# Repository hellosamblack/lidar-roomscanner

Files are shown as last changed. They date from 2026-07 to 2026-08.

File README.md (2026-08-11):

#  3D Roomscanner

A tethered handheld **3D room scanner**. This project aims to build a complete pipeline for 3D room capture: an STM32H563ZI board streams timestamped Time-of-Flight (ToF) and IMU/Environment sensor frames to a PC. The host PC runs real-time SLAM (using Open3D tensor ICP + TSDF), providing a live 3D reconstruction and tracking. Finally, an offline pass fuses 4K phone video into a ToF-seeded 3D Gaussian Splat.

---

##  System Architecture

The architecture consists of two main pillars:

### 1. Hardware & Firmware

<table>
  <thead>
    <tr>
      <th width="15%">Category</th>
      <th width="20%">Hardware</th>
      <th width="50%">Specifications & Role</th>
      <th width="15%">Image</th>
    </tr>
  </thead>
  <tbody>
    <tr>
      <td valign="top"><strong>MCU</strong></td>
      <td valign="top"><strong>STM32H563ZI</strong><br>(NUCLEO-H563ZI)</td>
      <td valign="top">
        <ul>
          <li><strong>Firmware:</strong> Bare-metal driving a double-buffered DMA setup via I3C.</li>
          <li><strong>Speed:</strong> Capable of emitting raw binary frames at 30+ fps.</li>
        </ul>
      </td>
      <td valign="top" align="center">NUCLEO-H563ZI</td>
    </tr>
    <tr>
      <td valign="top"><strong>Transport</strong></td>
      <td valign="top"><strong>RP-WD007</strong><br>(Travel Router)</td>
      <td valign="top">
        <ul>
          <li><strong>Connections:</strong> Streams via native USB CDC FS or Ethernet UDP (untethered DHCP client).</li>
          <li><strong>Power & Network:</strong> <em>Powered and networked via travel routers for wireless operation.</em></li>
        </ul>
      </td>
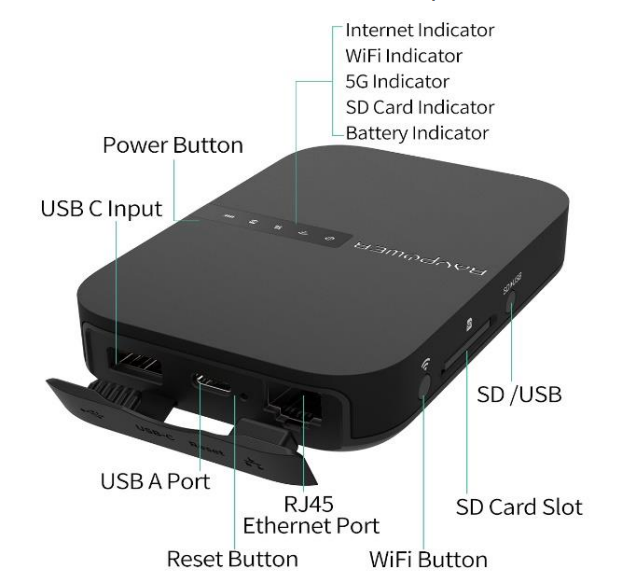
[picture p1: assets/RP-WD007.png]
RAVPower RP-WD007
      <td valign="top" align="center"></td>
    </tr>
    <tr>
      <td valign="top"><strong>LIDAR</strong></td>
      <td valign="top"><strong>VL53L9CX</strong><br>(X-NUCLEO-53L9A1)</td>
      <td valign="top">
        <ul>
          <li><strong>Specs:</strong> 54×42 depth zones (2,268 points per frame), max range ~4000mm</li>
          <li><strong>FoV:</strong> 54.65° Horizontal / 42.50° Vertical</li>
          <li><strong>Speed:</strong> Streams raw <code>3DMD</code> data at 30+ fps over I3C + DMA</li>
          <li><strong>Role:</strong> Primary depth imager for SLAM tracking and point-cloud generation.</li>
        </ul>
      </td>
      <td valign="top" align="center">X-NUCLEO-53L9A1</td>
    </tr>
    <tr>
      <td valign="top"><strong>IMU & Env</strong></td>
      <td valign="top"><strong>Sensor Cluster</strong><br>(X-NUCLEO-IKS4A1)</td>
      <td valign="top">
        <ul>
          <li><strong>LSM6DSV16X (6-axis IMU):</strong> 3D accel (16g) + 3D gyro (4000 dps). Outputs hardware quaternions via its embedded Sensor Fusion Low Power (SFLP) core.</li>
          <li><strong>LIS2MDL (Magnetometer):</strong> 3-axis magnetic sensor, 50 Gauss, up to 100 Hz. Used for absolute heading and yaw-drift correction.</li>
          <li><strong>LPS22DF (Barometer):</strong> 260-1260 hPa absolute pressure. Vertical Z-drift constraint via barometric altitude changes.</li>
          <li><strong>SHT40 (Humidity & Temp):</strong> 0-100% RH, -40 to 125 °C.</li>
          <li><em>(Unused) LSM6DSO16IS:</em> Secondary 6-axis IMU with an ISPU.</li>
          <li><em>(Unused) LIS2DUXS12:</em> Secondary 3-axis ultra-low power accelerometer with Qvar.</li>
          <li><em>(Unused) STTS22H:</em> Secondary temperature sensor (0.5 °C accuracy).</li>
        </ul>
      </td>
      <td valign="top" align="center">X-NUCLEO-IKS4A1</td>
    </tr>
    <tr>
      <td colspan="4" align="center">
        <strong>Fully Assembled Hardware Stackup</strong><br>
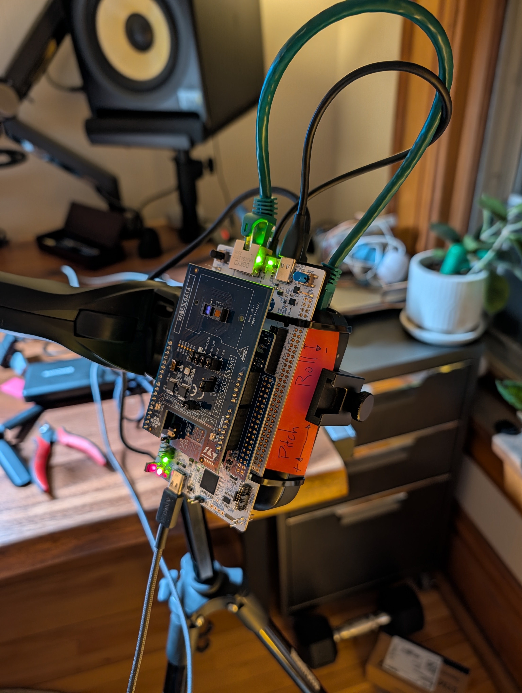
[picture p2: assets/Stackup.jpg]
Hardware Stackup
        
      </td>
    </tr>
  </tbody>
</table>

### 2. Host PC Software (`roomscan`)
*   **Decoding & Transport:** Python package `roomscan` decodes the binary frame protocol and runs the `vl53l9-transform-c` pipeline host-side for uncompromised throughput.
*   **Real-time SLAM:** Point-to-plane ICP frame-to-model tracking against a TSDF VoxelBlockGrid using Open3D's tensor API on the GPU.
*   **Visualization:** A FastAPI and Three.js-based web server (`roomscan-web`) serving a rich real-time visualizer for point clouds, SLAM meshes, sensor states, and IMU metrics.

### Runtime data path

The MCU owns sensor timing: it triggers the ToF sensor, DMA-reads alternating raw
buffers, stamps the frame-ready edge, and packages raw ToF, calibration, and
available IMU/environment streams into CRC-protected `RSCN` frames. It can send
the same frames over native USB CDC and Ethernet UDP.

On the PC, one transport-neutral reader decodes live USB/UDP data or an
identically formatted recording. It records raw bytes when requested, builds the
native ToF transform from `CALIB`, transforms `RAW_3DMD` into depth and image
arrays, then feeds the web visualizer and optional GPU SLAM worker. Browser
controls travel back over the same protocol as COMMAND/ACK frames. See the
[runtime architecture guide](docs/system-architecture.md) for the complete
firmware and host flow.

---

##  Repository Layout

The project is organized into several layers. Start here, and follow the links to learn more about each component:

*   [**`firmware/`**](firmware/README.md) - Active firmware fork (`scanner-stream`) and vendored ST dependencies (`53L9A1`).
*   [**`host/`**](host/README.md) - PC Python package (`roomscan`), real-time SLAM pipeline, Web UI server, and diagnostics.
*   [**`docs/`**](docs/README.md) - Engineering practices, protocol specs, wiring guides, and architectural decisions.
*   [**`tools/`**](tools/README.md) - Project-level utilities, helper scripts, and Docker containers (e.g., offline SLAM).

##  Key Project Documents

*   [**`ROADMAP.md`**](ROADMAP.md) - Current-state doc: standing decisions, architecture, and risks. Forward-looking work + defects are [GitHub Issues](https://github.com/hellosamblack/lidar-roomscanner/issues).
*   [**`docs/roadmap-history.md`**](docs/roadmap-history.md) - Completed-phase narratives and measured outcomes (the historical record behind the roadmap).
*   [**`BUGS.md`**](BUGS.md) - Pointer to GitHub Issues (`bug` label); old `BUG-NNN` → issue mapping in [`docs/issue-migration-map.md`](docs/issue-migration-map.md).
*   [**`AGENTS.md`**](AGENTS.md) - The primary system guidance and agentic instructions for working in this repo. Read this first if you are an agent contributing to the codebase. (`CLAUDE.md` is a symlink to it, as is `.agents/AGENTS.md`; project skills live in [`.agents/skills/`](.agents/skills), which `.claude/skills/` and `.codex/skills/` symlink to.)
*   [**`docs/engineering-practices.md`**](docs/engineering-practices.md) - Binding conventions: repo rules, protocol rules, firmware/host standards, and the status-sync + milestone-retro rules.
*   [**`docs/protocol.md`**](docs/protocol.md) - The binary wire protocol spec (frame layout, stream ids, golden vectors).
*   [**`docs/mcp-server.md`**](docs/mcp-server.md) - The `roomscan-mcp` agent-facing tool surface.

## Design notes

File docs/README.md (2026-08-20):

#  Documentation

Welcome to the documentation hub. This directory contains engineering conventions, protocol specifications, calibration and validation records, and historical context for the Roomscanner project.

Agent guidance lives one level up in [`AGENTS.md`](../AGENTS.md) (`CLAUDE.md` is a symlink to it); project skills are in [`.agents/skills/`](../.agents/skills). Forward-looking work and open defects are **GitHub Issues**, not files — `gh issue list --label bug|work-item|data-collection`, further tagged `area/*`, `status/*`, and `priority/now|next|later`.

##  Key Specifications & Guidelines

*   [**`system-architecture.md`**](system-architecture.md) - How a measurement moves through the STM32 acquisition loop, transport, host transform, web viewer, and SLAM pipeline.
*   [**`engineering-practices.md`**](engineering-practices.md) - The constitution for contributing. Defines repo rules, commit structures, C/Python coding standards, and firmware loop practices.
*   [**`protocol.md`**](protocol.md) - The binary wire protocol specification defining the transport layer between the MCU and Host PC.
*   [**`web-protocol.md`**](web-protocol.md) - The WebSocket JSON/Binary protocol for the `roomscan-web` frontend.
*   [**`thin-client.md`**](thin-client.md) - The `/ws-thin` server-rendered raster feed for GPU-less thin clients (CrowPanel), its protocol contract, renderer backend and client-cap/backpressure policy.
*   [**`mcp-server.md`**](mcp-server.md) - API and structural documentation for the `roomscan-mcp` agentic tool server.
*   [**`coordinate-frames.md`**](coordinate-frames.md) - **Binding**: the sensor/body/world frame definitions and the rotation conventions every orientation claim is expressed in.

##  Hardware & Setup Guides

*   [**`headless-host-setup.md`**](headless-host-setup.md) - Guide for bringing up a GPU-less Linux host to run the web server.
*   [**`pi-bridge-runbook.md`**](pi-bridge-runbook.md) - The Raspberry Pi 3 bridge node that replaces the FileHub as the rig's wireless uplink: build the SD image, flash, first boot, day-2 administration over MCP, recovering lost frames from the pcap tee, and the failure playbook.
*   [**`iks4a1-stacking.md`**](iks4a1-stacking.md) - The hardware stacking recipe, jumper configurations, and bus-conflict resolution history for the sensor array.
*   [**`web-ui-testing.md`**](web-ui-testing.md) - How to drive and test the headless web UI.
*   [**`h563-optimization-notes.md`**](h563-optimization-notes.md) - Why the transform pipeline runs on the PC: measured M33 throughput limits and the deferred on-device optimizations.
*   [**`vl53l9cx-datasheet-notes.md`**](vl53l9cx-datasheet-notes.md) - Working notes on the ToF sensor's datasheet (raw frame sizes, binning, DSS).
*   [**`vl53l9cx-fov-notes.md`**](vl53l9cx-fov-notes.md) - Field-of-view geometry and the deprojection consequences.

##  Calibration, Sensors & Validation

*   [**`flatfield-calibration.md`**](flatfield-calibration.md) - Mode-aware reflectance flat-field correction: the FPN measurement, map generation, and cross-room validation.
*   [**`yaw-fusion.md`**](yaw-fusion.md) - Host-side magnetometer/IMU heading fusion, and the heading-frame traps it has hit.
*   [**`transform-streams.md`**](transform-streams.md) - The `vl53l9-transform-c` pipeline's streams and algorithm toggles, including the 1.3.1 → 1.5.0 upgrade gate.
*   [**`deprojector-validation.md`**](deprojector-validation.md) - How depth-to-point-cloud deprojection was validated.
*   [**`phase6-slam-validation.md`**](phase6-slam-validation.md) - The offline SLAM validation record (accuracy gates and measured outcomes).
*   [**`imu-mag-appnote-review-2026-07-29.md`**](imu-mag-appnote-review-2026-07-29.md) - Review of ST's IMU/magnetometer application notes against our implementation.
*   [**`an6522-appnote-review-2026-08-17.md`**](an6522-appnote-review-2026-08-17.md) - Second-pass review of ST's ranging-profile tuning app note (AN6522) against the current presets: what's already applied, and two unresolved gaps (ULP-for-I3C power recommendation, indoor exposure ceiling).
*   [**`odr-triggered-sync-costing-2026-07-30.md`**](odr-triggered-sync-costing-2026-07-30.md) - Costing study for ODR-triggered ToF/IMU synchronization (note the amended §2.3 premise).
*   [**`connect-transient-forensics.md`**](connect-transient-forensics.md) - Forensics on the USB CDC connect-time CRC transient.

##  RTAB-Map Study (Phase 6/7 reference design)

*   [**`rtabmap-study.md`**](rtabmap-study.md) - What RTAB-Map does differently (per-node clouds + pose graph vs our monolithic TSDF); indexes the issues it generated.
*   [**`rtabmap-pixel10-capture.md`**](rtabmap-pixel10-capture.md) - Exact RTAB-Map capture settings for Phase 7 on the Pixel 10 Pro XL.

##  History & Archives

*   [**`roadmap-history.md`**](roadmap-history.md) - Completed-phase narratives and measured outcomes; the historical record behind [`ROADMAP.md`](../ROADMAP.md).
*   [**`codex-token-burndown.md`**](codex-token-burndown.md) - Ready-to-paste prompt (plus model/effort choice) for a Codex token-burndown session against the issue backlog; single-session counterpart to the `issue-fleet` skill.
*   [**`issue-migration-map.md`**](issue-migration-map.md) - Legacy `BUG-NNN` / `SLAM-N` / `DC-<letter>` → GitHub issue mapping (2026-08-10 migration). Generated from `issue-migration-map.json`, which is the machine-readable source of truth.
*   **`superpowers/`** - Design documents (`specs/`) and phase execution checklists (`plans/`). Active work sits at each directory root; historical records under `completed/`, superseded ones under `deprecated/`. The register in [`ROADMAP.md`](../ROADMAP.md) is the inventory.

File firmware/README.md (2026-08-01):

#  Firmware Layer

This directory contains the embedded firmware components for the Roomscanner project.

##  Target Hardware

*   **Core:** NUCLEO-H563ZI (STM32H563ZI Cortex-M33)
*   **ToF Expansion:** X-NUCLEO-53L9A1 (VL53L9CX ToF 3D LiDAR)
*   **IMU/Env Expansion:** X-NUCLEO-IKS4A1 (LSM6DSV16X, LIS2MDL, LPS22DF, SHT40)

##  Directory Structure

*   [**`scanner-stream/`**](scanner-stream/)
    *   Our active firmware fork. Handles reading ToF data over I3C + DMA, reading IMU streams, packaging into binary frames, and streaming over USB CDC or Ethernet UDP.
*   [**`vendor/`**](vendor/) - Vendored dependencies:
    *   `tinyusb/` - USB CDC stack (FS).
    *   `lwip/` - TCP/IP stack for Ethernet UDP streaming.
    *   `53L9A1/` - ST's reference package. We treat this as a **read-only reference** rather than editing it in place.

##  Architecture Highlights
The active firmware owns the sensor-time-critical work: it starts manual ToF
exposures, stamps the frame-ready edge, and DMA-reads into alternating raw
buffers. While one buffer is being filled, it can package the completed buffer,
drain the optional IMU FIFO, and start the next exposure. Commands and recovery
run only at a safe point after readout acknowledgement, so they cannot race an
in-flight trigger.

The normal build streams raw `3DMD` ToF data plus periodic calibration to the
PC, where the transform runs. It also emits available quaternion,
environmental, raw-IMU, and clock-synchronization streams. A shared versioned
binary protocol carries DATA, COMMAND, ACK, and EVENT frames over USB CDC and
Ethernet UDP; the host may receive either transport or replay the exact bytes
from a capture file.

For the end-to-end sequence, see [**`docs/system-architecture.md`**](../docs/system-architecture.md).
For wire details, see [**`docs/protocol.md`**](../docs/protocol.md). Build and
firmware-loop guidance remains in [**`CLAUDE.md`**](../CLAUDE.md).

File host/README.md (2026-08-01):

#  Host PC Software (`roomscan`)

This directory contains the Python package `roomscan`, which serves as the brain on the host PC. Because the M33 MCU is bottlenecked by the transform pipeline, the host takes over heavy processing, acting as the primary visualization and SLAM engine.

##  Core Responsibilities

1.  **Transport & Decoding:** Connects to the scanner via USB CDC or Ethernet UDP. Decodes the binary frame protocol, resyncs on corruption, and handles sequences.
2.  **ToF Transform:** Runs the `vl53l9-transform-c` pipeline natively on the PC (compiled as a C-extension) to convert raw I3C data into depth, reflectance, and confidence maps.
3.  **Real-time SLAM (`roomscan.slam`):** Point-to-plane ICP frame-to-model tracking against a TSDF VoxelBlockGrid using Open3D's tensor API on the GPU. Capable of generating meshes at ~7ms/frame.
4.  **Web Visualizer (`roomscan-web`):** A FastAPI server providing a WebSocket (`/ws`) stream to a Three.js-based frontend. It replaces the old desktop panel, offering real-time point clouds, SLAM trajectories, sensor gizmos, and headless remote rendering.

##  Frame Flow

USB CDC, UDP, and capture replay all provide raw byte chunks to the same
incremental decoder. The shared reader loop routes control responses and
telemetry, tees raw bytes to recordings, and sends ToF frames through
`TransformStage`. That stage builds the native transform from a `CALIB` frame,
turns `RAW_3DMD` into depth/image arrays, and places only the newest completed
frame in a render slot. The web broadcaster and SLAM worker consume that slot
without competing for the device stream.

This means a capture is a protocol-level recording rather than a special export:
replay follows the same decoder, transform, deprojection, visualizer, and SLAM
path as live hardware. The complete cross-boundary explanation is in
[**`docs/system-architecture.md`**](../docs/system-architecture.md).

##  Structure

*   **`src/roomscan/`** - Core library source code.
*   **`tests/`** - Pytest suite for the host package (run from the `host/` directory).
*   **`tools/`** - Assorted Python utilities, recording playback scripts, diagnostics, and the MCP Server entrypoint (`roomscan-mcp`).

For details on the web UI WebSocket communication, see [**`docs/web-protocol.md`**](../docs/web-protocol.md).

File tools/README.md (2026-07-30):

#  Tools & Utilities

This directory contains project-level utilities, shell scripts, and external containers that exist outside of the main `host/` Python package.

##  Contents

*   [**`slam-container/`**](slam-container/) - Docker container setup and scripts for offline SLAM validation, letting you run the Open3D pipeline in an isolated Linux environment with CUDA support.

> **Note:** Python-specific debugging scripts, recording visualization tools, and agent MCP servers live in the host package at [`host/tools/`](../host/tools/).

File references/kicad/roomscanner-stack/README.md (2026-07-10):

# roomscanner-stack — consolidated KiCad project

A single KiCad project that models the **three stacked NUCLEO boards** as one
schematic so you can trace any STM32 pin through the stack to the sensor it
drives:

```
NUCLEO-H563ZI (base)  →  X-NUCLEO-IKS4A1 (middle)  →  X-NUCLEO-53L9A1 (top)
   STM32H563               IMU + environmental          VL53L9CX ToF LiDAR
```

## Files

| File | What it is |
|---|---|
| `roomscanner-stack.kicad_pro` | Project file — **open this** in KiCad 7/8/9/10 |
| `roomscanner-stack.kicad_sch` | The consolidated schematic |
| `roomscanner.kicad_sym` | Symbol library (also embedded in the schematic → self-contained) |
| `sym-lib-table` / `fp-lib-table` | Library tables |
| `datasheets/` | Component & board datasheets + application notes (linked from each symbol) |
| `stack-pinmap.md` | The authoritative pin map (source of truth for the wiring) |
| `jumper-config.md` | Default jumper/switch positions for all three boards + net effects |
| `roomscanner-stack.net` | Exported netlist (KiCad, generated by `kicad-cli`) |
| `roomscanner-stack.pdf` | Rendered schematic |
| `roomscanner-stack-erc.rpt` | ERC report — **0 errors, 0 warnings** (KiCad 10.0.3) |
| `generate_stack.py` | The generator that produced everything (re-run to regenerate) |

## Validation (real KiCad, not just structural)

Built with `kiutils`, then verified with **KiCad 10.0.3 `kicad-cli`**:

- **ERC: 0 errors, 0 warnings** (`roomscanner-stack-erc.rpt`).
- **Netlist exported** (`roomscanner-stack.net`) — 29 components, 38 nets — and
  cross-checked. The `PB8` (I3C1_SCL) net resolves, in KiCad's own netlister, to:
  ```
  H563   CN5.10
  IKS4A1 CN105.10, U103.1   (NXS0108 host SCL)
  VL53   CN205.10, U205.3   (PI4ULS3V204 host SCL)
  ```
  i.e. one net spanning all three boards — the shared ToF/IMU bus. `PB9` is the
  same for SDA; `IKS_SCL/IKS_SDA` carry all seven IKS4A1 sensors; the power rails
  merge across boards.
- **PDF rendered** (`roomscanner-stack.pdf`).

## Scope — "stack-interconnect model"

Not a full component-level redraw. It captures the shared connectors and the
functional ICs on the stack signal path:

- **Included:** all four ST Zio / Arduino headers (`CN5/6/8/9`) on every board;
  the VL53L9CX + its two PI4ULS3V204 level shifters + 12 MHz oscillator; the
  IKS4A1's NXS0108 I²C shifter, LDK130 LDO, the LSM6DSV16X (HUB1) IMU, **and all
  six secondary sensors** — LIS2MDL (mag), LPS22DF (baro), LIS2DUXS12 (accel),
  STTS22H (temp), LSM6DSO16IS (HUB2 IMU/ISPU), SHT40 (RH/T) — on the internal
  1.8 V I²C bus.
- **Omitted** (never cross the stack): ST-LINK-V3EC, USB, Ethernet PHY, most
  on-board regulators, and the passives/decoupling. The VL53 on-board LDO rails
  (AVDD/DVDD) are abstracted (no-connect with a note).
- **Morpho headers `CN7/CN10`** are drawn as present (2×19 pass-through) but
  their pins are no-connect — the sensors don't use them.

## Jumper / switch configuration

The as-built default jumper positions for all three boards are recorded on each
board section of the schematic (text notes) and tabulated in `jumper-config.md`.
Base-board jumpers (JP2/JP4/JP5/JP6 — power/debug/USB) don't touch the Zio pins,
so they're documentation-only. The one jumper that changes a modeled net is the
53L9A1 **`SW1` = INT**: it's drawn as an actual SPDT component, so the netlist
correctly shows the ToF clock coming from the on-board **Y1 12 MHz** oscillator
while the host `PB5`/`CLK_IN` path dead-ends at the switch (unused in this
default). See `jumper-config.md` for the full table and net effects.

## How connectivity works

One flat A1 sheet, three titled sections (base / middle / top). Nets that are
electrically common across the stack carry a **global label named after the
STM32 pin** (e.g. `PB8`); same-named labels merge, so the netlist proves the
shared bus. Board-internal nets use local labels (`VL53_S_SCL`, `IKS_SCL`, …).

**Reference numbering:** all three boards silk-print the same connector names,
but KiCad needs unique references. The base keeps the real names; the middle
board is offset **+100** (`CN105` = real `CN5`, `U103` = real `U3`) and the top
board **+200** (`CN205` = `CN5`, `U205` = `U5`). A `= CNx` / `= Ux` text sits by
each so the real silk name is visible.

## Datasheets

`datasheets/` holds the PDFs we have locally (copied in so the project is
self-contained and git-trackable — see `datasheets/MANIFEST.md` for provenance).
Each symbol's **Datasheet** field points at the local PDF where we have it
(VL53L9CX, LSM6DSV16X, the three board docs, STM32H563) or at the vendor/ST URL
otherwise (the six secondary sensors, PI4ULS3V204, NXS0108, LDK130). In KiCad,
right-click a symbol → **Show Datasheet**.

## Regenerating

```sh
pip install kiutils
python generate_stack.py     # rewrites .kicad_sch/.kicad_sym/.kicad_pro + re-copies datasheets
```

Edit the canonical connector/IC/sensor data near the top of `generate_stack.py`
and re-run. Every pin assignment's sourcing is documented in `stack-pinmap.md`.

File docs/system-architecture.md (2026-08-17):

# Runtime Architecture

This is the implementation-level map of the scanner. It explains where a
measurement goes after the sensor produces it, which component owns each
boundary, and why raw data is transformed on the PC. For byte layouts and
stream IDs, use [the protocol specification](protocol.md); for coordinate
conventions, use [coordinate frames](coordinate-frames.md).

```mermaid
flowchart LR
    tof["VL53L9CX ToF"] -->|"I3C + DMA"| fw["STM32 firmware"]
    imu["LSM6DSV16X + sensor hub"] -->|"I3C / FIFO"| fw
    fw -->|"RSCN binary frames"| link{"USB CDC or Ethernet UDP"}
    link --> ingest["Host sources + decoder"]
    ingest --> transform["Native ToF transform"]
    transform --> view["Web visualizer"]
    transform --> slam["ICP + TSDF SLAM"]
    ingest --> record["Raw capture recording"]
    record --> ingest
    hostcmd["Web controls"] -->|"COMMAND / ACK"| fw
```

## Design at a glance

The STM32 controls timing and acquisition. It does not perform the normal
depth transform in the production configuration: it sends the VL53L9CX's raw
`3DMD` payload plus the calibration blob needed to interpret it. The host runs
ST's transform library natively, then fans the resulting depth, reflectance,
confidence, and ambient arrays out to the visualizer and SLAM pipeline. This
keeps the time-sensitive I3C/DMA loop short while putting the expensive,
inspectable work on the machine with GPU and memory headroom.

The two sides communicate through one versioned, CRC-protected binary protocol.
The same format is used over USB CDC, Ethernet UDP, and capture files, so a
recording exercises the same decoder, transform, viewer, and mapping code as a
live device.

## Firmware: acquire, timestamp, package, recover

The active application is
[`firmware/scanner-stream/`](../firmware/scanner-stream/); the similarly named
app below `firmware/vendor/53L9A1/` is ST reference code and is not modified.

### Bring-up

`Src/main.c` initializes the STM32 HAL, clocks, I3C1, GPDMA, USB hardware, and
Ethernet/lwIP before entering `vl53l9_app()`. The app initializes TinyUSB and
starts its free-running TIM2 microsecond clock before streaming, then:

1. Resets the ToF sensor, assigns I3C dynamic addresses, initializes the
   VL53L9CX, reads its calibration, applies the ranging profile, and starts
   manual ranging. Boot and later sensor failures use bounded re-init retries.
2. Initializes the optional LSM6DSV16X on the shared I3C bus. Its SFLP
   quaternion and sensor-hub environmental samples complement, but never block,
   the ToF stream.
3. Brings the native USB CDC device online only once it can service it. Ethernet
   is initialized independently; a host's first UDP datagram claims the unicast
   destination for Ethernet frames.

The green/red/yellow board LEDs provide coarse boot, fault, and acquisition-loop
liveness without requiring a debugger. Diagnostic text is emitted on the
separate ST-Link VCOM; it is not the scanner data channel.

### Per-frame loop

The ranging loop is deliberately pipelined:

1. Trigger a ToF exposure, wait for its frame-ready interrupt, and capture the
   frame-ready instant on the MCU clock.
2. Latch the IMU clock near that edge, then start an I3C DMA read into one of
   two raw buffers.
3. Acknowledge and parse the completed transfer. Commands, standby transitions,
   and reconfiguration run only at this safe point, never while a trigger is in
   flight.
4. Trigger the next exposure early, then package the completed raw buffer and
   associated IMU/environment data. The alternating buffer lets sensor DMA for
   one frame overlap CPU work and transport for the previous one.

Each ToF sequence normally produces `RAW_3DMD` (stream 7). `CALIB` (stream 8)
is resent periodically and after a re-init, so a newly attached host or replay
can construct a transform. The firmware also emits the SFLP quaternion (9),
environmental sample (10), raw IMU FIFO batch (11), IMU clock calibration (12),
and ToF-to-IMU synchronization measurement (13) when available. An on-device
transform mode remains for comparison/golden-data work, but raw streaming is
the normal path.

Frames are serialized as a header, payload, and CRC once, then offered to USB
CDC and/or Ethernet. Transmission is not allowed to halt acquisition: a busy or
unavailable link drops data and reports that fact through frame flags, sequence
numbers, counters, and EVENT frames. Ethernet uses paced, fragmented UDP;
the host reassembles it before protocol decoding.

### Control and failure policy

The host sends `COMMAND` frames for ping, calibration resend, ranging settings,
re-initialization, and soft or hard ToF standby. The firmware returns an `ACK`
that echoes the host token and reports the value actually applied. Sensor errors
become `EVENT` frames followed by bounded recovery attempts; a successful
recovery sends calibration again before raw streaming resumes. Exact command,
event, and compatibility rules live in [the protocol specification](protocol.md).

## Host: receive once, transform once, consume many times

The Python package is [`host/src/roomscan/`](../host/src/roomscan/). It keeps
I/O, wire decoding, transform, and consumers separate so the core data path is
testable without connected hardware.

### Ingestion and recording

`sources.py` supplies three interchangeable byte sources:

- `SerialSource` reads the native USB CDC device.
- `UdpSource` discovers the scanner through mDNS, periodically sends a small
  keepalive to retain the device's unicast target, and reassembles UDP fragments.
- `FileSource` replays a raw capture at a frame boundary.

On the wireless rig the Ethernet hop runs through the **Pi 3 bridge node** rather
than a commercial Wi-Fi bridge: the scanner plugs into the Pi's `eth0`
(172.31.100.1/24, dnsmasq handing its compile-time MAC a static 172.31.100.20
lease inside the firmware's 3000 ms DHCP window), and the Pi routes and NATs UDP
5000 out over `wlan0`. It publishes the `roomscanner._roomscan._udp` service on
`wlan0` only, so `UdpSource` resolves the Pi with no host-side change at all --
the transport looks identical from here. The bridge is additive: with it absent,
a plain Ethernet cable from the scanner to a laptop still works unchanged. It
also tees every scanner packet to a bounded local pcap ring, which is what makes
frames lost over the air recoverable after the fact
(`bridge_tee_fetch`/`pcap2capture.py`). Build, operation and failure playbook:
[`pi-bridge-runbook.md`](pi-bridge-runbook.md); design rationale:
[`superpowers/specs/2026-08-17-pi3-bridge-node-design.md`](superpowers/specs/2026-08-17-pi3-bridge-node-design.md).

`StreamDecoder` accepts arbitrary chunks from any source. It scans for the
`RSCN` magic, bounds payload lengths, verifies CRC32, and resynchronizes after
partial reads or corruption instead of trusting the link. `Recorder` tees the
original bytes to disk, making captures a faithful protocol-level record rather
than a rendered export.

The shared reader loop is the sole owner of a source and decoder. It routes
EVENT frames to the log bus, ACKs to `CommandClient`, all DATA frames to metrics
and sensor state, and transformed ToF frames to a latest-wins render slot. This
separation keeps a slow renderer, browser tab, or command write from starving
acquisition reads.

### Transform, geometry, and sensor state

`TransformStage` waits for a `CALIB` frame, constructs the native
`vl53l9-transform-c` wrapper, and uses it to turn following `RAW_3DMD` frames
into arrays. A changed calibration replaces the transform and resets its
transform-local state. Legacy `DEPTH_ZF32` captures remain supported as a direct
pass-through. `Deprojector` converts the depth grid into sensor-frame points;
optional flat-field calibration corrects reflectance before visual use.

`SensorState` receives the quaternion, environmental, raw-IMU, and clock-trim
streams independently of ToF transformation. It maintains recent orientation,
pressure, temperature, magnetic samples, and a short raw-IMU history. The
host's yaw fusion applies calibrated magnetometer data to reduce yaw drift;
[yaw fusion](yaw-fusion.md) records the model and limits. The high-rate
`ImuFusion` path is optional and remains disabled for SLAM by default. The
separate synchronization stream is decoded by protocol and capture-analysis
tools; it exposes the measured ToF-to-IMU timing rather than silently applying
a pose correction.

### Viewer and mapping consumers

`roomscan-web` is the primary UI. Its FastAPI server has one reader thread and
one broadcast task, so every WebSocket client receives the same most-recent
frame rather than competing for device bytes. The broadcaster produces compact
binary point-cloud, IR-image, and mesh messages plus JSON state, sensor,
metrics, command, capture, and log messages. The browser renders them with
Three.js; [the web protocol](web-protocol.md) is the browser-facing contract.

When mapping is selected, a `SlamWorker` receives depth and available orientation
and pressure priors without blocking the web event loop. It deprojects the depth
frame, estimates motion with point-to-plane ICP against the current model, and
integrates tracked frames into an Open3D tensor TSDF `VoxelBlockGrid` on the
selected device (CUDA when available). A separate mesh-preparation worker makes
render-ready mesh packets so extraction and serialization do not stall live
frame delivery. Mapping status, validation limits, and the offline detailed
workflow are described in [Phase 6 SLAM validation](phase6-slam-validation.md).

## Ownership boundaries

| Concern | Owner | Primary implementation |
|---|---|---|
| Sensor timing, I3C/DMA, frame timestamp, safe reconfiguration | Firmware | `firmware/scanner-stream/Src/vl53l9_app.c` |
| IMU FIFO and sensor-hub acquisition | Firmware | `firmware/scanner-stream/Src/rs_lsm.c` |
| Framing, checksum, stream IDs, commands | Shared contract | [protocol.md](protocol.md) |
| USB/UDP/file bytes, decoding, recording | Host | `host/src/roomscan/sources.py`, `decoder.py` |
| Raw-to-depth transform and deprojection | Host | `pipeline.py`, `native.py`, `deproject.py` |
| Browser fan-out and session control | Host | `web.py` |
| ICP, TSDF, mesh production | Host | `host/src/roomscan/slam/` |

## Related documentation

- [Protocol specification](protocol.md) — authoritative wire layout and stream semantics.
- [Transform streams](transform-streams.md) — transform outputs and their interpretation.
- [Coordinate frames](coordinate-frames.md) — sensor, world, Open3D/CV, and display conventions.
- [IKS4A1 stacking](iks4a1-stacking.md) — shared-bus wiring and sensor configuration.
- [Headless host setup](headless-host-setup.md) — deployment and first bring-up.

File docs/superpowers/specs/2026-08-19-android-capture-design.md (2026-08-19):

# Android capture app — posed high-res video from the Pixel 10 Pro XL

**Status:** Specced (priority/later)
**Date:** 2026-08-19
**Issues:** #135 (Android capture app — high-res video + ARCore pose/depth)
**Companion spec:** offline 3DGS program (`2026-08-19-offline-3dgs-program-design.md` —
this app is that program's posed-capture source, plan B)

## Goal

One take from the phone yields **video + per-frame pose + intrinsics + ARCore
depth/confidence**, so the 3DGS pass never depends on COLMAP SfM surviving featureless
walls (measured: 206/287 frames, 72%, Sam Office). The issue body (2026-08-07) is
already design-grade; this spec fixes the decision points, adds what has been learned
since, and attaches the gates.

## Corrections and constraints learned since the issue was filed

- **The Pixel 10 Pro XL has a ToF sensor** (`docs/rtabmap-pixel10-capture.md:83`) — the
  issue's "historically no ToF, unverified" is superseded, but the check stands: read
  `CameraConfig.getDepthSensorUsage()` on the handset and record the answer. Either way
  ARCore depth remains a **regularizer, not metric truth**; the rig's VL53L9CX stays the
  metric source.
- **RTAB-Map's own app cannot be the high-res path:** it hard-selects the lowest CPU
  camera config (driver 1) and its shared-camera driver carries an in-code `//FIXME` on
  exactly the unconfigured-surface problem this app must solve (`docs/rtabmap-study.md`
  §5). So #135 is not duplicating RTAB-Map — it exists *because* RTAB-Map caps
  resolution.
- **Plan A before plan B** (owner decision, 2026-08-11): first measure whether RTAB-Map's
  own exported low-res posed frames already beat COLMAP-on-4K (`#159`'s gate). This app
  is plan B — it is justified by the resolution ceiling plan A measures. Build order
  follows: the enumeration spike can start anytime, but full app investment waits for
  plan A's number.

## Decisions

1. **First deliverable is a measurement, not an app:** a minimal probe APK (or
   instrumented sample) that enumerates `CameraConfigFilter` on the actual handset and
   reports every achievable (video resolution, fps, depth on/off) combination through
   `SharedCamera`. If 4K and live depth are mutually exclusive, that is a recorded
   finding that reshapes the app — not something to design around blindly. This needs
   the owner's phone: `needs/operator`, `needs/hardware`.
2. **Output format: plain video + sidecar (option 2), decided now.** Poses from
   `Camera.getDisplayOrientedPose()`, intrinsics from `getImageIntrinsics()`, depth +
   confidence PNGs. It is directly the shape `roomscan.splat` and `transforms.json`
   want, and it keeps the host ingest trivial (the ARCore-MP4 custom-track route needs a
   host demuxer nobody else will ever use). The Recording & Playback API remains a
   fallback if `SharedCamera` recording proves unstable — reversible because the data
   content is identical.
3. **ToF fusion stays out of scope** — clock alignment (ARCore `CLOCK_MONOTONIC` ns vs.
   TIM2 µs) and the rigid mount/hand-eye extrinsic remain under DC-I (#146). This app
   must be useful with zero rig coupling.
4. **8th Wall stays parked** as the issue states: spiked only if the enumeration shows
   `SharedCamera` cannot reach ≥1080p60 with poses, and even then it must demonstrate an
   equivalent of the pose+video recording path before earning effort.
5. **Ingest lands as an MCP tool** per the standing rule (pure function + thin wrapper;
   CLI front end only if a human runs it) — extending the shipped #158 RTAB-Map ingest
   rather than a parallel path.

## Benchmark plan

- **Gate (a), unchanged from the issue and now with a harness:** on one real room, the
  ARCore-posed set must register/use **materially more frames than COLMAP-only on the
  same footage** — run through `splat_sfm_probe` so the comparison is per-config numbers
  (registration ratio, sub-model fragmentation), with the 206/287 (72%) COLMAP baseline
  as the stake in the ground. "Materially" is pre-registered as ≥90% frames used, or
  ≥+15 points over the COLMAP arm on the same video.
- **Gate (b):** the camera-config enumeration table, written into the issue and this
  spec's records.
- **Gate (c):** the MCP ingest path exists and a build runs end-to-end from a phone take
  with no manual file surgery.
- **Pose-quality check (cheap, catches silent garbage):** ArUco marker or bookend-style
  start/end-pose check on one take, so "poses recorded" ≠ "poses correct" (the
  invariant-check lesson: pick a check that can actually see wrong answers).

## Kill criteria

- **Killed by plan A succeeding:** if RTAB-Map's exported posed set already beats
  COLMAP-on-4K *and* its resolution ceiling does not show up in the manifest stats /
  `splat_compare` on a real room, the app adds resolution nobody measured a need for —
  #135 closes citing #159's numbers, and the shipped RTAB-Map export path is the
  permanent capture route.
- **Killed by the enumeration:** if `SharedCamera` tops out below 1080p30-with-poses on
  this handset *and* the 8th Wall spike cannot demonstrate pose+video recording, the
  phone-capture route degrades to RTAB-Map exports only — same closure as above, with
  the enumeration table as the evidence.
- **Descoped, not killed,** if gate (a) passes but ARCore depth proves useless on the
  featureless walls (its documented weakness): the app then ships poses+video only, and
  depth regularization stays with Depth-Anything-V2 (already implemented).

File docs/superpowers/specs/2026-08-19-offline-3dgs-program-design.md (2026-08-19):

# Offline 3DGS program — posed captures, depth regularization, CAD extraction

**Status:** Specced (priority/later)
**Date:** 2026-08-19
**Issues:** #132 (COLMAP pose priors + depth-regularized 3DGS), #133 (SuGaR), #134
(Nerfstudio/Splatfacto)
**Companion specs:** Android capture app (`2026-08-19-android-capture-design.md` — the
posed-capture source), splat quality improvements
(`2026-08-07-splat-quality-improvements-design.md` — items B–E; this spec supersedes
nothing there, it sequences the framework decisions around it)

## Reframe (binding, from the 2026-08-08 correction)

The Scaniverse comparison scan was taken with the **same Pixel 10 Pro XL** — no
LiDAR/ToF hardware advantage. Its 2.46 M-gaussian, 3 mm-median result comes from capture
UX + ARCore poses + ML depth + a tuned trainer. Our measured gap (median gaussian 49 mm
vs 3 mm, median opacity 0.03 vs 0.78, 74% of gaussians under 0.1 opacity) is
**under-constraint**, not missing hardware. Priority order, already measured and stated
in the splat-quality spec: **depth supervision ≫ better capture ≫ pipeline tuning.**
Every framework decision below serves that order.

## The three issues are one program with a shared substrate

All three want the same input: a **posed image set** (`transforms.json`-shaped: per-frame
pose + intrinsics (+ optional depth/confidence)) that does not depend on COLMAP SfM
succeeding on featureless painted walls (measured ceiling: 206/287 frames = 72%
registered on Sam Office; 161/287 at earlier settings — same video, different pipeline
config; say which when quoting). The posed set comes from RTAB-Map exports (#158 ingest —
shipped) or the ARCore capture app (#135). Owner decision 2026-08-11: Phase 7 captures
are taken with RTAB-Map; plan A (RTAB-Map-only frames) is measured **before** plan B
(RTAB-Map + separate 4K video) — do not skip A and lose the comparison.

## Decisions

1. **#132 splits in two.** The *pose-prior* half is unblocked and reframed: poses come
   from RTAB-Map/ARCore, and COLMAP's remaining role is refinement/undistortion — run
   `splat_sfm_probe` arms with posed-seeded COLMAP vs. poses-only vs. COLMAP-only, and
   let the registration ratio decide whether COLMAP stays in the pipeline at all. The
   *ToF-fusion* half (metric seed cloud, hand-eye `T_world_camera = T_world_lidar ×
   T_lidar_camera`, clock alignment) remains **blocked on DC-I (#146)** — rigid mount +
   extrinsic, undesigned. Nothing here changes that; the spec just stops the blocked
   half from blocking the unblocked half.
2. **Depth regularization lands in the existing `roomscan.splat` trainer first, not in a
   new framework.** The `depth_lambda` / Depth-Anything-V2 path is already implemented
   (default-off) with the right mechanism (per-frame scale+shift alignment of inverse
   depth, annealed). The A/B on Sam Office is the next action — it predates any
   framework migration and its result calibrates whether frameworks are needed at all.
3. **#134 (Splatfacto) is a benchmark arm, never an adoption.** Its role: an external
   reference implementation of depth-regularized 3DGS (via dn-splatter-lineage flags) to
   sanity-check our trainer's ceiling on the same posed set. It was already rejected for
   CAD output (volumetric focus; mesh via rendered-depth TSDF fusion degrades geometry).
   One benchmark round, numbers recorded, issue closes.
4. **#133 (SuGaR) is the CAD-mesh arm, entered only when a watertight mesh is actually
   wanted** and only after the posed-set + depth-regularized substrate exists — SuGaR on
   under-constrained photometry-only gaussians would measure the substrate's absence,
   not SuGaR. Known risks go in the protocol up front: Poisson floaters (mitigate with
   `--project_mesh_on_surface_points`), VRAM spikes at high octree depth (the source
   report sized these against 16 GB; our card is 8 GiB — chunked projection is
   mandatory, and a remote build via the distributed-GPU spec is the fallback), and no
   `transforms.json` extrinsics field (hand-eye applied before writing the JSON).

## Benchmark plan

- **Harness:** `splat_sfm_probe` (registration ratio + sub-model fragmentation per
  config — the tool that turns "COLMAP fails on featureless walls" into a per-config
  number), `splat_vram_sweep` (is VRAM or capture the binding ceiling), `splat_compare`
  (metric diff vs. the Scaniverse ground-truth splat and vs. the Detailed-SLAM mesh),
  and the manifest stats from the splat-quality spec (median opacity, fraction < 0.1,
  scale percentiles, solid+small+near fraction) on **every** build — they are what
  separates "room in a snowglobe" from "clean room" without eyeballing.
- **The pivotal A/B (gate for everything downstream):** same footage, (i) COLMAP-only,
  (ii) ARCore/RTAB-Map-posed, (iii) posed + `depth_lambda` on. Frames registered/used,
  manifest stats, `splat_compare` geometry error.
- **SuGaR gate:** its extracted mesh must beat the Detailed-SLAM TSDF mesh on
  `splat_compare` geometric error against the ground-truth splat on the same room —
  otherwise the rig already makes a better mesh and SuGaR's product is redundant.
- **Needs operator:** every arm needs captures only the owner can record
  (`needs/capture`); the capture protocol rides the existing splat-quality §B guidance
  plus the capture-app spec.

## Kill criteria

- **COLMAP-in-the-loop (#132 pose-prior half):** killed if posed-only (ii) registers ≥
  the COLMAP arms within noise on two different rooms — COLMAP then retires from the
  pipeline and #132 narrows to the DC-I-blocked ToF-fusion half only.
- **ToF-fusion half (#132):** stays blocked on DC-I; killed outright if (iii) already
  reaches Scaniverse-class manifest stats (3 mm-class median scale, >0.5 median opacity)
  without metric seeding — ML depth + poses would have closed the gap the fusion was
  meant to close, and the mount/extrinsic work is unjustified.
- **#134:** closes after one benchmark round by design; killed early if the posed-set
  substrate never materializes (it has nothing to benchmark).
- **#133:** killed if the SuGaR gate fails (TSDF mesh wins), if 8 GiB + chunking cannot
  complete Poisson on a room-sized scene and the remote-GPU fallback isn't available, or
  if no consumer for a watertight CAD mesh emerges by the time the substrate exists
  (product-pull test — do not build the exporter before something needs the export).

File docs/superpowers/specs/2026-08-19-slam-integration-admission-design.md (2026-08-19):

# Integration admission control — displacement gate, confidence policy, time budget

**Status:** Specced (priority/later)
**Date:** 2026-08-19
**Issues:** #149 (keyframe-gate map updates by minimum displacement), #152 (working-memory
time budget), #153 (confidence and depth-bleeding filtering at cloud construction)
**Companion specs:** pose-graph backbone (needs #149's keyframe rate to bound its node
store), mesh ceiling (fewer integrations/metre slows block growth)

Three gates between the sensor and the map, specced together because they share one
principle: *what enters the map is a decision, not a default*.

## A. Displacement gate (#149)

### Spike result (2026-08-19, measured)

One full shipped-defaults SLAM pass per capture; the exact pose of every frame reaching
`TsdfMap.integrate` recorded, then the RTAB-Map gate (integrate iff moved ≥ T_lin or
rotated ≥ T_ang since last integrated frame) simulated over that sequence:

| capture | frames (all integrate today) | 0.02 m/0.02 rad | **0.05/0.05 (RTAB-Map)** | 0.10/0.10 |
|---|---|---|---|---|
| `imuTranslationError.bin` (tripod) | 3019 | 66.7% skipped | **85.0% skipped** | 92.6% |
| `roomSweepFull20260730.bin` (sweep) | 3525 | 32.2% skipped | **67.8% skipped** | 82.7% |

Summed path drops 13.20 → 7.80 m on the tripod at the 0.05 gate (~41% of the reported
path is sub-threshold jitter; ~12% on the real sweep). Two honesty notes: (1) #149's
"18–20 m fabricated path" figure is stale — the shipped ZUPT/stationarity fixes already
cut the tripod to ~13.2 m integrated / 11.6 m reported; (2) this is an **open-loop**
simulation — a real gate changes the raycast model and hence subsequent poses, so
closed-loop skip rates will differ. The numbers answer "what fraction of today's pose
stream is sub-threshold," which is the sizing question.

### Decision

Implement the gate **on `integrate()` only**. Location is pinned: `Mapper.step` calls
`self._tsdf.integrate(...)` unconditionally at `slam/mapper.py:681` (inside `if not
lost:` at :672); the gate compares `pose` against a new `_last_integrated_pose` and skips
the integrate call while still advancing `_t_prev`/`_bootstrapped` (:683-684). Gated
frames **still run ICP** (pose continuity) and **still update display/orientation** —
the gate starves the map of redundant viewpoints, never the tracker of frames. Gate on
the pose delta, not IMU rate: the pose is the thing we are deciding to trust.

### Benchmark plan

Matched ensembles (`slam_ensemble`, n=10) on ≥3 captures — tripod + both room circuits —
at thresholds {off, 0.02, 0.05, 0.10}. Win conditions: reduced fabricated path on the
tripod and reduced TSDF block growth (report blocks at end of run), with **no** closure
regression on the circuits (paired CI must not show a significant worsening of
`horizontal_closure_m`) and no increase in tracking loss or ICP escalations — the known
opposite failure is starving frame-to-model of recent geometry. Cost: ~30 min per 10-run
CPU ensemble per capture (measured).

### Kill criterion

Killed if every threshold that meaningfully reduces integrations (>30% skip on the
circuits) also degrades circuit closure or tracking-loss counts with a significant
paired CI — that would mean this sensor's frame-to-model genuinely needs redundant
integrations, and the finding (with numbers) closes #149.

## B. Confidence policy (#153)

### Audit result (2026-08-19): the issue's premise is stale — confidence is already a hard gate

- `Mapper._gate_confidence` (`mapper.py:492-504`) zeroes depth below `min_confidence`
  (default **20.0**, `mapper.py:37`, on in every path — live, CLI, Detailed, remote —
  since 2026-07-11). NaN confidence fails the `>=` and is invalidated. So the real
  question is **rejection vs. weight**, not "is it used".
- **The threshold's provenance is dangling:** three code comments cite
  `task-quality-report.md` for the 20.0 value; that file exists nowhere in the repo or
  its git history. The default has no auditable derivation.
- **The weight plumbing already exists, unused:** `source_cloud` (`slam/cloud.py:15,22-24`)
  accepts an `intensity` array and attaches `pc.point["intensity"]`; nothing passes it.
- **No host-side analogue of RTAB-Map's depth-bleeding or bilateral filters** exists; the
  only flying-pixel defense is the vendor transform's internal stage
  (`VL53L9_TRANSFORM_LIGHT=0` — load-bearing, see CLAUDE.md).
- **Silent-flat hazard:** if `TRANSFORM_LIGHT` ever reverts to its self-defined 1, the
  confidence plane flattens to ~54 and the ≥20 gate becomes a silent no-op. No runtime
  assertion on the confidence distribution exists anywhere.
- **Range asymmetry:** the deprojector admits points to 10 m (`deproject.py:29`) but the
  TSDF caps at `depth_max = 5.0` m (`tsdf.py:201`) — points in the 5–10 m band steer ICP
  against a model that structurally cannot contain them (BUG-067-adjacent).
- **Terminal at the margin:** an aggressive threshold plus `_MIN_VALID_POINTS = 100`
  turns a low-confidence frame into `tracking_lost` — the exact BUG-036 dynamic the
  issue warned about (pinned by `test_slam_mapper.py:119-125`).

### Decision

1. **Re-derive the threshold** with an ensemble A/B over {None, 10, 20, 40} on the three
   reference captures, replacing the unauditable 20.0 with a measured choice.
2. **A/B confidence-as-weight** against the hard gate, via the existing `intensity` hook:
   pass normalized confidence into `source_cloud` and use it as per-point weights in the
   translation solve (`odometry.py:317-320` — the normal equations take a diagonal weight
   trivially). Weight is hypothesized better than rejection (rejection is terminal), but
   that is a measurement, not an assumption.
3. **Add the missing guard rails regardless of A/B outcome:** a startup/first-frame
   assertion on the confidence distribution (flat-at-~54 ⇒ hard error naming
   `TRANSFORM_LIGHT`), and align the SLAM deprojection range with `depth_max` (or record
   why not).
4. **Depth-bleeding/bilateral filters: not adopted** unless the confidence A/B leaves
   measurable flying-pixel residue — the vendor stage already covers this and a second
   filter needs its own evidence.

### Benchmark plan / kill criterion

Same ensemble protocol and captures as the displacement gate (they can share runs).
Weight mode wins only with a positive paired CI on closure or tracking-loss reduction vs.
the tuned hard gate; otherwise the hard gate stays and #153 closes with "audited:
rejection, tuned, guarded" as the outcome. The guard-rail items ship regardless.

## C. Per-frame time budget (#152)

### Decision

Adopt the *principle* — per-frame cost must not scale unbounded with map size — but the
RTAB-Map mechanism (WM→LTM demotion) is premature while the concrete cost drivers each
have cheaper, targeted answers: BUG-035's collapse shipped a capacity warning; extraction
cost belongs to the mesh-ceiling spec (chunked/incremental extraction); raycast target
windowing is the one live candidate. So: **defer the general demotion machinery; ship a
budget *monitor* first** — per-stage wall time vs. a stated per-frame contract (~33 ms),
logged and surfaced when breached, with `tick_share` from the existing watchdog as the
blocking-cost metric (never summed lateness). Report what exceeds budget; silence is how
BUG-035 stayed invisible for 560 frames.

### Benchmark plan / kill criterion

The monitor is cheap and unkillable (it is observability). The demotion mechanism is
triggered only by evidence from the monitor: if a full 10-minute-scale capture (needs
DC-B re-record) shows per-frame cost growth attributable to a *searchable-set* size (not
extraction, not capacity), design the demotion with an immunized local neighbourhood
then. Killed as a standalone work item if the monitor shows per-frame cost flat after
the mesh-ceiling spec lands — then #152 closes as "principle adopted via monitor;
mechanism unneeded on this map representation."

## Sequencing

A and B share ensemble runs — implement both behind config flags, sweep once. C's
monitor can ship independently. All three are downstream-neutral to the pose-graph spec
except that #149's accepted threshold defines the keyframe rate its node store budgets
against.

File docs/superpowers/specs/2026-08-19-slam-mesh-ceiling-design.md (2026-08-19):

# Lifting the mesh-extraction ceiling

**Status:** Specced (priority/later)
**Date:** 2026-08-19
**Issues:** #111 (lift the mesh-extraction ceiling)
**Companion specs:** native engine (`2026-08-19-slam-native-engine-design.md`, nvblox is
the escalation path), pose-graph backbone (per-node meshing is an alternative answer),
integration admission control (#149 slows block growth upstream)

## Problem

Open3D 0.19's CUDA marching cubes kills the *process* (segfault / illegal memory access →
`terminate()`) above **~260k active blocks** — an absolute count, not a load factor: the
same 273,521 blocks die at 68.4% load in a 400,000-block grid (BUG-053, #64, closed
`status/vendor` — closed as *not fixable by us at this Open3D version*, not as resolved).
`tsdf.py`'s `_MAX_SAFE_EXTRACT_BLOCKS = 250_000` refusal is live. The cost is concrete:
at 5 mm voxels, `DebugCapB1.bin` crosses the ceiling at frame 2625 of 4808 and can never
produce a mesh, which is why the Detailed preset retreated to 10 mm (BUG-054). A
room-sized capture at the sensor's actual resolution is unreachable — the whole point of
Detailed mode.

## Decision

Ordered, each step gating the next:

1. **Re-bisect on the newest Open3D first.** An upstream fix makes this whole spec
   unnecessary. Same method as the original: extract once at a known block count, no
   other extractions in flight.
2. **Build the subprocess bisector as an MCP tool** (named as 6.I's missing tool; the
   companion watchdog already shipped as `slam_stall_profile`). It must run each
   extraction in a **subprocess**, because the failure mode is a segfault/`terminate`
   that takes an in-process harness with it (same class as the OffscreenRenderer
   lesson: some failures abort, you can only make them unreachable). Output: the
   measured ceiling for the installed Open3D, as a number the refusal constant can cite.
3. **Primary fix: chunked extract-and-stitch.** The VBG is block-addressed, so the
   partition is natural; partitions overlap by one block and duplicate vertices are
   welded. Chosen over a different mesher because it keeps Open3D and every downstream
   consumer unchanged, and it makes extraction *incremental* — which also attacks
   BUG-052's per-extraction cost (the 1.11 s GIL-held whole-grid copy era) and #152's
   cost-scaling concern.
4. **Decouple tracking voxel from map voxel** (BUG-054's proposed resolution — track at
   10 mm, reconstruct at 5 mm) rides along once chunked extraction makes 5 mm maps
   extractable at all.
5. **Escalation path, not parallel work:** nvblox (#114) via the native-engine spec, and
   per-node meshing via the pose-graph spec (#150) — each dissolves the single-global-grid
   premise rather than raising its ceiling. Neither starts until chunked extraction has
   a measured verdict.

## Benchmark plan

- **Correctness:** chunked-vs-whole extraction on a below-ceiling capture must be
  vertex-and-triangle equivalent after welding (byte-level indifference not required;
  count and geometry deltas reported — seams framed so a null result can't be explained
  away: assert zero boundary-edge count delta along partition planes, not "looks fine").
- **The headline gate:** `DebugCapB1.bin` at `voxel_size = 0.005` produces a complete
  mesh (today: impossible past frame 2625). Report peak blocks, extraction wall time,
  and `tick_share` via `slam_stall_profile` (blocking cost, not wall time, is the number
  that matters on the live path).
- **Scaling curve:** extraction time vs. block count for whole-grid vs. chunked, past
  the old ceiling, from the bisector tool.
- Ensembles are not needed for the crash gate (deterministic) but any claim about
  Detailed-quality improvement at 5 mm goes through `slam_ensemble` as usual.

## Kill criteria

- **Killed by upstream:** if the newest Open3D extracts cleanly at 400k+ blocks, close
  #111 with the bisect evidence, bump the pinned version, delete the refusal constant.
- **Chunked path killed** if seam welding cannot reach zero boundary-edge delta (visible
  seams in the product are a non-starter), or if incremental chunked extraction at the
  Detailed cadence exceeds the current whole-grid extraction's blocking cost — then the
  answer is a different mesher, and the decision moves to the native-engine spec's nvblox
  stage (or VDBFusion as the CPU fallback, with its PCIe round-trip measured, not
  assumed).
- **Voxel decoupling killed** if 5 mm reconstruction shows no measurable quality gain
  over 10 mm on `splat_compare` against the ground-truth splat — 5 mm is already the one
  setting this repo has measured going backwards; do not ship it on principle.

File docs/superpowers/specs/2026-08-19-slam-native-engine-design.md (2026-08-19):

# Native engine candidates — small_gicp, nvblox, roomscan-native

**Status:** Specced (priority/later)
**Date:** 2026-08-19
**Issues:** #113 (small_gicp), #114 (nvblox), #116 (roomscan-native C++ core)
**Source report:** `references/software/frameworkExploration/researchResults.md` — used
with care: it is an external LLM-generated viability report, states **no licensing
information**, and sizes every VRAM claim against a **16 GB** RTX 2000 Ada when the
measured card is **8 GiB** (§6.G). Its architecture reasoning is useful; its numbers are
not evidence. Per the standing decision, these libraries are migration *candidates* to
benchmark, not commitments.

## Spike result (2026-08-19): small_gicp measured on real rig frames

`small_gicp 1.0.1` (one 378 KB manylinux wheel, zero install friction; left in
`host/.venv`) vs. the shipped registration, on 100 consecutive real pairs from
`roomSweepFull20260730.bin` (median 2200 pts/frame, identity init, matched knobs
`max_dist=0.05`, 6 iterations; i7-13850HX, 26 logical cores):

| engine (ms/pair) | 1 thread, reg only | 1 thread, + per-frame prep | 8 threads, total |
|---|---|---|---|
| shipped `translation` solve | 9.66 | — (raycast supplies normals) | 9.38 |
| Open3D `6dof` `_reg.icp` | 7.42 | — | **15.78** (slower threaded — tiny-workload thrash) |
| small_gicp GICP | 5.40 | 11.03 (cov est. 5.07) | **2.19** |
| small_gicp point-to-plane | 6.61 | 12.95 | 2.37 |

Agreement: small_gicp GICP vs Open3D 6dof translation delta **1.9 mm median / 5.9 mm
p95** (median inter-frame motion 19.3 mm) — same answer, so this is a speed question,
not a correctness one. All 6-DoF engines differ from the shipped translation solve by
13–15 mm median — that is the *mode* (real rotation leaking into translation under
identity init, BUG-067's mechanism), not the engine.

Three facts that reframe #113:

1. **The shipped `translation` mode does not call Open3D registration at all** — it is a
   hand-rolled hybrid_search + 3×3 numpy normal-equations solve
   (`odometry.py:278-330`). "Replace Open3D ICP" is the wrong frame; the candidate
   replacement target is a 9.4 ms numpy/NNS loop.
2. **small_gicp's Python wheel has no rotation-prior / translation-only mode.** The
   report's own §7.1 concedes DoF masks and IR-intensity costs require building from
   source with a custom pybind wrapper. And this project has *measured* that free 6-DoF
   rotation loses to the SFLP IMU (adaptive experiment: 17 m vs translation's 0.63 m on
   the null capture) — accuracy, not speed, justifies the shipped mode.
3. **The prep cost is real:** GICP needs covariances on both clouds every frame
   (1.1–5 ms), while frame-to-model gets target normals from the raycast for free. And
   the whole ICP stage is ~10 ms of a ~35 ms/frame budget — the ceiling on any win is
   Amdahl-bounded to a few ms unless the rest of the frame moves too.

## Decision

Staged evaluation, each stage with its own gate; **no cutover commitment at any stage**.
The Open3D pipeline remains the shipped engine until a stage's gate passes.

- **Stage N1 (#113): small_gicp inside the real Mapper, cheapest honest form first.**
  Before writing any C++: an A/B where small_gicp runs 6-DoF *initialized* with the SFLP
  rotation (no mask), frame-to-model, against the shipped solve — ensembles on the null
  capture (`imuTranslationError.bin`) and both circuits. The null capture is the
  assassin: every 6-DoF variant so far fabricates path there. Only if sg-with-IMU-init
  survives the null (≤ the shipped mode's ensemble drift) does the C++ work to get true
  3-DoF masks + a pybind wrapper get authorized — that build cost (from-source compile,
  custom wrapper, maintenance of a vendored native dep) is reported as part of the
  recommendation per the dependency rule, never assumed away.
- **Stage N2 (#114): nvblox is the mesh-ceiling escalation, not a parallel adoption.**
  It starts only if the mesh-ceiling spec's chunked-extraction path is killed. Entry
  criteria from the report, verified not assumed: standalone CMake build (CUDA + Eigen +
  glog), custom pybind bridge required, and **no automatic distance-based eviction** — a
  10-minute scan exhausts VRAM unless we build the sliding-window pruning ourselves, on
  an 8 GiB card (not the report's 16). Also weigh the measured alternative that costs
  nothing: the CPU `VoxelBlockGrid` completed the full sweep with 0 lost frames — the
  grid is device-homogeneous, so CPU is already the route to bigger-than-VRAM maps.
- **Stage N3 (#116): roomscan-native exists only as the conjunction gate.** A C++ daemon
  owning ingestion + odometry + graph + meshing is justified only if N1 *and* N2 have
  individually passed *and* profiling (`slam_stall_profile` `tick_share`, `slam_icp_bench
  what="ab"` — never the isolated microbench, which swings 43% between sessions) shows
  Python orchestration itself is the remaining bottleneck. Until then #116 is a
  dependent placeholder, and "the legacy Open3D architecture must be deprecated"
  (report §6) is explicitly **not** adopted as a premise.

## Benchmark plan

- **N1:** `slam_ensemble` (n=10) × {shipped translation, sg-GICP-IMU-init, and — if the
  C++ wrapper is built — sg-3DoF-masked} × {null capture, both circuits}. Primary
  metrics: null-capture fabricated path, circuit `horizontal_closure_m` (paired CI),
  tracking loss/escalations; secondary: real per-frame wall time and `tick_share` inside
  the Mapper (frame-to-model, not the spike's frame-to-frame). Quote `capture_analyze`
  continuity first, as always.
- **N2:** the mesh-ceiling spec's gates apply verbatim (DebugCapB1 at 5 mm, blocking
  cost, seam correctness), plus a VRAM-bounding demonstration on a 10-minute-scale run
  and a written build-burden report.
- **N3:** end-to-end frame budget on the live path vs. the Python orchestration, same
  capture, same ensemble discipline.

## Kill criteria

- **N1 killed** if sg-with-IMU-init fabricates on the null capture (ensemble drift
  materially above the shipped 0.63 m-class baseline), or if — after the mask work — the
  end-to-end per-frame improvement inside the real Mapper is < 2 ms (the spike's 4× on
  a 10 ms stage caps the win; a native dep + custom wrapper is not worth < 2 ms), or if
  drift/closure worsens at all. Close #113 with the spike + ensemble numbers either way —
  the measurement is the deliverable.
- **N2 killed** by the mesh-ceiling spec succeeding upstream (chunked extraction or a
  newer Open3D), or by the build-burden report (sliding-window eviction we must author
  ourselves on 8 GiB) exceeding what the CPU-grid fallback already provides for free.
- **N3 killed** by either prerequisite failing — and independently killed if profiling
  attributes the live bottleneck to anything other than Python orchestration (today's
  evidence says GIL-holding native calls, not Python, are the historical stall source).

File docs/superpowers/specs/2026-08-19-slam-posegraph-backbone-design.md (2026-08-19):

# SLAM pose-graph backbone — loop closure, per-node map, graph constraints

**Status:** Specced (priority/later; #110 is priority/next but blocked)
**Date:** 2026-08-19
**Issues:** #110 (drift correction / loop-closure evaluation), #115 (GTSAM factor-graph
backend), #150 (per-node cloud store beside the TSDF), #151 (gravity constraint +
optimize-from-graph-end)
**Companion specs:** relocalization (`2026-08-19-slam-relocalization-design.md`),
integration admission control (`2026-08-19-slam-integration-admission-design.md`),
mesh ceiling (`2026-08-19-slam-mesh-ceiling-design.md`)

## Problem

Frame-to-model ICP closes a single room to **~3%** (0.74 ± 0.19 m over a 23.9 m circuit,
10-run matched ensembles, `docs/roadmap-history.md` §6.D) — that is the number any
pose-graph/loop-closure machinery has to beat. The multi-room evidence so far makes the
case *weaker*, not stronger: DebugCapB1's drift rate (3.6%) is not worse than
single-room, meaning frame-to-model drift scales with path length and does not compound
at room transitions. But the B-series data is unusable for the go/no-go — transport loss
(BUG-049 / #60, still open) explains ~4.6 m of B3's 7.3 m closure (paired bootstrap mean
diff 4.569 m, 95% CI [3.950, 5.168] m), and B2 hides a 628-frame tracking collapse
starting 70 ms after a 2.4 s outage.

Independent of whether loop closure wins on drift, there is a **structural blocker**: our
poses are baked into the `VoxelBlockGrid` at integrate time, so correcting a pose means
de-integrating and re-integrating. RTAB-Map's per-node representation applies a graph
re-optimization as *one mat4 write per node* (`RTABMapApp.cpp:2036-2039`). That — not the
size of the drift — is why loop closure has stayed behind an evidence gate
(`docs/rtabmap-study.md` §1).

## Decision

1. **The pose graph is an offline pass first, not a live 46 Hz backend.** 6.D item 3 as
   written: keyframes from offline tracking, non-adjacent pose-proximity revisit
   candidates, strict-ICP edge verification, global optimize, then re-integrate every raw
   frame against the optimized trajectory. The `researchResults.md` "iSAM2 in a C++
   thread at 46 Hz" architecture is explicitly **not** adopted at this stage — its own §7.4
   admits Python factor construction at 46 Hz is a latency risk, and we have no evidence
   yet that a graph earns its complexity at all. Offline needs no C++ daemon.
2. **Optimizer: GTSAM (#115), scoped to that offline pass.** Chosen over g2o because the
   two graph constraints we want are first-class there: `Pose3AttitudeFactor` (or a
   near-zero-rotational-covariance `PriorFactor<Pose3>`) reproduces the 3-DoF discipline
   the live pipeline already learned the hard way (free 6-DoF rotation loses to the SFLP
   IMU on this sensor — ROADMAP "never 6dof"), and gravity factors are supported (#151).
   IMU preintegration factors are **out of scope** for v1 (accel-derived translation is
   a standing non-input, §6.G survey).
3. **Map correctability: hybrid per-node store (#150), not a rewrite.** Keep the TSDF as
   the live fused surface; *additionally* retain per-keyframe clouds (deprojected,
   decimated, node-frame) with poses, admitted at the keyframe rate from the displacement
   gate (#149 — see the admission-control spec; the measured gate keeps only 15–32% of
   frames, which bounds this store). A loop closure then = optimize graph → rewrite node
   poses → rebuild a fresh TSDF as a batch replay. No interactive de-integration.
4. **Graph conventions decided now, before any UX exists (#151):** gravity direction is a
   per-node constraint (RTAB-Map `Optimizer/GravitySigma = 0.2` as the starting point,
   final value by ensemble), and optimization pins the **last** pose
   (`OptimizeFromGraphEnd = true` semantics) so a correction moves the map under the
   camera, never jumps the camera.
5. **Adopt the wrong-loop rejection check unconditionally** (`RGBD/OptimizeMaxError = 3.0`
   analogue: reject a loop edge if post-optimization residual over per-link sigma exceeds
   the ratio). It is representation-independent and cheap (#154's one portable piece).

## Prerequisites (in order)

1. **#60 (BUG-049) fixed or bypassed** — the Pi 3 bridge (#191) with its pcap tee is the
   in-flight mitigation. Then **re-record DC-B (#138)**: ≥2 multi-room closed-loop takes
   passing `capture_analyze` continuity (`complete`, not merely `clean` — the old takes
   were byte-perfect while losing 2.3–9.4% of frames).
2. **Characterize the SFLP gravity-direction error before assigning it a sigma** (#151):
   the quat is a batch mean with a capture-dependent, sign-varying phase lead
   (+5.1 ± 0.7 ms typical, −3.9 ms on `officeFullScanAug6.bin` — measure per capture with
   `capture_skew`, never assume the recorded number), and the accelerometer sees hand
   motion. A short static + slow-tilt analysis on existing captures is enough.
3. Keyframe store cost measured honestly on `roomSweepFull20260730.bin` and
   `coffeeRoomCircuitNoMnt.bin` (RAM/VRAM per node at the #149 keyframe rate) before
   committing to #150's hybrid.

## Benchmark plan

- **Unit of evidence: matched ensembles**, never single runs (`slam_ensemble`, n=10; a
  3 mm nudge moves closure by 0.37 m). Check `runs_died` / `any_saturated` before quoting.
- **Arms:** baseline (shipped frame-to-model) vs. pose-graph pass, on both single-room
  circuits (`coffeeRoomCircuitNoMnt.bin`, `coffeeRoomCircuitMnt.bin`) and the re-recorded
  DC-B takes. Metric: `summary.horizontal_closure_m` (closure is drift only where the
  operator returned to start — DC-B protocol guarantees it; `roomSweepFull20260730.bin`
  has no bookend and must not be quoted as drift).
- **Acceptance gate is mechanical:** `slam_loop_closure_gate(baseline, loop_closure)` —
  positive paired 95% CI for reduced horizontal closure on **both** circuits, no run
  dies, no increased tracking loss. This is the pre-registered 6.D item-4 gate; the MCP
  tool already exists.
- **Gravity/graph-end sub-experiments:** gravity sigma swept {0.1, 0.2, 0.3} by ensemble;
  optimize-from-graph-end verified by construction (it changes gauge, not accuracy).
- **#150 memory check:** peak RSS/VRAM with and without the node store on both reference
  captures, reported per node and extrapolated to a 10-minute scan.

## Kill criteria

- **Loop closure (#110):** if, on clean-transport DC-B re-records, the paired gate fails
  on either circuit — or multi-room drift rate remains ≈ the single-room ~3% (no
  compounding to correct) — ship `loop_closure.enabled = false` with the reason in the
  manifest, close #110 as *evaluated, does not earn its complexity indoors*, and #115
  (GTSAM) dies with it. The evaluation itself is the deliverable.
- **Per-node store (#150):** killed if the measured per-node cost extrapolates past
  ~25% of host RAM for a 10-minute scan at the chosen keyframe rate, or if the batch
  TSDF rebuild from corrected poses exceeds ~2× a Detailed replay's wall time — at that
  point "re-run Detailed offline with the corrected trajectory" is the same product for
  less machinery.
- **Gravity factor (#151):** killed if the measured SFLP gravity-direction error is so
  small that roll/pitch drift is unobservable over a 3-minute graph (then the factor
  constrains nothing) or so large/motion-contaminated that no sigma in {0.1–0.3} passes
  the ensemble without degrading closure.

## Explicit non-goals

- No live iSAM2 thread, no C++ daemon (that is the native-engine spec's Stage N3, with
  its own gate).
- No relocalization — separate spec; 6.D keeps it out of scope deliberately.
- No appearance-based loop detection — measured dead on this sensor (see the
  relocalization spec's IR spike); revisit candidates come from **pose proximity** only.

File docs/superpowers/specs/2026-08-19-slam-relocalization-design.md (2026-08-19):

# Relocalization and place recognition — recovering from a bad second

**Status:** Specced (priority/later)
**Date:** 2026-08-19
**Issues:** #112 (relocalization), #154 (appearance-based place recognition evaluation)
**Companion spec:** pose-graph backbone (`2026-08-19-slam-posegraph-backbone-design.md`)

## Problem

The ICP escalating retry (BUG-036) survives a bad *frame*, not a bad *second*: a real
tracking kill is terminal unless the operator walks back to already-mapped geometry —
which the DC-C stress captures show works (82–120-frame freezes, every run recovered,
0 died), but only because the capture protocol *is* the walk-back. The gap is real but
operator-maskable (`docs/roadmap-history.md` §6.D). #112 is also the ceiling on the
residual BUG-067 path over-report: only a re-anchor removes fabricated drift the
coherence veto can't hold through.

## Spike result (2026-08-19): appearance-based recognition is dead on this sensor

#154 branch 1 asked whether 54×42 IR/reflectance carries repeatable keypoints. Measured
on real captures (ORB + GFTT, log/percentile normalization, params rescaled for the tiny
image; opencv-python-headless 5.0.0.93 in `host/.venv`; scripts were throwaway):

| condition | ORB matches (med) | RANSAC inlier frac |
|---|---|---|
| sweep, adjacent frames (Δ=1) | 57 | 0.79 |
| **sweep, Δ=30 ≈ 1 s (~83% overlap retained, verified by phase correlation)** | **17** | **0.36** |
| **chance floor: Δ=600 ≈ 20 s, different heading** | **16** | **0.35** |
| static tripod, Δ=30 | 52 of ~178 kp | 0.79 |

After one second of gentle panning, matching is statistically indistinguishable from
matching unrelated frames — and even a rigidly static scene loses ~70% of
correspondences per second to temporal sensor noise alone. 4× upsampling does not help
(Δ=30 gets worse); a fixed-pattern-noise probe (same-coordinate fraction 0.00 at Δ=600)
confirmed FPN is neither faking nor masking the result. **BoW over ToF-IR cannot work.**
This kills #154's branch 1 by measurement, not by argument.

## Decision

1. **Place recognition, where needed, is geometric or borrowed — never IR-appearance.**
   Remaining branches, in order of evaluation cost:
   - **Pose-proximity submap matching** (no descriptor at all): candidate revisits chosen
     by proximity of the current pose estimate to stored keyframe poses, verified by
     strict ICP against the stored node cloud (the `researchResults.md` §8.2 /
     GLIM-style design, and what the pose-graph spec's offline pass already requires).
     This is the primary path — it needs no new signal and its failure mode (drift too
     large for proximity search) is exactly what a bounded search radius exposes.
   - **Scan-context-style depth descriptors** (the LiDAR community's answer): cheap to
     evaluate offline on existing captures with the *same protocol as the IR spike* —
     descriptor distance between revisits vs. unrelated frames on a circuit capture. Only
     pursued if pose-proximity proves insufficient (i.e., real kills where the pose prior
     is too wrong to bound the search).
   - **Borrow the phone** (Phase 7 only): RTAB-Map loop closures computed on textured
     imagery, transferred onto our graph. Offline-only by construction; not a live
     relocalization answer.
2. **Live relocalization v1 = re-anchor, not recognition.** On a detected kill
   (`tracking_stats` already reports `died`/freeze runs): freeze integration, hold the
   SFLP orientation (trustworthy through a kill — it is not ICP-derived), and run the
   escalating ICP against the raycast model from a **zero-velocity re-anchored** pose
   with a widening translation search. This formalizes the walk-back that DC-C proved
   works, and removes the operator from the loop for the common case.
3. **Adopt the wrong-loop / wrong-anchor rejection ratio** (post-optimization residual
   over per-link sigma, RTAB-Map `RGBD/OptimizeMaxError = 3.0` analogue) on any accepted
   re-anchor or revisit edge — representation-independent, and the one #154 item that
   ports regardless of branch.

## Benchmark plan

- **Fixture:** `DebugCapC.bin` (deliberate 2 s tracking kills) — already recorded, known
  freeze windows of 82–120 frames. Ensembles via `slam_ensemble` (n=10).
- **Metrics:** recovery latency (frames from kill to re-lock), recovered-pose error at
  re-lock vs. the pre-kill trajectory extrapolation, fabricated path during the freeze
  (today's baseline: 376–467 lost frames/run), and — regression guard — no change on
  kill-free captures (the re-anchor must be unreachable when tracking is healthy).
- **Scan-context spike (only if triggered):** offline descriptor-separation test on
  `coffeeRoomCircuitNoMnt.bin` — distance distribution of true revisit pairs vs.
  unrelated pairs; report AUC. Same discipline as the IR spike: a control arm of
  unrelated frames, and the check must be able to see wrong answers.
- **Cost note:** a CPU SLAM pass is ~70–125 s per capture (measured 2026-08-19), so a
  10-run ensemble is ~30 min/capture — plan sweeps accordingly.

## Kill criteria

- **Re-anchor v1:** killed if it fires on healthy captures (any activation on the
  circuit ensembles) or if recovered-pose error on DC-C exceeds what the walk-back
  protocol achieves today — automation that recovers worse than the operator is a
  regression.
- **Scan-context branch:** killed if the offline separation test shows revisit vs.
  unrelated AUC < 0.8 — that is the same "chance floor" verdict the IR spike delivered,
  and the honest conclusion becomes: *no in-session place recognition is viable at 54×42;
  relocalization is re-anchor + pose-proximity, full stop.* Close #154 with the two
  negative measurements as the record.
- **Phone-transfer branch:** out of scope here; it lives or dies with the offline-3DGS
  program spec (posed phone captures) and never gates live scanning.

## Explicit non-goals

- No BoW, no visual vocabulary, no learned descriptors on ToF-IR (measured dead, above).
- No live loop-closure search — that stays behind the pose-graph spec's paired-CI gate.

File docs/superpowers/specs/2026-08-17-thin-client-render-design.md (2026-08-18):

# LiDAR thin-client render — server side

**Status:** Approved for planning
**Date:** 2026-08-17
**Repo:** `lidar-roomscanner` (this repo)
**Companion spec:** `CrowPanelProp` repo,
`docs/superpowers/specs/2026-08-17-lidar-thin-client-crowpanel-design.md` (client side —
a cassette-futurism prop communicator built on a CrowPanel ESP32-P4 7" display). The
**Protocol contract** section below is duplicated verbatim in both specs — it's the shared
interface, not a cross-reference — keep them in sync if it changes.

## Goal

Serve a live, already-rendered view of the point cloud / SLAM / IR feed to a resource-
constrained embedded client (an ESP32-P4 panel with no GPU, no 3D pipeline, and no image
codec) that can only display raw pixels and send small JSON commands back.

## Non-goals

- No 3D data (points, mesh, triangles) is ever sent to this client — only rendered
  raster frames. The existing `/ws`/`/ws-mesh` protocol (browser clients) is unaffected
  and unchanged by this work.
- No image compression (JPEG/PNG) in v1 — raw RGB565 only. See "Open questions" for the
  deferred codec path, which would be server-side JPEG encoding once the client can
  decode it.
- No exposing ranging-profile/manual-parameter device control (`set_profile`,
  `set_manual_params`) through this endpoint in v1 — those stay reachable only via the
  existing `/ws` protocol from the browser.

## Architecture

**Thin-client model:** this server does all 3D rendering. The client (CrowPanel) is a
remote display + input relay only.

**`host/src/roomscan/thin_render.py`** (new module) — owns:

- An Open3D `OffscreenRenderer` (Open3D is already a dependency here for SLAM meshing;
  chosen over driving a headless browser against the existing Three.js UI via Playwright,
  which would need a full Chromium instance per stream and is too slow for a real-time
  orbit-control loop).
- Camera-orbit state (yaw/pitch/zoom) per connected thin client, updated by incoming
  `thin_orbit` commands.
- Current render mode (`point_cloud` / `slam` / `ir`) per connected thin client, updated
  by `thin_mode`.
- A render loop that, on each tick, pulls the latest data already computed by the
  existing pipeline — the same `pts`/`colors` arrays that feed `pack_point_cloud`
  (`web.py:1085`), the latest SLAM mesh, or the latest IR frame (`ir_image.py`) — applies
  the orbit state, renders to 480×480 RGBA, and converts to RGB565. No new sensor-side
  computation; this reuses data the existing pipeline already produces.

**New `/ws-thin` endpoint** in `web.py`, with its own broadcast loop/task (mirroring the
existing point-cloud broadcaster's task structure, `POINT_INTERVAL`-style ticking) so it
never blocks the main reader thread or the existing `/ws`/`/ws-mesh` clients. Runs
independently per-connection camera/mode state (multiple thin clients could theoretically
connect with different orbit angles).

**New mDNS advertisement.** This server does not advertise itself via mDNS today — the
existing `zeroconf` dependency in `sources.py` is used for discovering the MCU/travel
router, not for advertising the web server. Add a `zeroconf.ServiceInfo` registration for
the web server itself, started alongside the existing FastAPI/uvicorn startup, so the
CrowPanel (or any future thin client) can find it without a hardcoded IP.

## Protocol contract (`/ws-thin`)

New WebSocket endpoint: **`GET /ws-thin`**. Independent of the existing `/ws` and
`/ws-mesh` protocol (`docs/web-protocol.md`) — a thin client never receives
`POINT_CLOUD`/`MESH`/`IR_IMAGE` binary tags or the full JSON message surface. This keeps
the embedded client's parsing trivial and avoids adding a subscribe/filter layer to the
existing sockets.

### Binary frame (server → client): `THIN_FRAME`

Fixed 480×480 for v1 (no resolution negotiation — see "Open questions").

```
u32 tag        = 1
u16 width      = 480
u16 height     = 480
u8  pixels[width * height * 2]   // RGB565, little-endian, row-major
```

Target cadence: **~10 fps** (~460 KB/frame → ~4.6 MB/s per connected thin client). If a
client falls behind (its WS send buffer growing), drop to the freshest frame rather than
queueing — same decimation policy as the existing point-cloud broadcaster
(`POINT_INTERVAL`, `web.py:141`).

### JSON out: `thin_telemetry`

Sent at a lower cadence (~2 Hz) — deliberately not sent per-frame:

```json
{
  "type": "thin_telemetry",
  "fps": 9.8,
  "point_count": 2268,
  "recording": false,
  "mode": "point_cloud",
  "link": "ok",
  "roll_deg": -3.5,
  "tilt_deg": 12.8,
  "heading_deg": 117.2,
  "orientation_valid": true,
  "orientation_labels": ["Roll", "Tilt", "Heading"]
}
```

`fps`/`point_count` and the orientation block are a curated subset of the existing
`ranging`/`sensor` JSON fields already computed by `web._ranging_message` /
`build_sensor_message` — no new telemetry math, just a smaller projection of it for this
endpoint.

**Revised 2026-08-18 (owner):** `power_mode` and `i3c_airtime_pct` are **dropped** — the
operator does not want bus/power figures on this panel — and replaced by orientation and
heading, which they do. `roll_deg`/`tilt_deg`/`heading_deg` are copied **verbatim** from the
sensor message's `orientation_view` + `heading_deg`, i.e. the same numbers in the same
decomposition the web UI's Sensors panel shows; they are never recomputed from the
quaternion here (no scalar off an attitude is the bearing of an axis — the repo's
most-repeated defect). `orientation_valid` is false when the heading cannot be trusted (bad
mag reading, device accelerating, or a boresight within 10° of vertical where no compass
bearing exists at all); a client should grey the compass rather than draw a confident wrong
bearing. `heading_deg` has **no fallback** to `orientation_view["yaw_deg"]` — that slot is the
heading only under the World decomposition, and a Tait-Bryan body-axis twist under `zyx`;
`null` means no bearing exists. `orientation_labels` carries the operator's own three axis
names. `mode` and `recording` here are the **authoritative**
state the client should render; this endpoint has no ack/retry protocol, so a dropped
`thin_mode`/`thin_record` command self-corrects at the next telemetry tick.

### JSON in (client → server commands)

```json
{"type": "thin_orbit", "dyaw": 3.5, "dpitch": -1.0, "dzoom": 0.0}
{"type": "thin_mode", "mode": "point_cloud" | "slam" | "ir"}
{"type": "thin_record", "on": true}
```

- `thin_orbit`: relative deltas, applied cumulatively to this connection's camera state
  each time one arrives. No validation beyond clamping to sane bounds (e.g. pitch range)
  needed — malformed/extreme values just produce an odd-looking frame, not a crash.
- `thin_mode`: switches this connection's render source between the three modes.
- `thin_record`: reuses the **existing** record start/stop logic already wired to the
  browser's record control — do not duplicate recording logic, just add this as a second
  entry point into the same handler `web.py`'s browser `record` message already calls.

### mDNS advertisement

Register a `ServiceInfo` for the web server on startup: service type
`_roomscan._tcp.local.`, instance name `roomscan`, port `8000`. This is new — no prior
advertisement of this server exists.

## Error handling

- **Renderer init failure** (e.g. Open3D can't get a rendering context on this machine):
  `/ws-thin` should reject the connection with a JSON error message and close cleanly, not
  crash the `roomscan.web` process. The existing `/ws`/`/ws-mesh` clients must be
  completely unaffected by a thin-render failure.
- **Backpressure:** freshest-frame-wins per connection, matching the existing broadcaster
  policy — a thin client that can't keep up gets frames dropped for it specifically, never
  a global slowdown of the render loop or other connected clients.
- **Bad/malformed inbound JSON:** ignore and log, don't disconnect the client for one bad
  command — telemetry will still resync it.
- **Client disconnect:** tear down that connection's orbit/mode state; no persistence
  needed across reconnects (a fresh connection starts at a default camera angle and
  `point_cloud` mode).

## Testing / validation plan

- Unit test the `THIN_FRAME` packer (byte layout, dimensions, RGB565 conversion
  correctness) in isolation from the renderer.
- A small standalone test script (same shape as `tools/query_mdns.py` / the MCP server's
  `RigSession` in `host/src/roomscan/mcp_server/session.py`) that connects to `/ws-thin`
  as a fake client, saves received frames as PNGs for a visual sanity check, and
  round-trips `thin_orbit`/`thin_mode`/`thin_record`.
- End-to-end validation using the existing `--replay recordings/scan.bin` capability — no
  physical LiDAR hardware needed to exercise the thin-render path during development.
- Confirm the existing `/ws`/`/ws-mesh` browser clients see no behavior/performance
  regression with a thin client simultaneously connected (the whole point of the separate
  endpoint + separate broadcast task).

## Open questions / deferred work

- **Resolution/rate negotiation:** v1 hardcodes 480×480 @ ~10 fps on both sides. A
  `thin_hello` handshake to negotiate size/rate per client is plausible future work but
  adds protocol surface not needed for a single known client class today.
- **JPEG encoding:** `Pillow` (already a dependency, already used for `IR_IMAGE`-adjacent
  work) could JPEG-encode `THIN_FRAME` payloads to cut bandwidth ~5-10x, once the CrowPanel
  side has a decoder (its onboard JPEG hardware block is currently unused/unwired — see
  companion spec). Not needed for v1.
- **Exposing device parameter control** (`set_profile`/`set_manual_params`) through
  `/ws-thin`: explicitly out of scope for v1; revisit if operators want full DEVICE-panel
  parity from the CrowPanel.

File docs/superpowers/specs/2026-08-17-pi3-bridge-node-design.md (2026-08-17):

# Raspberry Pi 3 bridge node

## Status

**Accepted and implemented (2026-08-17), hardware acceptance outstanding.**
The §10 open questions are decided (see below) and the design is built:
`pi-bridge/` (rootless image builder + payload), `host/tools/pi_bridge.py` +
`bridge_*` MCP tools, and `host/tools/pcap2capture.py` for the tee. Governing
issue **#191**; procedure in [`../../pi-bridge-runbook.md`](../../pi-bridge-runbook.md).
No firmware or wire-protocol change was needed, as anticipated.

**None of §11's acceptance gates have run** -- every one of them needs a real Pi
and a real capture -- so #191 stays open with `needs/operator`. Do not read
"implemented" as "verified".

Owner decisions, 2026-08-17, superseding the open questions in §10:

- **§10.1 bridge shape: routed + NAT, not L2.** True transparent bridging is not
  available here: `brcmfmac` has no 4-address station bridging, and the
  proxy-ARP workaround would make the scanner's DHCP lease hostage to the Wi-Fi
  hop -- which, given the firmware's 3000 ms DHCP window (§3), means a slow
  association silently drops the scanner into its self-assigned fallback mode.
  §4's "recommend L2 first" is therefore withdrawn, not deferred. The mDNS
  concern in §8.3 is met by publishing `roomscanner._roomscan._udp` from the
  Pi's own avahi on `wlan0`, so `UdpSource` needs no change.
- **§10.2/§7.1 tee: in v1.** Bounded 2 GB pcap ring on the Pi.
- **§10.3 hardware: Pi 3 Model B.**
- **§10.4 travel-mode:** `travel-ap.sh` needs no changes (it does not care which
  client associates); `filehub-bridgemode.sh` becomes dead weight and should be
  retired in a follow-up.
- **§10.5 FileHub: kept as a cold spare**, never plugged in alongside the Pi --
  two responders announcing `roomscanner` on one segment is a name collision.

## 1. Goal

Mount a Raspberry Pi 3 on the rig stack, wired to the existing STM32H563
Ethernet link, replacing the RavPower FileHub as the scanner's wireless
uplink to the server. Optionally: tee raw frames to local storage as a
write-ahead capture buffer, and optionally display `roomscan-web` on an
attached screen. Explicitly **no on-device SLAM or splat compute** — the Pi
is an I/O and bridging node only, matching its actual class (BCM2837, 1 GB
RAM). A future revision may add a USB global-shutter camera to this same
node (§9); this spec anticipates that but does not design it.

## 2. Scope and non-goals

**In scope:** network topology (scanner → Pi → server), transport choice for
the scanner-to-Pi hop, wireless-uplink behavior replacing FileHub bridge
mode, optional local recording tee, optional kiosk display, power/mounting
budget, and the bus-sharing constraint a future USB camera would introduce.

**Out of scope:** the camera module itself (sensor choice, capture pipeline,
timestamp alignment — a separate future spec once a module is picked), any
on-device compute (SLAM, ICP, splat training all stay on the server GPU per
the existing Phase 6/7 architecture and the `distributed-slam-spike` note),
and a full task-level implementation plan.

## 3. Current state (baseline being replaced)

- The scanner streams RSCN frames over Ethernet/UDP (transport-agnostic
  framing, `docs/protocol.md`); the host's `UdpSource` discovers the device
  via mDNS (`roomscanner.local`) and sends a periodic unicast keepalive
  (`docs/system-architecture.md`).
- Today's wireless hop is a commercial FileHub acting as a Wi-Fi bridge:
  wired to the scanner, associated to the wireless network as a client,
  forwarding raw Ethernet frames. Bridge-mode recovery is a fragile manual
  sequence (unplug Ethernet → power-cycle → apply bridge mode → reconnect
  Ethernet), and it is a black box — nothing on that hop is observable.
- The `travel-mode` plan (`docs/superpowers/plans/2026-08-03-travel-mode.md`)
  adds a Proxmox-hosted 2.4 GHz AP as a fallback network when no wired
  uplink is present at the server end; the FileHub associates to whichever
  SSID (home `Surly_Office` or the travel AP) is currently live.
- Known problem this is meant to help: captures lose 2.3–9.4% of frames
  while reporting clean (`[[capture-loss-invisible-and-dominant]]`), and the
  wireless bridge — opaque, unobservable, with a manual recovery dance — is
  the leading suspect.

## 4. Proposed topology

```
STM32H563 --[Ethernet: UdpSource discovery + RSCN/UDP]--> Pi 3 (eth0)
                                                              |
                                          Pi 3 (wlan0, 2.4 GHz client)
                                          --[Surly_Office or travel AP]--> server
                                   (optional) local storage: write-ahead frame tee
                                   (optional) HDMI/DSI: roomscan-web kiosk view
                                   (future)   USB global-shutter camera
```

**Bridge shape — decide L2 vs L3 (§10.1):** the simplest drop-in replacement
for the FileHub is an L2 bridge (`eth0`↔`wlan0`, same subnet, no DHCP/NAT on
the Pi) so the scanner keeps its existing address behavior and the host's
`UdpSource`/mDNS/keepalive path is untouched. An L3/NAT hop (Pi owns its own
subnet, forwards/NATs to the wireless network) is more robust to Wi-Fi
flakiness (the Pi can hold a stable link-local address to the scanner even
while its uplink bounces) but requires re-verifying mDNS/multicast discovery
and the keepalive path across the extra hop. Recommend starting with L2 to
minimize the blast radius of this change, and revisit L3 only if bridging
turns out to reintroduce the same opacity problem it's meant to fix.

## 5. Scanner-to-Pi link: Ethernet, not USB

Both are already scanner-supported transports (protocol.md's framing is
transport-agnostic; CDC and UDP are both live). Ethernet is the right choice
here:

- It's a transparent drop-in for the FileHub's existing role — no host-side
  change, no new driver.
- It keeps USB free. A Pi 3 has exactly one shared USB2 controller behind
  all four ports (and, on the 3B+, behind the "gigabit" Ethernet jack too) —
  reserving USB for a future camera avoids putting camera bytes on the same
  bus as anything else from day one.
- USB CDC would reintroduce the cable-length limit that Ethernet (Phase 5)
  was specifically built to remove.

## 6. Wireless uplink, replacing FileHub bridge mode

The Pi 3's onboard radio is 802.11n, **2.4 GHz only** — same constraint the
travel-mode AP already designs around, and it must land on Home Wi-Fi's
2.4 GHz band specifically (not the network's 5 GHz SSID, if dual-band).
Rather than the FileHub's fragile explicit "bridge mode" toggle, the Pi
associates as a normal `wpa_supplicant` client to whichever SSID is active
(home `Surly_Office` or the travel AP), taking its own DHCP lease. That's
arguably a reliability win on its own: it removes the manual
unplug/power-cycle/re-apply recovery sequence entirely, and — if this
extends the travel-mode plan — the Pi is the thing that should register as
the travel AP's known client, not the FileHub's MAC as recorded today.

## 7. Optional roles

**7.1 Local write-ahead recording tee (highest-value option).** The Pi
copies frame bytes to local storage (microSD or a USB stick, budget
permitting against §9) before or independent of forwarding them wirelessly,
following the same invariants as the Rerun sidecar design (fail open, off
the hot path, bounded queue, drop only its own tee on overload, never delay
or drop a frame headed to the primary link). This is the direct fix for
§3's frame-loss problem: today, if the Wi-Fi hop drops a frame, it is gone;
with a local tee, it's recoverable from the Pi after the fact. Needs a
measured write bandwidth check against card/stick throughput before this is
more than a proposal (§10.2).

**7.2 `roomscan-web` kiosk display.** Optional and off by default. Be
realistic about the hardware: headless Chrome/WebGL is known to be
expensive even on real desktop-class CPUs
(`[[headless-chrome-burns-cores]]`), and a Pi 3's VideoCore IV GPU is not in
that class. Full 3D `roomscan-web` at usable FPS on a Pi 3 is unlikely;
treat this as "maybe a stripped-down status page," not "the real UI on a
small screen," until measured.

**7.3 PTP boundary clock.** The Pi is a plausible place to run `linuxptp`
ahead of Phase 6's hardware time-sync item, since it already sits on the
scanner's wired segment. Worth a line item later; not designed here.

## 8. Required invariants

1. **No new single point of failure worse than today's.** The scanner must
   remain directly usable over a wired Ethernet cable straight to a laptop
   if the Pi is absent, dead, or being swapped — this is an additive bridge
   node, not a mandatory hop.
2. **Transparent relay on the primary path.** In its bridging role the Pi
   forwards bytes; it does not decode, mutate, or rate-limit RSCN frames.
   Any optional local tee is copy-only and non-blocking, matching the
   Rerun-sidecar fail-open pattern — a tee fault disables only the tee.
3. **Multicast/mDNS survives the extra hop.** This needs explicit
   verification, not an assumption — the STM32H5 ETH MAC already drops
   multicast by default on the firmware side
   (`[[eth-mdns-multicast-filter]]`); an L2 bridge or Wi-Fi AP hop is a
   second place multicast forwarding can silently fail. Confirm
   `roomscanner.local` discovery and the UDP keepalive both work end to end
   before calling this a working replacement.
4. **Truthful reporting.** If the Pi is a bridge, its own health (radio
   state, association status, forwarding drops) needs to be visible
   somewhere — a black-box bridge is exactly the problem being replaced, so
   this one should not become opaque in the same way.

## 9. Power, mounting, and the future-camera bus constraint

A Pi 3 draws roughly 300–400 mA idle and can spike past 700 mA under
Wi-Fi + CPU load at 5 V — it needs its own sized regulated rail off the rig
battery, not an assumption that the FileHub's existing supply is
interchangeable. Mounting, weight, and heat on a handheld rig also need a
pass; this spec doesn't design the physical mount.

On the anticipated USB global-shutter camera: flag now, don't design yet.
A Pi 3 has a single shared USB2 bus. Scanner traffic goes over Ethernet
(§5), which helps, but a future camera stream would still share that one
USB2 bus with anything else USB-attached (a local-recording USB stick, if
that's the storage choice in §7.1). Budget the camera's real bandwidth need
against that shared bus before committing to a Pi 3 as the camera host —
this is also consistent with the caution given in the earlier camera
conversation: a Pi 3 is fine as an I/O node, but its ceiling is meaningfully
lower than a Pi 4/5 or CM4/5, and camera quality/bus headroom is exactly
where that ceiling would first be felt.

## 10. Risks and open questions (owner input needed)

1. **Bridge shape (§4):** L2 transparent bridge vs. L3/NAT hop. Recommend
   L2 first; needs an explicit decision before implementation.
2. **Bandwidth check, not assumption.** Before designing the local tee
   (§7.1), measure the scanner's actual sustained frame rate/size against
   the Pi 3's real Ethernet throughput (10/100 vs. Gigabit-over-USB2 depends
   on the exact Pi 3 model — 3, 3B, or 3B+; confirm which units are on
   hand) and against microSD/USB-stick sustained write speed. Don't assume
   headroom either direction.
3. **Which Pi 3 model(s)?** 3B+'s Ethernet is faster but still shares the
   one USB2 controller; plain 3/3B is 10/100 only. This changes the
   bandwidth math in #2 and matters more once the camera is in play.
4. **Interaction with travel-mode.** Does the Pi replace the FileHub as the
   travel AP's client too, or does travel-mode need its own update to
   recognize the Pi's MAC/behavior? `travel-ap.sh`'s gating logic doesn't
   care who the wireless client is, but the FileHub-specific bridge-recovery
   steps (`filehub-bridgemode.sh`) become dead weight once the Pi takes over
   and should be retired, not left as a second, now-redundant path.
5. **Does the FileHub get removed entirely, or kept as a cold spare?** Given
   how flaky it's been, keeping one as a fallback bridge (not in the primary
   path) may be worth the shelf space during the Pi rollout.

## 11. Acceptance gates (before calling this shipped)

1. **Parity:** discovery, FPS, CRC, and gap counters over a representative
   capture match or beat the current FileHub baseline — not just "it
   streams," but a real side-by-side.
2. **Reliability:** with the local tee enabled, measured frame loss on a
   real capture is lower than the FileHub-only baseline
   (`[[capture-loss-invisible-and-dominant]]`); if it isn't, the tee isn't
   earning its complexity.
3. **Bounded failure:** killing Wi-Fi, power-cycling the Pi, or unplugging
   it mid-capture degrades no worse than today's FileHub failure mode, and
   the direct-Ethernet-to-laptop fallback (§8.1) still works untouched.
4. **Kiosk display, if enabled:** measured FPS/CPU on real Pi 3 hardware
   decides whether it's the real UI or a stripped status page — no
   optimistic default.

## 12. Documentation affected by implementation

`docs/system-architecture.md`'s network description, the travel-mode plan
(§10 above), `ROADMAP.md`'s plans/specs register, and likely a new
operational runbook parallel to `travel-ap.sh` for the Pi's own
install/reconcile/status story. No change to `docs/protocol.md` — this adds
no wire-protocol behavior.

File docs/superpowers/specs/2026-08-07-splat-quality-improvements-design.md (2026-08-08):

# Splat quality improvements — design

**Date:** 2026-08-07 (corrected 2026-08-08)
**Status:** in progress (A shipped, B–E specced)
**Owner ask:** close the gap between our video-only Gaussian splat and a Scaniverse
capture of the same room. The owner will re-capture; this spec is the "in the
meantime" program plus the longer-term path.

> **Correction (2026-08-08):** the Scaniverse scan was taken with the **same Pixel
> 10 Pro XL** that shot our videos — **not** an iPhone-LiDAR device. The Pixel has
> **no ToF/LiDAR** sensor, so Scaniverse hit its clean 2.46 M-gaussian result from
> the *same camera* using photogrammetry + **ARCore pose tracking + ML/monocular
> depth**. The original framing below ("they have LiDAR, we don't") is therefore
> **wrong**: the gap is **capture quality (Scaniverse's real-time coverage UI) +
> method (ARCore poses + ML depth + a well-tuned trainer)**, all reachable without
> new hardware. Consequences: the **monocular depth prior (§D)** is promoted to the
> top method lever (it approximates what Scaniverse actually does), and the real
> "match Scaniverse" path is the **ARCore capture app (ROADMAP OFFLINE-4)**, not the
> ToF sensor (§E). §A/§B/§D/§E are corrected inline below.

## Problem — quantified

BUG-094 fixed the trainer (broken SSIM / clamp) so the reconstruction is a room and
not a random cloud. But it is still a **"galactic snowglobe"**: the room sits inside
a halo of faint, oversized floaters. A statistical comparison of our 1 M-gaussian
build against the owner's Scaniverse capture (`results/splats/scaniverse-splat/SamOffice.ply`,
2.46 M gaussians) of the same office makes the cause unambiguous:

| metric | Scaniverse | Ours (pre-tuning) |
|---|---|---|
| gaussians | 2.46 M | 1.0 M |
| median gaussian size | **3 mm** | **49 mm** (16×) |
| median opacity | **0.78** | **0.03** |
| fraction opacity < 0.1 | 11 % | **74 %** |
| 95 % within radius | 3.7 | **15.3** |
| solid + small + near | — | **0.9 %** |

Only **0.9 %** of our gaussians are opaque, small, and near the room. The other 99 %
is fog (74 % near-transparent) plus a far-floater halo (24 % beyond 8 units, extremes
to ~10⁶). This is **under-constraint**, not un-pruned junk: photometry-only 3DGS from
a single video has nothing pinning gaussians to real surfaces, so the optimiser is
free to explain the images with translucent haze. Scaniverse avoids this **without
LiDAR** — with **ML/monocular depth + ARCore poses** and aggressive floater pruning
(same Pixel camera as ours; see the correction above).

**Priority order (measured, honest):** depth supervision (ML/monocular now, ToF later)
≫ better capture ≫ pipeline tuning. Tuning cleans up; it cannot manufacture the
geometry depth would. Because Scaniverse reaches its result from the *same camera*,
depth + capture are proven sufficient — no new sensor is required to close most of it.

## A. Tuning + floater cull — SHIPPED (this change)

Cheap wins on the *existing* video, all as `SplatPreset` knobs (fingerprinted):

- **`max_gaussians` 1 M → 2 M** (Scaniverse has 2.46 M; 2 M fits the 8 GB box).
- **`min_opacity` 0.005 → 0.05** — MCMC prunes faint gaussians every refine step, so
  the fog is relocated to useful surfaces during training instead of surviving.
- **`scale_reg` 0.01 → 0.02**, `opacity_reg` 0.01 — smaller, more decisive splats.
- **Post-train floater cull** (`cull_opacity` 0.12, `cull_radius_factor` 3.0): drop
  gaussians fainter than 0.12 or beyond 3× the camera-path radius from the scene
  centre — kills the transparent haze and the galactic halo deterministically.
- **Raise `long_edge` 1600 → ~2000** to use more of a 4K frame's detail (open item,
  measure COLMAP/VRAM cost first).

Acceptance: median opacity ↑ toward ~0.3+, fraction opacity<0.1 ↓ well below 74 %,
95 %-within-radius ↓ toward single digits, and the rendered interior visibly loses the
surrounding snow. This will improve but **not match** Scaniverse — that needs B/D/E.

## B. Capture guidance (owner re-capturing)

The single biggest lever after depth. Recommendations, to be written into a capture
doc / in-app guidance:

- **Main 1× camera, not 0.5× ultrawide.** Ultrawide's barrel distortion is not handled
  by the current pinhole pipeline (see C), and its sensor is softer/lower-res.
- **4K60, not 8K30.** 60 fps halves motion blur (the dominant defect) and gives more
  frames to sample; 8K's resolution is discarded by the `long_edge` downscale anyway.
- **Move slowly, translate (don't rotate in place** — COLMAP needs parallax), ~70–80 %
  overlap, each surface seen from 2–3 directions, even lighting, locked exposure/focus,
  one fixed zoom for the whole take. Last video registered only 161/287 frames, largely
  from blur + fast panning.
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

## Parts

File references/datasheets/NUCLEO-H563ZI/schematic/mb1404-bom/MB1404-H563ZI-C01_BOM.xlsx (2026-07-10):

 |  |  | Bill of materials
 |  |  | Board reference: | MB1404
 |  |  | Variant: | H563ZI
 |  |  | PCB revision: | C
 |  |  | Assembly revision: | 01
 |  |  | Date: | 04/08/2023
Designator | Description | Package | Manufacturer | Manufacturer_Part_Number | Fitted | Quantity
B1, B2 | Push Button, NO, 0.05A, 12V, 2.6N, SMD, 9.0x6.2mm, T=7.3mm, changeable caps KTSC-6xx | 9.0x6.2mm | KNITTER-SWITCH | TSS644S | Fitted | 2
C1, C23 | Capacitor, MLCC, 10uF, 10V, X5R, +/-10%, 0603, T=0.8mm | 0603 | MURATA | GRM188R61A106KE69D | Fitted | 2
C2, C4, C8, C9, C10, C11, C13, C15, C16, C17, C21, C22, C25, C26, C27, C28, C29, C30, C31, C32, C33, C34, C38, C44, C46, C47, C48, C49, C51, C52, C53, C54, C56, C57, C58, C61, C68 | Capacitor, MLCC, 100nF, 16V, X7R, 10%, 0402, T=0.5mm, Capacitor, MLCC, 100nF, 16V, X7R, +/-10%, 0402, T=0.5mm | 0402 | YAGEO | CC0402KRX7R7BB104 | Fitted | 37
C3 | Capacitor, MLCC, 100nF, 25V, X7R, +/-10%, 0402, T=0.5mm | 0402 | WALSIN | 0402B104K250CT | Fitted | 1
C5, C19 | Capacitor, MLCC, 10nF, 50V, X7R, +/-10%, 0402, T=0.5mm | 0402 | YAGEO | CC0402KRX7R9BB103 | Fitted | 2
C6 | Capacitor, MLCC, 100pF, 50V, NPO, +/-5%, 0402, T=0.5mm | 0402 | YAGEO | CC0402JRNPO9BN101 | Fitted | 1
C7, C12, C14 | Capacitor, MLCC, 2.2uF, 6.3V, X5R, +/-10%, 0402, T=0.5mm | 0402 | YAGEO | CC0402KRX5R5BB225 | Fitted | 3
C18, C89 | Capacitor, MLCC, 2.2uF, 25V, X7R, +/-10%, 0805, T=1,25mm | 0805 | MURATA | GRM21BR71E225KE11L | Fitted | 2
C20, C24 | Capacitor, MLCC, 2.7pF, 50V, NPO, +/-0.1pF, 0402, T=0.5mm | 0402 | YAGEO | CC0402BRNPO9BN2R7 | Fitted | 2
C35 | Capacitor, MLCC, 20pF, 50V, NPO, 5%, 0402, T=0,5mm | 0402 | YAGEO | CC0402JRNPO9BN200 | Fitted | 1
C39, C45, C60 | Capacitor, MLCC, 4.7uF, 10V, X5R, +/-20%, 0603, T=0.8mm | 0603 | YAGEO | CC0603MRX5R6BB475 | Fitted | 3
C40, C43 | Capacitor, MLCC, 4.7uF, 16V, X5R, 20%, 0603, T=0,8mm | 0603 | MURATA | GRM188R61C475KE11 | Fitted | 2
C41, C42 | Capacitor, MLCC, 10uF, 25V, X5R, 10%, 0805, T=0,85mm | 0805 | YAGEO | CC0805KRX5R8BB106 | Fitted | 2
C50, C55 | Capacitor, MLCC, 2.2uF, 10V, X5R, 10%, 0603, T=0,8mm | 0603 | YAGEO | CC0603KRX5R6BB225 | Fitted | 2
C59, C66, C69, C74, C79, C80, C81, C83, C84 | Capacitor, MLCC, 100nF, 6V3, X5R, +/-10%, 0603, T=0.8mm | 0603 | KEMET | C0603C104K9PACTU | Fitted | 9
C62, C65, C67 | Capacitor, MLCC, 1uF, 6V3, X5R, 10%, 0603, T=0,8mm | 0603 | YAGEO | CC0603KRX5R5BB105 | Fitted | 3
C70, C71, C76, C78 | Capacitor, MLCC, 5.6pF, 50V, NPO, 5%, 0402, T=0,5mm | 0402 | YAGEO | CC0402BRNPO9BN5R6 | Fitted | 4
C72, C73 | Capacitor, MLCC, 3.3pF, 50V, NPO, +/-0.1pF, 0402, T=0.5mm | 0402 | YAGEO | CC0402BRNPO9BN3R3 | Fitted | 2
C75 | Capacitor, MLCC, 1uF, 6V3, X5R, 10%, 0402, T=0,5mm | 0402 | MURATA | GRM155R61E105KA12 | Fitted | 1
C77 | Capacitor, MLCC, 470pF, 50V, NPO, 5%, 0402, T=0,5mm | 0402 | YAGEO | CC0402JRNPO9BN471 | Fitted | 1
C82 | Capacitor, MLCC, 10µF, 10V, X5R, 10%, 0603, T=0.8mm | 0603 | MURATA | GRM188R61A106KAAL | Fitted | 1
C85 | Capacitor, MLCC, 10pF, 50V, NPO, 5%, 0603, T=0,8mm | 0603 | YAGEO | CC0603JRNPO9BN100 | Fitted | 1
C86, C88 | Capacitor, MLCC, 330pF, 50V, NPO, +/-5%, 0402, T=0,5mm | 0402 | YAGEO | CC0402JRNPO9BN331 | Fitted | 2
C87 | Capacitor,100nF,50V,X7R,10%,0603 | 0603 | YAGEO | CC0603KRX7R9BB104 | Fitted | 1
C91 | Capacitor, MLCC, 1nF, 2KV, X7R, 10%, 1206, T=1,25mm | 1206 | YAGEO | CC1206KKX7RDBB102 | Fitted | 1
CN1, CN13 | Connector_USB_TypeC, 24pins, RA, TH, T=1.9mm (USB certified) |  | WURTH ELEKTRONIK | 632723300011 | Fitted | 2
CN3, CN4, CN15, CN16 | Header, 2x1, 2,54mm, VR, TH, Height 5.84mm/10.16mm |  | SAMTEC | TSW-102-09-G-S | Fitted | 4
CN5 | Header, 10x2, 1.27mm, VR, SMD, T=3.05mm |  | SAMTEC | FTSH-110-01-L-DV | Fitted | 1
CN7 | Socket, 10x2, 2.54mm, VR, TH, T=8.51mm/10mm |  | SAMTEC | SSQ-110-23-F-D | Fitted | 1
CN8 | Socket, 8x2, 2.54mm, VR, TH, T=8.51mm/10mm |  | SAMTEC | SSQ-108-23-F-D | Fitted | 1
CN9 | Socket, 15x2, 2.54mm, VR, TH, T=8.51mm/10mm |  | SAMTEC | SSQ-115-23-F-D | Fitted | 1
CN10 | Socket, 17x2, 2.54mm, VR, TH, T=8.51mm/10mm |  | SAMTEC | SSQ-117-23-F-D | Fitted | 1
CN14 | RJ45 jack, single port, with LEDS, Metal shielded dip low profile |  | DONGGUAN KEYOUDA ELECTRONIC TECHNOLOGY | KRJ-CB4.2GYZNL | Fitted | 1
D1 | Small signal Schottky diodes | SOD523 | STMICROELECTRONICS | BAT54KFILM | Fitted | 1
HW1, HW2, HW3, HW4, HW7, HW8, HW12, HW13 | SHUNT 2.54mm BLACK | 2.54x5.08mm | SAMTEC | SNT-100-BK-G | Fitted | 8
HW9 | Switch hat, blue, For KTSC-62B | 6x6mm | APEM | AKTSC62B | Fitted | 1
HW11 | Black round cap for TSS6x series |  | KNITTER-SWITCH | KTSC-62K | Fitted | 1
JP1, JP3 | Header, 2x1, 2,54mm, VR, TH, Height 5.84mm/2.54mm |  | SAMTEC | TSW-102-07-G-S | Fitted | 2
JP2 | Header, 5x2, 2,54mm, VR, TH, Height 5.84mm/2.54mm - Shunt Fitted 1-2 |  | SAMTEC | TSW-105-07-G-D | Fitted | 1
JP4 | Header, 3x1, 2,54mm, VR, TH, Height 5.84mm/2.54mm - Shunt Fitted 1-2 by default |  | SAMTEC | TSW-103-07-F-S | Fitted | 1
JP5, JP6 | Header, 2x1, 2,54mm, VR, TH, Height 5.84mm/2.54mm - Shunt Fitted by default |  | SAMTEC | TSW-102-07-G-S | Fitted | 2
L1 | Ferrite bead, 600R@100MHz, +/-25%, 500mA, 380mR, 0603, T=0.8mm | 0603 | MURATA | BLM18AG601SN1D | Fitted | 1
LD1, LD5, LD7 | LED Green, 0603 SMD, Forward Voltage Typ=2V, Max=2.5V | 0603 | OSRAM OPTO SEMICONDUCTORS | LG Q396-PS-35 | Fitted | 3
LD2 | LED Yellow, 0603 SMD, Forward Voltage min=1.7V, Typ=2V, Max=2.3V | 0603 | OSRAM OPTO SEMICONDUCTORS | LY Q396-P1Q2-36 | Fitted | 1
LD3 | LED Red, 0603 SMD, Forward Voltage Typ=2V, Max=2.5V | 0603 | OSRAM OPTO SEMICONDUCTORS | LS Q976-NR-1 | Fitted | 1
LD4, LD6 | LED Bicolor, Green/Red, 2V, 20mA, 4-PLCC | 4-PLCC | WURTH ELEKTRONIK | 150141SV73110 | Fitted | 2
Q1 | N-channel 30 V, 6 mΩ typ, 11 A STripFET™ H6, Power MOSFET in a PowerFLAT™ 3.3x3.3 package | PowerFLAT-8 | STMICROELECTRONICS | STL11N3LLH6 | Fitted | 1
Q2, Q3, Q4, T1 | NPN Bipolar Transistor | SOT23 | ON SEMICONDUCTOR | BSR14 | Fitted | 4
R1, R7, R13, R16, R19, R20, R21, R22, R27, R64, R78, R79, R80, R81, R90, R94, R95 | Resistor,100K,0402,1%,1/16W, Resistor, 100K, 0402, +/-1%, 1/16W | 0402 | YAGEO | RC0402FR-07100KL | Fitted | 17
R3, R8 | Resistor, 330R, 0402, +/-1%, 1/16W | 0402 | YAGEO | RC0402FR-07330RL | Fitted | 2
R4, R9 | Resistor, 1K, 0402, +/-0.1%, 1/16W, +/-25ppm/°C | 0402 | YAGEO | RT0402BRD071KL | Fitted | 2
R5, R46, R89, R91, R97, R98, R99, R100 | Resistor, 0R, 0402, +/-5%, 1/16W, Resistor,0R,0402,5%,1/16W | 0402 | YAGEO | RC0402JR-070RL | Fitted | 8
R6 | Resistor,3K,0402,1%,1/16W | 0402 | YAGEO | RC0402FR-073KL | Fitted | 1
R10, R15, R17, R18, R23, R28, R36, R38, R39, R42, R44, R50, R55, R57 | Resistor,10K,0402,1%,1/16W, Resistor, 10K, 0402, +/-1%, 1/16W | 0402 | YAGEO | RC0402FR-0710KL | Fitted | 14
R11, R14, R76 | Resistor, 5K1, 0402, +/-1%, 1/16W | 0402 | YAGEO | RC0402FR-075K1L | Fitted | 3
R12 | Resistor,620R,0603,1%,1/10W | 0603 | YAGEO | RC0603FR-07620RL | Fitted | 1
R24, R25, R58, R59 | Resistor,270R,0402,1%,1/16W | 0402 | YAGEO | RC0402FR-07270RL | Fitted | 4
R26 | Resistor,470R,0402,1%,1/16W | 0402 | YAGEO | RC0402FR-07470RL | Fitted | 1
R29 | Resistor,27K,0402,1%,1/16W | 0402 | YAGEO | RC0402FR-0727KL | Fitted | 1
R30 | Resistor,56K,0402,1%,1/16W | 0402 | YAGEO | RC0402FR-0756KL | Fitted | 1
R31 | Resistor,10K,0603,1%,1/10W | 0603 | YAGEO | RC0603FR-0710KL | Fitted | 1
R32, R33, R34, R35 | Resistor,0R,0603,5%,1/10W | 0603 | YAGEO | RC0603JR-070RL | Fitted | 4
R37, R40, R41, R45 | Resistor,33R,0402,1%,1/16W | 0402 | YAGEO | RC0402FR-0733RL | Fitted | 4
R43 | Resistor,1K5,0402,1%,1/16W | 0402 | YAGEO | RC0402FR-071K5L | Fitted | 1
R47 | Resistor,12K1,0402,1%,1/16W | 0402 | YAGEO | RC0402FR-0712K1L | Fitted | 1
R48 | Resistor,49K9,0603,1% | 0603 | YAGEO | RC0603FR-0749K9L | Fitted | 1
R49 | Resistor,330K,0603,1%,1/10W | 0603 | YAGEO | RC0603FR-07330KL | Fitted | 1
R51, R52 | Resistor,75R,0402,1%,1/16W | 0402 | YAGEO | RC0402FR-0775RL | Fitted | 2
R56 | Resistor, 2K4, 0402, +/-1%, 1/16W | 0402 | YAGEO | RC0402FR-072K4L | Fitted | 1
R60, R68, R69, R70 | Resistor,47K,0603,1%,1/10W | 0603 | YAGEO | RC0603FR-0747KL | Fitted | 4
R61 | Resistor,22K,0603,1%,1/10W | 0603 | YAGEO | RC0603FR-0722KL | Fitted | 1
R62, R65, R66, R67 | Resistor,100K,0603,1%,1/10W | 0603 | YAGEO | RC0603FR-07100KL | Fitted | 4
R63 | Resistor,510R,0603,1%,1/10W | 0603 | YAGEO | RC0603FR-07510RL | Fitted | 1
R71 | Resistor,330R,0603,1%,1/10W | 0603 | YAGEO | RC0603FR-07330RL | Fitted | 1
R72, R73, R74, R75 | Resistor,49R9,0402,1%,1/16W | 0402 | YAGEO | RC0402FR-0749R9L | Fitted | 4
R77 | Resistor, 100R, 0402, +/- 1%, 1/16W | 0402 | YAGEO | RC0402FR-07100RL | Fitted | 1
R82, R83, R84, R92 | Resistor,47R,0402,1%,1/16W | 0402 | YAGEO | RC0402FR-0747RL | Fitted | 4
R96 | Resistor, 1K, 0402, +/-1%,1/16W | 0402 | YAGEO | RC0402FR-071KL | Fitted | 1
SB1, SB2, SB11, SB14, SB16, SB18, SB19, SB24, SB29, SB30, SB32, SB34, SB37, SB39, SB41, SB42, SB43, SB46, SB47, SB49, SB58, SB62, SB69, SB72, SB74 | Solder Bridge ON | 0603 | YAGEO | RC0603JR-070RL | Fitted | 25
SB8, SB9, SB13, SB20, SB26, SB27, SB28, SB31, SB35, SB36, SB38, SB53, SB54, SB55, SB56, SB60, SB61, SB63, SB64, SB68, SB71, SB73, SB75, SB78, SB79, SB80, SB81, SB82, SB83 | Solder Bridge 0402 ON | 0402 | YAGEO | RC0402JR-070RL | Fitted | 29
U1, U10 | 4-bit dual supply translating transceiver with configurable voltage translation; 3-state | DHVQFN-16 | NEXPERIA | 74AVC4TD245BQ,115 | Fitted | 2
U2 | 500mA, Enhanced single channel power switches with active high enable pin |  | STMICROELECTRONICS | STMPS2151STR | Fitted | 1
U3 | Common mode filter with ESD protection for USB 2.0 interface | QFN-6 | STMICROELECTRONICS | ECMF02-2AMX6 | Fitted | 1
U4, U24 | Dual Transil array for ESD protection | SOT323-5 | STMICROELECTRONICS | ESDALC6V1W5 | Fitted | 2
U5, U21, U22, U23 | ESD protection 6V1 | ST0201 | STMICROELECTRONICS | ESDALC6V1-1U2 | Fitted | 4
U6, U20 | High power Transient voltage suppressor:25V/35A EOS and ESD transients protection. | QFN1610 | STMICROELECTRONICS | ESDA25P35-1U1M | Fitted | 2
U7 | MCU, Arm Cortex-M7 32-bit MCU, 512KB Flash, 276KB RAM, With Crypto | BGA-176 | STMICROELECTRONICS | STM32F723IEK6 | Fitted | 1
U9 | LDO, 3.3V, 300mA, High input voltage: 2.5V to 28V, SOT23-5L | SOT23-5 | STMICROELECTRONICS | ST730M33R | Fitted | 1
U11 | LDO, 3.3V, 1.3A, Very low quiescent current BiCMOS voltage regulator | DFN-6 | STMICROELECTRONICS | ST1L05CPU33R | Fitted | 1
U12 | IC REG LDO 5V 0.8A SOT223 | SOT-223 | STMICROELECTRONICS | LD1117S50TR | Fitted | 1
U13 | LDO Linear Voltage Regulator IC Positive Adjustable 1 Output Adjustable 1.3A 6-DFN (3x3) | DFN-6 | STMICROELECTRONICS | ST1L05BPUR | Fitted | 1
U14 | STM32H563ZIT6, LQFP144 package, 20x20 | LQFP-144 | STMICROELECTRONICS | STM32H563ZIT6 | Fitted | 1
U15 | 10/100M RMII Ethernet transceiver | VQFN-24 | MICROCHIP | LAN8742A-CZ-TR | Fitted | 1
U16 | Very low capacitance ESD protection , 4 lines |  | STMICROELECTRONICS | USBLC6-4SC6 | Fitted | 1
U17 | Discrete Magnetic Transformer Module, 16 pins, SMT, 100 Base-TX | 9.4x12.7x5.97mm | DONGGUAN KEYOUDA ELECTRONIC TECHNOLOGY | KMS-1102NL | Fitted | 1
U18 | USB Type-C Port Protection for USB Power Delivery, PPS compliant | QFN-12 | STMICROELECTRONICS | TCPP01-M12 | Fitted | 1
U19 | Very low capacitance ESD protection |  | STMICROELECTRONICS | USBLC6-2SC6 | Fitted | 1
X1 | Crystal, 24MHz, 6pF, +/-20ppm, 80R, 2x1.6mm | 2x1.6mm | NDK | NX2016SA-24MHZ-EXS00A-CS10820 | Fitted | 1
X2 | Crystal, 32.768kHz, 9pF, +/-20ppm, 70KR, 1.6x1mm | 1.6x1mm | NDK | NX1610SE-32.768KHZ-EXS00A-MU01499 | Fitted | 1
X3, X4 | Crystal 25MHz, 6pF, +-20ppm, 80ohms max, SMD | 2x1.6mm | NDK | NX2016SA-25MHZ-EXS00A-CS11321 | Fitted | 2
C36 | Capacitor, MLCC, 10uF, 10V, X5R, +/-10%, 0603, T=0.8mm | 0603 | MURATA | GRM188R61A106KE69D | Not Fitted | 0
C37 | Capacitor, MLCC, 100nF, 25V, X7R, +/-10%, 0402, T=0.5mm | 0402 | WALSIN | 0402B104K250CT | Not Fitted | 0
C63, C64 | Capacitor, MLCC, 100nF, 16V, X7R, 10%, 0402, T=0.5mm | 0402 | YAGEO | CC0402KRX7R7BB104 | Not Fitted | 0
C90, C92 | Capacitor, MLCC, 10nF, 50V ,X7R, +/-10%, 0402, T=0.5mm, Capacitor, MLCC, 10nF, 50V, X7R, +/-10%, 0402, T=0.5mm | 0402 | YAGEO | CC0402KRX7R9BB103 | Not Fitted | 0
CN2 | Header, 4x1, 2,54mm, VR, TH, Height 5.84mm/2.54mm |  | SAMTEC | TSW-104-07-G-S | Not Fitted | 0
CN11, CN12 | Header, 35x2, 2,54mm, VR, TH, Height 5.84mm/2.54mm |  | SAMTEC | TSW-135-07-G-D | Not Fitted | 0
R2 | Resistor, 3K, 0402, +/-1%, 1/16W | 0402 | YAGEO | RC0402FR-073KL | Not Fitted | 0
R53, R54 | Resistor,75R,0402,1%,1/16W | 0402 | YAGEO | RC0402FR-0775RL | Not Fitted | 0
R85 | Resistor, 5K1, 0402, +/-1%, 1/16W | 0402 | YAGEO | RC0402FR-075K1L | Not Fitted | 0
R86 | Resistor, 1K8, 0402, +/-1%, 1/16W | 0402 | YAGEO | RC0402FR-071K8L | Not Fitted | 0
R87 | Resistor, 1K3, 0402, +/-1%, 1/16W | 0402 | YAGEO | RC0402FR-071K3L | Not Fitted | 0
R88 | Resistor, 3K9, 0402, +/-1%, 1/16W, +/-100ppm/°C | 0402 | YAGEO | RC0402FR-073K9L | Not Fitted | 0
R93 | Resistor, 100K, 0402, +/-1%, 1/16W | 0402 | YAGEO | RC0402FR-07100KL | Not Fitted | 0
SB3, SB4, SB10, SB12, SB15, SB17, SB23, SB25, SB40, SB48, SB50, SB51, SB59, SB76, SB77 | Solder Bridge ON | 0603 | YAGEO | RC0603JR-070RL | Not Fitted | 0
SB5, SB6, SB7, SB21, SB22, SB33, SB44, SB45, SB52, SB57, SB65, SB66, SB67, SB70, SB84 | Solder Bridge 0402 ON | 0402 | YAGEO | RC0402JR-070RL | Not Fitted | 0
U8 | eFuse with Fast Overvoltage Protection 2.7V to 18V 4A 34mOhm 8-Pin WSON | WSON-8 | TEXAS INSTRUMENTS | TPS259535DSG | Not Fitted | 0

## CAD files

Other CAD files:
host/tests/fixtures/rtabmap_export_min/session_cloud.ply

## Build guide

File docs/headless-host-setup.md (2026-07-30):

# Headless-host setup — running the web viewer on a GPU-less Linux box

The web viewer (`./view-web.sh`, `roomscan.web`) was developed on Windows with a
GPU and a USB-tethered board. Bringing it up on a **headless Linux host**
(Proxmox/LXC, no GPU, GUI over VNC, board on Ethernet) exposed four gaps that
were all implicit on the dev box. This is the 5-minute checklist so a fresh host
doesn't repeat the multi-hour dig (session 2026-07-15; BUG-020..022 in `BUGS.md`).

## TL;DR

```sh
host/.venv/bin/python host/tools/headless_doctor.py --build   # verify + build the .so
./view-web.sh                                                 # then launch
```

`headless_doctor.py` runs every check below and prints the exact fix for any
failure. Green across the board ⇒ `./view-web.sh` shows live data.

## The four gaps (why each check exists)

1. **Native transform library** — the board streams *raw* frames; the PC runs
   the `vl53l9-transform-c` pipeline through a compiled C lib. It must be built
   (`host/transform/build/libroomscan_transform.so`) and its sources
   (`firmware/vendor/53L9A1`) must be present. The loader is cross-platform as of
   BUG-020 (`.so`/`.dylib`/`.dll`, searches `build/` and `build/Release/`).
   Without it every frame throws and the viewer is silently blank.
   Build: `cmake -S host/transform -B host/transform/build -DCMAKE_BUILD_TYPE=Release && cmake --build host/transform/build`.

2. **Board must be woken continuously** — the firmware unicasts frames to
   whichever host last sent it a datagram and clears that only on reboot.
   `UdpSource` now sends a 1 s keepalive wake so the stream self-heals after a
   board reset / link flap. If data stops, check the board is powered with a live
   Ethernet LINK LED; `avahi-browse -rt _roomscan._udp` should list it live
   (a stale avahi cache can resolve `roomscanner.local` to a dead IP — the
   service browse is the real liveness test).

3. **No CDN at render time** — three.js is vendored under
   `host/src/roomscan/static/vendor/three/`; the import map points local. A
   headless/remote browser that can't reach unpkg would otherwise fail the
   `three` import and the page sits at "Offline" (BUG-021).

4. **Software WebGL** — a GPU-less host has no hardware WebGL, and Chrome refuses
   software WebGL by default, so `new THREE.WebGLRenderer()` throws "Error
   creating WebGL context" (BUG-022). The host *does* have Mesa llvmpipe
   (GL 4.5). `view-web.sh`'s auto-open launches Chrome with
   `--enable-unsafe-swiftshader`; to open manually:
   `google-chrome --enable-unsafe-swiftshader http://localhost:8000/static/index.html`
   (`--use-gl=angle --use-angle=gl` uses llvmpipe instead of SwiftShader).

## Diagnosing "Offline" — read the on-page diagnostic panel

The viewer has a **diagnostic panel (bottom-left)** and an inline error trap that
fires even when a module import fails silently. The trace pinpoints the layer:

| Panel shows | Meaning |
|---|---|
| no `app.js: module loaded` line (+ `window.error`) | a JS module/asset failed to load — the error line names it |
| `Error creating WebGL context` | no WebGL — launch Chrome with `--enable-unsafe-swiftshader` (gap 4) |
| `ws CLOSE code=1006` | websocket can't reach the server (wrong host / firewall / proxy) |
| `ws OPEN` then `ws TEXT frame: …error…` | connected, but the server reader faulted — message says why |
| ends in `first binary frame: N pts` | fully working |

The first panel line (`protocol=… host=…`) tells you *where the browser actually
is* — the most useful clue when the viewing browser isn't on the host itself.

## Environment notes

- **No USB link to this host** — Ethernet/UDP is the only transport here; the USB
  CDC fallback is dead. See the `headless-host-deployment` memory.
- **Running the server as an agent**: use `rig_up()` / `rig_down()` from
  `roomscan-mcp` (`docs/mcp-server.md`), which starts it detached and waits for the
  UI to answer. Verify the browser via `ui_screenshot()`.
  *Stale claim, re-measure before relying on it (2026-07-29):* this bullet used to
  say the agent Bash sandbox kills network-listener processes (uvicorn → exit 144),
  and the `agent-sandbox-port-binding` memory still does. That did **not** reproduce
  — uvicorn bound `0.0.0.0`, served a request and exited 0 from a normal Bash call.
  It may have been accurate when written.

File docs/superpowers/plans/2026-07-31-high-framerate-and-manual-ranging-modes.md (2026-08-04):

# High Frame-Rate Ranging Profiles & Manual Sensor Control — Implementation Plan

> **STATUS (2026-08-04): ✅ COMPLETE — all 12 tasks landed and validated** (Task 12 validation,
> docs status-sync, landing, and milestone-retro done; BUG-079 found by the UI pass and fixed the
> same session). Task 5 hit its
> designed stop point: the sensor's frame floor is intrinsic (measured
> 20.0/21.74/23.53 ms at ≤2/4/8 ms exposure; shorter periods deliver integer multiples), so per this
> plan's own rule the spec was **amended to the measured ceiling** — the High Frame-Rate preset is
> now **46 Hz** (hardware-confirmed 45.86 fps, 0 loss), and every "90 Hz" gate below should be read
> as the amended-ceiling gate (30/46/~50 fps + one oversubscribed request). **Task 6's hardware gate
> ran 2026-08-04 and PASSED, but bridge-measured, not wired** — the plan's release gate below (step 6,
> "wired-Ethernet") was not available and remains outstanding; see the Task 6 section below and the
> handoff doc for the four measured operating points, the zero-drop proof, and the CDC-isolation
> untested-with-reason statement. **Task 7's hardware gate ran 2026-08-04 and PASSED** after fixing
> BUG-077 (an off-cycle IMU/env drain that ran before checking FRAME_READY doubled ToF frame
> intervals under short-margin ranging modes — see the Task 7 section's gate annotation below).
> **Task 8 landed host-only, no hardware gate required.** **The DSS finding, briefly CONTESTED by a
> concurrent investigation, is now RESOLVED — Position A upheld** (our `STANDBY_DSS_MODE` toggle is
> ranging-quality only; ST's 100+ fps mode is unreachable on this hardware/transform path; the 46 Hz
> ceiling stands). Task 12 is unblocked. See
> `docs/superpowers/plans/2026-08-03-high-framerate-implementation-handoff.md` (rev 5) for per-task
> commits, the DSS adjudication, and precise resume instructions. **Task 11 landed 2026-08-04**
> (`rig_profile`/`rig_imu_env_rate`/`profile_estimate`, verified-readback waits, live round trips on
> the rig). **Task 12 is COMPLETE:** full host suite 1895 passed / 1 skipped (expected
> `test_logfilter` skip), `ruff` clean apart from 4 pre-existing `host/tools/` findings unrelated to
> this feature, production raw-only firmware builds clean (166,107 B). **Finding:** step 2's assumed
> build-time onboard-transform knob does not exist as a CMake option — `CONF_TRANSFORM_ONBOARD` is
> an unguarded source `#define`, so a `-D` override is a silent no-op (filed as BUG-078; no blocker,
> the raw-only production build is unaffected). **De-scoped by owner directive (2026-08-04):** the
> wired-Ethernet release gate (step 6) and the CDC-isolation hardware proof (steps 3/4) — *"we will
> never use ethernet or CDC for [a wired] data transfer [link]"*; the Wi-Fi bridge is the production
> transport and its four Task 6 operating points already proved 0 CRC/gaps/drops with ~10x bandwidth
> headroom, so a wired confirmation run would prove nothing new. Live rig sweep + browser visual
> pass: Live rig sweep PASSED (bridge; device restored to boot default): all four presets + manual
> 60/61/90/100 fps behaved correctly — High Frame-Rate 45.4 fps, and over-ceiling manual requests ACK
> but deliver truthful period-multiples (90→44.8, 100→49.2 fps) within ~1.5% of
> `expected_delivered_fps`, 0 CRC; IMU/env decoupled 30/90 Hz apply with the >60 Hz env-sub-sample
> warning; 30 Hz default matches the documented baseline within ±2% (no regression). Browser-UI
> visual pass PASSED for the selector, non-optimistic preset apply, invalid-combo rejection, the
> "ToF bus airtime" bar's color escalation, the >60 fps quantization warning, the IMU/env control,
> and tooltip coverage; two checks were tool-limited (true second tab, narrow-viewport resize).
> **BUG-079 filed + fixed same session** (`controls.js` `manualDirty` guard, live-verified): the
> Manual fps/exposure widgets could not apply a changed value (a 250 ms periodic
> `ranging` re-broadcast outruns the 300 ms UI debounce and reverts the field); presets/IMU-env/
> `set_manual_params`-over-wire are unaffected.

> **Source specification:** `docs/superpowers/specs/2026-07-31-high-framerate-and-manual-ranging-modes.md`
>
> **Required project skills while executing:** `protocol-change` for Tasks 2–3,
> `firmware-loop` for every task marked **[HW]**, `status-sync` before landing, and
> `milestone-retro` after the feature lands.

**Goal:** Ship Room Mapping, Precision, High Frame-Rate, and Manual ranging modes
whose controls reflect the configuration the sensor actually accepted; sustain a
measured 90 Hz full sensor stream over Ethernet; preserve the existing 30 Hz path;
let live SLAM consume high-rate frames without forcing the browser to render at
the acquisition rate; and make the LSM6DSV16X-derived IMU/env streams (9/10/11)
independently pollable at their own configured rate rather than permanently
coupled 1:1 to the ToF trigger.

**Architecture:** Replace the app's implicit dependency on the vendor usecase table
with a scanner-owned profile layer. Profiles are applied atomically at the existing
post-readout/pre-next-frame safe point. Frame-rate-controlled operation uses the
VL53L9CX autonomous synchronization mode; the existing manual-trigger loop cannot
meet the 11.1 ms period because raw readout plus its proven trigger-settle delay
already exceeds that budget. The device protocol moves to v2 because the requested
manual parameter block does not fit v1's fixed `cmd + u32` payload. On the host, one
pure profile-model module owns validation and consequence estimates, while a
server-side profile controller owns COMMAND/ACK state. The reader submits every
transformed frame to the latest-wins SLAM worker; the WebSocket broadcaster remains
a presentation-rate consumer. IMU/env draining moves onto its own service tick,
generalized from the pattern the sensor-idle loop already proves (it free-runs
streams 9/10/11 with a frozen `seq` while parked, with no ToF frame in flight at
all) and reused, not duplicated, by the active acquisition loop; no spare hardware
timer exists for this (TIM3 is already PWM, TIM2 is already the wall clock), so
pacing is a software tick against TIM2 reads, matching the idle loop's own
approach.

## Non-negotiable findings from the current tree

These are implementation constraints, not optional refinements:

1. **`SET_MANUAL_PARAMS` requires protocol v2.** Its fields occupy eight bytes
   (`u8 + u32 + u16 + u8`) in addition to the four-byte command code. Protocol v1
   permits exactly eight payload bytes total. This is a payload-layout change and
   therefore requires a version bump, updated C/Python codecs, and independent
   golden vectors in one commit.
2. **Target FPS is currently inert.** `vl53l9_set_frame_period()` only affects
   autonomous sync, while `vl53l9_app.c` unconditionally reasserts
   `VL53L9_SYNC_MANUAL`. The current loop's 2 ms `HAL_Delay` is about 3 ms wall time;
   combined with the approximately 9.5 ms raw readout, it cannot produce a true
   11.1 ms cadence even before exposure is counted.
3. **The vendor driver always enables DSS.** `vl53l9_set_binning()` writes
   `DSS_SHORT` or `DSS_LONG`; there is no public DSS setter. The scanner must add a
   local extension using the vendor's public register I/O, never edit
   `firmware/vendor/53L9A1/`.
4. **The host transform requires the 14,842-byte 3DMD shape.** A DSS-disabled sensor
   configuration must still supply the fixed-map LUT bytes expected by the existing
   readout and `roomscan.native.Transform`. A hardware/transform equivalence gate
   precedes the 90 Hz work.
5. **High-rate SLAM is presently capped at 30 submissions/s.** `SlamRunner.submit()`
   is called only from `_broadcaster()`, whose `POINT_INTERVAL` is `1/30`. Ingest and
   presentation must be split or the new sensor mode does not improve tracking.
6. **Ethernet pacing assumes a 33 ms frame.** `ETH_TX_WINDOW_MS` is 25 ms and its
   comments/budgets are explicitly 30 Hz assumptions. The full group includes RAW,
   quaternion, environment, raw IMU, and sync frames—not only the 14,842-byte ToF
   payload used by the UI's simple bandwidth estimate.
7. **The spec's numerical models conflict with its preset table.** For example,
   `50 + 5*6*30` is 950 mW, not the stated 200 mW; the ambient range equation gives
   8.5 m at 6 ms, not 8.0 m; and the precision equation gives about 7.9 m at 10 ms,
   not 8.8 m. The UI must not ship contradictory numbers.
8. **The requested 0.5 ms exposure step is not supported by the current driver.**
   `vl53l9_set_exposure()` accepts integer milliseconds. Half-millisecond control is
   not accepted until a local low-level setter is proven on hardware; otherwise the
   contract and UI use a truthful 1 ms step.
9. **Streams 9/10/11 are coupled to the ToF trigger only by convention, not by
   protocol or hardware.** The LSM6DSV16X's SFLP/sensor-hub blocks already free-run
   at their own fixed internal ODR (480 Hz XL/GY+SFLP, 60 Hz sensor-hub cycle)
   independent of when firmware drains them (`rs_lsm.c`); the wire protocol carries
   no frame-grouping structure, and every DATA frame is independently timestamped
   (`docs/protocol.md`); and the sensor-idle loop already proves the decoupled-
   emission pattern end to end — its own free-running tick drains and sends
   9/10/11 with a frozen `seq` and skips stream 13 entirely ("no ToF frame to
   describe"). Decoupling in the *active* streaming loop is new work only because
   that loop currently has no independent wake source — it blocks on the ToF
   FRAME_READY event with no service tick in between — and no spare hardware timer
   exists for one (TIM3 is PWM, TIM2 is the wall clock); pacing must reuse TIM2
   reads against a software-tracked next-due time, following the idle loop's own
   approach rather than a hardware IRQ.

## Global constraints and acceptance gates

- The default becomes **Room Mapping** only after its 30 Hz output is compared with
  the current AR_PRECISION baseline for rate, CRC/gaps, transform success, and depth
  plausibility.
- Binning remains 2 (54×42). Onboard-transform builds remain a golden-vector path
  and reject profiles above 30 Hz at compile time or command validation time.
- Ambient maps to `VL53L9_CONTEXT_LONG`; Precision maps to
  `VL53L9_CONTEXT_SHORT`. DSS is enabled at 60 Hz and below and forced off above
  60 Hz; above 60 Hz is valid only with Precision context.
- Manual FPS is an integer 1–100 and maps to
  `frame_period_us = round(1_000_000 / fps)`. Validation rejects combinations the
  sensor cannot schedule, including exposure/blanking that does not fit the frame
  period. The exact blanking margin is measured in Task 1, not guessed.
- Profile state is server-authoritative and changes only after a successful ACK
  containing device readback. No optimistic client state.
- The high-frame-rate preset remains selectable over CDC because the specification
  asks for a warning rather than a hard ban, but both UI and MCP results must report
  that the transport is unsupported above 60 Hz. Ethernet is the only 90 Hz
  acceptance path.
- The 90 Hz gate is: 60 s on Ethernet with RAW at 90 Hz within ±2%, zero CRC
  failures, zero sequence gaps, zero incomplete UDP frames, zero firmware TX queue
  drops, stream 9/10/13 paired to every RAW frame, and stream-11 samples averaging
  the configured 480 Hz ODR. If this fails, do not label a lower measured rate as
  “90 FPS”; fix the bottleneck or amend the specification with the measured ceiling.
- Power and max-range values remain labelled **estimated**. No measured claim is
  made without a power meter/range target measurement.
- IMU/env poll rate defaults to **coupled** (rate 0 = "one sample per ToF
  trigger," today's behavior, byte-identical framing) so existing captures and
  behavior are a strict subset of the new state space. An explicit nonzero rate
  decouples streams 9/10/11 onto their own tick; stream 13 (IMU_SYNC) is sent only
  on iterations where the drain is actually coincident with a ToF FRAME_READY
  edge, and is silently absent otherwise — never approximated or backfilled.
- Decoupled poll rate is an integer 1–480 Hz (the XL/GY/SFLP ODR ceiling).
  Validation reports, rather than silently drops, the case where a requested rate
  exceeds the 60 Hz sensor-hub cycle: stream 10 (env) sub-samples from the
  requested rate while stream 9 (quat)/11 (raw) can still hit it.
  Decoupled draining must never delay `rs_trigger_next()`/FRAME_READY servicing —
  a decoupled IMU/env rate does not get to steal cycles from the ranging
  profile's own timing budget.
- The IMU/env service tick is shared code between the active-streaming loop and
  the existing sensor-idle loop — one implementation of "drain LSM, emit 9/10/11
  on a frozen `seq`," not two divergent ones.
- `imufusion.py`'s `QUAT_REF_RATE_HZ` and the mapper's `baro_tau_frames` derive
  from the **actually applied IMU/env rate**, not the ToF profile rate, once the
  two are no longer assumed equal.
- Diagnostics that key sensor data by ToF `seq` (`host/tools/skew_check.py`'s
  `collect_frames()`) must handle N:1 — multiple independent IMU/env sends
  sharing one frozen `seq` — without silently dropping samples to
  last-write-wins.

---

### Task 1: Freeze the truthful profile contract and measurement baseline **[HW]**

**Files:**

- Modify: `docs/superpowers/specs/2026-07-31-high-framerate-and-manual-ranging-modes.md`
- Create: `host/src/roomscan/profiles.py`
- Create: `host/tests/test_profiles.py`
- Create: `host/tools/profile_probe.py`
- Modify: `host/src/roomscan/mcp_server/tools_data.py`
- Modify: `host/tests/test_mcp_registry.py`
- Modify: `docs/mcp-server.md`

1. Write failing table-driven tests for all four profile definitions, enum values,
   FPS↔period conversion, DSS/context rules, transport warning threshold, and invalid
   manual combinations. Include boundary cases at 1, 60, 61, 90, and 100 Hz and at
   1 ms and 16 ms exposure.
2. Add a pure `profiles.py` model with `ProfileId`, `RangingMode`, `PowerMode`,
   `ManualParams`, `ProfileConfig`, and `ProfileEstimate`. This module has no device,
   web, or Open3D imports and is the single host-side owner of range/power/bus math.
3. Reconcile the power/range formula conflicts against DS14879 Tables 9 and 36.
   Either correct the coefficients so the equations reproduce the documented anchors,
   or correct the anchors and explain the interpolation domain. Do not special-case
   preset labels over a different manual formula.
4. Resolve exposure granularity by proving whether a 500 µs local setter is possible.
   If not, change the specification and UI contract to a 1 ms step. Record the sensor's
   minimum schedulable blanking margin for each context so validation can reject
   exposure/period combinations before touching hardware.
5. Build `profile_probe.py` as a pure analyzer over a server-owned recording or decoded
   frame timestamps. Report requested FPS, measured median/p05/p95 interval, RAW rate,
   per-stream pairing, CRC/gaps, UDP incomplete/lost/reordered fragments, and stream-11
   effective sample rate. Never bind UDP/CDC directly while `roomscan-web` owns it.
6. Expose the analyzer through a thin MCP wrapper. It will be reused by every hardware
   task below and must report the observed configuration/rates, not the request.
7. Record a 60 s current-firmware baseline before changing sync/DSS. Pin actual RAW and
   sensor stream rates, I3C readout time, transform latency, link bytes/s, and TX queue
   health. This is the non-regression comparator for Tasks 4–6.

**Gate:** The amended spec, model tests, and probe agree on units and anchors. Any
unresolved model coefficient or exposure resolution blocks the consequence UI, but not
the protocol codec work in Task 2.

**Commit:** `test(profiles): pin ranging modes and measurement contract`

---

### Task 2: Protocol v2 codec, typed commands, and golden compatibility

**Files:**

- Modify: `docs/protocol.md`
- Modify: `firmware/scanner-stream/Src/rs_protocol.h`
- Modify: `firmware/scanner-stream/Src/rs_protocol.c`
- Modify: `host/src/roomscan/protocol.py`
- Modify: `host/src/roomscan/decoder.py`
- Modify: `host/tests/make_fixtures.py`
- Modify: `host/tests/test_protocol.py`
- Add/update: `host/tests/fixtures/*.bin`

1. Write failing tests for decoding an existing v1 capture after the host moves to v2,
   emitting ordinary v2 `cmd + u32` commands, emitting/parsing the 12-byte manual
   command payload, exact CRC coverage, partial reads at every byte boundary, garbage
   resynchronization, invalid enum/reserved values, and oversize rejection.
2. Bump `RS_PROTO_VERSION`/host `VERSION` to 2. Keep the 32-byte frame header unchanged;
   host `FrameHeader.unpack()` accepts versions 1 and 2 while new encodes use v2.
   Preserve v1 recording replay as a hard test.
3. Add synchronized registries:

   - command 8: `SET_RANGING_PROFILE`, legacy payload `<II>` (`cmd`, profile enum);
     preset IDs 0–2 apply immediately, while MANUAL (3) reapplies the last accepted
     manual candidate and is rejected until one exists,
   - command 9: `SET_MANUAL_PARAMS`, payload `<IBIHB>` (`cmd`, ranging mode,
     `frame_period_us`, exposure field with the Task-1-approved unit, power mode),
   - command 10: `GET_RANGING_CONFIG`, no parameter, needed to restore authoritative
     state after a web-server restart or a second client attaches,
   - command 11: `SET_IMU_ENV_RATE`, payload `<II>` (`cmd`, `rate_hz`; 0 means
     "coupled to the ToF trigger," the default and today's behavior; 1–480
     decouples streams 9/10/11 onto their own service tick — see Task 7),
   - command 12: `GET_IMU_ENV_RATE`, no parameter, returns applied rate and
     coupled/decoupled state; needed for the same restart/second-client
     restoration as command 10.

4. Make ACK parsing typed rather than a raw three-tuple. Commands 1–8 retain the legacy
   12-byte `<III>` ACK. Commands 9, 10, 11, and 12 return the complete applied/readback
   configuration after `cmd` and `result` (eight bytes for 9/10; four bytes — applied
   `rate_hz` — for 11/12), so the host can prove what the device applied instead of
   echoing the request. Document exact offsets, units, reserved bits, and failure
   semantics.
5. Replace `rs_parse_command(..., cmd, param, token)` with a bounded parsed-command
   struct carrying version, token, command, payload length, and decoded union. Derive
   total length from the validated header instead of one global 44-byte constant. Keep
   the parser HAL-free.
6. Add a host-compiled C parser cross-check driven from pytest: feed Python-generated v2
   vectors to `rs_protocol.c`, compare every decoded field, then feed independently
   generated fixture bytes to Python. Include concatenated 44/48-byte commands and magic
   split across reads.
7. Regenerate fixtures through `make_fixtures.py`, which must continue building bytes
   independently of `protocol.py`. Append the v2 entry to the protocol version history.

**Verification:**

```bash
cd host
.venv/bin/python -m pytest tests/test_protocol.py -q
.venv/bin/python -m pytest tests/test_decoder.py -q
```

**Commit:** One lockstep protocol commit:
`feat(protocol): v2 — ranging profiles and atomic manual parameters`

---

### Task 3: Host command client and CLI support for typed payloads

**Files:**

- Modify: `host/src/roomscan/control.py`
- Modify: `host/tests/test_control.py`
- Modify: `host/pyproject.toml` only if console metadata/help changes

1. Write failing tests for `CommandClient.send_profile()`,
   `send_manual_params()`, and `get_ranging_config()`: token matching, typed readback,
   interleaved DATA/EVENT frames, BUSY/error results, timeout, malformed extended ACK,
   and concurrent callers.
2. Generalize `CommandClient.send()` to accept a packed command payload while retaining
   the existing convenience path for commands 1–8. Preserve its crucial thread contract:
   writes never happen on the reader thread and ACKs are offered by that thread.
3. Extend `roomscan-ctl` with:

   ```text
   profile room_mapping|precision|high_framerate
   manual --ranging ambient|precision --fps N --exposure N --power ulp|lp|regular
   profile-status
   ```

   Print requested and applied/read-back values separately and return nonzero on timeout,
   protocol mismatch, unsupported transport, or device rejection.
4. Keep the old `usecase`, `period`, and `exposure` actions for one release as explicit
   low-level diagnostics; mark them deprecated in help because they are non-atomic and
   `period` is inert under old manual-sync firmware.

**Verification:**

```bash
cd host
.venv/bin/python -m pytest tests/test_control.py tests/test_protocol.py -q
```

**Commit:** `feat(host): add typed ranging profile controls`

---

### Task 4: Scanner-owned profile application, DSS control, and readback **[HW]**

**Files:**

- Create: `firmware/scanner-stream/Src/rs_ranging.h`
- Create: `firmware/scanner-stream/Src/rs_ranging.c`
- Modify: `firmware/scanner-stream/CMakeLists.txt`
- Modify: `firmware/scanner-stream/Src/vl53l9_app.c`
- Modify: `firmware/scanner-stream/Src/rs_protocol.h`
- Modify: `firmware/scanner-stream/Src/rs_protocol.c`

1. Define scanner-owned preset constants matching the amended spec. Do not modify
   `g_ranging_profiles[]` in the vendor tree. Wrap `vl53l9_profile_t` with scanner fields
   for public profile ID and DSS state; keep binning fixed at 2.
2. Add an app-local DSS setter using `vl53l9_write8()` and
   `VL53L9_REGADDR_STANDBY_DSS_MODE(context)`. Apply it immediately after the vendor
   profile helper, because `vl53l9_set_binning()` always rewrites DSS.
3. Read back sync, context, power, frame period, exposure, binning, and DSS while the
   device is in standby. Build ACKs for commands 9/10 from these readbacks; never from
   the requested candidate.
4. Expand `rs_pending_cmd_t` to hold the typed candidate and originating transport. Keep
   one in-flight reconfiguration and return BUSY for a second. Validate all fields before
   stopping the sensor; apply the whole candidate or restore the previous whole profile.
5. Route commands 8/9/10 through the existing post-readout/pre-trigger safe point. ACK
   only after readback matches. A failed restore enters the existing bounded recovery;
   a failed request that restores cleanly returns `SENSOR_ERROR` without adopting the
   candidate.
6. Make Room Mapping the boot default. Reinit, hard-standby wake, soft-standby wake, and
   recovery must all preserve `g_active_profile`, sync mode, and DSS state.
7. Keep the raw buffer at 14,842 bytes when DSS is disabled. On hardware, confirm the
   fixed LUT is still readable and `Transform.process()` accepts the frame. Record one
   matched DSS-on/off static scene and compare transform success, valid-zone count, and
   depth distribution. If the driver returns a shorter/invalid raw frame, stop and solve
   the fixed-map LUT encoding before continuing.
8. Compile both production raw-only and onboard-transform knob configurations. The latter
   rejects high-rate/DSS-off commands rather than entering an unverified transform path.

**Hardware gate:** Commands 8/9/10 work over both CDC and UDP, readback is exact, every
profile survives REINIT and hard standby, and DSS-off raw frames transform without a
size/error regression.

**Commit:** `feat(firmware): apply ranging profiles atomically`

---

### Task 5: Autonomous acquisition loop and real target-FPS behavior **[HW]**

**Files:**

- Modify: `firmware/scanner-stream/Src/vl53l9_app.c`
- Modify: `firmware/scanner-stream/Src/rs_ranging.h`
- Modify: `firmware/scanner-stream/Src/rs_ranging.c`
- Modify: `host/tests/bench_commands.py`

1. Introduce explicit acquisition state (`MANUAL_TRIGGER` only for the legacy
   onboard-transform path; `AUTONOMOUS` for the production profile path). Remove every
   unconditional `VL53L9_SYNC_MANUAL` override from production boot/reinit/apply.
2. In autonomous mode, start the sensor once and consume FRAME_READY → DMA read → ack at
   the configured period. Do not call `rs_trigger_next()` or pay its settle delay.
   Preserve the existing event timestamps, stream grouping, command safe point, standby,
   and bounded recovery semantics.
3. Prove that `vl53l9_stop()` is safe at the post-readout command point in autonomous
   mode. Instrument status/readback through an EVENT or protocol diagnostic because
   ST-Link VCOM may be unavailable on this Linux host. Never rely on an unobservable
   `printf` for the acceptance result.
4. Test upward in controlled steps: 30 → 60 → 90 → 100 Hz, with compatible exposure and
   DSS settings. At each step assert the applied period first, then record 60 s and run
   `profile_probe`; a byte-identical or unchanged-rate result is a failed plumbing check,
   not evidence that period is irrelevant.
5. Size timeouts from the applied frame period with a bounded margin; retain recovery for
   missing FRAME_READY and DMA completion. Ensure changing 90→30 and 30→90 while streaming
   produces one bounded discontinuity, a successful ACK, and stable subsequent cadence.
6. At 90/100 Hz, measure I3C transfer duration and remaining scheduling margin including
   the LSM timestamp latch and FIFO drain. The UI model remains a ToF-airtime estimate,
   while the hardware report states total observed bus work.

**Hardware gate:** Default Room Mapping and Precision each meet 30 Hz without regression;
High Frame-Rate meets the global 90 Hz acceptance gate before transport/UI work calls it
supported.

**Commit:** `feat(firmware): run high-rate profiles in autonomous sync`

---

### Task 6: Ethernet high-rate pacing, queue telemetry, and CDC isolation **[HW]**

> **DONE (2026-08-04), with two caveats — see the handoff doc (rev 3) for the full measured table.**
> Steps 1–5 landed in `5c90da6`/`91a5dfe`/`10966c5`; the hardware gate ran four 60 s operating
> points (30/46/50/90-oversubscribed Hz) with `fw_tx_enqueue_drops`/`fw_tx_stack_stalls` at 0
> throughout (zero-drop gate: PASS). **Caveat 1 — bridge, not wired:** step 6 below asks for
> wired-Ethernet 60/90/100 Hz plus a bridge repeat at 90 Hz; no wired link was available this
> session, so **every** operating point is bridge-measured and the wired release gate below remains
> unsatisfied. **Caveat 2 — step 6's 60/90/100 Hz targets are superseded** by the `91b9eac` ceiling
> amendment (the sensor tops out ~46 Hz; the shipped preset is 46 Hz, not 90/100) — the operating
> points actually run (30 Room Mapping / 46 HFR preset / 50 manual / 90-oversubscribed) supersede the
> plan's original list rather than leaving it unmet. **CDC isolation (step 3/4's on-hardware proof)
> is untested, with reason** — no privileged VCOM access and no USB cable attached to the untethered
> rig; recorded as untested, not passed. BUG-075 (50 Hz/2 ms bimodal cadence) filed from this pass.

**Files:**

- Modify: `firmware/scanner-stream/Src/ethernet_transport.c`
- Modify: `firmware/scanner-stream/Inc/ethernet_transport.h`
- Modify: `firmware/scanner-stream/Src/vl53l9_app.c`
- Modify: `host/src/roomscan/sources.py`
- Modify: `host/src/roomscan/web.py`
- Modify: `host/tests/test_sources.py`
- Modify: `host/tests/test_web.py`

1. Add tests around a pure pacing-budget helper: it derives the drain deadline from the
   active frame period, drains enough fragments at the actual `ETH_Process()` cadence,
   never interleaves frames, never abandons a partial frame, and handles the periodic
   CALIB/IMU_CAL burst.
2. Replace the fixed 25 ms/33 ms assumption with an applied-period-aware deadline. Record
   queue high-water, pending fragments, enqueue drops, stack stalls, and emitted bytes.
   Expose the counters through an existing diagnostic response or a documented additive
   EVENT/ACK field so the hardware gate can prove zero rather than infer it.
3. Define active data transport truthfully. When Ethernet has a target and applied FPS is
   above 60, DATA goes to Ethernet only; an open but non-draining CDC endpoint must not
   inject 100 ms stalls into the Ethernet acquisition path. Control ACKs return to the
   command's originating transport.
4. Preserve automatic CDC fallback when Ethernet has no target. The host surfaces
   `udp`, `cdc`, `replay`, or `none` in authoritative state rather than deriving it in
   browser JavaScript.
5. Extend UDP source metrics with the firmware queue counters and total link rate when
   available. Keep fragment reassembly compatible with reordered datagrams.
6. ~~Run wired-Ethernet 60 s captures at 60, 90, and 100 Hz, then repeat 90 Hz through the
   actual Wi-Fi bridge.~~ **Superseded by the `91b9eac` ceiling amendment** (written before that
   amendment; the sensor tops out ~46 Hz, so 60/90/100 Hz targets are no longer the shipped
   operating points) **and run bridge-only, not wired** (no wired link was available 2026-08-04) —
   actually run: 30 Hz Room Mapping, 46 Hz HFR preset, 50 Hz manual (2 ms), and 90 Hz oversubscribed
   (2 ms), all over the FileHub bridge, all 60 s. The release gate is wired Ethernet; bridge loss is
   reported separately rather than allowed to masquerade as a sensor ceiling — **the wired gate
   itself remains outstanding.**

**Hardware gate:** 90 Hz satisfies the global gate and an attached/open CDC port does not
change Ethernet cadence, gaps, or TX queue health. **Result (2026-08-04): zero-drop gate PASS on
all four bridge-measured operating points (see above); CDC-port-attached comparison untested, with
reason (no VCOM access, no USB cable on the untethered rig).**

**Commit:** `feat(transport): pace full-rate sensor streams over Ethernet`

---

### Task 7: Independent IMU/env poll-rate control **[HW]**

**Files:**

- Modify: `firmware/scanner-stream/Src/vl53l9_app.c`
- Modify: `firmware/scanner-stream/Src/rs_lsm.c`
- Modify: `firmware/scanner-stream/Src/rs_lsm.h`
- Modify: `firmware/scanner-stream/Src/rs_protocol.h`
- Modify: `firmware/scanner-stream/Src/rs_protocol.c`
- Modify: `firmware/scanner-stream/Src/ethernet_transport.c`
- Modify: `host/src/roomscan/control.py`
- Modify: `host/src/roomscan/protocol.py`
- Modify: `host/src/roomscan/profiles.py`
- Modify: `host/tools/skew_check.py`
- Modify: `docs/protocol.md`
- Modify: `host/tests/test_protocol.py`
- Modify: `host/tests/test_control.py`
- Modify: `host/tests/test_profiles.py`
- Create/modify: `host/tests/test_skew_check.py` (add one if none exists)

1. Extract the sensor-idle loop's existing drain/emit logic (`vl53l9_app.c`'s idle
   path, `rs_idle_lsm_tick`) into a shared `rs_lsm_service_tick()` helper in
   `rs_lsm.c`/`rs_lsm.h`, parameterized by coupled-vs-free-running-at-rate-X, used
   by both the idle loop and the new active-loop path below. Preserve idle-loop
   behavior exactly — regression: idle-loop measured rate stays ~18.2 Hz, unchanged.
2. Implement commands 11 (`SET_IMU_ENV_RATE`) and 12 (`GET_IMU_ENV_RATE`) against
   the protocol v2 codec added in Task 2. If Task 2 has already landed without
   them, add them there first as a follow-on lockstep protocol commit under the
   `protocol-change` checklist — golden vectors, host codec, C cross-check, exact
   ACK offsets.
3. In the active acquisition loop, replace the current unconditional per-ToF-frame
   drain with a call into the shared service tick: coupled mode (rate 0, the
   default) keeps today's exact behavior — drain once per ToF frame, stream 13
   always paired. Decoupled mode paces drains off TIM2 against a
   software-tracked next-due timestamp, independent of the FRAME_READY wait,
   sending 9/10/11 with `seq = g_last_seq` (frozen) and skipping stream 13 on
   iterations with no coincident FRAME_READY edge — the same convention the idle
   loop already uses.
4. Validate/report the rate-vs-hub-cycle mismatch: a requested rate above the
   60 Hz sensor-hub cycle sub-samples stream 10 specifically (quat/raw can still
   hit the requested rate); reject requests above 480 Hz (the XL/GY/SFLP ODR
   ceiling).
5. Route commands 11/12 through the existing post-readout/pre-next-frame safe
   point and BUSY/ACK discipline established by Task 4, independent of
   ranging-profile changes — an IMU/env rate change must not require a ToF
   profile reapplication, and vice versa.
6. Update Task 6's Ethernet pacing/queue-budget helper: decoupled IMU/env sends
   add TX load off the ToF cadence, so the budget can no longer be derived solely
   from the applied ToF frame period.
7. Rework `host/tools/skew_check.py`'s `collect_frames()` from a `seq`-keyed dict
   to a `seq`-keyed list (or a time-windowed grouping) so multiple decoupled
   sends sharing one frozen `seq` are all retained instead of last-write-wins
   overwritten. Add a test covering 2+ IMU/env sends between two ToF frames.
8. Extend `host/src/roomscan/control.py`/`roomscan-ctl` with
   `imu-rate <hz|coupled>` and `imu-rate-status`, mirroring the typed-readback
   pattern from Task 3. Extend `profiles.py` with an `imu_env_rate_hz: int | None`
   field (`None`/0 = coupled) so it participates in the same validation/estimate
   model as ranging profiles.
9. On hardware, verify: coupled mode is byte-identical to pre-feature firmware
   (same rate, same stream-13 pairing); decoupled 30 Hz IMU/env holds steady
   while ToF runs Room Mapping, Precision, and High Frame-Rate in turn; decoupled
   90 Hz IMU/env holds steady while ToF runs at its slowest profile; stream 13 is
   present only on genuinely coincident iterations at every combination; and
   draining never delays FRAME_READY servicing (ToF frame timing is unaffected by
   the IMU/env rate in force).

**Hardware gate:** Coupled mode regresses nothing. Decoupled mode holds the
requested IMU/env rate within measured tolerance independent of the concurrent
ToF rate in all combinations above, with zero silently-dropped `skew_check`
samples, stream 13 correctly absent off-edge, and no measurable perturbation of
ToF frame cadence.

> **Gate outcome (2026-08-04): PASSED, after fixing BUG-077 found by this same gate.** Coupled-mode
> regression PASS (29.89 fps, intervals matched Task 6's baseline to 0.01 ms, `n_imu_raw_sends=1`,
> stream 13 every frame). Idle regression PASS (exactly 18.182 Hz IMU/IMUraw/Env with ToF parked).
> Decoupled independence PASS (30 Hz held across Room Mapping/Precision/HFR; 90 Hz landed 85.2 Hz
> with stream 10 sub-sampled to 56.4 Hz, as the readback warns it will). Stream-13 discipline PASS
> (100% coverage at 90/30, ~3 sends per ToF frame, frozen `seq` verified). Cmds 11/12 live with
> truthful readback. BUG-074's wake path sanity-passed via a natural auto-idle cycle (a full
> fault-injection retest is still outstanding). **Item 5 ("no measurable perturbation of ToF frame
> cadence") initially FAILED — filed as BUG-077**: the off-cycle drain ran before checking
> FRAME_READY, and each FIFO word is a blocking I3C transaction on the shared bus, so it doubled ToF
> frame intervals under short-margin ranging modes (Precision/30 +4.91%, HFR/30 +14.94%; Ambient
> unaffected because its longer period absorbs the margin). Fixed by returning on FRAME_READY-first
> with a per-word abortable drain; re-gate: Precision/30 0.09%, HFR/30 0.88%, all within ~0.3 points
> of the coupled controls. Honest residual trade, not fully eliminated: decoupled-90 IMU/env on Room
> Mapping still costs ~9% (85.2 → 77.2 Hz); 30 Hz combos are unaffected. Fix landed in the same
> commit as the feature, `3f4b307`; gate captures `web_20260804_085237.bin`–`090419.bin`.

**Commit:** `feat(firmware): decouple IMU/env poll rate from ToF acquisition cadence`

---

### Task 8: Rate-aware IMU and barometer behavior

**Files:**

- Modify: `host/src/roomscan/imufusion.py`
- Modify: `host/src/roomscan/slam/mapper.py`
- Modify: `host/src/roomscan/slam/worker.py`
- Modify: `host/src/roomscan/slam/remote.py`
- Modify: `host/src/roomscan/slam/service.py`
- Modify: `host/src/roomscan/web.py`
- Modify: `host/tests/test_imu_fusion.py`
- Modify: `host/tests/test_slam_mapper.py`
- Modify: `host/tests/test_slam_service.py`

1. Write tests proving a 30-second barometer time constant is equivalent at 30 and
   90 Hz **applied IMU/env rate** (`900` versus `2700` sample counts), including a live
   rate change that does not reset the map or introduce a correction step, and including
   the case where the applied IMU/env rate differs from the concurrent ToF rate (Task 7).
2. Pass the applied IMU/env poll rate — not the ToF target FPS — with each SLAM
   submission and update the mapper's `baro_tau_frames = round(30.0 * imu_rate_hz)` under
   the worker thread. In coupled mode (Task 7's default) this equals the ToF rate as
   before; in decoupled mode it must track streams 9/10's own rate, sourced from Task 7's
   `GET_IMU_ENV_RATE` readback/applied config, never derived from the ranging profile.
   Carry the same scalar through the remote-worker message so local and service backends
   match.
3. Keep replay truthful: use each stream's own capture timestamp rate when no live
   profile target exists. Never assume the ToF rate for streams 9/10/11, and never assume
   30 Hz for a 90 Hz recording.
4. Do not merely assign `QUAT_REF_RATE_HZ`: it is currently a derivation/comment constant
   and changing it would have zero runtime effect. Make reference rate an explicit
   `ImuFusion` input sourced from the applied/decoupled IMU rate (Task 7), recompute only
   the rate-derived yaw crossover term selected in Task 1, and leave the existing
   timestamp-based propagation/tilt gains in seconds. Tests must show the effective gain
   changes while coupled 30 Hz behavior stays numerically unchanged.
5. On a stationary replay resampled to 30 and 90 reference updates — including a
   decoupled combination where the IMU rate does not match the ToF rate — compare
   orientation noise and phase response in seconds, not frames. Reject a change that
   merely produces a different number without preserving the filter's intended
   time-domain behavior.

**Commit:** `feat(slam): preserve filter time constants across sensor rates`

---

### Task 9: Decouple full-rate SLAM ingest from browser presentation

**Files:**

- Modify: `host/src/roomscan/reader.py`
- Modify: `host/src/roomscan/web.py`
- Modify: `host/src/roomscan/slam/worker.py`
- Modify: `host/src/roomscan/metrics.py`
- Modify: `host/tests/test_viewer_reader.py`
- Modify: `host/tests/test_web.py`
- Modify: `host/tests/test_slam_panel.py`

1. Add a tested optional transformed-frame consumer to `_run_reader()`. It is invoked for
   every transformed RAW frame after statistics update and must remain non-blocking.
2. When live SLAM is active, the consumer snapshots the matching orientation/environment
   state and calls the worker's latest-wins `submit()`. Move submission out of
   `_broadcaster()`; leave `poll()` and MESH/SLAM WebSocket publication there.
3. Keep point-cloud/IR/browser rendering at explicit presentation cadences (30 Hz point
   cloud, 15 Hz IR/sensors unless a measured browser reason changes them). The browser
   should never be asked to render 90 point clouds/s merely because ingest is 90 Hz.
4. Add separate metrics for RAW received, transform completed, SLAM submitted, SLAM
   processed, latest-wins replacements, and browser frames sent. A 90 Hz source with a
   30 Hz browser must report deliberate presentation decimation separately from data or
   SLAM loss.
5. Verify the callback is inert in point-cloud mode, replay pacing remains correct, source
   swaps reset the SLAM worker once, and command writes still never run on the reader
   thread.
6. Benchmark the real CUDA worker at 90 Hz on an idle host. Require p99 processing below
   the 11.1 ms input period and no sustained latest-wins replacements before claiming the
   high-rate preset improves tracking. If compute cannot keep up, report processed rate
   and keep acquisition/render behavior honest.

**Commit:** `refactor(web): separate sensor ingest from render cadence`

---

### Task 10: Authoritative web profile state, controls, and bus visualization

**Files:**

- Modify: `docs/web-protocol.md`
- Modify: `host/src/roomscan/web.py`
- Modify: `host/src/roomscan/control.py`
- Modify: `host/src/roomscan/static/index.html`
- Modify: `host/src/roomscan/static/controls.js`
- Modify: `host/tests/test_web.py`
- Modify: `host/tests/test_static_ui.py`

1. Add a server-owned `RangingState` containing transport, current/applied profile,
   applied manual values, target FPS, measured FPS, consequence estimate, pending token,
   validation warning, and last error. Initialize it through `GET_RANGING_CONFIG`, not an
   assumed firmware default.
2. Add dedicated inbound messages:

   ```json
   {"type":"set_profile","profile":"high_framerate"}
   {"type":"set_manual_params","ranging_mode":"precision","fps":90,
    "exposure_ms":4,"power_mode":"regular"}
   ```

   The server validates through `profiles.py`, dispatches off the event loop, commits
   state only from successful device readback, and broadcasts a `ranging` message plus
   updated `state`. Replay returns an explicit unavailable result.
3. Ensure switching to Manual is one atomic command. Do not send profile, period,
   exposure, and power as four independently applied operations. Preset selection uses
   command 8; manual uses command 9.
4. Replace the old two-button Usecase area with the four-way selector. Add the manual
   ranging/FPS/exposure/power controls, paired range+number inputs, applied/requested
   status, and the consequence readouts. Debounce slider input and allow only one pending
   device command.
5. Render the I3C bar immediately beneath the selector from the server's estimate. Use
   the specified green/yellow/red thresholds and text that says **ToF bus airtime**, not
   total bus use. Include transfer time, frame period, and remaining airtime.
6. Show a prominent CDC warning whenever applied or pending FPS is above 60. Use the
   server-provided transport field; never guess from URL, browser location, or link rate.
7. Preserve one-way state flow: clicks do not set active segments locally. A failed,
   BUSY, or timed-out command leaves the previous applied state visible and announces the
   error. A second tab receives the same state immediately.
8. Add an IMU/env poll-rate control beside the ranging selector: a coupled/auto default
   (matches the ToF profile, today's behavior) plus an explicit Hz field, driven by the
   `set_imu_env_rate`/`RangingState`-analogous state from Task 7's commands 11/12. Show
   applied-vs-requested rate and a visible warning when the requested rate forces stream
   10 (env) sub-sampling above 60 Hz. Same one-way state flow and atomic-command
   discipline as the ranging controls — this is a second, independent pending command,
   not a fifth field bolted onto Manual ranging.
9. Add a `title` to every new control; extend static tests for tooltip coverage,
   duplicate IDs, min/max/step agreement with `profiles.py`, and the Device card's
   reachability. Test the consequence text against known numeric values, not only types.
10. Visually verify at desktop and narrow widths with the headless UI tools. Confirm the
    manual panel and the new IMU/env rate control do not make the Device card exceed its
    dock band; use progressive disclosure rather than deleting readouts.

**Commit:** `feat(web): add ranging modes and live bus consequences`

---

### Task 11: MCP controls and effect-verified automation

**Files:**

- Modify: `host/src/roomscan/mcp_server/tools_rig.py`
- Modify: `host/src/roomscan/mcp_server/tools_data.py`
- Modify: `host/src/roomscan/mcp_server/session.py`
- Modify: `host/tests/test_mcp_tools.py`
- Modify: `host/tests/test_mcp_registry.py`
- Modify: `docs/mcp-server.md`

1. Add `profile_estimate(...)` over the pure model and `rig_profile(...)` for preset,
   manual, and query operations. The latter talks only to roomscan-web; it never binds the
   device stream.
2. Wait until the echoed `ranging.applied` state matches the requested/read-back config.
   A command log line or any newly arrived state message is insufficient proof. Return
   `ok=false` for BUSY, timeout, replay, unsupported CDC rate, validation failure, or an
   applied mismatch.
3. Include requested, applied, estimated, measured FPS, transport, and warning fields in
   the result. Make `rig_status()` include the latest ranging state.
4. Add `rig_imu_env_rate(...)` mirroring `rig_profile(...)`'s verified-readback pattern:
   accepts `coupled` or an explicit Hz value, waits for the echoed applied rate (not a log
   line), and returns `ok=false` for BUSY/timeout/replay/an unreachable rate (above 480 Hz,
   or above 60 Hz with a caller expecting unsampled env). Include it in `rig_status()`
   alongside the ranging state.
5. Test stale broadcasts, timeout after an unchanged state, successful exact readback,
   CDC warning, replay rejection, and two sequential manual changes — for both
   `rig_profile()` and `rig_imu_env_rate()`, independently and interleaved (a profile
   change in flight while an IMU-rate change lands, and vice versa).

**Commit:** `feat(mcp): expose verified ranging profile control`

---

### Task 12: End-to-end validation, documentation, and landing **[HW]**

> **STATUS: IN PROGRESS (2026-08-04).** Host suite 1895 passed / 1 skipped; ruff has 4 pre-existing,
> unrelated `host/tools/` findings. Firmware production raw-only Debug build clean (166,107 B).
> Step 2's assumed onboard-transform build knob does not exist (BUG-078; not a blocker — the
> production build is unaffected). Steps 3/4's wired-Ethernet gate and CDC-isolation proof are
> **de-scoped** by owner directive (2026-08-04, no wired link in production) rather than
> outstanding — see ROADMAP.md's high-frame-rate status block and the handoff doc (rev 5). Still
> genuinely open: BUG-073, BUG-074's fault-injection retest, BUG-075's root cause. Remaining before
> this task can close: the live rig sweep across every listed operating point, and the browser-UI
> visual pass — Live rig sweep PASSED (bridge; device restored to boot default): all four presets +
> manual 60/61/90/100 fps behaved correctly — High Frame-Rate 45.4 fps, and over-ceiling manual
> requests ACK but deliver truthful period-multiples (90→44.8, 100→49.2 fps) within ~1.5% of
> `expected_delivered_fps`, 0 CRC; IMU/env decoupled 30/90 Hz apply with the >60 Hz env-sub-sample
> warning; 30 Hz default matches the documented baseline within ±2% (no regression). Browser-UI
> visual pass PASSED for the selector, non-optimistic preset apply, invalid-combo rejection, the
> "ToF bus airtime" bar's color escalation, the >60 fps quantization warning, the IMU/env control,
> and tooltip coverage; two checks were tool-limited (true second tab, narrow-viewport resize).
> **BUG-079 filed + fixed same session** (`controls.js` `manualDirty` guard, live-verified): the
> Manual fps/exposure widgets could not apply a changed value (a 250 ms periodic
> `ranging` re-broadcast outruns the 300 ms UI debounce and reverts the field); presets/IMU-env/
> `set_manual_params`-over-wire are unaffected. — then `status-sync`, land, and `milestone-retro`.

**Files:**

- Modify: `docs/protocol.md`
- Modify: `docs/web-protocol.md`
- Modify: `docs/mcp-server.md`
- Modify: `ROADMAP.md`
- Modify: `BUGS.md` if validation finds a defect or leaves a measured limitation
- Modify: `CLAUDE.md` only if a durable architecture/status statement changes
- Modify: `.remember/now.md`
- Modify: `.remember/recent.md`
- Modify: canonical memory only for durable measured findings not already owned by docs

1. Run focused suites after their tasks, then the complete host suite:

   ```bash
   cd host
   .venv/bin/python -m pytest -q
   .venv/bin/python -m ruff check src tests
   ```

2. Build both firmware knob configurations. For production:

   ```bash
   export PATH="$PWD/host/.venv/bin:$PATH"
   cd firmware/scanner-stream
   cmake --preset Debug
   cmake --build build/Debug
   ```

3. Use `firmware-loop`/MCP firmware tools to flash and observe over Ethernet. Run the
   Task-1 probe for Room Mapping 30, Precision 30, Manual 1/60/61/90/100 boundaries, and
   High Frame-Rate 90. Exercise profile changes, REINIT, soft standby, hard standby, and
   wake at least once each. Additionally exercise Task 7's IMU/env rate independent of
   ranging profile: coupled (default), decoupled 30 Hz against every ToF profile in turn,
   decoupled 90 Hz against the slowest ToF profile, and the >60 Hz env-sub-sampling case.
4. For each acceptance capture record requested/applied config, measured interval
   percentiles, RAW and sensor rates, CRC, device seq gaps, UDP incomplete/lost/reordered,
   firmware TX drops/high-water, link bytes/s, IMU sample rate (and, for decoupled runs,
   applied vs. measured IMU/env rate independent of the ToF rate, plus stream-13
   presence/absence correctness), transform failures, SLAM submissions/processed/
   replacements, and browser render FPS.
5. Exercise CDC at 60 Hz and request >60 Hz. Verify the warning is visible and returned
   by MCP; do not require a clean 90 Hz CDC stream. Return to Ethernet and prove recovery
   without reboot.
6. Drive the real browser UI: all four profile buttons, invalid manual combinations,
   slider debounce, pending state, successful readback, bus-bar colors at 60/90/100,
   CDC warning, reconnect/new-tab synchronization, narrow layout, tooltips, and the new
   IMU/env rate control (coupled default, an explicit decoupled rate, and the env
   sub-sampling warning above 60 Hz).
7. Re-run the 30 Hz baseline scene/capture and compare rate, transform output, orientation
   health, and SLAM tracking. The new default is accepted only if the intended profile
   difference is documented and no transport/protocol regression appears.
8. Follow `status-sync`: update protocol/web/MCP docs and ROADMAP with actual numbers in
   the same landing commits. Do not retain predicted 90 Hz or power/range numbers where
   measurement corrected them.
9. Land completed work straight to `main` in small verified commits. Keep the Task-2
   protocol artifacts in their single lockstep commit. Do not push unless the owner asks.
10. Run `milestone-retro` before beginning the next milestone; convert any repeated probe,
    pacing, or hardware ritual into the shared skill/MCP surface.

## Recommended execution order and stop points

```text
Task 1 contract/baseline
  -> Task 2 protocol v2
  -> Task 3 host typed control
  -> Task 4 atomic firmware profiles + DSS proof
  -> Task 5 autonomous 30/60/90 hardware gate
  -> Task 6 Ethernet/CDC transport gate
  -> Task 7 independent IMU/env poll-rate control
  -> Task 8 rate-aware filters
  -> Task 9 full-rate SLAM ingest
  -> Task 10 web UI
  -> Task 11 MCP
  -> Task 12 full validation/status sync/retro
```

- Tasks 2–3 may continue while Task 1 resolves estimate coefficients, but the profile
  model/UI cannot ship until Task 1 is closed.
- Stop after Task 4 if DSS-off frames cannot be transformed as 14,842-byte 3DMD.
- Stop after Task 5 if autonomous acquisition cannot sustain the requested cadence; do
  not compensate by relabelling measured FPS or by dropping paired sensor streams.
- Stop after Task 6 if the firmware TX queue or UDP receiver loses frames at 90 Hz. SLAM
  and UI work must be validated against a clean source, not an already lossy stream.
- Stop after Task 7 if decoupled IMU/env draining measurably perturbs ToF frame timing,
  or if the shared service tick cannot reproduce the idle loop's existing ~18.2 Hz
  behavior unchanged. Task 8's rate-aware filters depend on Task 7's applied-rate
  readback and cannot ship against an assumed rate.
- The deprecated `panel.py` is out of scope. Its low-level controls remain for diagnostics,
  but the supported four-mode experience lands in `roomscan-web` and MCP.

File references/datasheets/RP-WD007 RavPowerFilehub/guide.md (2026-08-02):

# RAVPower RP-WD007 FileHub Technical Guide & Reference

This document provides a comprehensive overview of the **RAVPower FileHub RP-WD007**, its underlying hardware/software architecture, CLI interaction techniques over Telnet, and actionable instructions for expanding its functionality (such as operating as an Independent Access Point or querying battery status).

---

## Table of Contents
1. [Device Architecture Overview](#device-architecture-overview)
2. [Key Telnet Commands & Utilities](#key-telnet-commands--utilities)
3. [Mode 1: Transparent Ethernet-to-Wi-Fi Bridge (Current Setup)](#mode-1-transparent-ethernet-to-wi-fi-bridge-current-setup)
4. [Mode 2: Independent Wireless Access Point (Standalone AP Mode)](#mode-2-independent-wireless-access-point-standalone-ap-mode)
5. [Reading Battery & Power Status](#reading-battery--power-status)
6. [Summary of Automation & Scripting](#summary-of-automation--scripting)

---

## 1. Device Architecture Overview

The RAVPower RP-WD007 is built on a MediaTek/Ralink System-on-Chip (SoC) architecture (typically **MT7628**).

### Operating System & Storage
* **Kernel & Userland:** Embedded Linux kernel (2.6.36 generation) using a lightweight BusyBox system environment.
* **Root Filesystem (`/`):** Compressed read-only **SquashFS** filesystem. Any modifications made to system paths like `/etc` or `/sbin` exist in RAM (tmpfs) and **do not survive a reboot**.
* **Storage Mounts:** External SD cards and USB storage devices are auto-mounted under `/data/UsbDisk1/Volume1`, `/data/UsbDisk2/Volume1`, etc.

### Core Daemons & Middleware
* `ioos`: The primary proprietary RAVPower middleware daemon. It manages system events, app APIs, file sharing services (Samba/DLNA), and hardware events (such as Ethernet cable insertion).
* `led_control`: Manages LED status indicators (Power, Wi-Fi, Internet, SD).
* `control`: Secondary daemon monitoring system state and hardware events.
* `fileserv` / `vshttpd`: Serves the web-based management UI and mobile app APIs.

### Network Interface Mapping
* `br0`: The main internal LAN bridge interface (default IP `10.10.10.254`).
* `eth2`: The physical RJ-45 Ethernet port.
* `ra0`: 2.4 GHz Wi-Fi Access Point interface.
* `rai0`: 5 GHz Wi-Fi Access Point interface.
* `apcli0`: Wi-Fi Client interface (used when connecting to an upstream Wi-Fi network/hotspot).

---

## 2. Key Telnet Commands & Utilities

Telnet access is available over port 23.
* **Authentication:** User `root`, Password `20080826` (or `admin` / blank depending on firmware build).
* Once authenticated, Telnet drops into a root shell (`#`). Below are essential commands for inspecting and manipulating the hardware state:

### Network Diagnostics & Bridging
```bash
# Display all network interfaces and assigned IPs
ifconfig -a

# Display active bridge interfaces and attached ports
brctl show

# Add an interface to the LAN bridge (e.g. bridging Wi-Fi client to Ethernet)
brctl addif br0 apcli0

# Remove an interface from the bridge
brctl delif br0 eth2

# Show wireless interface details
iwconfig
```

### Process Control
```bash
# List all running processes (using BusyBox implementation)
busybox ps

# Find Process ID of a specific binary
pidof udhcpd

# Kill daemons or services
killall udhcpd
killall ioos
```

### NVRAM Configuration
MediaTek/Ralink SDKs store device settings in NVRAM.
```bash
# Get NVRAM variable value
nvram_get 2860 OperationMode
nvram_get 2860 lan_ipaddr

# Set NVRAM variable (Note: ioos may overwrite some values on boot)
nvram_set 2860 OperationMode 0
```

*Operation Modes (`OperationMode`):*
* `0`: **Bridge / AP Mode** (`eth2` is LAN, wireless bridged to LAN)
* `1`: **Gateway / Router Mode** (`eth2` is WAN with NAT enabled)
* `2`: **Ethernet Converter Mode**
* `3`: **AP Client / WISP Mode** (`eth2` is LAN, `apcli0` is WAN with NAT enabled)

---

## 3. Mode 1: Transparent Ethernet-to-Wi-Fi Bridge (Current Setup)

In this mode, the RP-WD007 acts as a transparent Layer-2 bridge between its physical Ethernet port (`eth2`) and an upstream Wi-Fi network (`apcli0`).

### The Challenge
When an Ethernet cable is plugged in, the `ioos` daemon automatically executes `/sbin/EnterRouterMode.sh`, which tears down `apcli0` and forces the device into Gateway mode.

### The Solution (Live Workaround)
1. **Blindfold `ioos`:** Create an empty shell script `/tmp/dummy.sh` and bind-mount it over `/sbin/EnterRouterMode.sh` and `/sbin/net_auto_switch`.
2. **Bridge `apcli0`:** Add `apcli0` to `br0` via `brctl addif br0 apcli0`.
3. **Disable Local DHCP:** Kill `udhcpd` so connected Ethernet devices receive DHCP leases directly from the upstream Wi-Fi network (`172.17.2.x`).

---

## 4. Mode 2: Independent Wireless Access Point (Standalone AP Mode)

To operate the RP-WD007 as a standalone, isolated Wi-Fi Access Point (creating its own `10.10.10.x` network with local DHCP server, independent of any upstream WAN):

### CLI Setup Commands for Independent AP Mode
Run the following script over Telnet to enable local AP mode:

```bash
#!/bin/sh

# 1. Blindfold auto-router daemons to prevent unwanted mode switching
echo "#!/bin/sh" > /tmp/dummy.sh
echo "exit 0" >> /tmp/dummy.sh
chmod +x /tmp/dummy.sh
mount --bind /tmp/dummy.sh /sbin/EnterRouterMode.sh
mount --bind /tmp/dummy.sh /sbin/net_auto_switch

# 2. Remove Wi-Fi client from bridge if connected
brctl delif br0 apcli0 2>/dev/null
ifconfig apcli0 down 2>/dev/null

# 3. Ensure physical ethernet is part of the local LAN bridge
brctl addif br0 eth2 2>/dev/null

# 4. Ensure LAN bridge has the static gateway IP
ifconfig br0 10.10.10.254 netmask 255.255.255.0 up

# 5. Start the local DHCP server (udhcpd)
killall udhcpd 2>/dev/null
/usr/sbin/udhcpd /etc/udhcpd.conf &

echo "Independent Access Point Mode Enabled!"
```

### Explanation of Independent AP Mode Logic
* **DHCP Server (`udhcpd`):** Started using `/etc/udhcpd.conf`, which assigns IP addresses in the `10.10.10.100` – `10.10.10.200` range to wireless and ethernet clients.
* **Bridge Topology (`br0`):** Combines `ra0` (2.4G), `rai0` (5G), and `eth2` (Ethernet) under the local IP `10.10.10.254`.

---

## 5. Reading Battery & Power Status

The RP-WD007 SoC reads power and battery state via vendor kernel procfs entries.

### Primary Verified Method: `/proc/vs_battery_quantity` (Recommended)
Tested and verified live on the RP-WD007 hardware:
```bash
cat /proc/vs_battery_quantity
# Outputs integer percentage, e.g. 100
```
* **Kernel Node:** `/proc/vs_battery_quantity`
* **Format:** Plain text integer percentage (0–100).
* **Daemon Usage:** `/usr/sbin/ioos` opens and reads this procfs file directly to monitor device power state.
* **Scraping:** Can be queried over Telnet on demand (e.g. `cat /proc/vs_battery_quantity`).

### Other Related System / Proc Nodes
* `/proc/vs_poweroff_key_status` (returns power key status integer, e.g. `255`)
* `/proc/vs_gpio_power_off`

### Hardware / Web Probing Summary (Firmware Build Notes)
* **`pioctl`:** `/usr/sbin/pioctl` exists on this device but only controls status/Wi-Fi/internet/WPS LEDs, fans, SATA, and USB power toggles. It does not support a `battery` command in this build.
* **`sysfs`:** `/sys/class/power_supply/` is not present in this kernel (2.6.36).
* **Web UI / `fileserv`:** The built-in lighttpd web server (`fileserv`) acts as a static WebDAV and UI file server. Battery status is managed internally by the `ioos` daemon via `/proc/vs_battery_quantity`.

---

## 6. Summary of Automation & Scripting

Because the filesystem is read-only SquashFS, automations (such as `filehub-bridgemode.sh`) should be executed externally over Telnet using `expect` upon boot or on demand.

### Script Summary Table
| Mode / Action | Key Interfaces | Active Services | Command / Script |
| :--- | :--- | :--- | :--- |
| **Transparent Bridge** | `eth2` + `apcli0` in `br0` | `udhcpd` killed, `EnterRouterMode` blindfolded | `filehub-bridgemode.sh` |
| **Independent AP** | `eth2` + `ra0` + `rai0` in `br0` | `udhcpd` running on `10.10.10.254` | Custom AP Telnet script |
| **Battery Check** | `/proc/vs_battery_quantity` | Procfs / `ioos` | `cat /proc/vs_battery_quantity` over Telnet |

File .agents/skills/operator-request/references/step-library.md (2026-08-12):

# Step library — the canonical operator steps

Compose runbooks from these blocks. **Do not reword them.** Copy the block, fill the `<angle
brackets>`, delete what does not apply. The wording is deliberate: every sentence here was written
against the actual UI strings, the actual tool signatures, and a specific way a take has been
ruined before.

Two rules that make a runbook unambiguous:

1. **Every step is tagged `[Claude]` or `[You]`, and they alternate.** The operator must never
   wonder whose turn it is. A `[Claude]` step always ends by telling them to wait.
2. **A `[You]` step is one physical action or one click.** If a step contains "and then", split it.

Renumber the steps consecutively when you assemble them — the numbering below is local to each block.

---

## SETUP blocks

### S1 — Power up the rig

Use when the rig may be off, or at the start of any session after it has been idle.

```
1. [You] Press the power button on the **battery pack** (the RavPower box the scanner is strapped
   to). Its battery lights should come on.
2. [You] Look at the small square **network socket** on the scanner board where the flat cable
   plugs in. There should be a **steady green light** next to it, and usually a second blinking
   one. That means it is talking to the network.
   - **No green light?** The cable is loose, or the battery pack is not in the right mode — go to
     "Fix the bridge" below.
3. [You] Tell me "**powered up**" and wait — I will check whether it has appeared on the network.
```

### S2 — Fix the bridge (the ordering trap)

Use **only** when S1 shows no link, or when I tell you the scanner is not on the network. This is
the single most common first-connection-of-the-day failure.

> **The order matters and cannot be shortcut.** If the network cable is plugged in while the
> battery pack boots, it decides that socket is its *uplink* rather than its *output*, and the
> scanner will never get a connection. Running the repair script on its own does not fix that — the
> pack has to be restarted with the cable out.

```
1. [You] **Unplug** the flat network cable from the battery pack.
2. [You] **Power-cycle the battery pack** — hold its power button until it switches off, wait five
   seconds, switch it back on. Wait until its lights stop changing (about 30 seconds).
3. [You] In the app's top bar, click **Bridge Mode**. (I can also run this for you — say the word.)
4. [You] **Plug the network cable back in.**
5. [You] Tell me "**bridge redone**" and wait — I will check for the scanner on the network.
```

### S3 — Confirm the scanner is on the network

```
1. [Claude] I check that the scanner is reachable and the viewer is running (`rig_status()`, and
   `rig_up()` if it is not). **Wait for me to say ready.**
2. [You] Open <http://localhost:8000/static/index.html> in your browser. (From another machine,
   swap `localhost` for this host's address.)
3. [You] Look at the **top-right corner**. You should see a coloured dot and a set of small
   **status chips**. All chips green, and no "Offline" text, means everything is connected.
   - **Says "Offline"?** Look at the **log strip along the bottom** of the page and read me the
     last line. Do not guess — that line names the actual problem.
```

### S4 — Set the scanner up for this take

Use when the take needs a specific ranging profile or sample rate.

```
1. [Claude] I set the scanner to <profile / rate> and confirm the scanner itself reports it back
   (`rig_profile()` / `rig_imu_env_rate()`). **Wait for me to say ready.**
```

### S5 — Static-scene guard

**Required whenever the scanner will be still, or on a tripod, or pointed at an unchanging scene.**

> **Why this exists.** To spare the laser, the scanner parks it when nothing is moving, and wakes
> it again only on real movement. On a still scene it therefore parks *mid-recording* and the file
> ends up with motion data but no depth — and the automatic file check still calls that file
> "clean". This has silently ruined takes. I turn the power-saving off first.

```
1. [Claude] I disable the automatic laser idle (`rig_idle(auto_idle=False)`) so the laser stays on
   for the whole recording. **Wait for me to say ready.**
```

And at the very end of the runbook:

```
N. [Claude] I turn the automatic laser idle back on (`rig_idle(auto_idle=True)`). **Nothing more
   is needed from you.**
```

---

## RECORDING blocks

### R1 — Start recording

```
1. [You] In the top bar, make sure **Source** is set to **Live**. (The Record card is hidden
   otherwise.)
2. [You] In the right-hand panel, find the card titled **Record** and click the **● Record**
   button once.
3. [You] Check the button turned **red** and now reads **■ Stop**, with a counter underneath it
   like `Rec 0:12 · 4.2 MB` that is climbing. If that counter is not climbing, nothing is being
   recorded — stop and tell me.
```

> If you prefer, I can start and stop the recording for you (`rig_record`) so your hands stay on
> the scanner. Say so and I will drive it; the rest of the steps are unchanged.

### R2 — Stop recording and name the file

```
1. [You] Click **■ Stop**.
2. [You] A box pops up asking you to name the recording. Type exactly:

       <i173-exampleslug>

   then click **Save**. (The `.bin` on the end is added automatically.)
   - If it says the name is taken, add `-2` to the end and save again — then tell me the name you
     actually used.
   - The recording is already safely on disk either way. **Skip** is never a disaster.
```

The name is always `i<issue-number>-<short-slug>`, no spaces or capitals — e.g. `i60-cableflex`.
That is what ties the file to the issue; without it I have to guess which file you meant.

### R3 — Hand back

Always the last `[You]` step.

```
N. [You] Tell me exactly: **done with #<NNN>**
```

---

## MOTION blocks

Pick exactly one, unless the take deliberately has several segments. Each states the pace and
duration because the check I run afterwards (`capture_motion`) scores **what you physically did**,
not just the data — a take with the right length and the wrong motion fails.

### M1 — Walk the loop and come back

```
1. [You] Stand at your starting spot and pick a landmark to remember it by — a specific floor
   tile, a table corner. You must be able to return to **the same spot facing the same way**.
2. [You] Walk your route slowly and steadily, about **one slow pace per second** — much slower
   than normal walking. Keep the scanner roughly level and pointed ahead.
3. [You] Walk the full loop and **return to your exact starting spot, facing the same direction**.
   Stand still there for **ten seconds** before stopping.
   - Returning to the start is the whole point: the check measures how far the map thinks you
     drifted, and that is only meaningful if you really came back.
```

### M2 — Slow pan

```
1. [You] Stand still. Hold the scanner level.
2. [You] Turn on the spot at a steady <slow / medium / brisk> pace — about <N> seconds for a full
   turn — **without stopping**, for the whole <N>-second recording.
3. [You] Keep turning until I tell you the recording has stopped. Pausing partway invalidates it.
```

### M3 — Tilt sweep at one fixed bearing

```
1. [You] Hold the scanner **in your hands, off any tripod or mount.**
2. [You] Pick one thing across the room to point at — a door, a window — and **keep pointing at it
   the whole time**. Do not rotate left or right at any point.
3. [You] Hold the scanner **level** for a slow count of fifteen.
4. [You] Tilt it up to about **45°** — halfway to straight up — and hold for a slow count of
   fifteen.
5. [You] Tilt it to point **straight up** and hold for a slow count of fifteen.
6. [You] Repeat steps 3–5 once more, so you have done two full cycles.
   - Holding still is what makes this work. Sweeping smoothly through the angles gives me nothing
     to measure.
```

### M4 — Free tumble

> **Ordering trap.** The live coverage ball is inside the **Calibrate Mag** window, and that window
> is a full-screen overlay — while it is open the Record button cannot be clicked. So recording
> must be **started first**, and the window **closed again before stopping**. Getting this backwards
> means the operator either cannot start the take or cannot end it. The instrument keeps streaming
> and recording the whole time the window is open.
>
> **Arming trap (added #174).** Opening that window does not begin collecting — `magcal.js:542`
> only calls `setOpen(true)`; the sweep starts on `#magcal-start` (`:547`). Step 3 below is not
> optional padding: without it the ball never fills, the operator has no gap guidance to steer by,
> and **Stop & Fit** never enables. The first version of the #144 runbook omitted it.

```
1. [You] Hold the scanner **in your hands, well away from the tripod, any metal furniture, and
   your laptop.** Metal nearby bends the reading and gets baked in permanently.
2. [You] In the **left-hand panel**, find the **Calibrate Mag** button and click it. A window opens
   showing a ball.
3. [You] In that window, click **Start**. Only now does the ball begin filling in as you cover
   angles — opening the window on its own collects nothing, and the **Stop & Fit** button stays
   greyed out until you have pressed **Start**.
4. [You] Slowly turn the scanner through **every orientation you can** — like slowly rolling a ball
   in your hands. Upside down, on each side, nose up, nose down.
5. [You] Keep going for <N> seconds. **Aim at the gaps the ball shows you** rather than repeating
   a motion you have already done — slow and varied beats fast and repetitive.
6. [You] Close the window with the **×** in its corner (or press **Esc**). You must close it before
   you can stop the recording.
```

### M5 — Stationary with bookends

```
1. [You] Set the scanner down somewhere stable, or hold it as still as you can.
2. [You] Keep it **completely still** for the first ten seconds.
3. [You] <the middle action — e.g. an M-block, or a LIVE block below>
4. [You] Keep it **completely still** for the last ten seconds.
   - Those still stretches at each end are the reference the whole take is measured against.
```

---

## LIVE-OBSERVATION blocks

Use when the thing being measured is **not saved into the file** — the answer only exists on screen
while it runs, so what you write down *is* the deliverable.

### L1 — Watch a number on screen

```
1. [You] Before starting, find **<the named readout>** in the left-hand panel and keep it visible.
2. [You] Note down its value **before** you begin: ______
3. [You] While recording, glance at it every 15 seconds or so. If it **jumps**, note down roughly
   when (e.g. "about 40 seconds in") and the new value.
4. [You] Note down its value at the end: ______
5. [You] Read me the numbers you wrote down when you hand back. **This is the actual result — it
   is not saved in the file, so if you do not write it down it is gone.**
```

### L2 — Physically disturb something mid-recording

```
1. [You] About <halfway> through the recording, <the disturbance — e.g. gently flex the network
   cable back and forth near each end plug for about ten seconds>.
2. [You] Note down roughly **when** you did it: ______
3. [You] Note down whether **anything on screen changed** at that moment: ______
   - Both answers matter, including "nothing changed" — that is a real result, not a failure.
```

---

## HARDWARE blocks

### H1 — Change a jumper or link on the boards

```
1. [You] **Switch the power off** at the battery pack and unplug the network cable.
2. [You] <the exact physical change — board name, silkscreen label, from-position to-position>
3. [You] Take a photo of the changed area and send it to me, so I can confirm it before we power
   back on.
4. [You] Wait — I will check the photo before you power up. Powering up with this wrong can damage
   parts.
```

---

## Do-not blocks

Fold these in as warnings only where they apply.

- **Do not run `capture.py` while the viewer is open.** They both grab the scanner's data stream
  and starve each other. Recording goes through the app (or `rig_record`), always.
- **Do not calibrate the magnetometer on the tripod, or with the laptop close by.** Metal that is
  not bolted to the scanner cannot be calibrated out; it corrupts the fit (BUG-034).
- **Do not change the ranging profile more than once every couple of seconds.** Rapid changes can
  lose the acknowledgement (BUG-073/#84).
- **Do not re-plug the scanner's network cable while a recording is running** unless the runbook
  explicitly asks for it.

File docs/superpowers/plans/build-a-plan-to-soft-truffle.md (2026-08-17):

# Pi 3 bridge node — flashable SD image + MCP remote admin

## Context

Implements `docs/superpowers/specs/2026-08-17-pi3-bridge-node-design.md`: a Raspberry
Pi 3 Model B mounted on the rig replaces the flaky RavPower FileHub as the scanner's
wireless uplink. The FileHub is an unobservable black box with a manual recovery
dance, and is the lead suspect for the measured 2.3–9.4 % silent frame loss.
Deliverables: **(1)** a flashable SD-card image with Wi-Fi credentials baked in,
**(2)** remote administration of the Pi through new `bridge_*` tools in the
roomscan MCP server, **(3)** a local pcap tee so lost-over-Wi-Fi frames are
recoverable after the fact.

**Owner decisions (2026-08-17):** network shape = **routed + NAT** (true L2 is
infeasible — brcmfmac has no 4-addr station bridging; proxy-ARP would leave scanner
DHCP hostage to the Wi-Fi hop); **tee in v1**; hardware = **Pi 3 Model B**.

## Design in one paragraph

Pi eth0 = `172.31.100.1/24` static (NM keyfile), running dnsmasq (DHCP-only,
authoritative — answers inside the scanner firmware's **3000 ms DHCP window**,
after which it flips to self-assigned server at 172.31.253.1, `ethernet_transport.c`
~183–205) with a static lease `00:80:E1:00:00:00 → 172.31.100.20` (MAC is a
compile-time constant, `ethernet_transport.h:7-12`). Pi wlan0 = NM client to
`Surly_Office` / travel AP (both keyfiles baked, autoconnect priorities,
`powersave=2`). Avahi on **wlan0 only** publishes service instance exactly
`roomscanner` / `_roomscan._udp` / port 5000 — so the host's `UdpSource`
(`sources.py:287`, zeroconf lookup of `roomscanner._roomscan._udp.local.`) resolves
the Pi with **zero host-code changes**; nftables DNATs UDP 5000 wlan0→172.31.100.20
and masquerades the return path (1 Hz keepalive keeps conntrack warm).
`allow-interfaces=wlan0` also stops avahi from colliding with the scanner's own
`roomscanner` announcement on eth0. Subnet avoids 172.31.253.0/24 (scanner
fallback), 192.168.50.0/24 (travel AP), 172.17.0.0/16 (home LAN).

**Build is fully rootless** (this LXC has no loop devices / passwordless sudo):
download pinned official Raspberry Pi OS Lite Bookworm armhf, verify sha256, parse
the MBR in pure Python for the FAT partition offset, inject via `mtools`
(`mcopy -i img@@off`): a `firstrun.sh` (Imager mechanism —
`systemd.run=/boot/firmware/firstrun.sh systemd.run_success_action=reboot
systemd.unit=kernel-command-line.target` appended to the single-line cmdline.txt),
a payload tarball, `userconf.txt`, and the `ssh` flag. First boot on the Pi (as
root) extracts the payload to `/opt/roomscan-bridge`, runs idempotent
`install.sh --first-boot` (dpkg -i **bundled .debs** — dnsmasq/tcpdump closure
computed at build time against the base image's dpkg status, read via a partition
slice + `debugfs` — so eth0 side needs no network), enables units, self-cleans
cmdline.txt, reboots. firstrun logs to `/boot/firmware/firstrun.log` (FAT —
readable post-mortem from any laptop).

## New files

```
pi-bridge/
  build_image.py                  # rootless builder; stages: download/verify,
                                  #   mbr-parse, deb-closure, payload-render,
                                  #   inject (mtools), report (--json)
  pi-bridge-secrets.example.yaml  # committed template (real file git-ignored):
                                  #   hostname, wifi.home/.travel {ssid,passphrase,
                                  #   priority}, wifi_country, ssh_pubkey
  boot/firstrun.sh                # template; LF-only enforced by builder
  payload/
    install.sh                    # idempotent; shared by firstrun AND bridge_update
    etc/NetworkManager/system-connections/*.nmconnection.tmpl  # eth0 static + 2 wifi
    etc/NetworkManager/conf.d/roomscan.conf      # wifi.powersave=2 global
    etc/dnsmasq.d/roomscan-bridge.conf           # DHCP-only (port=0), authoritative,
                                                 #   dhcp-host=00:80:E1:00:00:00,172.31.100.20
    etc/nftables: table ip roomscan_bridge       # DNAT 5000, masquerade, counter on
                                                 #   every rule (bridge_status reads them)
    etc/avahi/services/*.service                 # instance `roomscanner` _roomscan._udp:5000
                                                 #   + `roomscan-bridge` _roomscan-bridge._tcp:22
    etc/avahi: allow-interfaces=wlan0            # conflict + LAN-leak prevention
    etc/sysctl.d/: ip_forward=1, rp_filter=2
    etc/systemd/system/: roomscan-bridge-reconcile.{service,timer}, roomscan-tee.service
    usr/local/sbin/roomscan-bridge-reconcile     # bash, travel-ap.sh house style
    usr/local/sbin/roomscan-bridge-status        # bash → JSON (single source for MCP)
host/tools/pi_bridge.py           # pure functions + --json CLI (ssh BatchMode subprocess)
host/tools/pcap2capture.py        # tee pcap → capture .bin + loss stats
host/src/roomscan/mcp_server/tools_bridge.py   # thin @mcp.tool() wrappers
host/tests/test_pi_bridge_build.py
host/tests/test_pcap2capture.py
docs/pi-bridge-runbook.md
```

Plus edits: `server.py::build()` import line; `test_mcp_registry.py` EXPOSED
entries; `docs/mcp-server.md`; `.gitignore` (cache/, out/, secrets, debs/).

## Key behaviors

**Reconcile timer** (10 s, fail-closed, `logger -t roomscan-bridge`): if scanner
absent from lease/neigh, probe fallback mode via temp alias `172.31.253.2/24` +
ping `.253.1`; if found, **first** swap the DNAT target to `.253.1` (stream keeps
working immediately), **then** bounce eth0 link to re-enter the firmware's DHCP
client (verified: link-down resets to `DHCP_STATE_INIT`) — but **only when nft
counters show no active stream traffic**, never mid-capture. Restore DNAT to
`.100.20` when the lease reappears. Also restarts any dead unit (dnsmasq/avahi/
nftables/tee) and logs it.

**Tee** (`roomscan-tee.service`): `tcpdump -i eth0 udp port 5000 -w ring.pcap
-C 100 -W 20` → bounded 2 GB ring (~70 min at the measured ~466 KB/s), `Nice=5`,
`Restart=on-failure`; structurally fail-open (kernel forwards, tcpdump observes;
nothing depends on the unit).

**Wi-Fi cred recovery without reflash**: install.sh also applies any
`wifi-override.nmconnection` found on the FAT partition at every boot (tiny
bootcfg pass) — fixes the bad-creds chicken/egg by editing the card from any
laptop.

**MCP surface** (`tools_bridge.py`; target resolution `ROOMSCAN_BRIDGE_HOST` env →
zeroconf `_roomscan-bridge._tcp`; ssh key `~/.ssh/roomscan-bridge`, generated by
the builder if absent, pubkey baked into authorized_keys; every tool reports what
actually happened, e.g. wifi_update returns resulting association state):

- `bridge_status()` — runs remote `roomscan-bridge-status`, returns its JSON
  (model, wlan0 SSID/RSSI/bitrate/power_save, eth0 carrier + scanner lease/neigh,
  nft counters, tee state + ring usage, temp/throttled, NTP-synced) + ssh-hop
  latency
- `bridge_logs(unit, lines=200)` · `bridge_wifi_update(ssid, psk, profile="home")`
- `bridge_update()` — re-render payload locally, scp, rerun install.sh, report unit states
- `bridge_tee_list()` · `bridge_tee_fetch(name, out="", convert=True)` — scp pcap
  into captures/, run pcap2capture, return loss stats
- `bridge_image_build(profile="production", xz=False)` · `bridge_reboot()`

**pcap2capture.py**: stdlib pcap parser (both endiannesses + ns magic), selects
scanner→host UDP src-port-5000 payloads ≥ 6 B (skips 1-byte keepalives), reassembles
the `<IBB` seq/frag_idx/total_frags fragments with the same indexed-slot rules and
counter names as `UdpSource.read()` (`sources.py:357-399`), writes concatenated
frame bytes — byte-identical to `capture.py`'s `out_f.write(source.read())` format
so all existing `capture_*` tooling consumes it unmodified. `--json` stats are the
acceptance-gate comparison vocabulary (frames_incomplete, frags_lost, …).

## Verification on this host (no Pi needed)

- `test_pi_bridge_build.py`: MBR-parser unit tests; **mini-image round-trip**
  (synthetic MBR + `mformat` 32 MB FAT → run the builder's inject stage → read
  back with `mdir`/`mtype`: single-line cmdline with the 3 args, rendered keyfile
  has the test SSID/PSK, tarball modes correct) — skip-if mtools absent; secrets
  hygiene (refuses example file / 0644 perms; no real psk in git); payload lint
  (units parse, avahi XML instance == `roomscanner`, `bash -n`, no CRLF,
  `nft -c` skip-if); deb-closure resolver against canned Packages/status fixtures.
- `test_pcap2capture.py`: golden synthetic pcaps — clean 11-fragment frame is
  byte-exact, reordered/dropped/duplicate fragment cases hit the right counters,
  output decodes via the existing capture decoder.
- Registry: `test_mcp_registry.py` EXPOSED entries + every tool named in
  docs/mcp-server.md (test-enforced); `tools_bridge` returns structured
  `{"ok": False}` (not raise) with an unreachable host.
- `run_tests` MCP tool for the suite; one-time host prereq: `sudo apt install
  mtools` (user runs it — no passwordless sudo here).

**Hardware acceptance (spec §11) cannot run on this host** → per project law the
governing issue stays open with `needs/operator` + an operator runbook
(operator-request skill): flash + HDMI first boot; discovery parity; side-by-side
FileHub vs Pi loss on the same scene (baseline 2.3–9.4 %); tee beats the Wi-Fi
path; bounded-failure drills (Wi-Fi kill / Pi power-cycle / Pi removal → direct
Ethernet fallback intact); reconcile drill (boot Pi after scanner).

## Process & docs

- **session-start first**: create governing issue "Pi 3 bridge node v1 — image,
  network, tee, MCP admin" (records locked decisions + acceptance checklist;
  ends `needs/operator`), implement as two PR-sized tranches with disjoint files —
  (B) image builder + payload, (C) MCP surface + pcap2capture — then file
  follow-ups (retire filehub-bridgemode.sh + /api/bridge-mode; re-point
  commstatus FileHub semantics; travel-mode plan cross-ref). `travel-ap.sh`
  itself needs **zero changes** (no MAC allowlist).
- status-sync at land: `docs/system-architecture.md` network section,
  `ROADMAP.md` register row, `docs/mcp-server.md`, new `docs/pi-bridge-runbook.md`
  (build → flash → first boot → day-2 via MCP → failure playbook → FileHub
  cold-spare rule: never both plugged in at once — duplicate `roomscanner`
  announcements), spec Status → Accepted.

## Top risks (mitigations designed in)

1. Bookworm firstrun path (`/boot/firmware`, `systemd.run` generator) is the one
   thing only a real first boot proves — hence firstrun.log-on-FAT and the HDMI
   first-boot checklist; fallback mechanism is Bookworm's native `custom.toml`.
2. cmdline.txt is single-line and image-release-specific — builder appends and
   asserts, never rewrites.
3. brcmfmac power save off (per-profile + global), `bridge_status` reports the
   actual `iw get power_save` (truth-telling, not request-echo).
4. No RTC: tee/journal timestamps bogus until NTP sync — reported in
   `bridge_status`, noted in runbook.

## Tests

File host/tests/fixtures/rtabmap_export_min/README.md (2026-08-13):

# rtabmap_export_min

Tiny synthetic golden fixture for `host/tests/test_splat_rtabmap.py` (issue #158). NOT a real
capture -- no phone/room imagery, just small procedurally-generated placeholder images.

Matches the layout `rtabmap-export` (`introlab/rtabmap` @ `2e193ee1`, `tools/Export/main.cpp`)
writes for:

```
rtabmap-export --images --poses_camera --poses_format 1 --output_dir <this dir> <name>.db
```

(the exact command documented in `docs/rtabmap-pixel10-capture.md` section 6), with
`--output` / base name `session`:

- `session_rgb/<stamp>.jpg`, `session_depth/<stamp>.png`, `session_confidence/<stamp>.png` --
  `main.cpp:1610-1649`. `<stamp>` is the literal `%f`-formatted double RTAB-Map's DB stores per
  node (`main.cpp:1516`, `dbDriver->getNodeInfo`), the same value that appears as column 1 of
  `session_camera_poses.txt` -- that shared stamp string is the exporter's own cross-artifact
  identifier (`main.cpp:1808`: `cameraStamps[i][node] = stamp`).
- `session_calib/<stamp>.yaml` -- one file per frame (`main.cpp:1655-1667`,
  `CameraModel::save()`, `corelib/src/CameraModel.cpp:404-434`): plain nested-mapping YAML
  (`camera_name`, `image_width`, `image_height`, `camera_matrix{rows,cols,data}`, optionally
  `distortion_coefficients`/`rectification_matrix`/`projection_matrix`, `local_transform{rows,
  cols,data}`) -- NOT an `!!opencv-matrix`-tagged node, since `CameraModel::save()` builds the
  block manually with `fs << "camera_matrix" << "{" ...`.
- `session_camera_poses.txt` -- `--poses_format 1` (RGBD-SLAM/"motion capture" convention):
  `#timestamp x y z qx qy qz qw` header then one row per node, in ascending node-id order
  (`corelib/src/Graph.cpp:86-99, exportPoses()`). The two rows here use frame-local identity
  quaternions on purpose -- association/loading correctness is what this fixture is for; the
  axis-convention math itself (`rtabmap.rtabmap_format1_pose_to_world_T_camera_optical`) has its
  own direct unit tests against hand-derived identity/translation/90-rotation cases in
  `test_splat_rtabmap.py`, independent of this fixture.
- `session_cloud.ply` -- optional assembled-cloud artifact (`--cloud`, `main.cpp:2490`), a
  4-vertex ASCII PLY square, to exercise "optional geometry present" without importing a real
  mesh.

Two frames intentionally carry two different `camera_matrix` values (`fx=50` vs `fx=52,fy=53`),
mirroring the exporter's stated per-frame-autofocus behavior -- the reader must keep both, never
coalesce them.

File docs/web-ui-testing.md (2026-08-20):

# Visually testing the web UI on the headless host

This box has **no display**, so VNC clicking and any on-screen interaction are
unavailable. Web front-end work is verified by driving headless Chrome (software
WebGL via SwiftShader), screenshotting, and reading the PNGs back.

## Preferred: the `ui_*` MCP tools (2026-07-29)

`roomscan-mcp` (`docs/mcp-server.md`) holds **one browser open across calls**, so
only the first call pays the launch and settle. It supersedes the `web_ui_shot.py`
recipe below for day-to-day work:

```
rig_up(replay="captures/tilt_sweep_20260729.bin", replay_fps=20)
ui_screenshot(renavigate=True, settle=8)     # returns the PNG inline + #log-lines tail
ui_wait_for("parseInt(document.getElementById('pos-status').textContent.match(/\\d+/)[0]) > 50")
ui_eval("document.getElementById('hud-device-fps').textContent")
ui_reset()                                   # between independent scenarios
rig_down()
```

Why prefer it: the screenshot comes back as an image block (no `/tmp` file, no
separate Read), JS goes in as a plain string (no JSON-inside-shell-argument
quoting), and `ui_wait_for` waits on a **real condition** instead of a fixed sleep —
which this doc has always warned is the trap. Backed by Playwright
(`channel="chrome"`), with the raw-CDP path as fallback.

**From a git worktree these tools verify the WRONG CHECKOUT** (2026-08-11, #103).
The MCP server is launched from the session's original cwd (`.mcp.json`), so
`rig_up` serves the **main** checkout's `static/` and `run_tests` cannot see a test
you just added in the worktree (it reports `file or directory not found`). Front-end
work in a worktree can therefore be "verified" against code you did not edit. Start
your own server *from the worktree* and let the `ui_*` tools — which only drive a
browser at a URL — hit it:

```bash
# from <worktree>/, with dangerouslyDisableSandbox (a plain call exits 144)
ROOMSCAN_NO_BROWSER=1 \
ROOMSCAN_TRANSFORM_DLL=<main>/host/transform/build/libroomscan_transform.so \
PYTHONPATH=host/src:host \
  nohup setsid <main>/host/.venv/bin/python -m roomscan.web \
  --replay captures/<something>.bin --replay-fps 20 >/tmp/wt-web.log 2>&1 </dev/null &
```

A fresh worktree also needs `captures -> ../../../captures` and
`host/transform/build -> <main>/host/transform/build` symlinked in, or the library is
empty and 15 tests skip as "native transform DLL not built". Confirm which tree you
are actually serving with `ls -l /proc/<pid>/cwd` — **not** by hashing the served
file, which is identical to main's until your first edit. Run pytest directly:
`cd <worktree>/host && <main>/host/.venv/bin/python -m pytest`.

**`ui_screenshot`'s `width`/`height` now really do resize the viewport** (fixed
2026-08-12, #168, in two rounds). Both session paths — Playwright
(`page.set_viewport_size`) and the raw-CDP fallback
(`Emulation.setDeviceMetricsOverride`) — re-apply the requested size on *every*
call. There were two defects, and the second was **created by the fix for the
first**: an early return once the browser was already up made every call after
the first keep the launch size, so the three narrow sizes below "passed" three
times at 1600x1000; removing that early return then gave teeth to the argless
`self.start()` calls inside `goto`/`evaluate`/`wait_for`/`screenshot`, which
reasserted the 1600x1000 default microseconds *before* the pixels were captured.
`width`/`height` now default to `None`, meaning "keep the last explicitly
requested size", so a future argless caller cannot silently reintroduce this.

The first round was declared verified by driving `CdpSession.start()` directly
and reading back `innerWidth` — which is exactly why it could not see the
regression it had just introduced: `start()` is not the path `ui_screenshot`
takes to a pixel. **Assert through the tool, not through `session.py`.**
Confirmed 2026-08-12 by requesting 1280x800, 1100x560 and 820x700 through
`ui_screenshot` in a *fresh Python process* — the long-lived `roomscan-mcp`
pins the modules it booted with, so verifying a fix to the MCP layer *through*
the MCP layer just runs the old code — and reading back `innerWidth`/
`innerHeight` after each: three exact matches.

Still worth `ui_eval("(() => ({w: innerWidth, h: innerHeight}))()")` between shots
when a result surprises you — a check that cannot fail is what made this invisible
for a week. And to squeeze a sidebar card *without* a viewport change, expanding
the *other* cards in the same dock still works: the card under test drops to its
`min-height` floor, the same constraint a short viewport imposes, reached through
real in-app state.

**`renavigate=True` is a navigation, not a cache bypass** (2026-07-30). Chrome
happily re-served a just-edited `index.html` from its cache across two full
reloads, so a shipped copy change read as "not landed" until a `?cb=` query string
exposed it — a stale read that reports a *successful* load, and one you cannot see
in the pixels. Both browser backends (and `web_ui_shot.py`) now send
`Network.setCacheDisabled` at start, so this should not recur; if you ever suspect
it has, the one-line check is `ui_eval` on the text you just changed, and the
escape hatch is still a `?cb=<anything>` on the URL.

Assertable readouts: `#pos-status` ("frame N / total", replay only — it is empty on
a live server), `#hud-view-fps`, `#hud-device-fps`, `#record-status`, `#ir-frame`,
`#slam-frames`. **`window.__diag` is the page's logging sink *function*, not a state
object** — read what it logged from `ui_screenshot`'s event-log tail.

## Fallback recipe: `host/tools/web_ui_shot.py`

Still correct, and the only option in a client without MCP. It launches and tears
down its own Chrome per invocation.

### 1. Start the server against a replay — DETACHED, sandbox off

The server must be *detached* (`setsid … &`, stdin from `/dev/null`) so it survives
after the launching Bash call returns. Use `ROOMSCAN_NO_BROWSER=1` (nothing to open
here):

> **Stale claim, re-measure before relying on it (2026-07-29):** this doc used to
> say the Bash sandbox kills network listeners (uvicorn → exit 144) and that
> `dangerouslyDisableSandbox` was therefore mandatory. That did **not** reproduce:
> uvicorn bound `0.0.0.0`, served a request and exited 0 from a normal Bash call, as
> did plain listeners on loopback and `0.0.0.0`. It may have been true when written.
> `rig_up()` starts the server detached without needing the flag.

```bash
ROOMSCAN_NO_BROWSER=1 setsid host/.venv/bin/python -m roomscan.web \
    --replay <capture.bin> --replay-fps 20 > /tmp/web.log 2>&1 < /dev/null &
sleep 4
curl -s -o /dev/null -w "%{http_code}\n" http://localhost:8000/static/index.html   # expect 200
```

Bash gotchas that cost time here:
- Run the launch in its **own** Bash call. The shell snapshot runs `set -e`, so a
  leading `pkill -f roomscan.web` that matches nothing exits 1 and aborts the rest
  of a compound command — kill in a separate call.
- Verify liveness with a *separate* `curl` call; don't chain it after the launch.

### 2. Screenshot + drive with `web_ui_shot.py` (sandbox off)

```bash
# default-load shot:
host/.venv/bin/python host/tools/web_ui_shot.py --out /tmp/01-load.png

# drive interactions — one PNG per step; `js` runs in the page, click by element id:
host/.venv/bin/python host/tools/web_ui_shot.py --out /tmp/01-load.png --steps '[
  {"js":"document.getElementById(\"btn-ping\").click()","wait":1.2,"out":"/tmp/02-toast.png"},
  {"js":"document.querySelector(\"#seg-color button[data-mode=depth]\").click()","wait":2,"out":"/tmp/03-depth.png"}
]'
```

Then **Read** each PNG to inspect it. The tool also prints the on-page `#log-lines`
tail — the fastest signal for a load failure (WS never opened, module 404, WebGL
context refused). It manages its own Chrome (launch + teardown); pass `--port` to
reuse an already-running remote-debugging instance instead.

Each step is `{"js": <expr, awaited>, "wait": <seconds>, "out": <png path>}`.
Because control is just JS in the page, you click real bindings (`element.click()`),
so this exercises `controls.js` → `ws.send` → server, not a synthetic shortcut.

**`wait` does not guarantee the replay advanced.** Stepping with `wait` seconds apart
to sample a capture at different points can silently return the *same* frame three
times — the replay may have already ended (it holds the last frame) or be paused,
and nothing in the step result says so (seen 2026-07-29: three shots meant to span a
roll sweep all read an identical `rotate(4.88deg)`). Assert the state you are relying
on inside the `js` — read `#seek`/the transport position, or log the value you are
sampling — rather than inferring progress from elapsed time. A per-step `__diag` line
echoing the quantity under test makes a stalled replay obvious instead of producing
three confidently identical "measurements".
Useful element ids live in `host/src/roomscan/static/index.html` (e.g. `btn-ping`,
`seg-color button[data-mode=…]`, `chk-ir-freeze`, `log-toggle`, the Web-Phase-3
real-time view modes `#seg-view-mode button[data-viewmode=world|fpv|mirror]`
plus their camera framing `sl-cam-distance`/`sl-cam-height`/`sl-cam-rotation`
and `btn-cam-reset` (each edits the *selected* mode's framing) plus the
world-only auto-orbit `chk-orbit`/`sl-orbit-speed`,
the top-bar Record control `#topbar-record`/`btn-record` (Live page only; moved
out of its sidebar card by #118), the floating playback panel
`#playback-panel` (replaced the `#transport-card` sidebar card, #123 — fixed
position over the viewport bottom, replay only) with `btn-golive`,
`btn-playpause`, `btn-transport-restart`
(**not** `btn-restart`, which is the top bar's Restart Server — see BUG-047),
`seg-speed button[data-fps=…]`, `chk-loop`, `seek`, `pos-status`, the §12
View-page capture browser `#browser-card` with `#cap-grid .cap-tile[data-name]`,
its per-tile `input[data-check]`, `#seg-browser-sort button[data-sort=…]`,
`#seg-browser-view button[data-view=…]`, `chk-browser-thumbs`,
`btn-browser-refresh`, `btn-browser-delete` and the confirm modal
`#delete-modal` / `chk-delete-sidecars` / `btn-delete-confirm`, the
selected-capture action drawer `#browser-selected-detail` with
`btn-preview-load`/`btn-preview-rename`/`btn-preview-build` (**not**
`#preview-card`, the standalone card it replaced; and since #103 it sits *before*
`#cap-grid` in the card's fixed chrome — after the self-scrolling grid it was
clipped out of the card and those three buttons were unclickable),
and the
Web-Phase-4 SLAM controls `#seg-mode button[data-mode=realtime|slam]`,
`chk-slam-traj`, `chk-slam-follow`, `#seg-walls button[data-walls=split|solid]`,
`btn-save`, `#saved-list .cap-row a`, and the event-log toggle `log-toggle`
(diagnostics fold into that console now — the old `diag-card`/`diag-toggle` are gone)).

**The Sensors card's numerics live in a collapsed `<details>`.** Since the
2026-07-29 declutter, only the gizmo/compass, the selected orientation readout,
the fusion state and Environment are visible by default; the full-precision raw
ZYX values (`sensor-roll`/`…-quat`), the jitter table (`jitter-<signal>` for p95
and `jitter-<signal>-mean` for mean) and the yaw-offset controls sit inside
`#sensor-diag`. Set `document.getElementById('sensor-diag').open = true` in a
step before shooting or asserting them — they are in the DOM and updating either
way, but a screenshot won't show them. Opened, the drawer is its own scroll box
(the card is capped at the dock band), so `#sensor-diag.scrollTop = 1e4` brings
the jitter table into frame.

**Beware `const` leaking between steps.** Each step's `js` is evaluated in the
same page global scope, so a second step that re-declares `const s = …` throws
`Identifier 's' has already been declared` — and the step's *whole* body then
never runs. The tool prints `JS error in step …`, but the symptom reads exactly
like the app ignoring your click (cost ~20 min on 2026-07-29: three "the mode
select is broken" reproductions were all this). Wrap each step's body in an IIFE
(`(()=>{ … })()`) or use distinct names.

**The magnetometer-calibration modal has one 3D canvas and a 2D fallback, and
both must be shot.** (It had *two* WebGL canvases until 2026-07-31 — a body-fixed
"hero" and a small world-fixed "steering" widget. They are merged: one
`#magcal-hero` canvas, world-fixed framing with the full coverage styling, ghost
included. There is no `#magcal-steer`.) Open it with `sensor-mag-cal`; drive it
with `magcal-start` / `magcal-stop` / `magcal-clear`. `magcal3d.js` publishes a
1 Hz diag line and `window.__magcal3d = {renderer, framing, frames, cells,
covered, ghosted, lastPoseMs, poseHz, behindRecomputes, refreshMs, staticBehind,
reason}` — assert `renderer=="webgl"` and `poseHz≈30` rather than merely that a
canvas exists.

Two fields are new and worth asserting:

- **`framing`** is `"world"` (the merged view) or `"body"` (the no-orientation
  fallback, camera parked on the boresight). Forcing `body` is the only way to
  screenshot the degradation path on a rig that *has* an IMU: load a
  stream-9-less capture, or in a step set the modal's renderer handle's pose
  flags without `POSE_HAVE_QUAT` (bit 3). When it is `body`, `#magcal-hero-note`
  must be visible and saying why.
- **`behindRecomputes` / `refreshMs`** measure the per-frame near/far cell split
  (the merged camera is room-fixed, so which cells are *behind the eye* changes
  as the device turns; it used to be a constant). Attempted at most every 100 ms
  and skipped entirely while the view direction has moved < 1.5°.
  **`?magcalstatic=1` freezes it at the old body-fixed value**, which is how you
  get a same-build baseline — compare `frames` over a fixed wall-clock window
  with and without it.

  Measured 2026-07-31 (llvmpipe, live rig, modal open, 30 s windows):

  | arm | fps | recomputes/s | `refreshMs` |
  |---|---|---|---|
  | `?magcalstatic=1` (frozen) | 5.08 | 0 (1 total) | — |
  | default (per-frame) | 5.87 | 0 (2 total) | — |

  **A stationary rig does not exercise it at all** — that is what the 1.5° gate
  is for, and it is why the fps difference here is only run-to-run noise on this
  box (the "slower" arm measured faster). To get the cost under motion, build an
  isolated instance on a throwaway canvas and pump synthetic poses; `createMagcal3d`
  is exported and takes any canvas. At a **90 °/s tumble**: 2.5 recomputes/s
  (bounded by the render rate, since `updateBehind` runs from `frame()`) at
  **0.062 ms each** — 0.16 ms/s, and **0.062 % of wall clock even at the 10 Hz
  ceiling**. Ignore any `refreshMs` read after only one or two calls: the first
  call is cold and reads ~0.4 ms, 6× the warmed value.

**`?magcal2d=1` forces the 2D Lambert fallback**, so one run
covers both paths; `window.__magcal3d.renderer` reads `"2d"` and
`#magcal-fallback-note` says why. Context loss is reachable from a step:
`document.getElementById('magcal-hero').getContext('webgl2')
.getExtension('WEBGL_lose_context').loseContext()` — it must degrade to the 2D map,
not hang. **Reading the coverage number is the honesty check**: with the board
sitting still on the desk the shell must be almost entirely dashed hollow rings and
the gauge must say so (measured on-rig 2026-07-29: 2 / 92 cells after 600 samples,
plus a `STATIONARY` chip). If it looks flattering while nothing moves, the view is
lying. No capture in `captures/` contains a full tumble — `tilt_sweep_20260729.bin`
is a 1-D tilt and bins into 2 cells — so a *covered* shell shot needs a synthetic
fixture (rewrite a capture's stream-10 mag payloads along a continuous spherical
spiral; `roomscan.protocol.pack_frame` re-encodes the frames unchanged).

**SLAM verification needs a stream-9 capture.** SLAM builds nothing from a capture
with no IMU_QUAT (stream 9) — the mapper gets no rotation prior and loses tracking
(`recordings/2026-07-08-room-scan.bin` predates IMU → empty map). Use
`captures/verify_slam.bin` (has 9/10) or record a fresh one with
**`host/tools/capture.py --udp --seconds 12 --out captures/verify_slam.bin`** (the
headless host has no USB, so `--udp` grabs the Ethernet stream — streams 9/10 in the
decode-report confirm it's SLAM-capable). To
build the map, launch with `--replay <stream9.bin> --replay-fps 30`, click
`#seg-mode button[data-mode=slam]`, and enable Loop (`chk-loop`) so frames keep
feeding — SLAM is fed from the 30 Hz broadcaster only while in SLAM mode, so ~330
frames take ~11 s to integrate. `window.__gotMesh` and the diag line
`slam.js: first mesh: N non-wall verts` confirm the mesh path (the *first* emit is
an empty packet — N=0 — by design; later ones carry geometry).

**Record (and anything else gated on `has_live`) needs a live source, not `--replay`.**
Launching with `--replay` sets `has_live=False`, and `#btn-record` is disabled whenever
`!session.has_live` (`capture.js`) — the standard replay recipe above can't exercise
Record, Go Live, or anything else live-only. On this headless box there's no real
device to plug in, so fake one: monkeypatch `roomscan.web.get_best_source` to return an
object with `.read()/.write()/.close()` that replays a real capture's raw bytes in a
loop (`.read()` returning chunks + a small `time.sleep` to mimic pacing), then call the
**real** `web.main()` so every other app-state field is wired exactly like production
(`client` stays `None` since a `FakeLive` isn't a `SerialSource`/`UdpSource`, so `cmd`
dispatch won't round-trip, but recording/session/captures all work — that's the tee
path, not the command path). Verified 2026-07-29 for the post-recording naming modal:

```python
# /tmp/webtest/launch.py — NOT committed, scratch only
import sys, time
from pathlib import Path
sys.path.insert(0, "/path/to/roomscanner/host/src")
import roomscan.web as web

RAW = Path("/tmp/webtest/src.bin").read_bytes()   # any real capture, e.g. captures/verify_slam.bin

class FakeLive:
    def __init__(self, data): self.data, self.pos = data, 0
    def read(self):
        time.sleep(0.03)
        chunk = self.data[self.pos:self.pos + 4096]
        self.pos = (self.pos + 4096) % len(self.data) if self.pos + 4096 < len(self.data) else 0
        return chunk or self.data[:4096]
    def write(self, d): pass
    def close(self): pass

web.get_best_source = lambda *a, **kw: FakeLive(RAW)
sys.argv = ["roomscan-web"]
sys.exit(web.main())
```

Run it exactly like the normal recipe (`setsid …/python /tmp/webtest/launch.py`, sandbox
off, from a scratch cwd so `captures/`/`results/` land in `/tmp/webtest/` and never touch
the repo's `host/captures/`). Click `#btn-record` to start/stop from a step same as any
other button — the disabled check only reads `session.has_live`, which is now `True`.
Teardown: `kill -9` the pid (not `pkill -f roomscan.web` — the process is literally
running `launch.py`, that pattern won't match) and `rm -rf` the scratch dir.

## The dock layout (why nothing overlaps)

Every floating block lives in one of two **docks** — `#left-dock` (telemetry HUD,
sensors, SLAM HUD, IR monitor, diagnostics) and `#right-rail` (one card per
control group). A dock is a height-bounded **column-wrapping** flex container
spanning the band between the top bar and the event-log console, so a stack that
would run past the bottom of that band spills into a **new column** instead of
overflowing onto whatever is below. `layout.js` (a *classic* script, so it keeps
working when the ES module graph fails) keeps the band in sync with the measured
top-bar/console heights and resolves the one collision CSS can't see — the left
dock's columns marching into the right dock's — by degrading in order:

1. collapse Diagnostics → 2. scroll the right dock (one column) →
3. collapse the IR monitor body → 4. collapse the sensors body.

Consequences when adding UI: **put a new block inside a dock** (as a `.card`
child) rather than giving it its own `position: fixed` corner — a fixed block is
outside the layout and *will* overlap something at some viewport size. Give it an
explicit `width`, and mark any hideable body `.card-body` so the collapse
degradation can reach it.

Regression check — assert zero overlaps at whatever size you're testing (paste as
a `--steps` `js`; it reports through `__diag`, which the tool prints):

```js
(function(){function c(r,d){return {left:Math.max(r.left,d.left),right:Math.min(r.right,d.right),
top:Math.max(r.top,d.top),bottom:Math.min(r.bottom,d.bottom)}}var b=[];
['left-dock','right-rail'].forEach(function(id){var e=document.getElementById(id);if(!e)return;
var dr=e.getBoundingClientRect();[].slice.call(e.children).forEach(function(k){var r=c(k.getBoundingClientRect(),dr);
if(r.right-r.left>1&&r.bottom-r.top>1)b.push({n:k.id||k.className,r:r})})});
['topbar','log-console'].forEach(function(id){var e=document.getElementById(id);if(e)b.push({n:id,r:e.getBoundingClientRect()})});
var bad=[];for(var i=0;i<b.length;i++)for(var j=i+1;j<b.length;j++){var a=b[i].r,d=b[j].r;
if(Math.min(a.right,d.right)-Math.max(a.left,d.left)>1&&Math.min(a.bottom,d.bottom)-Math.max(a.top,d.top)>1)
bad.push(b[i].n+' X '+b[j].n)}window.__diag('OVERLAP '+innerWidth+'x'+innerHeight+' n='+b.length+
' overlaps='+bad.length+(bad.length?' :: '+bad.join(' | '):''));return bad.length})()
```

Verified 0 overlaps at 1600×1000, 1280×800, 1100×560 and 820×700, with the SLAM
cards shown and the event log expanded to its 28vh maximum.

## The diagnostics feed

`window.__diag` no longer has its own pane (removed 2026-08-05). It writes
**straight into the bottom event-log console** (`#log-lines`), as `diag` rows
(cyan) or `error` rows (red), alongside device `event`/`cmd`/`log` lines — one
place for both client-side faults and device events. It writes to `#log-lines`
directly (a plain DOM append, no ES module), so it stays visible even when the
modules fail to load — the exact case the sink exists for. `ui_screenshot` /
`web_ui_shot.py` print the `#log-lines` tail (was `#diag-log`).

The console is **collapsed by default** and **opens itself on the first error**
so a silent module/import failure is still visible without devtools; clicking its
header persists the choice in `localStorage['roomscan.card.log.collapsed']`, and
an explicit choice wins over the auto-open. To force it open in a driven run:
`document.getElementById('log-console').classList.remove('collapsed')`.

Driving gotchas (cost time in Web Phase 3):
- **Wait for server-rendered lists before clicking them.** Tiles built from a
  `captures`/`session` message (the capture browser, any server-driven list) don't
  exist until that message arrives (~0.5–1.5 s after `list_captures`/connect). A step
  that does `[...cap-tile].find(r=>r.dataset.name===X).click()` too soon calls `.click()`
  on `undefined` and the step throws — the action never fires and you debug a phantom.
- **The browser and preview cards only exist on the View page.** They carry
  `.hidden` until a `state` echo says `source === "view"`, so a screenshot taken
  on Live shows neither. Send `{"type":"set_source","source":"view"}` (or use
  `rig_view(source="view")`) and let the echo land before asserting on them.
  Give the prior step ≥1.5 s `wait`, or first emit the rendered rows via
  `window.__diag(...)` and confirm the target is present.
- **Don't interleave exploratory clicks across `web_ui_shot.py` runs.** Each run is a
  fresh browser but the **server state persists** (current source, pacer paused/loop).
  Ad-hoc clicking across runs leaves the server in a confusing mid-state that reads like
  a bug; drive a **clean, disciplined step sequence in one run**, and restart the server
  (`pkill -9 -f roomscan.web`) before a fresh scenario.
- **Closures hide module state.** To inspect what a module actually received (e.g. the
  last `session`), temporarily stash it on `window` inside the hub handler and read it via
  `__diag`; remove the hook before committing.
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

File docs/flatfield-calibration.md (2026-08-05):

# Flat-field (fixed-pattern) calibration

The VL53L9 is a multi-zone SPAD imager, so every zone has a slightly different
response. On a uniform surface this shows up as a **stable, sensor-locked ripple
in the reflectance plane** — fixed-pattern noise (FPN). On a flat wall it measured
at **~18 % of signal**, rock-stable frame-to-frame (SNR ~9), aligned to the sensor
row/column axes (investigation 2026-07-16). It is *not* display resampling and
*not* scene texture. Uncorrected, it contaminates the IR view, reflectance-based
SLAM coloring, and any reflectance-derived enhancement (multi-frame super-res /
relief shading would bake in and amplify the grid).

Flat-field calibration measures that per-zone response once and divides it out.

## Model

A multiplicative **per-zone gain map** `gain[H,W]` (unit-mean). Correction is
`reflectance *= gain`, applied to the reflectance plane inside
`pipeline.TransformStage`, so **every** consumer — web, panel, viewer, SLAM —
sees corrected reflectance with no per-consumer wiring. Depth FPN (a per-zone
*range* offset) and confidence are separate calibrations; the map format is
per-plane-extensible but v1 ships reflectance only.

Code: `roomscan.flatfield` (`FlatField`, `build_flatfield`). Disabled by default
— with no map configured, `FlatField.load_configured()` returns `None` and the
pipeline is a no-op.

## Capturing a flat-field reference (REQUIRED: pan the sensor)

The one rule that makes the calibration valid: **slowly pan/sweep the sensor
across a uniform matte surface while recording.** Panning smears real surface
texture across zones so it averages toward the smooth illumination, leaving only
the sensor's fixed per-zone response. A **static** capture is invalid — it bakes
scene texture into the "correction" (a static recording of a plain wall still
produced a 44 % residual and a 0.25–2.2 gain spread: garbage, not a calibration).

A blank painted wall, foam board, or a grey card works. Keep it roughly
fronto-parallel, fill the frame, avoid specular hot-spots and the no-return
regime (get close enough that all zones return signal).

## Build and enable

```sh
cd host
# 1. record ~15-20 s while slowly panning across the uniform surface
python -m tools.capture --seconds 20 --out flatfield_pan.bin
# 2. build the correction map
python -m tools.build_flatfield flatfield_pan.bin --out flatfield.npz
# 3. enable it: add to roomscan.toml ([calibration] table)
#      flatfield_path = "flatfield.npz"
```

The builder prints the measured FPN residual and the gain spread. Sanity checks
for a *good* capture: residual in the low tens of percent at most, gain
comfortably inside `[0.5, 1.6]`, and **>= ~100 panned frames**. A high residual
or a gain spread near the `[0.33, 3.0]` clip bounds means the capture wasn't a
clean pan — recapture.

## Mode-aware maps (Precision vs Ambient) — the recommended setup

The 2026-08-04 cross-room study (`calibration/flatfield/2026-08-04/`) proved the
FPN is **mode-family-specific**: a Precision map leaves ~4% residual on Ambient
and vice versa, so the two ranging modes need **separate maps**, selected
automatically by the device's current ranging mode. Configure them per family:

These are **host/sensor calibration**, so they live in a `[calibration]` table
(not `[viewer]` display prefs), on the host that owns the sensor:

```toml
[calibration]
flatfield_precision_path = "flatfield_precision.npz"   # used in Precision ranging mode
flatfield_ambient_path   = "flatfield_ambient.npz"     # used in Ambient ranging mode
flatfield_path           = "flatfield.npz"             # optional legacy fallback for an
                                                       # unmatched mode (e.g. replay)
flatfield_enabled        = true                        # the "Calibrated" toggle default
```

`FlatFieldSet.load_configured` reads these; `web.py` points the live `TransformStage`
at the map for the current ranging mode via `stage.set_ranging_mode`, driven from the
device's `GET_RANGING_CONFIG` ACK (`_commit_ranging_ack`). The web **Device card →
Reflectance Calibration** toggle flips `flatfield_enabled` at runtime — **host-shared
server state, saved once on the host, not per client** — and is disabled with a note
when no map path is configured. (A legacy `[viewer] flatfield_path` is still read for
back-compat.) Cross-room-validated residual:
**~2.4% Ambient / ~3.0% Precision** (from ~5.8% / ~6.2% raw). A replay has no device
ranging mode, so it falls back to `flatfield_path` (or no correction if unset).

## Verifying it worked

Point the sensor at the flat wall again with correction enabled: the fixed grid
should collapse into near-uniform reflectance. The definitive live test is the
one that identified the FPN in the first place — **pan across the wall**: the
grid sits still (locked to zones) while the wall slides underneath, and with a
correct map it disappears.

## Files

- `host/src/roomscan/flatfield.py` — `FlatField` (apply/save/load/`load_configured`) + `build_flatfield` + `FlatFieldSet` (mode-aware registry, `load_configured`/`for_mode`)
- `host/tools/build_flatfield.py` — CLI: capture `.bin` → `.npz` map
- `host/src/roomscan/pipeline.py` — `TransformStage(..., flatfield=…, flatfield_enabled=…)` applies the mode-selected map to reflectance (`set_ranging_mode`, `has_flatfield`)
- `host/src/roomscan/config.py` — `[viewer] flatfield_path` / `flatfield_precision_path` / `flatfield_ambient_path` / `calibrated`
- `host/src/roomscan/web.py` — Device-card **Calibrated/Uncalibrated** toggle (`set_calibrated`), ranging-mode → stage wiring (`_commit_ranging_ack`)
- `host/tests/test_flatfield.py` — synthetic-FPN recovery, apply/save/load, config, DLL-gated pipeline integration

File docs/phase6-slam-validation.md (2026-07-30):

# Phase 6 SLAM — offline validation on the real motion capture

> *(Historical validation record, pre-GPU: all timings below are CPU-only. Performance has since been
> superseded by the local-CUDA:0 path — RTX 2000 Ada on the headless host, ~7 ms/frame (see `ROADMAP.md`
> Phase 6 / Web Phase 4). The trajectory-quality findings, gate methodology, and mode comparison remain
> the reference — in particular `start_end_gap_m` ≈ 1.1–1.4 m over ~70 m is the drift baseline that
> sub-phase 6.D targets.)*
>
> **⚠ Two corrections from 2026-07-30 (BUG-037) that this document predates — read before quoting any
> number in it.**
> 1. **Every `path_length_m` here is inflated by roughly a third.** The barometric height constraint
>    fed ~267 mm RMS of per-frame sensor noise straight into the pose, adding ~12 mm of vertical step
>    per *frame* — on three later captures that was 34/29/37% of reported path. So the "67.85 m walk"
>    was more like ~45 m, and the **"~1.6% drift" below is really ~2.4%**. Anything computed as a
>    fraction of path in this document is optimistic by the same factor.
> 2. **The "Run-to-run variance (Open3D nondeterminism)" section below understates a real property,
>    and its explanation is unproven.** The variance is not an Open3D quirk to be worked around: a
>    deliberate **3 mm** one-shot height perturbation moves the final height error by **146 mm** and
>    the loop closure by **0.37 m** on a real circuit. Frame-to-model tracking is genuinely chaotic at
>    that scale, so a single run's gap is not a measurement. Score an ensemble of numerically
>    innocuous perturbations (CPU vs CUDA, start one frame later, ±1e-4 on `max_dist`) and quote
>    mean ± sd.

Task 9 wires Tasks 1–8 (deprojection, TSDF, ICP odometry, frame-to-model
`Mapper`, `SlamConfig`, `metrics`) into `roomscan-slam` and runs the empirical
validation gate against a real handheld capture:

- Capture: `captures/phase6_motion_ref.bin` (gitignored, 47.9 MB, 102 s,
  3187 RAW + full SFLP/ENV, 0 CRC failures). 3184 depth frames are decoded
  after CALIB init (3 frames precede the first CALIB and are dropped by
  `TransformStage`).
- Command (per the brief):
  ```
  cd host && .venv/Scripts/python.exe -m roomscan.slam.cli ../captures/phase6_motion_ref.bin \
    --compare-modes --out-mesh ../slam_map.ply --out-traj ../slam_traj.tum
  ```
- Outputs: `slam_map.ply` (1,603,275 vertices / 2,984,147 triangles, ~120 MB)
  and `slam_traj.tum` (3184 poses), both at repo root, **not committed**
  (gitignore doesn't need updating — they're simply never staged).

## Gate: median per-frame SLAM time < 35 ms

**Result: FAILS for both modes**, reported honestly rather than fudged.

| mode | median ms | p90 ms | p99 ms | max ms | over-budget frac |
|---|---|---|---|---|---|
| translation | 69.8 | 106.4 | 127.0 | 1227.9 | 97.0% |
| 6dof | 36.7 | 64.2 | 82.6 | 108.3 | 53.4% |

`translation` mode runs a full point-to-plane ICP solve and then *discards*
the rotation and re-derives translation, so it pays the same per-iteration
ICP cost as `6dof` plus extra bookkeeping — that's consistent with it being
~2x slower rather than cheaper. `6dof` is close to the 35 ms budget (~5%
over at the median) but still fails it.

A second full run (single-mode `translation` + `--benchmark`) reproduced the
same qualitative picture (median 70.2 ms) but with different exact numbers
(see "Run-to-run variance" below) — the **gate-fail conclusion is stable
across runs**, the exact percentages are not.

This is a real performance concern for Phase 6, not a CLI bug: Tasks 1–8's
`Mapper`/`register()`/`TsdfMap` implementation is what's being timed here;
Task 9 only wires and reports it. Flagging for the controller to decide
whether to raise the budget, profile/optimize the ICP+raycast path, or accept
degraded framerate for now.

## Trajectory quality — both modes

| mode | n | path_length_m | start_end_gap_m | max_step_m | tracking_lost |
|---|---|---|---|---|---|
| translation | 3184 | 70.824 | 1.077 | 0.769 | 992 (31.2%) |
| 6dof | 3184 | 32.029 | 1.357 | 0.603 | 2375 (74.6%) |

Both path lengths are physically plausible for a ~102 s handheld room
walkthrough (0.31–0.69 m/s average — a slow, deliberate scanning pace, well
below normal walking speed), and neither is "every frame lost" — so this
does **not** meet the brief's STOP/DONE_WITH_CONCERNS bar for an obviously
broken trajectory. It is nonetheless a real, high tracking-lost rate that
should be tracked as a Phase 6 follow-up (see below).

### Chosen default: `translation`

Per the brief's criterion ("lower drift `start_end_gap_m` for a room loop /
cleaner trajectory"), `translation` wins on both axes that matter for map
quality: smaller loop-closure gap (1.077 m vs 1.357 m) and dramatically fewer
tracking-lost frames (31% vs 75%) — despite being the slower mode. `6dof`'s
much higher loss rate is consistent with full 6-DoF point-to-plane ICP being
more prone to falling outside the fitness/RMSE gate (`min_fitness=0.3`,
`max_rmse=0.05`) on real, noisy 54×42 ToF data, and to genuinely singular
6×6 normal-equation solves on texture-poor surfaces (see below).

`SlamConfig`'s built-in default (`icp_mode = "translation"`, in
`host/src/roomscan/slam/config.py`) **already matches** this empirical
winner — no default was changed for this task.

### Tracking-lost behavior

Expected in kind, high in degree. `register()` (`odometry.py`) already
degrades a singular 6×6 ICP solve to `ok=False` instead of crashing —
confirmed directly: the full runs printed several
`[Open3D Error] ... Singular 6x6 linear system detected, tracking failed.`
messages (Open3D's own C++ logging before the caught `RuntimeError`), each
correctly absorbed into `tracking_lost` rather than propagating. Beyond
that specific failure mode, the fitness/RMSE gate rejects a meaningful
fraction of otherwise-converged ICP results on real noisy depth.

**Ruled out: quat/pressure pairing bug.** The wire order interleaves
streams as `RAW_3DMD(seq=N)` → `IMU_QUAT(seq=N)` → `ENV(seq=N)` — i.e. the
quat/env for a given seq arrive *after* that seq's depth frame in the byte
stream, so `_load_frames`'s "carry the latest forward" logic pairs each
depth frame with the *previous* seq's quat (~1 frame, ~16–35 ms stale). This
was the prime suspect the brief called out, so it was tested directly: a
throwaway seq-matched loader (buffers depth until its own-seq quat/env
arrive) was run against the first 800 frames alongside the current
carry-forward loader. Current (stale-by-one) pairing: `lost=0`. Seq-matched
("correct") pairing: `lost=12`. The fix made tracking-lost *worse*, not
better, on this subset — so the off-by-one lag is not the driver of the
full-file loss rate, and `_load_frames` was left as specified in the brief.
The real driver is most likely later segments of the capture with faster
motion and/or low-texture surfaces filling the FOV, which is a `Mapper`/gate
tuning question for a future task, not a Task 9 wiring defect.

## Run-to-run variance (Open3D nondeterminism)

Re-running the identical `translation`-mode command against the same file
produced different exact numbers:

| run | path_length_m | gap_m | lost | median_ms |
|---|---|---|---|---|
| compare-modes run | 70.824 | 1.077 | 992 (31.2%) | 69.8 |
| single-mode + `--benchmark` run | 81.877 | 1.701 | 824 (25.9%) | 70.2 |

Both runs agree qualitatively (gate fails, translation has far fewer lost
frames than 6dof, path length in the tens-of-meters range) but disagree by
~15–20% on exact path length / loss count. This points to non-determinism
in Open3D's tensor ICP/TSDF raycast (most likely floating-point reduction
order under multi-threading) shifting individual frames across the
fitness/RMSE gate threshold. Treat single-run numbers as indicative, not
exact; the qualitative conclusions above are stable across both runs.
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

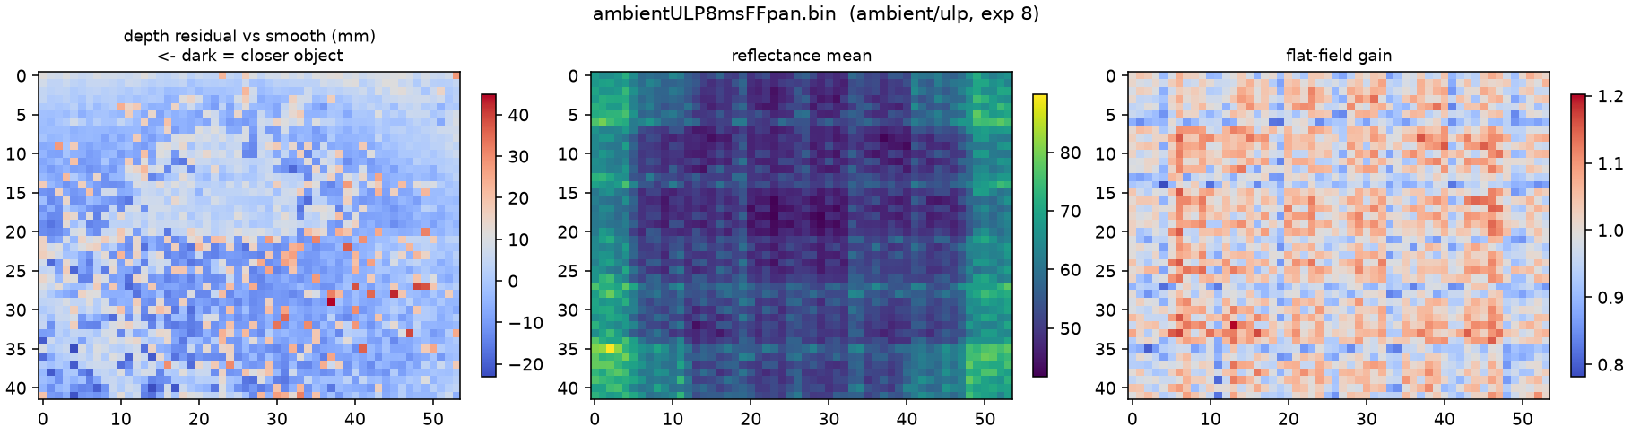
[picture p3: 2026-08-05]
calibration/flatfield/2026-08-04/ffpan_20260804_ambientULP8msFFpan.png

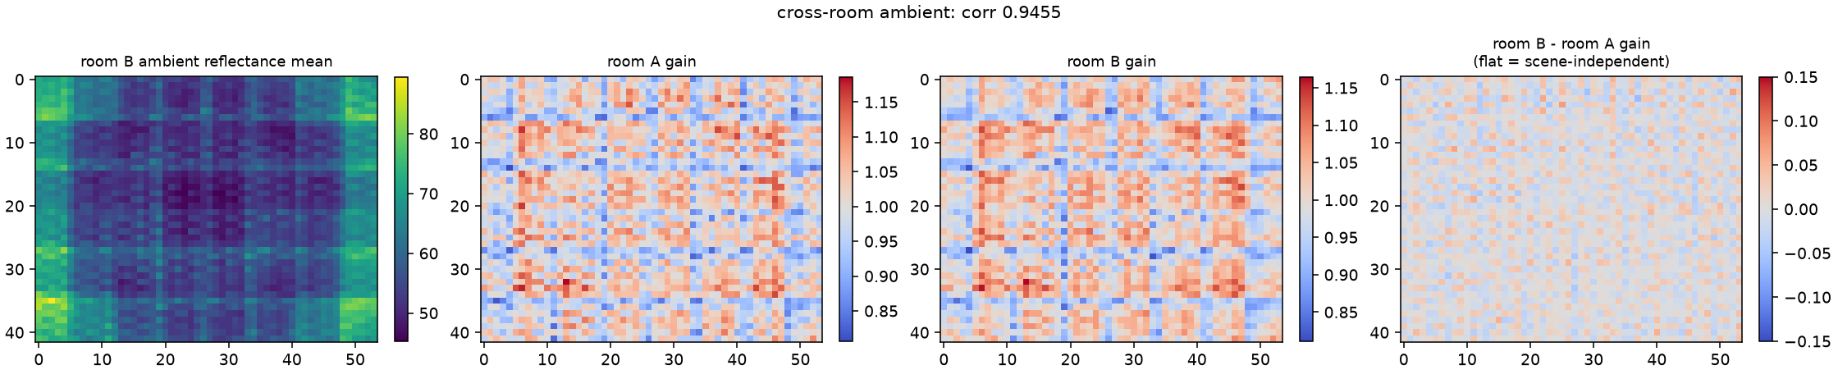
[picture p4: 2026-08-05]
calibration/flatfield/2026-08-04/crossroom_20260804_ambient.png

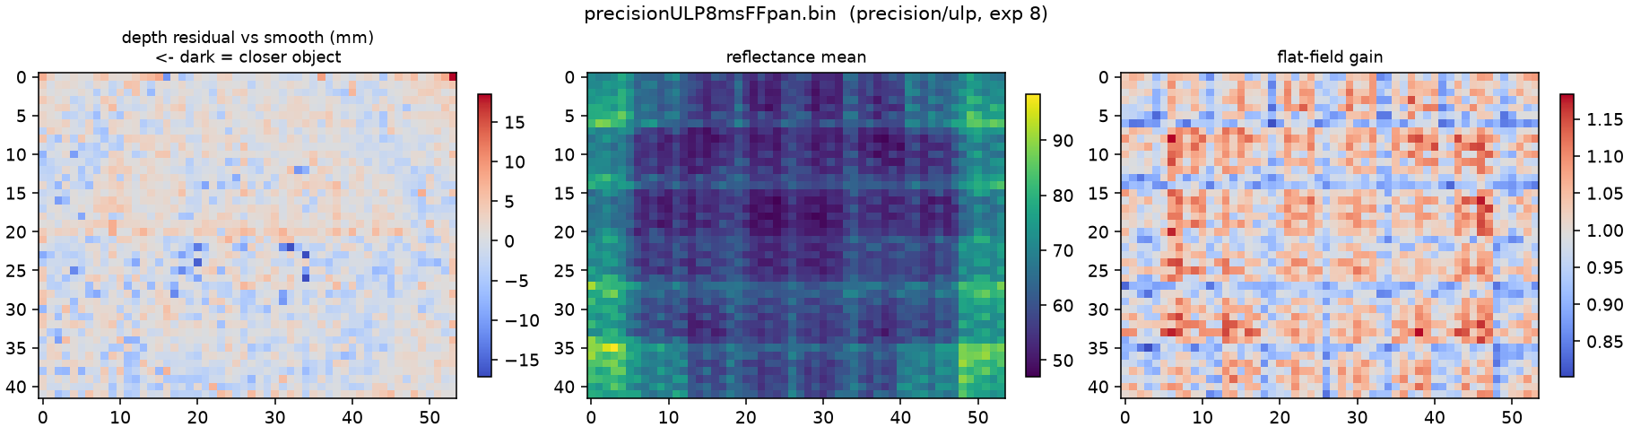
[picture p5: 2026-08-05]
calibration/flatfield/2026-08-04/ffpan_20260804_precisionULP8msFFpan.png

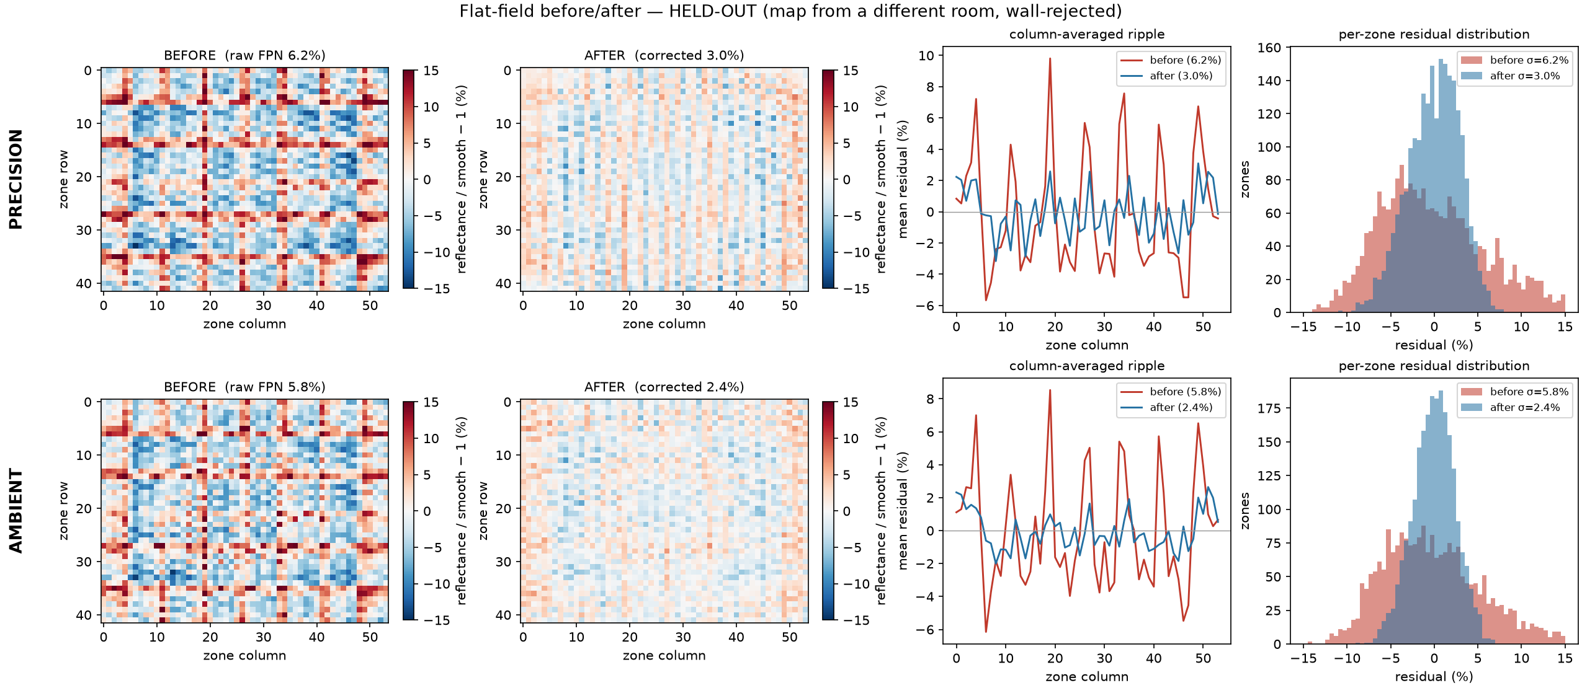
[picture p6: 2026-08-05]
calibration/flatfield/2026-08-04/beforeafter_20260804.png

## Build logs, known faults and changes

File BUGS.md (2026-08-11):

# Bug tracker

Defects moved to **GitHub Issues** (2026-08-10): `gh issue list --repo hellosamblack/lidar-roomscanner --label bug`.

File a new one: `gh issue create --repo hellosamblack/lidar-roomscanner --label bug --label area/<area>`
(area labels: `area/host-viewer`, `-panel`, `-sensors`, `-slam`, `-web`, `-transport`, `-tools`,
`-offline`, `-splat`, `area/firmware`, `-eth`, `-scanner-stream`, `-build`, `-host`,
`area/transform-lib`, `area/environment`). Close one: `gh issue close <n> --reason completed`
(or `"not planned"` for a by-design/anomaly/investigated call — add the matching `status/*` label).

All 98 legacy `BUG-NNN` write-ups were migrated verbatim as issue bodies. Titles carry **no** ID
prefix (the `BUG-NNN:` prefixes were stripped 2026-08-11 — they collided with GitHub's own `#NNN`;
the `bug` label denotes the type). Each body keeps a `Legacy ID:` line so GitHub's search still
finds the old ID, and [`docs/issue-migration-map.md`](docs/issue-migration-map.md) is the
authoritative old-ID → issue mapping. `ROADMAP.md`'s "Reference-firmware bugs" section (vendor
package, not GitHub-tracked) is unaffected.

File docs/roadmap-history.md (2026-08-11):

# Roadmap — historical record

Completed-work narratives moved out of [`ROADMAP.md`](../ROADMAP.md) when it was split into a
hot current-state doc + this cold archive. **Phases keep their original `Phase N` / `Web Phase N`
/ `6.x` names** so existing references ("ROADMAP Phase 5", "6.D", "6.G") still resolve here.
The forward-looking backlog now lives in `ROADMAP.md` → "Work-item register" with type-prefixed
IDs; this file is the measured record of how each completed piece landed.

---

## Agent tooling — `roomscan-mcp` ✅ (2026-07-29)

The agent-facing surface is an MCP server (`host/src/roomscan/mcp_server/`, `.mcp.json`,
`docs/mcp-server.md`) exposing 19 typed tools: `rig_*` (drive a running `roomscan-web` over `/ws`),
`ui_*` (headless Chrome held open across calls, screenshots returned as image blocks), `capture_*` /
`doctor` / `orientation_probe`, and `fw_build` / `fw_flash` / `run_tests`. Thin layer only — each
wrapped script keeps its `argparse` `main()` as a prose printer over the same pure function
(`analyze_capture.scan()`, `Doctor(quiet=True).results`), verified by byte-identical CLI output.

Two decisions worth keeping:
- **Client, never competitor.** The server never binds the device stream; `capture.py` stays
  CLI-only and recording goes through `rig_record()`, so the contention rule is structural.
- **12 scripts are deliberately CLI-only** (scratch tier, deprecated panel, one-shot rigs), each with
  a recorded reason. `host/tests/test_mcp_registry.py` fails on any `host/tools/` script that is
  neither exposed nor excluded — verified to go red on a probe script.

Measured along the way, both correcting the repo: the **Bash sandbox no longer kills network
listeners** (uvicorn bound `0.0.0.0`, served, exited 0 — `docs/headless-host-setup.md` and the
`agent-sandbox-port-binding` memory are stale), and **Playwright renders the Three.js scene on this
GPU-less host** via `channel="chrome"` + SwiftShader, so it is now the `ui_*` backend (raw CDP kept
as fallback) for native `wait_for_function`. **Five** "confidently wrong answer" bugs were found and
fixed during verification, all from trusting a timer-driven broadcast as proof of effect — including
one that reported failure while 734 clean frames *were* recorded, and a `rig_command` that called a
device timeout a success. See `docs/mcp-server.md` → "Two invariants".

**Firmware tools verified on-rig 2026-07-29.** `fw_build` (text 148044 / data 13231 / bss 54232) and
`fw_flash` (chipid `0x484`, written + verified) were run against a board that had **stopped
responding entirely** — no ping, no command ACK, `device_hz: None`, though SWD saw it fine at
3291 mV. Reflashing revived it: ping 0% loss, streams 7/9/10/11 at **30.5 Hz, 0 drops, 0 gaps**,
`ping` → `OK applied=1`, and 614 recorded frames with 0 CRC failures. Cause of the original hang not
investigated — worth watching for a recurrence.

### DC-B — the multi-room result, and why 6.D is now blocked on the transport (2026-07-31)

Three takes of the same route, each ~3 min, scored with 10-run innocuous-perturbation ensembles
(`slam_ensemble`, `--device CUDA:0`). **All three fail the "0 lost frames" gate** on transport loss
(BUG-049), so these are provisional, not the baseline the phase wanted.

| take | transport loss | horizontal closure | path | drift | tracking |
|---|---|---|---|---|---|
| `DebugCapB1` | 2.29% | **2.71 ± 0.58 m** | 75.32 ± 0.53 m | **3.6%** | 0/10 died, worst lost 15, no freeze |
| `DebugCapB2` | 4.28% | *excluded* | — | — | **628-frame (21.2 s) mid-run freeze** |
| `DebugCapB3` | 9.35% | **7.28 ± 0.71 m** | 75.60 ± 0.52 m | **9.6%** | 0/10 died, worst lost 92, 67-frame freeze |

**1. The multi-room drift *rate* is not worse than single-room.** B1's 3.6% against the single-room
baseline's ~3.1% (0.74 ± 0.19 m over 23.9 m) says frame-to-model drift scales with **path length**, and
does not compound at room transitions. On this evidence the case for loop closure earning its
complexity indoors gets **weaker**, not stronger — which is the opposite of what 6.D expected to find.

**2. Transport loss, not the SLAM algorithm, dominates multi-room error.** B1 and B3 are the same route
walked to within 0.4% of the same path length, and differ 4× in transport loss. Paired bootstrap over
the matched perturbation set: **4.569 m mean difference, 95% CI [3.950, 5.168] m** — decisively
non-zero. The mechanism is directly observed on B2, whose 628-frame tracking collapse begins **70 ms
after** its 2.4 s transport outage ends (BUG-049).

> **Therefore 6.D's loop-closure evaluation cannot proceed on this data.** Roughly 4.6 m of B3's 7.3 m
> drift is caused by dropped packets. No pose-graph result measured against that is interpretable, and
> the paired gate would be scoring the network. **Fix BUG-049, re-record DC-B, then evaluate.**

**3. Vertical drift is the weak axis and wants its own look.** B1 ends **−1449 ± 826 mm** below its
start on a single-floor route, with the barometer contributing only +109 mm — so this is ICP vertical
drift. Scaling the single-room circuit's 125 ± 76 mm by path length predicts ~390 mm, so vertical
appears to grow faster than linearly. The ±826 mm spread makes that ~1.8 sd, i.e. **suggestive, not
established** — worth a targeted measurement rather than a conclusion.

**4. `died` does not catch a mid-run freeze.** B2 reports `died == false` (its tail is healthy) while
15.5% of its trajectory is a frozen dead-reckoned segment, and still produces a plausible-looking
closure. `tracking_stats.died` is trailing-only by construction; **`longest_lost_run` is the field that
catches this class**, and `slam_ensemble` now surfaces it as `worst_longest_lost_run` with a warning.

### DC-J — what a mirror actually does to this sensor (2026-07-31)

Measured against the capture's own room-only segments as baseline (the scan starts normal, which is
what makes it useful). Mirror dwell isolated to **t = 39.6–56.3 s** by no-return-sentinel fraction.

- **What comes back is multipath, not a virtual room.** Sentinel (12000 mm) fraction rises 0.07% →
  **12.1%**, but the *non*-sentinel returns spread diffusely over 600–5800 mm with no sharp peak at
  twice the mirror distance. The feared failure — a coherent phantom room integrated behind the wall —
  **does not occur**.
- **The map is not corrupted.** Block consumption *during* the dwell runs at **17.2 blocks/frame vs
  28.9 pre-dwell**: the mirror contributes *less* geometry, not phantom geometry. Mesh bbox grew
  proportionally with path length, with no blow-up to sentinel or 2×-distance scale.
- **Tracking is essentially unaffected** — 4–12 lost frames of 1270 across a 5-run ensemble, longest
  freeze 8, 0 died, 23 ICP escalations.
- **A real specular glint exists but is tiny**: reflectance max 4543 during dwell vs 192 in the room
  (24×), confined to **0.015%** of pixels. That is a plausible cheap specular *detector* if one is
  ever wanted.
- **Confidence does not flag it** — mirror returns are dampened monotonically with range rather than
  marked, so there is no per-pixel validity signal. A concrete new data point for **BUG-007**.

Conclusion: **no bug, no mitigation warranted.** TSDF/ICP already discard sentinel and multipath
returns structurally. Recorded here so the question is not re-opened from first principles.

**Explicitly NOT owner-data-blocked** (do not add these to the queue): ~~compression go/no-go and the
pacer measurement (Phase 5.5 — the link measures zero loss over ~567k frames and loss must **not** be
manufactured)~~ **⚠️ that exclusion is WITHDRAWN as of 2026-07-31: the link no longer measures zero
loss.** The three DC-B takes lost **2.29% / 4.28% / 9.35%** of RAW frames while byte-clean, in
multi-second whole-group outages — see BUG-049. Loss no longer has to be manufactured; it is in the
captures. The remaining exclusions stand: Detailed-SLAM iteration calibration and the track-at-10 mm/reconstruct-at-5 mm
question (6.D item 2 — runs against `coffeeRoomCircuit*.bin`); Allan-variance characterisation
(`captures/stationary_stream11_20260728_190311.bin`, 900 s, already recorded); SHT40 humidity
(firmware work gated on a consumer existing). One non-data blocker: 6.D's end-to-end browser/server
verification needs an agent permission profile that allows local port binding — a settings change,
not a capture.

## Phases

### Phase 0 — ✅ Complete
On-device transform pipeline + ASCII depth map over ST-Link VCOM.
Enabled by `CONF_PRINT_FRAME = 1` in `Src/vl53l9_app.c:31`.

### Phase 1 — Real-time 3D visualizer  ← **✅ Complete** (plan: `docs/superpowers/plans/completed/2026-07-07-phase1-binary-protocol-visualizer.md`)

> **Status 2026-07-08:** both milestones verified on hardware.
>
> **1a** (ST-Link VCOM @921600): 0 CRC failures, 0 seq gaps, ~5.9 fps (sensor frame time + blocking
> UART co-limit; see `.superpowers/sdd/task-8-report.md`).
>
> **1b** (native USB CDC, TinyUSB, VID:PID `0xCAFE:0x4001`): 0 CRC failures, 0 seq gaps, 0 drops over a
> 20 s continuous capture (273 frames) — **13.65 fps**. Stall/recovery test (2 s read → 5 s host stops
> reading, port held open → 5 s resume) behaved exactly per the drop-policy design: 1 transient CRC
> failure from the mid-frame abort, one seq gap of 29 frames (dropped while the host wasn't draining,
> correctly marked with `FLAG_DROPPED` on the next successfully-sent frame), then clean contiguous
> decoding resumed with no further loss — see `.superpowers/sdd/task-11-report.md`.
>
> **The plan's "fps ≥ 15" figure is stale, not a miss**: a per-frame breakdown (`HAL_GetTick` deltas,
> 20-frame samples with an active CDC host draining) shows `transform_process_stream` ≈ 37-40 ms,
> the CDC send itself ≈ 8-9 ms, and sensor trigger/I3C readout/event-wait ≈ 26-29 ms — total ≈ 74 ms/frame
> (13.5 fps). The CDC link is *not* the bottleneck (send is ~12% of the frame budget and headroom is
> large — CDC FS moves the 9108 B frame in a fraction of that 8-9 ms of wall time budget, the rest is
> host-driven FIFO pump/schedule slack); the ceiling is sensor + on-MCU transform time, unchanged from
> milestone 1a's finding. Speeding this up (binning, usecase, or moving processing off the acquisition
> loop) is Phase 3+ scope, not a Phase 1 blocker.
>
> Known follow-up (unchanged): ~1-in-5 boots hang in sensor bring-up before frame 1 → needs EVENT-frame
> reporting + re-init recovery (wire contract for EVENT frames is already specced in `docs/protocol.md`).

Replace ASCII printing with a **versioned binary frame protocol** and a PC app that deprojects depth into
a live-rendered point cloud.

**Deliverables**
- `docs/protocol.md` — wire spec v1 (32-byte header, depth/ZF32 stream, CRC32) + golden test vectors.
- `host/` — Python package `roomscan`: streaming decoder (resyncs on corruption), depth→XYZ deprojection,
  serial + file-replay sources, raw-capture recorder, Open3D live viewer with fps/drop HUD.
- `firmware/scanner-stream/` — fork of `<APP>` that emits binary frames. Two milestones, both ✅:
  **1a** over ST-Link VCOM at 921600 baud (~5.9 fps — proved the whole chain with zero new
  middleware), then **1b** over native USB CDC FS (13.65 fps — full sensor+transform rate; link
  itself has ample headroom, see status note above).
- `docs/transform-streams.md` — captured `streams_inspect` / `controls_inspect` startup dump
  (`vl53l9_app.c:91-98`). **Capture this at first flash** — it enumerates what the transform library can
  emit (depth / reflectance / confidence / possibly XYZ) and settles on-MCU vs PC-side deprojection, and
  it scopes Phase 2/3.

**Acceptance** — ✅ met
- Live point cloud renders on the PC at the sensor's native frame rate over CDC; seq-gap counter proves
  zero drops with the host idle; recorder + replay reproduce identical clouds.

**Risks / bugs to watch**
- **No ST USB Device middleware in the `53L9A1/` package** — superseded: milestone 1b vendored
  **TinyUSB** instead of `STM32_USB_Device_Library` (see the `firmware/vendor/tinyusb` commits); CDC
  ACM enumerates on `hpcd_USB_DRD_FS` with HSI48 as the USB kernel clock, confirmed on hardware.
- **CDC TX re-entrancy** — resolved: `rs_cdc_send` pumps `tud_task()` while draining
  `tud_cdc_write_available()` and aborts (drop, not retry-spin) after a 100 ms stall; verified on
  hardware by a stall/resume test (see status note above).
- **ZF32 units and range unverified** — believed float millimetres of perpendicular Z
  (`radial_to_perp.c` exists in the algo set). Confirm empirically at capture time before hardcoding the
  mm→m conversion.
- **FoV constants for deprojection** — resolved in Phase 2.5: datasheet-derived defaults (55.0°H/42.0°V,
  `docs/vl53l9cx-fov-notes.md`), independently confirmed by a ZAPC least-squares best-fit (54.65°/42.50°,
  `docs/deprojector-validation.md`) within 0.35°/0.50° — no XYZ output stream exists (ZAPC is the closest
  equivalent; see Phase 2's stream facts below).
- ST-Link VCP at 921600: V3EC supports it, but verify clean reception (frame CRC failures at rate 0)
  before trusting milestone 1a numbers.

### Phase 2 — Raw streaming + PC-side transform (revised 2026-07-08) ← **✅ Complete**

> **Status 2026-07-08:** verified end-to-end on hardware. Firmware streams raw sensor frames only; the
> `vl53l9-transform-c` pipeline runs natively on the PC via a ctypes-wrapped DLL.
>
> **Equivalence gate** (Task 4 — the go/no-go everything else was gated behind): PC-side transform
> output vs. the same raw input processed on-MCU, compared over the full 731-pair hardware capture
> (`captures/golden_pairs.bin`, seq 1..731, one continuous 65 s run) — **731/731 pairs within the
> 0.01 mm tolerance**, max abs diff **0.000854 mm** (p50 0.000366, p90 0.000488, p99 0.000610 mm).
> **0/731 pairs are bit-exact** — reported honestly: the PC build (`/fp:precise`) and the MCU build
> (`-Ofast`) diverge slightly from float instruction reordering/reassociation, not a correctness bug;
> the divergence is over an order of magnitude below the gate. **PASS** — the on-MCU transform is
> retired.
>
> **Raw-only firmware** (Task 5): `CONF_TRANSFORM_ONBOARD=0` — the sensor streams RAW_3DMD (14,842 B)
> plus periodic CALIB (2,332 B, every 64 RAW frames) over native USB CDC. Measured **24.6 fps** (491
> frames / 19.921 s), just under the 25 fps target — CDC send-time serialization on top of the
> mandatory 5 ms settle + sensor ranging time, not a sensor limit (frame-time breakdown in the Task 5
> report). Confirmed again live in Task 7's soak runs (steady 23.3-27.0 fps across 1600+ frames).
>
> **Host pipeline** (Task 6): `TransformStage` bridges RAW/CALIB frames to depth arrays via the native
> DLL, lazily constructed on the first CALIB frame (depth-only replays never touch the DLL); viewer HUD
> gained `raw`/`raw-skip` counters. 39/39 tests passing.
>
> **Live end-to-end** (Task 7): `roomscan-view` against the live board, raw-only firmware, multiple
> supervised soaks (~55-113 s each): steady **~24-25 fps**, **0 seq gaps**, `raw` climbing 1:1 with
> `frames` throughout (1620 frames in the recorded run, `captures/e2e_p2.bin`). One CRC failure and
> one `FLAG_DROPPED` appeared at connection time — a **first occurrence**, not previously seen at
> connect: Phase 1 Task 11's 20 s soak and Phase 2's Task 2 (1471 frames) / Task 5 (499 frames)
> connect-time captures were all clean (Task 11's single CRC event came from its deliberate stall
> test, a different mechanism). The transient is one frame, does not recur within the run, and
> reproduces identically on replay of the same capture (i.e. it's in the recorded bytes, not decoder
> nondeterminism). Cause unexplained — observed once and now tracked in the deferred list below
> (candidate common root with the 1-in-5 boot hang: sensor bring-up timing). **`raw-skip` behavior, now
> documented**: on a **freshly SWD-reset** board, `raw-skip` stays **absent (0)** for the whole run —
> CALIB arrives before any RAW, as designed. On a board that had already been streaming since an
> earlier session, a host attaching mid-cycle sees a transient `raw-skip` (observed: 31, stable, never
> grows) because CALIB is retransmitted only every 64 RAW frames, not re-sent on every new host
> connection — a real, benign behavior, not a bug.
>
> **Stall/recovery** (Task 7): mid-run 5 s host-stops-reading (port stays open, same procedure as
> Phase 1's Task 11) — one transient CRC failure from the mid-frame abort, one seq gap (37 frames, seq
> 49→87), exactly one `FLAG_DROPPED` on the recovery frame, then clean contiguous decoding resumed
> (292 further frames, 0 further gaps/failures). **New for Phase 2**: `TransformStage` was fed straight
> through the gap — all 292 post-recovery RAW frames transformed to valid depth (`depth_ok=292,
> depth_bad=0`, no NaN/negative values), confirming the pipeline stays numerically sane across a
> dropped-frame boundary. The on-MCU TNR (temporal noise reduction) filter's state continuity *is*
> broken by the gap (its internal history assumes contiguous frames) — expected to show up as a
> one-time transient in the depth output's noise characteristics right after the gap, not as invalid
> data; this is expected live behavior given the drop policy, not a defect.
>
> **Replay identity** (Task 7): `captures/e2e_p2.bin` (the live run's RAW+CALIB recording) replayed
> through the same viewer/pipeline path at `--replay-fps 25` — `raw` climbing at the paced rate, 0 seq
> gaps, the same 1 CRC failure / 1 dropped-flag baked into the recording reproduced identically, no
> traceback. Confirms replay exercises the full PC-transform path on the exact recorded bytes.
> Replay identity is guaranteed only for recordings started from a device boot (frame 1): a mid-session `--record` starts at an arbitrary point, so its replay re-runs the transform with fresh TNR state after the next CALIB — a brief filter transient vs the live render, below sensor noise.
>
> **Deferred / follow-up** (not blockers for calling Phase 2 done) — **resolved in Phase 2.5 except where
> noted still-open:**
> - ✅ **Reflectance/confidence/ambient/`--color` viewer support** — shipped Phase 2.5 Task 2: the shim
>   grew a mask-selection API (`rst_create2`/`rst_process2`, `DEPTH|REFLECTANCE|CONFIDENCE|AMBIENT|ZAPC`)
>   and the viewer gained `--color {depth,reflectance,confidence}` (default changed to `reflectance` in bug tracker branch, falls back to `depth` if absent)
>   with a one-time stderr fallback notice if the requested plane is absent from the stream. Verified live
>   on hardware (Task 5, this doc's Phase 2.5 note below): IR-shaded cloud renders, no fallback warning,
>   no traceback.
> - ✅ **Trigger-early overlap** — shipped Phase 2.5 Task 4: the raw-only loop now triggers frame N+1
>   before sending frame N over CDC, hiding the ~15 ms send inside the sensor's ranging window. Measured
>   **27.76 fps** (up from 24.6), 2 ms settle (down from 5 ms; the one bounded experiment the task allowed),
>   0 crc, 0 gaps, re-confirmed by this task's 60 s live soak (below). **Strategic implication**: the CDC
>   send is no longer on the critical path at all (fully hidden inside ranging). Ethernet's value going forward is what the Phase 4 section already
>   says: 100 Hz-class rates, hardware PTP timestamping, and zero-config direct-link — not a fps lift for
>   this loop.
> - ✅ **ZAPC Deprojector validation** — done Phase 2.5 Task 3: ZAPC's z is bit-identical to ZF32 depth
>   (hard-asserted, 0.0 mm diff); best-fit FoV 54.65°H/42.50°V agrees with the datasheet defaults within
>   0.35°/0.50°; worst-case linear-model displacement is corner-concentrated (127 mm / 6.36% of z at
>   row 0, col 53, vs. 12-20 mm center-region) and doesn't improve with a global FoV tweak, so the linear
>   defaults stand and an **optional per-zone tan-table path** was added to `Deprojector` (constructor arg,
>   linear stays default) for future consumers needing corner accuracy. Full numbers, conventions, and the
>   decision writeup: `docs/deprojector-validation.md`. ~~**Vendor-bug note**: ZAPC's 4th (confidence)
>   channel is structurally ~1.0 on every zone including no-return sentinels — not usable as a validity
>   gate. Root cause (uninitialized `conf_scaling` divisor, never assigned anywhere in the `53L9A1/`
>   tree — the channel is structurally constant, no capture can change it; the sentinel zones'
>   1e-6-digit micro-variation is actually a packed filter-status code, not a confidence score) is
>   documented in `docs/deprojector-validation.md`'s confidence-channel section.~~ **Resolved**: The uninitialized `conf_scaling` divisor in the reference transform library was fixed by initializing it to `1.0f` in `radial_to_perp.c`, allowing the ZAPC confidence channel to dynamically vary and discriminate correctly (verified via `validate_deprojector_zapc.py`). Depth-sentinel gating remains a robust fallback mechanism.
> - **✅ Resolved — connect-time CRC/DROPPED transient** (first observed Phase 2 Task 7): root-caused
>   Phase 3 Task 6 by byte-exact forensics on both recorded instances (`captures/e2e_p2.bin`,
>   `captures/e2e_p25.bin`) — full writeup `docs/connect-transient-forensics.md`. Both captures show the
>   *identical* signature down to the byte: a perfectly well-formed RAW_3DMD seq=1 header immediately
>   after CALIB seq=1, truncated ~2.8 KB short of its declared payload+CRC, followed by `FLAG_DROPPED` on
>   seq=2. This is the pre-existing `rs_cdc_send()` 100 ms mid-frame-abort/DROPPED-flag mechanism (the
>   same one the stall/recover experiments deliberately trigger) firing once, for free, because the
>   host's own startup latency between DTR-assert (on port open) and its first live `.read()` can exceed
>   the firmware's 100 ms per-write budget on frame 1. **Characterized-cosmetic**: costs exactly one RAW
>   frame, self-heals with no seq gap, never recurs within a session, no wire/decoder change needed. Not
>   the mid-stream-reattach mechanism (see the CALIB-on-DTR-connect item below) — the CALIB `seq=1` and
>   early `t_us` in both captures prove these are genuinely fresh boots, not stale reconnects.
> - **Open — CALIB-on-DTR-connect** (mid-stream reattach, architecturally distinct from the item above —
>   see `docs/connect-transient-forensics.md`'s "DTR-gate one-shot" section): CALIB retransmit cadence
>   means a host attaching mid-cycle discards up to 63 RAW frames (~2.3 s blind start at 27.76 fps).
>   **Partially mitigated**: Phase 3 Task 2 shipped `SEND_CALIB` (`roomscan-ctl calib`) — a host can now
>   request CALIB on demand instead of waiting out the cadence. An automatic fix (device aborts any
>   in-flight frame and sends CALIB immediately on DTR rising, via `tud_cdc_line_state_cb`) was evaluated
>   Task 6 and found **not** small/safe enough to land there — it needs new synchronization between a
>   TinyUSB callback context and the main loop's send/trigger state (`raw_mem_index`, `rs_calib_countdown`,
>   in-flight `rs_cdc_send()`); specced as a Phase 3/4 follow-up, not implemented. Live evidence of the
>   blind start this fix addresses: Phase 2.5 Task 5's `--color` run attached mid-cycle and observed
>   `raw-skip 37` (stable, within the documented ≤63 ceiling).

Migrate post-processing to the PC per the architecture decision above. This **absorbs the original
Phase 2** (IR + additional streams): once the transform runs host-side, every output stream — depth,
reflectance, confidence, ambient, amplitude, status, and the ZAPC point cloud — is available on the PC
for free; multi-stream firmware plumbing is no longer needed.

- Firmware: new RAW stream over the existing protocol (`stream_id` from the registry; raw `3DMD`
  payload + a one-time calibration/EVENT frame at startup carrying `calib_data`); acquisition loop
  simplifies (no transform, no output buffer) — target the sensor's characterized 30 Hz profile.
- Host: build `vl53l9-transform-c` as a native library (portable C; needs a thin platform shim),
  wrap for the `roomscan` pipeline (raw frame + calib in → chosen output streams out), golden-test
  bit-exactness against an on-MCU-produced depth capture from Phase 1 (we have `captures/` +
  `hw_capture_snippet.bin` as ground truth).
- Viewer: colorize the cloud by IR reflectance/confidence (original Phase 2 UI goals), stream toggles.
- Acceptance — **met, with honest caveats**: full 54×42 raw streaming over USB CDC at 24.6 fps
  (target was ~30 fps — see the fps note above for why; not a blocker), PC-transform output within
  0.01 mm of the Phase 1 on-MCU output for the same raw input (not bit-identical — 0% exact-match rate,
  documented above; equivalence here means "within tolerance").

- **Stream facts** (Task 7 capture, `docs/transform-streams.md`): the transform library exposes `depth`,
  `ambient`, `amplitude`, `confidence`, `reflectance`, `status` outputs; wire stream IDs 0-6 are
  allocated in `docs/protocol.md`'s registry. With the transform host-side these are PC-config choices,
  not firmware features. The `ZAPC` point-cloud format now also runs on the PC and was used (Phase 2.5
  Task 3) to validate the host `Deprojector`'s linear-FoV model against calibrated intrinsics — datasheet
  defaults confirmed, optional per-zone tan-table added for corner accuracy (`docs/deprojector-validation.md`).
  ~~**Vendor bug**: ZAPC's per-zone confidence channel is structurally ~1.0 everywhere (uninitialized
  `conf_scaling` divisor in the library, never assigned) and does not discriminate valid/invalid zones —
  don't gate on it; use the depth sentinel instead (root cause + measurements in
  `docs/deprojector-validation.md`'s confidence-channel section; see also the Phase 2.5 deferred-list
  entry above).~~ **Fixed**: The uninitialized `conf_scaling` divisor has been set to `1.0f` in the library; the confidence channel now varies dynamically.
- Bandwidth: only the raw stream crosses the wire (14,842 B/frame — 1.63× the old depth payload,
  regardless of how many output streams the PC computes). 30 Hz ≈ 445 KB/s fits CDC FS.

### Phase 2.5 (interlude) — Multi-stream color, calibrated FoV, 30 fps overlap ← **✅ Complete**

Plan: `docs/superpowers/plans/completed/2026-07-08-phase2.5-color-fov-overlap.md`. Cleared the top three items
from Phase 2's deferred list (all detailed above, inline, where each topic is discussed): datasheet +
ZAPC-calibrated Deprojector FoV, host-side reflectance/confidence/ambient/ZAPC outputs with viewer
`--color`, and a trigger-early restructure of the raw-only firmware loop (24.6 → 27.76 fps, target ≥28
missed by 0.24 fps — sensor-serial, not hideable; see the overlap bullet above for the honest budget
breakdown). Re-verified end-to-end on hardware (this task): 60 s live soak steady 26.6-28.0 fps, 0 seq
gaps, 1 crc fail + 1 dropped flag (both connect-time, same tracked transient as Phase 2 — no new
failure mode, 2 ms settle stability tripwire passed with no stall/gap bursts across the full soak);
`--color reflectance` 15 s live check rendered the IR-shaded cloud with no fallback warning and no
traceback; stall/recover quick check (2 s read → 5 s not-reading, port held open → 10 s resume)
reproduced the established drop-policy behavior exactly (one seq gap, one `FLAG_DROPPED` on the
recovery frame, one transient CRC failure, then clean contiguous decoding with all post-recovery depth
frames finite/non-negative). `docs/protocol.md` verified unchanged — no wire change in this phase, as
planned. Left open at the time: the connect-time transient and CALIB-on-DTR-connect (both above),
carried forward unchanged from Phase 2 — the connect-time transient was later root-caused and resolved
in Phase 3 Task 6 (see the updated bullet above).

**Data-quality follow-up — reflectance fixed-pattern (FPN) + flat-field correction (2026-07-16).**
Characterized a real, sensor-locked per-zone response non-uniformity in the reflectance plane: on a
flat wall it measures **~18% of signal**, rock-stable frame-to-frame (SNR ~9), aligned to the sensor
row/column axes — not display moiré, not scene texture (per-zone SPAD sensitivity / DSS). It
contaminates the IR view, reflectance SLAM coloring, and would be *amplified* by any reflectance-based
enhancement (multi-frame super-res / relief shading). **Host correction built + shipped-disabled:**
`roomscan.flatfield` (multiplicative unit-mean per-zone gain map) applied to the reflectance plane in
`pipeline.TransformStage` (so web/panel/viewer/SLAM all get it), gated by `[viewer] flatfield_path`,
off by default; builder `tools/build_flatfield.py`; 11 tests (656 suite green); doc
`docs/flatfield-calibration.md`. **STILL OPEN — needs on-rig action:** capture a real flat-field
reference by *slowly panning* the sensor across a uniform matte wall (panning is mandatory — it
averages out scene texture; a static capture is invalid: `verify_slam.bin` → 44%-residual garbage
map), then `build_flatfield` → set `flatfield_path` → verify the grid collapses. Prerequisite for the
reflectance super-resolution / sensor-fusion-overlay work (both scoped, not yet built).
**Revised 2026-08-04 (stationary ceiling study, `calibration/flatfield/2026-08-04/`):** the FPN is
**mode-family-specific** — Precision-family runs carry a stable **6.6%** high-frequency pattern while
Ambient-family runs carry a different **3.7%** one (map correlation only ~0.34; cross-applying a map
leaves ~6.0–6.4%). A single global `flatfield_path` is therefore **not** the correct end state: enabling
correction needs **mode-aware selection** — at minimum distinguish Precision-like from Ambient, ideally
key by ranging mode × power mode × exposure family — either a mode-keyed map registry or an explicit
operator-selected map, so a Precision map is never silently applied to an Ambient frame. Two engineering
actions fell out, **both now done: (1)** mode-aware `flatfield` selection **SHIPPED 2026-08-04** —
`FlatFieldSet` keyed by ranging mode, `[viewer] flatfield_precision_path`/`flatfield_ambient_path`
(legacy `flatfield_path` = fallback default), the live `TransformStage` pointed at the current mode's
map from the ranging-config ACK, and a web Device-card **Calibrated/Uncalibrated** runtime toggle
(`set_calibrated`, persisted `[viewer] calibrated`); **(2)** DC-D2 — a panned pan per mode family plus a
held-out-distance/second-room pan (the 2026-08-04 static holdout only proved *temporal stability*, not
*scene-independence*; the cross-room captures then proved it: ~2.4% Ambient / ~3.0% Precision) (a static map can retain the ceiling's illumination field,
and the before/after metric shares the builder's 2.5σ low-pass, making part of the reduction definitional).
The nine per-capture candidate maps in that archive are **engineering candidates, not production**; for
interim viewer testing use the 8 ms Precision map for Precision-like modes and the Regular/ULP Ambient
maps for their Ambient modes.

### Phase 3 — UI & runtime configuration ← **✅ Complete** (plan: `docs/superpowers/plans/completed/2026-07-08-phase3-runtime-config-robustness.md`)

> **Status 2026-07-08:** verified end-to-end on hardware, branch `phase3-runtime-config`, 7 tasks.
>
> **Protocol** (Task 1): `frame_type` 3 = COMMAND (host→device), 4 = ACK (device→host) — additive to v1,
> no version bump. Command registry 1-6 (PING, SEND_CALIB, SET_USECASE, SET_FRAME_PERIOD_US,
> SET_EXPOSURE_MS, REINIT), result registry 0-5 (OK, UNKNOWN_CMD, BAD_PARAM, REJECTED_BINNING,
> SENSOR_ERROR, BUSY). Full spec + version-history entries in `docs/protocol.md`.
>
> **2026-07-21 addition — SET_STANDBY (cmd 7) + Ethernet command RX** (on-rig verified over UDP):
> `SET_STANDBY` (param 0=wake/1=soft/2=hard) idles the ToF VCSEL for laser-wear reduction — soft =
> `vl53l9_stop()` → FSM STANDBY (instant resume), hard = `+ platform_power_disable()` (full re-init to
> wake). Applied at the same `rs_pending` safe point as the reconfig commands; a new loop-top idle branch
> services transport + polls for the wake instead of blocking on a frame event. The host `roomscan-web`
> drives it automatically off its viewer count (debounced, `[viewer] sensor_idle_*`). **Also found + fixed:
> the Phase 5 Ethernet transport was stream-out-only — `udp_receive_callback` discarded all inbound
> payloads, so NO command (ping/usecase/reinit/standby) had ever reached the board over Ethernet.** Inbound
> UDP now feeds the same `rs_parse_command`/`rs_pending` path as CDC (`rs_poll_commands_from` factored to
> take a byte-reader; `rs_poll_eth_commands` drains an `ETH_ReadCommands` buffer). Verified: soft+hard drop
> RAW to 0 frames/3s, wake resumes ~90 fps, PING+all standby ACK'd over UDP, 0 CRC.
>
> **2026-08-03 addition — activity-based auto-idle + browser park + firmware wake-on-motion**
> (on-rig verified): the viewer-count trigger above turned out to undercount correctly — a `/ws`
> connection that never engages (an agent's stale probe, a tab left open unattended) counted as
> "a viewer" forever, so the sensor never idled despite nobody actually watching. Host now tracks
> per-connection activity (`client_id` shared across `/ws`+`/ws-mesh`,
> `sensor_idle_activity_timeout_s`) and ages out a silently stale connection via a periodic
> reconcile tick, not just on clean disconnect; a live recording always counts as active.
> **Parking also releases server load, not just client rendering**: a parked `client_id` is
> excluded from the broadcaster's POINT_CLOUD/IR_IMAGE sends and from `/ws-mesh`'s credit-gated
> pump, not merely told to stop rendering locally (BUG-060/061 lesson: connection count is a
> performance variable on this server). New web UI: `idle.js` parks an inactive tab
> (mouse/keyboard/visibility, default 5 min) behind a "Connection idled" modal, resuming on any
> activity or the button; `browser_idle_timeout_s` is server-configured so one value governs
> every tab. **Firmware, two owner corrections mid-pass**: (1) the idle branch now polls the
> LSM6DSV16X's own embedded Wake-Up function (`WAKE_UP_SRC` — an independent hardware block from
> SFLP, confirmed no conflict, and moot anyway since this build runs High-Performance not HAODR
> mode) and self-wakes on real motion (new event `RS_EVT_AUTO_WAKE_MOTION`), not only on a host
> command; (2) **idling only parks the ToF laser, not the IMU/env** — IMU_QUAT/ENV/IMU_RAW keep
> flowing (on-rig measured 18.2 Hz, `seq` frozen at `g_last_seq`, `t_us` = live clock) while the
> ToF sits at 0 Hz, since the LSM is a separate chip on the shared I3C bus untouched by
> `vl53l9_stop()`/`platform_power_disable()`. On-rig verified end-to-end: a parked-but-connected
> client actually idles the device while its socket stays open, ToF drops to 0 Hz with
> IMU/ENV/IMUraw steady at 18.2 Hz, and reconnect/resume both wake cleanly. **Found, not fixed
> (pre-existing, unrelated to this pass)**: `resolve_command()` in `web.py` never wired up
> `"standby"` as a generic `cmd` name (only the dedicated `set_idle` path handles it), so
> `rig_command(name="standby", ...)` fails even though the wire protocol and `roomscan-ctl` both
> support it.
>
> **Firmware command channel** (Tasks 2, 4): TinyUSB CDC RX + a bounded fixed-size frame parser
> (magic/CRC-checked, malformed input dropped and counted, polled once per acquisition-loop iteration —
> never blocks acquisition). PING/SEND_CALIB need no reconfig; usecase/exposure/period/REINIT
> reconfigure the sensor at a safe point (stop → re-profile → restart) via a factored-out
> `rs_sensor_reinit()` that Task 5's recovery path reuses directly. **Binning stays fixed at 2**
> (owner scope) — `SET_USECASE` rejects any binning-4 profile with `REJECTED_BINNING` without ever
> touching the sensor.
>
> **Measured per-usecase fps** (Task 4, [HW], board reset between measurements):
>
> | usecase | id | binning | result | measured fps |
> |---|---|---|---|---|
> | AR_RANGE | 0 | 2 | OK | **32.1-32.3** |
> | AR_PRECISION (shipped compile-time default) | 1 | 2 | OK | **27.8-28.6** |
> | AF_RANGE | 2 | 4 | **REJECTED_BINNING** | n/a — no full-res (binning-2) profile exists for this usecase |
> | AF | 3 | 4 | **REJECTED_BINNING** | n/a — no full-res (binning-2) profile exists for this usecase |
>
> `SET_FRAME_PERIOD_US` applies and reads back faithfully (e.g. `50000` → ack `applied=50000`) but has
> **no observable effect on fps** in this app's always-`VL53L9_SYNC_MANUAL` design — the driver's own doc
> comment (`vl53l9.h:248`) says the field only governs autonomous sync mode. Documented as a spec-honest
> no-op (the ACK contract — apply + read back — is still met), not a bug; would need
> `VL53L9_SYNC_AUTONOMOUS` (a bigger, unattempted change) to actually govern fps. `SET_EXPOSURE_MS` *does*
> change fps measurably (5 ms → 28.6 fps, 15 ms → 25.6 fps).
>
> **High-rate/manual ranging — ✅ DONE (2026-08-04): all 12 tasks landed and validated.** Open items
> documented below and in BUGS.md — BUG-073/075/078 and BUG-074's fault-injection retest remain open;
> the wired-Ethernet release gate and CDC-isolation proof are DE-SCOPED (owner directive, no wired
> data link in production). BUG-079 (manual UI edit revert) was found by the Task 12 UI pass and fixed
> the same session.
> The reviewed
> [implementation plan](docs/superpowers/plans/completed/2026-07-31-high-framerate-and-manual-ranging-modes.md)
> is being executed; Tasks 1–11 are on `main` (`d2c4148` profiles contract, `2b8a9ee` protocol
> v2 cmds 8–12, `414adaa` typed control, `7598fde` atomic firmware profiles, `b10f44d` autonomous
> sync + BUG-072, `5c23270` SLAM-ingest split, `8cc9239` web ranging UI, `896c7a8` model refinement,
> `5c90da6` Task 6 pacing/telemetry firmware+host, `10966c5` EVENT 7 golden vector,
> `91a5dfe` web queue telemetry, `56ee9ba` analyze_capture v2 fix, `3f4b307` Task 7 IMU/env decoupled
> poll rate + BUG-074 fix, `d732f3a` Task 8 rate-aware filters, `17a27d8` BUG-077 fix, `1663556`
> Task 11 MCP ranging control, `a418131` ProfileTuning comparison). **The headline changed at Task
> 5's stop point:** with applied periods readback-exact, the sensor quantizes any shorter-than-floor
> period to integer multiples (90 Hz request → 44.85 fps at 2×), and the floor is sensor-intrinsic —
> measured brackets 20.0/21.74/23.53 ms at ≤2/4/8 ms exposure. Per the plan's own rule the spec was
> **amended to the measured ceiling** (`91b9eac`): High Frame-Rate preset = **46 Hz / 4 ms /
> Precision / Regular / DSS on**, hardware-confirmed at 45.86 fps with 0 frame loss;
> `ProfileEstimate.expected_delivered_fps` models the quantization and manual requests above the 1×
> ceiling warn-not-reject. The mystery of DS14879's 100 fps anchor is solved (`896c7a8`, via AN6522 +
> a decompile of ST's support-gated ProfileTuning tool, whose model reproduces the owner's tool runs
> bit-exactly): ST's "DSS Disable" is a ~106-byte status-only output mode the vendored I3C driver
> never implements and the 14,842-byte transform pipeline cannot consume; our DSS toggle is a
> ranging-quality knob only, and our hardware beats ST's own planning model (flat 26.9 ms) at every
> tested exposure. Same pass corrected `I3C_XFER_MS` to the documented 10 Mbps effective (11.87 ms —
> the 12.5 MHz-clock figure understated bus use ~25%) and replaced the fitted power model with the
> decompiled tool's exact equations (validated 5/5 owner anchors within 0.01%). **DSS: RESOLVED
> 2026-08-04, Position A upheld** (was briefly contested by a concurrent investigation) — the
> vendored driver's `platform_start/stop_csi_pipe` are `return -1` stubs never called, the board
> schematic has zero CSI/MIPI occurrences, no DSS-off-specific input shape exists anywhere on the
> transform library's interface, AN6522 ties >100 fps explicitly to "using a MIPI interface" and
> never mentions DSS, and Task 4/5 already toggled the real DSS register on hardware with no change
> to frame size or ceiling. The "CSI-2 supports DSS-off" framing traced to a transcript-summary
> mischaracterization — the concurrent session's own uncommitted notes concluded the same as
> Position A. The 46 Hz ceiling stands as final; see the handoff doc (rev 4) for the full
> adjudication.
>
> **Task 6 (Ethernet high-rate pacing, queue telemetry, CDC isolation) — code + hardware gate
> complete (2026-08-04), with two caveats.** Firmware built and flashed (165,259 B .bin;
> text 152,020 / data 13,235 / bss 177,328 — first binary on hardware, no prior build retained for a
> delta). Four 60 s operating points, **all measured over the FileHub Wi-Fi bridge — the plan's
> release gate is WIRED Ethernet, which was not available this session, so that gate is NOT
> satisfied**; every number below is bridge-measured, not a sensor or pacer ceiling:
>
> | Op point | Applied readback | fps (bridge) | interval median/p05/p95 (ms) | CRC | frag loss |
> |---|---|---|---|---|---|
> | 30 Hz Room Mapping | ambient/30fps/6ms/ULP | 29.88 | 33.45 / 33.44 / 33.46 | 0 | 0.042% |
> | 46 Hz HFR preset | precision/46fps/4ms/regular | 45.56 | 21.81 / 21.80 / 21.82 | 0 | 0.11% |
> | 50 Hz manual, 2 ms | precision/50fps/2ms/regular | 33.52 | 22.48 / 20.05 / 40.15 (bimodal, see BUG-075) | 0 | 0.08% |
> | 90 Hz oversubscribed, 2 ms | precision/90fps/2ms/regular | 44.79 | 22.30 / 22.29 / 22.30 | 0 | 0.086% |
>
> **Zero-drop gate: PASS.** `fw_tx_enqueue_drops`/`fw_tx_stack_stalls` were 0 at both start and end of
> all four runs (cumulative-since-boot counters, never reset per-run — zero-at-start-and-end is the
> correct proof); `fw_tx_queue_high_water` stayed 5–7; `fw_tx_emitted_bytes` climbed monotonically
> every poll. All fragment loss tracked the cumulative UDP `frags_lost` at ~1/70 s independent of fps
> — bridge-layer loss, not a rate-dependent firmware drop. **CDC isolation: untested, with reason** —
> this host has no privileged ST-Link VCOM access and the rig runs untethered with no USB cable
> attached, so Task 6's DATA-to-Ethernet-only-above-60-fps path and ACK-to-originating-transport
> routing are unverified on hardware; recorded as untested, not passed. Two bugs filed from this
> pass: **BUG-075** (open) — 50 Hz/2 ms manual bimodally alternates the 20.0 ms floor and its 2×
> (1211 vs 1146 intervals) instead of holding a clean 1× floor, while the profile model and readback
> both say 1×, and 90 Hz/2 ms holds a rock-steady 22.30 ms that never touches that same 20.0 ms
> floor — mechanism unexplained, `expected_delivered_fps` is unreliable for short-period/short-exposure
> combos until resolved. **BUG-076** (fixed, `56ee9ba`) — `analyze_capture`'s hardcoded `ver != 1`
> silently zeroed forensics on every protocol-v2 capture since `2b8a9ee`; see BUGS.md for the
> "second parser drifts silently" lesson.
>
> **Task 7 (IMU/env decoupled poll rate) — done (`3f4b307`, gate + BUG-077 fix `17a27d8`).** Shared
> `rs_lsm_service_tick()`, firmware cmds 11/12, decoupled TIM2-paced drains (frozen `seq`, stream 13
> only on coincident FRAME_READY), `skew_check` N:1 grouping. Bridge-measured gate passed: coupled
> mode byte-identical to Task 6's baseline; idle regression held exactly 18.182 Hz; decoupled 30 Hz
> held across Room Mapping/Precision/High Frame-Rate; decoupled 90 Hz landed 85.2 Hz with stream 10
> sub-sampled to 56.4 Hz as designed. **BUG-077 found and fixed in the same commit:** the off-cycle
> IMU/env drain ran before checking FRAME_READY, and each FIFO word is a blocking I3C transaction on
> the shared bus, so it doubled ToF frame intervals under short-margin ranging modes (Precision/30
> +4.91%, HFR/30 +14.94%; Ambient unaffected — its longer period absorbs the margin). Fixed by
> returning on FRAME_READY-first with a per-word abortable drain; re-gated at Precision/30 0.09%,
> HFR/30 0.88%. Honest residual trade: decoupled-90 IMU/env now costs Room Mapping's 90 Hz point
> ~9% (85.2 → 77.2 Hz); 30 Hz combos are unaffected. BUG-074's wake path sanity-passed via a natural
> auto-idle cycle; a full fault-injection retest is still outstanding. **Task 8 (rate-aware filters)
> — done (`d732f3a`, host-only, no hardware gate needed):** applied IMU/env rate now flows
> web → worker → `Mapper.set_imu_rate_hz`; `baro_tau_frames` is pinned in real seconds (900 @ 30 Hz /
> 2700 @ 90 Hz); `ImuFusion`'s yaw crossover takes an explicit reference-rate input instead of an
> inert constant; coupled-30 Hz behavior stays bit-identical; replay always uses each stream's own
> measured cadence, never an assumed 30 Hz.
>
> **Task 11 (MCP ranging control) — done (`1663556`).** `rig_profile()`/`rig_imu_env_rate()` verify by
> effect, waiting for their own half of the `ranging` broadcast to go pending and then settle onto the
> requested config — that message also rides the ~4 Hz metrics tick, so a merely newly-arrived one
> proves nothing, and the two halves are independent commands sharing one message. `ok=false` for
> busy/replay/validation failure/device error/unsupported CDC rate/applied mismatch, with `force=True`
> and `require_full_env=True` as the two deliberate escape hatches. Offline `profile_estimate()` shares
> the model, and the JSON vocabulary + `estimate_to_json` moved into `roomscan.profiles` so browser and
> agent cannot be told different things about one config. Verified live: High Frame-Rate read back
> 46/4 ms at 45.35 fps, restored to Room Mapping at 29.9 fps, IMU/env decoupled to 30 Hz and recoupled.
> Codex's ProfileTuning comparison landed beside it (`a418131`) with two integration fixes — a dead
> `ambient_lux` knob and a second spelling of the estimate shape.
>
> **Task 12 — ✅ DONE (2026-08-04): end-to-end validation, docs status-sync, landing, and milestone-retro.**
> Full host suite **1895 passed / 1 skipped** (the 1 skip is the expected Windows-only
> `test_logfilter` case); `ruff check` reports 4 findings, all pre-existing and in `host/tools/`,
> unrelated to this feature (`headless_doctor.py` unused import, `query_mdns.py` unused import +
> f-string-without-placeholder, `test_send.py` multi-import line). Firmware production raw-only
> Debug build is clean (`.bin` 166,107 B; text 152,868 / data 13,235 / bss 175,288).
> **Finding (plan-accuracy gap, not a blocker):** Task 12 step 2 assumes a build-time knob selects
> the onboard-transform config; no such CMake knob exists — `CONF_TRANSFORM_ONBOARD` is an
> unguarded `#define ... (0)` in `firmware/scanner-stream/Src/vl53l9_app.c` (~line 36) with no
> `target_compile_definitions`/preset wiring, so a `-D` override on the command line is a silent
> no-op and only the raw-only config is buildable without a source edit. Filed as **BUG-078**.
> **De-scoped by owner directive (2026-08-04):** *"we will never use ethernet or CDC for data
> transfer"* — read as never a physically wired link in production. The plan's **wired-Ethernet
> release gate** (Task 6 step 6) and **CDC-isolation hardware proof** (Task 6 steps 3/4) are
> therefore DE-SCOPED, not outstanding. The Wi-Fi bridge IS the production transport and it is
> proven: four 60 s Task 6 captures ran 0 CRC / 0 seq gaps / 0 incomplete frames / 0 firmware TX
> drops at 30/46/50/90-oversubscribed Hz, peaking ~9.9 Mbit/s against the 100 Mbit/s port (~10x
> headroom) — bandwidth is definitively not the bottleneck and a wired confirmation run would prove
> nothing new. **Still genuinely outstanding** (open bugs, not failures): BUG-073
> (reconfig-before-settle can drop an ACK), BUG-074 (SET_STANDBY wake shadow fixed in `3f4b307`,
> live fault-injection retest still outstanding), BUG-075 (open, 50 Hz/2 ms bimodal cadence, root
> cause unresolved). BUG-077 fixed (`17a27d8`). **Live rig sweep and browser-UI visual pass:**
> Live rig sweep (over the Wi-Fi bridge; device restored to boot default afterward): all four presets
> and manual 60/61/90/100 fps verified — Room Mapping 29.8 fps, Precision 29.9 fps
> (precision/30/10 ms/ulp), High Frame-Rate 45.4 fps (46 preset, precision/46/4 ms/regular), and
> every over-ceiling manual request ACKed but delivered a truthful period-multiple (60→29.9,
> 61→30.4, 90→44.8, 100→49.2 fps), each within ~1.5% of the model's `expected_delivered_fps`; 0 CRC
> across all; DSS auto-disables at fps≥61; I3C airtime reaches 100% at 90/100. IMU/env decoupling
> verified: 30 Hz and 90 Hz both apply, 90 Hz warns and sub-samples env to 53.5 Hz while quat/raw run
> 76.7 Hz, stream-13 coincidence per design (39% at 30/30 unlocked, 100% at 90/30); restored to
> coupled. The 30 Hz default matches the documented baseline `captures/web_20260803_121735.bin`
> within ±2% — no regression. 3–4 initial SET_* commands returned SENSOR_ERROR and cleared on a
> single retry (BUG-073). Browser-UI visual pass: four-way selector, preset apply with one-way
> (non-optimistic) state flow, manual-panel disclosure, invalid-combo rejection (validation error
> shown, no bad command sent), the "ToF bus airtime" I3C bar with three-state color escalation
> (blue→amber→red/100%), the >60 fps quantization-consequence warning, the IMU/env poll-rate control
> with its >60 Hz env-sub-sampling warning, and title-tooltip coverage on every new control all PASS;
> server-side second-client sync-on-connect verified. Two checks were tool-limited and honestly not
> performed: a truly rendered second tab, and a narrow-viewport resize (the ui_* screenshot tool
> would not change the viewport; narrow-width has a prior verification in
> `docs/web-ui-testing.md`). **One real defect found by the pass and filed + fixed same session as
> BUG-079** (`controls.js` `manualDirty` guard, live-verified — a 45 fps edit held through a 700 ms
> sample window and the full precision/45/4 ms/regular config round-tripped onto the device)**:** the
> Manual fps/exposure number/slider widgets cannot apply a changed value — `web.py`'s 250 ms periodic
> `ranging` re-broadcast outruns `controls.js`'s 300 ms `MANUAL_DEBOUNCE_MS` and reverts the field
> before it sends (presets, the IMU/env control, and `set_manual_params` over `/ws` are all
> unaffected). Full resume state:
> `docs/superpowers/plans/completed/2026-08-03-high-framerate-implementation-handoff.md` (rev 5).
>
> **Device robustness** (Task 5): `rs_send_event()` emits EVENT frames
> (`SENSOR_INIT_FAIL`/`TRIGGER_TIMEOUT`/`DMA_TIMEOUT`/`SENSOR_ERROR_STATUS`) on every fault path,
> replacing reference-firmware bug #2's silent infinite spin — **bug #2 (above) is now fixed in our
> fork** for the raw-only build. Bounded recovery: up to 5 re-init attempts, 100 ms→1.6 s backoff,
> shared by both the boot path and runtime `handle_error()`; a successful recovery retransmits CALIB and
> resumes streaming (seq restarts — a documented, host-tolerated discontinuity, not an error). **Boot
> soak: 10/10** consecutive SWD resets reached streaming, both before and after the final commit
> (historical baseline ~80% first-attempt success). Live recovery exercised via a temporary,
> since-removed fault-injection hook across 9 forced faults plus 1 hook-independent natural fault, all
> recovering within ~2 s (EVENT → CALIB retransmit → seq restart → clean streaming). One anomalous
> ~100 s hang on the very first post-flash boot did not reproduce in any of the 9 subsequent runs
> (including one with an identical fault signature) — disclosed honestly, not root-caused, tracked below.
>
> **Connect-time transient — root-caused, characterized-cosmetic** (Task 6,
> `docs/connect-transient-forensics.md`): byte-exact forensics over both e2e captures found the
> *identical* signature in each — a well-formed `RAW_3DMD seq=1` header truncated ~2.8 KB short by the
> pre-existing `rs_cdc_send()` 100 ms mid-frame-abort policy, racing host-startup latency on connect (not
> stale TX FIFO residue, not a DTR race, not the separate mid-stream-reattach bug). Costs exactly one RAW
> frame, self-heals with no seq gap, never recurs — no wire or firmware fix needed. The **CALIB-on-DTR-
> connect** item (mid-stream reattach discarding up to 63 blind-start RAW frames) remains open — see the
> deferred list below.
>
> **Host — viewer keys + config persistence** (Task 7, this entry): `roomscan-view` now opens an
> `o3d.visualization.VisualizerWithKeyCallback` window wired to a `CommandClient` on the same open serial
> port (live mode only — `--replay` prints "not available in replay" for every key press, verified). Each
> key press runs on a fire-and-forget worker thread so the render loop never blocks on `send()`'s
> up-to-2 s timeout, guarded by a single busy flag that rejects a second press while one command is still
> in flight (prints `busy, command already in flight`, verified live with a rapid double `R` press).
>
> | key | command | live-session result observed |
> |---|---|---|
> | `P` | PING | `ping -> OK applied=1` |
> | `C` | SEND_CALIB | `calib -> OK applied=0` |
> | `1` | SET_USECASE 0 (AR_RANGE) | `usecase 0 -> OK applied=0`; HUD fps rose into the ~32 fps band |
> | `2` | SET_USECASE 1 (AR_PRECISION) | `usecase 1 -> OK applied=1`; HUD fps returned to the ~28 fps band |
> | `R` | REINIT | `reinit -> OK applied=0`; brief fps dip (~21 fps) then clean resume; a second `R` pressed before the first completed correctly printed the busy line instead of double-sending |
>
> `roomscan.toml` (`%APPDATA%/roomscan/roomscan.toml`, one `[viewer]` table) persists `color`/`fov_h`/
> `fov_v`/`replay_fps`/`port`. Read with stdlib `tomllib`; written by a small hand-rolled TOML emitter (no
> third-party TOML-writer dependency taken — see `host/src/roomscan/config.py`). `--save-config` writes
> the effective settings. Priority: **CLI flag > config file > built-in default**, implemented via
> argparse's `None` sentinel + `apply_config_defaults()`.
>
> **60 s soak** (Task 7, [HW], immediately following the key session above, board left on the default
> AR_PRECISION profile): observed for 131 consecutive 1 Hz HUD samples (>2× the required window) —
> steady **27.6-29.1 fps** (one transient 21.0 fps sample during the preceding REINIT's settle, not part
> of the steady-state band), **0 new seq gaps** and **0 new CRC failures** for the entire session (the
> single CRC failure and the stable `raw-skip 44` present throughout are the pre-existing, already-tracked
> connect-time transient and mid-cycle-attach behavior, not new occurrences).
>
> Suite: **97 passed** (73 baseline + 15 `config.py` tests + 9 viewer-key/command-routing tests).
>
> **Deferred / honestly open** (not blockers for calling Phase 3 done):
> - **CALIB-on-DTR-connect auto-fix** (device aborts any in-flight frame and sends CALIB immediately on
>   DTR rising, via `tud_cdc_line_state_cb`): evaluated Task 6, needs new synchronization between a
>   TinyUSB callback context and the main loop's send/trigger state — not small/safe enough to land in
>   Phase 3. Specced as a Phase 3/4 follow-up. `SEND_CALIB` (the `C` key / `roomscan-ctl calib`) is the
>   shipped manual mitigation for the same blind-start problem.
>   **Implemented 2026-07-30, UNVERIFIED (BUG-005).** The synchronization turned out to be reentrancy,
>   not concurrency: TinyUSB dispatches class callbacks from `tud_task()`, not the ISR (verified in the
>   vendored `usbd.c`), so one volatile flag set in the callback and consumed at the loop's existing
>   per-frame safe point is enough. Cannot be exercised on the current headless host — the board's
>   USB_USER port is not attached to it (`lsusb` shows only the ST-LINK), so `CAFE:4001` never
>   enumerates and there is no DTR to raise. Verified only that it leaves the Ethernet path intact
>   (30.3 fps, 0 CRC, 0 gaps); see BUGS.md BUG-005 for the verification recipe on a USB-attached box.
> - **`SET_FRAME_PERIOD_US` is a spec-compliant no-op** in this app's always-manual-sync design (see the
>   fps table above) — the command does exactly what the protocol promises (apply + read back), it just
>   doesn't control fps here; would need an autonomous-sync redesign to matter.
> - **One 100 s post-flash boot-recovery hang** (Task 5) was observed once, did not reproduce in 9
>   subsequent identical-scenario runs, and was not root-caused — tracked as a low-confidence anomaly,
>   not a confirmed defect.
> - **AF_RANGE / AF usecases are unusable** at the project's fixed full-resolution binning-2 constraint —
>   an owner-scoped design decision (binning stays fixed at 2 for all of Phase 3), not a bug.

Host→device **control channel** to set usecase / binning / active streams at runtime. Recording/playback
and config persistence host-side.

- **Assumption corrected by the Task 7 capture:** the transform library's `controls` are only
  `bypass-*` algorithm toggles + `calib-buffer` + `cover-glass` — there is **no runtime usecase or
  binning control**. Usecase/binning are sensor-profile settings applied before init
  (`vl53l9_utils_set_profile`), so runtime reconfiguration means a full stop → re-profile →
  re-prepare → restart cycle on the device (which also forces the teardown path of reference bug #6 to
  work). Plan Phase 3 around that, not around a transform control write.

- Control frames reuse the same header (`frame_type` = command / ack); device replies with an ack frame
  carrying the applied config — the host never assumes.
- Reconfiguration path forces the teardown/re-prepare sequence to actually work (see reference bug #6):
  stop ranging → free/resize buffers (binning changes both raw and output sizes) → re-set capabilities →
  `transform_prepare` → restart. Watch for leaks in the opaque transform handle across cycles.
- CDC RX side appears here for the first time — until now the device only transmits.

### Phase 3.5 (interlude) — GUI control panel + 2D IR monitor ← **✅ Complete**

Plan: `docs/superpowers/plans/completed/2026-07-09-phase3.5-gui-panel.md`, branch `phase3.5-gui-panel`. Owner
elected this next (2026-07-09), deferring Phase 4 (IKS4A1). Replaces the classic keyboard-only Open3D
window with an `open3d.visualization.gui` control panel — `roomscan-panel` (or `roomscan-view --panel`);
the classic `roomscan-view` window stays the default. Presentation layer only: `TransformStage`,
`CommandClient`/`CommandDispatcher`, `Deprojector`, `sources`/`pump`, `config`, `Stats`/`StreamDecoder`
are all reused unchanged (no wire change; `docs/protocol.md` untouched).

- **Panel groups:** Status (fps/frames/gaps/drops/crc/raw, usecase+color), Device (Ping/CALIB/Reinit
  buttons, usecase combobox, debounced exposure slider — all via the shared `CommandDispatcher`, so keys
  and buttons run one busy-guarded off-thread dispatch path), View (color mode, point size, background,
  reset-view), **IR Monitor** (scope addition — a live 2D reflectance image, nearest-neighbor upscaled
  from the 54×42 zone grid, gray/turbo, per-frame auto-range with a freeze toggle, "IR unavailable"
  placeholder on depth-only replay), Capture (mid-stream Record via a `Recorder` tee; replay pause +
  fps slider), Events (scrolling device-EVENT / command-result log via an in-process `LogBus`).
- **Threading:** render on the GUI main thread via `Window.set_on_tick_event` (polls the reader's
  latest-wins slot; labels/IR/log at ≤4 Hz); reader thread + command worker threads keep serial writes
  off the reader per the standing contract.
- **Support layer:** five file-disjoint TDD'd modules — `ir_image.py` (reflectance→RGB), `logbus.py`,
  `config.py` (+`point_size`/`ir_colormap`/`ir_freeze_range`/`panel_width`), `sources.py` `Recorder`,
  `control.py` `CommandDispatcher`.
- **Owner-requested follow-ups (2026-07-09):** (1) **Near contrast** (`roomscan/shading.py`) — for
  the person-in-front-of-wall setup, spends more of the colormap on close targets so facial relief
  stands out: `window` (default, greys past a cutoff), `emphasis` (near gamma), `equalize` (histogram),
  `off`; View-group combobox + adaptive slider. (2) **Point size** slider widened 1→20, default 3→5, to
  close the inter-zone gaps. (3) **Modal help** (`Help`/`H` → `gui.Dialog`). (4) A **headless snapshotter**
  `tools/panel_view.py` (Pillow, CPU) that renders the panel to a PNG — Open3D Filament offscreen fails
  on a locked box (`EGL Headless not supported`) — so the panel can be *seen* without a display.
- **Verified:** host suite 162 passed, ruff clean; headless `run_one_tick` smoke against
  `captures/e2e_p2.bin` rendered 194 frames (2257-pt cloud), reflectance present, IR auto-range + freeze,
  all callbacks functional, reader thread joins clean. The formerly-open live on-hardware run is
  **✅ closed** — merged 2026-07-09 (branch `phase3.5-gui-panel`, since deleted) and the panel has been
  the primary live surface for all Phase 4 hardware work since (IKS4A1 bring-up, sensors group,
  yaw-fusion checks), including per-frame IR rendering (`7006dc5`-era perf fix on the metrics-HUD
  branch). Known cosmetic: an Open3D filament-teardown "Fatal Python error" can print at interpreter
  exit (post-functional).

### Phase 3.6 (interlude) — Web UI Migration (FastAPI + Three.js) ← **✅ Complete**

Plan: `web_app_migration_plan.md`. Owner elected to deploy the visualizer to a headless server accessed remotely via Tailscale. The native Open3D UI fails in a locked/headless environment without a display.

- **Architecture (Option A: True Single Codebase):** `roomscan-web` entry point spins up a FastAPI/Uvicorn server running the exact same `TransformStage` reader thread as the desktop viewer. The server exposes a `/ws` WebSocket endpoint that streams the transformed point cloud and color data to the browser as a packed `Float32Array`. 
- **Frontend:** ~~A premium glassmorphic web UI (`index.html`, `app.js`) running Three.js handles the point cloud rendering on the local browser's GPU. Control elements (Ping, Reinit, Usecase selection) send JSON commands back through the WebSocket to the `CommandKeyState` dispatcher.~~ **Superseded by Web Phase 1 (below, 2026-07-16):** the monolithic `app.js` is retired in favour of 7 vanilla ES modules, and the single binary point-cloud message is now a multiplexed, tagged protocol. The single-`app.js` / single-message shape described here was the minimal first cut.
- **Bandwidth:** The WebSocket streams processed points rather than RAW data. With decimation running, bandwidth sits comfortably below Tailscale's limits.
- **Verified:** Dependencies added to `[web]` optional group. Ran headless test successfully against `synthetic.bin`; the server boots on port 8000 and serves the static Three.js payload.

### Web replacement of `panel.py` — a 5-phase program (Three.js web app supplants the Open3D desktop panel)

Owner direction (2026-07-15): the web app **fully replaces** the ~3600-line Open3D `panel.py`, delivered in
phases — (1) core real-time instrument, (2) sensors (IMU/env streams 9/10), (3) recording & playback,
(4) SLAM mode, (5) settings persistence + retire `panel.py`. **All five phases are done (2026-07-16):**
`roomscan-web` is now the primary, supported UI and `panel.py` is **deprecated in place** — kept only as
legacy for a local-display box (it can't run on the GPU-less headless host), no longer imported by the web
server, and it prints a deprecation notice on launch.

**Parity gap found after the fact (2026-07-28, BUG-026):** "fully replaces" was not quite true — **gravity
alignment of the live view was never ported**. It existed only in `panel.py` (IR pane via `ir_gravity_rot`,
orbit-mode cloud via `T_WORLD_TO_CV @ R @ T_CV_TO_BODY`), so booting the board upside down rendered both the
IR pane and the point cloud upside down in the web app. The orientation matrix was already on the wire as the
`sensor` message's `rot`, but only the 2D gizmo consumed it. Now fixed with continuous full alignment
(desktop-panel parity, owner's choice), plus a coherence-gated **display-only** smoother, because rotating
the cloud by the raw quat swings sensor noise on the scene's lever arm. That in turn surfaced BUG-027
(firmware aliasing) — the two are worth reading together. Wire semantics in `docs/web-protocol.md`; when
auditing the rest of the panel's feature set for other unported behaviour, this is the precedent that it can
happen silently. **And the precedent has a second lesson (2026-07-29):** porting the panel's behaviour
*verbatim* was itself not enough — the panel rolled the IR pane in 90° snaps, so once the cloud got
continuous alignment the two disagreed by up to 45° and the pane ignored moderate tilts entirely. Parity
with a deprecated implementation is a starting point, not the specification; check that the ported
behaviour is still coherent with whatever the new code does alongside it. Fixed by splitting the roll into
the server's quarter-turn snap plus a client-side `ir_roll_deg` residual (BUG-026 follow-up).

**"Showcase" is not a separate phase (owner clarification, 2026-07-16):** the earlier plan listed a 6th
"showcase mode" phase, but Showcase was only ever **another name for SLAM mapping** — the record → build →
save flow — a naming artifact from earlier in the project. The desktop panel already dissolved it ("SLAM
absorbs the former Showcase record→process→reveal flow — no separate Showcase concept in the UI", Phase 6
below), and the web app **already delivers it** across Web Phases 3 (record + load/replay a capture) and 4
(SLAM builds the full map + **Save** the full-res mesh/trajectory). So the web plan is **5 phases, not 6**;
the only remaining work is settings persistence + retiring `panel.py`. (The lone desktop-Showcase nicety
not yet in the web app is a *guaranteed-every-frame* offline post-process with a sharpening "reveal";
Web Phase 4's replay-fed SLAM already processes every frame when a capture is replayed at ≤30 fps, so this
is at most a small option inside SLAM mode, not a phase — fold it into Phase 5 only if the owner wants it.)

#### Web Phase 1 — Core Real-Time Web Instrument  ← **✅ Complete (2026-07-16)**

Spec: `docs/superpowers/specs/completed/2026-07-15-web-phase1-core-instrument-design.md`. Host-side only — no wire-protocol
or firmware change. Confined to `host/src/roomscan/web.py` + `host/src/roomscan/static/` + `host/tests/test_web.py`.

- **Frame-stealing bug fixed:** the old per-connection `slot.get_nowait()` loops (two tabs stole each other's
  frames) are replaced by a **single asyncio broadcast task** fanning identical frames to all clients; reuses
  `panel._run_reader` (no forked reader). Regression-tested with two concurrent `websockets` clients.
- **Multiplexed `/ws` protocol:** tagged little-endian binary — POINT_CLOUD (tag 1), IR_IMAGE (tag 2) — plus
  `metrics`/`event`/`log`/`cmd`/`state` JSON, split client-side by `typeof event.data`.
- **Four user-facing features:** working device controls with visible feedback (toast + event-log console),
  runtime color modes (depth/reflectance/confidence — `stage` computes all three, switch is pure server state),
  live IR monitor pane, metrics HUD (VIEW fps client-side + Device fps + per-stream rate/jitter + link bandwidth).
- **Frontend:** 7 vanilla ES modules (`ws`/`scene`/`ir`/`hud`/`log`/`controls`/`app`), no build step, importmap +
  vendored three.js; one-way state flow through the `ws.js` pub/sub hub keeps multi-tab state in sync.
- **Verified:** 26 backend tests (`test_web.py`); full host suite **606 passed, 1 skipped**. Driven end-to-end in
  headless Chrome (SwiftShader) against a room-scan replay — all four features confirmed on screen.
- **Caveat (data, not code):** dual-stream recordings (RAW_3DMD + redundant DEPTH_ZF32 passthrough) intermittently
  fall the IR pane / reflectance colour back to depth, because the DEPTH frame lands last in the latest-wins slot.
  Live production streams are RAW-only, so unaffected; a "prefer-richest-frame" tweak is a future option.
- **Deferred to Web Phases ~~2~~ 3–5:** recording/playback UI, SLAM trajectory+mesh
  (adds a MESH binary type + a top-bar mode switch, placeholder reserved), settings persistence, and retiring
  `panel.py`. Also not yet carried over: exposure slider, rotate-90 / near-contrast view options. *(Showcase,
  once listed here, was a misnomer for SLAM mapping — see the plan header; delivered by Phases 3–4.)*

#### Web Phase 2 — Sensors (IMU/env streams 9/10)  ← **✅ Complete (2026-07-16)**

Spec: `docs/superpowers/specs/completed/2026-07-16-web-phase2-sensors-design.md`. Host-side only — no wire-protocol
or firmware change. Confined to `web.py` + `static/` (new `sensors.js`, extended `app.js`/`index.html`) +
`test_web.py`.

- **Reuse, don't reimplement:** `web.py` now builds the same `SensorState` + `YawFusion` + `MagCalibration`
  the desktop panel does (`panel.py:525-541`) and feeds it through the shared reader by filling the
  `_run_reader(state=…)` slot Web Phase 1 left as `None`. The message builder calls the existing `sensors.py`
  math (`quat_to_matrix`, `T_WORLD_TO_CV`, `T_CV_TO_BODY`, `absolute_heading`, `AXIS_CONVENTION`) — nothing in
  `sensors.py`/`magcal.py`/`protocol.py`/`panel.py` was edited.
- **Protocol:** one new JSON message `{"type":"sensor", …}` on the existing `/ws` (no new binary tag — the
  payload is tiny): server-computed display-rotation `rot` (9-float row-major `T_WORLD_TO_CV @ R @ T_CV_TO_BODY`),
  `heading` (drift-free `absolute_heading`, calibrated mag when `mag_cal.json` present), pressure/temp/mag,
  `fusion` status, and 256-sample pressure/temp history. Broadcast at 15 Hz from the single broadcaster task;
  **silent until a 9/10 frame arrives** (`build_sensor_message` returns `None`), so ToF-only sessions add no traffic.
- **Frontend:** new `sensors.js` module (2D-canvas — no second WebGL context, keeps the headless SwiftShader box
  cheap) draws an orientation gizmo, a tilt-compensated compass (0=N clockwise), and pressure/temp sparklines,
  appended to the left rail per the Phase-1 layout plan. Streams 9/10 also light up the metrics HUD's IMU/Env
  rows for free (`metrics.py` already labels them).
- **Verified:** 4 new backend tests (`build_sensor_message` shape/units + display-transform equivalence + reader
  integration); full host suite **610 passed, 1 skipped**. Driven end-to-end in headless Chrome against a
  synthetic depth+IMU+ENV replay — gizmo, compass (heading tracked frame-exact), and sparklines all confirmed on
  screen; server log clean.
- **Not carried over (deferred):** world-frame point accumulation + baseline-yaw reset (revisit with SLAM,
  Web Phase 4), SHT40 humidity (unstreamed), on-rig mag-recalibration UI.

#### Web Phase 3 — Recording & Playback (full-remote)  ← **✅ Complete (2026-07-16)**

Spec: `docs/superpowers/specs/completed/2026-07-16-web-phase3-recording-playback-design.md`. Host-side only — no
wire-protocol or firmware change. Confined to `web.py` + `static/` (new `capture.js`) + one additive
`FileSource(start=)` param in `sources.py` + `test_web.py`. Owner picked **Full remote** over
desktop-parity: the app runs remotely on the headless box, so the operator browses and loads captures
**from the browser**, not by relaunching with `--replay`.

- **Runtime source-swap (the hard part):** a new `SessionController` owns the reader-thread lifecycle so
  the source can be swapped **live↔replay at runtime** without disturbing the single broadcaster or the
  shared slot. The live device is opened once and kept behind a `_NoCloseSource` proxy (pump's
  `finally: close()` can't kill it), so **Go Live re-uses it instantly** (no 5 s UDP re-probe). Swaps run
  off the event loop via `asyncio.to_thread`, serialized by a lock; the reader body is the **unchanged**
  `panel._run_reader`.
- **Four capabilities:** (1) **Record** a live session → `captures/web_<ts>.bin` with live elapsed/bytes
  status (disabled in replay); (2) **capture library** — server lists `captures/*.bin`, browser picks;
  (3) **load at runtime** → reader swaps to replay, `Go Live` returns; (4) **transport** — Pause/Resume,
  speed ×0.5/×1/×2/Max, Loop, and a **seekable progress bar**. Seek re-injects the governing CALIB (from a
  CRC-verified capture index of frame offsets/seqs/calib-spans) so scrubbing into a RAW capture isn't blank.
- **Protocol:** two new `/ws` JSON messages — `session` (mode/source/recording/playback, broadcast on change
  + metrics cadence) and `captures` (library list) — plus inbound `record`/`list_captures`/`load_capture`/
  `go_live`/`transport`. No new binary tag. Commands in replay report "not available in replay" (no device
  round-trip). Frontend: new `capture.js` (8th ES module), all state driven from the server echo (one-way
  flow), no build step.
- **Verified:** 20 new backend tests (index/sanitize/list/session helpers + `SessionController` swap, record
  gating, live-record tee, seek); full host suite **625 passed, 1 skipped**. Driven end-to-end in headless
  Chrome against a synthetic capture library — record-disabled-in-replay, library listing, runtime load/swap,
  pause (position frozen), speed (Device FPS tracked the ×-setting), loop, and seek all confirmed on screen.
- **Deferred (at the time — Web Phases 4–5):** SLAM trajectory+mesh (**done, Phase 4**), then settings
  persistence + retiring `panel.py` (Phase 5, final). Serial-staleness on Go Live is mitigated by a
  best-effort `reset_input_buffer`; UDP self-heals via keepalive.
- **`/ws` protocol reference:** the full app protocol (binary tags + JSON messages, in/out) across Web Phases 1–3
  is now indexed in `docs/web-protocol.md` — Phase 4's trajectory/mesh messages hook in there (it also lists the
  invariants: one-way echo, validate untrusted inbound, server-side math, off-loop blocking work).
- **Post-recording naming (owner ask, 2026-07-29):** every stopped take now pops a skippable "Name Recording"
  modal in `capture.js`, prefilled with the auto `web_<ts>.bin` name. Save sends a new inbound `rename_capture`
  (`SessionController.rename_last_recording` / `sanitize_new_capture_name` in `web.py`); success/failure is read
  back off a new `session.recording.last_name` field rather than a dedicated ack, since the server already owns
  collision/validity checks. Skip/Esc/backdrop-click leaves the auto name — never blocking, the file is on disk
  either way. Verified end-to-end in headless Chrome (open-on-stop, save, collision rejection, skip); full host
  suite 961 passed, 1 skipped.
- **Discoverable Go Live (owner ask, 2026-07-29):** returning to live view only ever worked by clicking the
  "● Live device" row buried in the Source list — easy to lose once scrolled past mid-playback, and the owner
  hit exactly that dead end. Added a dedicated **"● Go Live"** button to the transport panel itself (`capture.js`
  / `index.html`), sending the same existing `go_live` message the row already did (`SessionController.switch_to_live`,
  unchanged); gated on `session.has_live` like the row. Verified in headless Chrome (renders, correctly disabled
  with no live source); full host suite 971 passed, 1 skipped.

#### Web Phase 4 — SLAM mode  ← **✅ Complete (2026-07-16)**

Spec: `docs/superpowers/specs/completed/2026-07-16-web-phase4-slam-design.md`. Host-side only — no wire-protocol or
firmware change, **and no edits to `slam/`**. Confined to `web.py` + `static/` (new `slam.js`, extended
`scene.js`/`app.js`/`index.html`) + `test_web.py`. Owner decisions: **GPU-accelerated** and **include a web
Save button**.

- **Reuse, don't reimplement:** a new `SlamRunner` in `web.py` wraps the desktop's own off-thread pipeline —
  `make_slam_worker` (local **CUDA:0** worker; remote `SlamService` if `[slam] backend=remote`) + `MeshPrep` —
  **unchanged**. Fed from the broadcaster only while `mode == "slam"` (no GPU burned in real-time), latest-wins
  so a slow frame never backs up the loop; all enter/leave/reset/save run off the event loop.
- **Compute is the LOCAL GPU** (discovered this session): the Proxmox host passes an **RTX 2000 Ada** through
  to the container, Open3D 0.19 reports CUDA, SLAM runs in-process at **~7 ms/frame** — no remote container
  needed. (The `headless-host-deployment` "no GPU" note is superseded for compute; X/VNC GL + the test-Chrome
  WebGL are still software.)
- **Protocol:** new binary **MESH (tag 3)** — a flattened `MeshPacket` (wall/non-wall verts+colors+tris + floor
  grid, throttled) — plus a `slam` JSON per frame (pose, server-computed follow eye/center/up, downsampled
  trajectory tail, fitness/rmse/tracking/frames) and a `saved` list; inbound `set_mode`/`slam_opt`/`save`.
  Save writes the **full-res** `mapper.mesh()` + TUM trajectory to `results/web_<ts>.ply`/`.tum`, downloadable
  from a `/results` mount. All in `docs/web-protocol.md`.
- **Frontend:** new `slam.js` (9th module) renders the mesh (unlit vertex-colored — shading is baked
  server-side by `MeshPrep`) + trajectory + head marker into `scene.js`'s **single** Three.js context, and
  drives a follow camera; top-bar Real-Time↔SLAM switch, SLAM control group (trajectory/walls/follow + Save +
  saved-maps list), and a SLAM HUD row. All state driven from the server `state`/`slam`/`saved` echo.
- **Verified:** 12 new backend tests (`pack_mesh` round-trip, `slam` shape + traj bound, `sanitize_result_name`,
  `list_results`, `SlamRunner` lifecycle with fake worker/meshprep, save + empty-map raise); full host suite
  **637 passed, 1 skipped**. SLAM pipeline de-risked on GPU (`roomscan-slam --device CUDA:0`, 329-frame stream-9
  capture → lost=0, ~30k-vertex map) and driven end-to-end in headless Chrome against `captures/verify_slam.bin`:
  mode switch, live mesh build (Tracking OK, Fitness 0.85, RMSE ~11 mm, frames climbing), follow camera, walls
  Split/Solid, and Save → a downloadable `.ply`/`.tum` — all confirmed on screen.
- **Verification-data note:** SLAM needs a **stream-9 (IMU quat) capture** — the older
  `recordings/2026-07-08-room-scan.bin` predates IMU and loses tracking (empty map). `captures/verify_slam.bin`
  (recorded live this session, gitignored) is the fixture.
- **Remaining web work (Web Phase 5, final):** ✅ **done** — see below. (Showcase is **not** a separate phase — it
  was a misnomer for SLAM mapping, already delivered by Phases 3–4; see the plan header.)

#### Web Phase 5 — settings persistence + retire `panel.py`  ← **✅ Complete (2026-07-16)**

Host-side only — no wire-protocol, firmware, or `/ws`-message change. Owner decisions (2026-07-16):
**deprecate `panel.py` in place** (don't delete) and **persist to the shared `roomscan.toml` [viewer]` table**
(one config across web + desktop).

- **Settings persistence.** The web UI's six display prefs — `color`, `ir_colormap`, IR `freeze`, and the three
  SLAM display toggles (`trajectory`/`walls`/`follow`) — now live in the same `roomscan.toml` [viewer]` table the
  desktop viewer/panel already used. Three new flat fields were added to `ViewerConfig` (`slam_trajectory`,
  `slam_walls`, `slam_follow`); `web.ui_from_config` seeds `UiState` on boot (validating each value, falling back
  to the UiState default on anything unrecognized), and `web._persist_ui` writes each runtime change straight back
  — it **re-loads the file first** so a concurrent editor's non-web fields survive, and swallows write errors with
  a warning (a color click must never crash on an unwritable config dir). Persistence is a no-op when no config is
  attached, so the socket-free unit tests are unaffected.
- **`mode` is deliberately NOT restored.** The SLAM worker arms lazily on the first `set_mode slam` (no GPU burned
  until then), so a server restart always comes up in real-time regardless of the last session — restoring into
  SLAM would silently spin up the GPU on launch. The web app never writes the [viewer]` `mode` field; the desktop
  panel keeps owning it.
- **Behaviour note:** a fresh web install (no config file) now adopts the shared `color` **default**, which is
  `reflectance` (the desktop default, falls back to depth when the plane is absent) — not the old web-only `depth`.
- **`panel.py` deprecated in place.** The three GUI-free helpers the web server borrowed from the panel
  (`_run_reader`, `_Pacer`, `follow_camera_target`) plus their follow-camera constants moved to a new neutral
  **`reader.py`**; `panel.py` re-imports them (so `panel._run_reader` and its tests still resolve) and `web.py`
  now imports from `reader.py` and no longer imports the panel module at all. `roomscan-panel` and
  `roomscan-view --panel` print a one-line deprecation notice on launch; the panel is kept only for a
  local-display box (it can't run on the GPU-less headless host). `roomscan-web` is the primary, supported UI.
- **Verified:** 8 new backend tests (config field defaults + TOML round-trip, `ui_from_config` valid/invalid/mode
  mapping, `apply_ui_to_config` preserves desktop-only fields, `_persist_ui` write + no-op, `set_color` handler
  end-to-end); full host suite **645 passed, 1 skipped**. Driven end-to-end against two real `uvicorn` servers: a
  `/ws` `set_color` wrote `roomscan.toml`, and a **restarted** server seeded a fresh client's very first `state`
  message from it. No frontend change — the existing `state` echo already drives the UI, so persisted values reach
  the browser through the unchanged connect handshake.

#### Web Phase 6 — UI corrections pass  ← **✅ Complete (2026-07-31)**

Owner-driven round of UI fixes after living with the Live/View consolidation. Six commits
(`df28686`, `2399afa`, `61b96ac`, `66ea675`, `2dbcbcb`, `7d5ffe6`), **1327 passed / 1 skipped**.

- **Explain the instrument.** Drops/Gaps/FPS/Bandwidth and every per-stream row now carry
  tooltips (keyed on `stream_id`, not `label` — `metrics.py` maps two ids onto "ToF"). The Fusion
  row names a remedy for each `fusion_key`, not just the fault. `body { user-select: none }` was
  making every diagnostic uncopyable; ~~`#diag-log`~~ (the diagnostics pane was folded into the event
  log, 2026-08-05, BUG-080), the event log, the quat and the jitter table opt back in.
- **Declutter.** The right-rail IR group duplicated controls the IR card already had inline — gone;
  its × now collapses into the squircle rail rather than hiding with no way back. The orientation
  decomposition picker is gone and the card is pinned to **World**, which also fixed the axis
  labels: World's slots are triad roll, boresight tilt from horizontal, and absolute magnetic
  heading, so "Pitch"/"Yaw" named the wrong quantities. A one-time migration adopts the new labels
  for configs still carrying the old default (`_persist_ui` writes every field on any change, so the
  stale default would otherwise shadow the new one forever).
- **The squircle rail** is now a map of every panel — permanent buttons, bright when open and dim
  when collapsed, with matching icons injected into each card title from the same `CARD_ICONS` table.
- **A real device model.** `devicemodel.js` is the single source for the owner's 5.5 × 3 × 2.5 in
  block (dark grey / white / blue through the depth, camera on the blue face), shared by the mag-cal
  3D view and a new 2D painter for the Sensors gizmo (2D canvas, not a third WebGL context — this
  host is llvmpipe). `MOUNT_ROTATION` is a 180° turn about the boresight, derived from World roll
  being `triad_roll_deg` of body +X and corroborated by the live rig reading Roll 179.66°.
- **Mag-cal is one view, not two** — the world-fixed steering framing carrying the hero's cell
  styling. This *re-accepts* a tradeoff `magcal3d.js` had explicitly rejected (a body-fixed shell
  under a room camera has its holes orbit at hand speed); the mitigation is that the ghost and the
  leader line become the aiming instrument. `heroCam` is kept as the no-quaternion fallback, or a
  ToF-only session renders an empty canvas. The behind-camera split is now per-pose: 0.062 ms per
  recompute under a synthetic 90 °/s tumble.
- **Elevation replaces pressure** — feet, with hPa beside it and a Δ datum button (persisted).
  Sea-level reference from Open-Meteo, the app's **first outbound third-party request**: stdlib
  `urllib` in a thread, one GET per 30 min, cached, with a visible `msl_source` so a fallback is
  reported rather than hidden. EMA'd at 6 s because the barometer is 267 mm RMS per frame (BUG-037);
  the sparkline is left unsmoothed on purpose.
- **Resource headroom during Live SLAM.** `build_metrics_message` had hardcoded `resources: None`.
  Now wired, plus system-wide RAM/CPU (psutil) and **device-wide** VRAM via the ctypes NVML in
  `slam.gpumem` — `pynvml` is not installed, so every per-process GPU field would have been null.
  The VRAM figure deliberately exceeds `nvidia-smi memory.used` (370 vs 18 MiB) because NVML counts
  driver-reserved memory, which for a headroom gauge is spoken for. Also surfaces the **TSDF block
  gauge** — the ceiling that silently killed 18% of a real sweep (BUG-035) — sampled at the metrics
  rate, since `block_usage()` is a device sync on CUDA.
- **Auto-record on entering Live SLAM**, because a live scan is unrepeatable (the same reasoning
  that kept its one-shot Save, BUG-043). A manually started take is tracked separately and never
  stopped by a display switch.
- **Oscillate orbit** — a triangle wave sweeping ±N about the start azimuth. Two traps: the azimuth
  wraps at ±π (unwrapped per-frame steps, or any amplitude ≥ 180° latches — measured 0 reversals in
  1200 frames), and direction must not live in the sign of `autoRotateSpeed`, which the `state` echo
  overwrites on every unrelated setting change (measured: the return leg vanished entirely).
- **Live is one Record button; View is a real capture browser** — thumbnails, metadata, rename,
  multi-select delete, and a first-class **Preview** display mode. The Build action now opens a
  confirmation dialog with capture/frame/compute details and the active Detailed estimate (honestly
  marked uncalibrated until CUDA timing is measured); it then loads the capture, starts the build,
  and enters Detailed. Playback starts at **1×** by default. Thumbnails are a top-down sketch from
  ~40 sampled frames rotated by
  stream 9; **it is not a map** (no translation estimate, so every frame shares one origin) and the
  tooltip says so. 51 ms/file across the real 1.49 GiB library, reading 0.161% of a 408 MB capture.
  Served over `GET /thumb/{name}` rather than a `/ws` tag so `<img loading="lazy">` gives paced
  fetching and caching for free. "Area covered" is a floor-projected footprint, not mesh surface
  area, which would score a corridor above a large room. **Turbo/Gray now applies equally to Point
  cloud, SLAM, and Detailed**; the latter two re-map their presentation mesh only, never the
  reconstruction or sidecar.

**Bugs found and fixed here:** **BUG-047** (`id="btn-restart"` named two buttons — playback Restart
was dead *and* "Restart Server" fired a transport restart first) and **BUG-050** (recording
`elapsed_s` was `time.time() - time.monotonic()`; a 90 s take reported 1.78e9 s, and it survived
because the tests asserted the value was a *float*).

#### Web Phase 7 — Live-SLAM throughput  ← **✅ Complete (2026-08-02)**

> **BUG-060.** The owner reported Live SLAM's viewport updating at ~1 Hz on a 144 Hz display fed by
> a 30 Hz stream, with the GPU at 0% / 10 W. The GPU was idle because it was only being *asked* for
> ~5 frames a second: `uvicorn.run()` defaults `ws_per_message_deflate=True` and `_broadcast_bytes`
> awaits `send_bytes` **per client**, so every 3.2 MB MESH was zlib-deflated once per connected tab,
> synchronously on the event loop — **+130 ms of whole-process freeze per client, +0 ms for clients
> negotiating no compression**, and six were attached. A plain HTTP probe stalling by the same
> ~780 ms as `/ws` is what proved the loop itself was frozen rather than the client being slow.
>
> Because `SlamRunner.submit()` ran only from that frozen broadcaster, the mapper was fed 5.00 fps
> against a 30.3 Hz stream and **5 frames in 6 never reached the TSDF, silently** — a reconstruction
> defect, not a UI one. Fixed by disabling deflate, moving the SLAM feed onto the **reader thread**
> (new `reader._run_reader(on_frame=…)`; `SlamRunner` now builds its CUDA pipeline asynchronously so
> it cannot stall the reader), packing the mesh on `MeshPrep`'s thread, and evaluating the
> Turbo/Gray colormap in the vertex shader instead of per-vertex in JS.
>
> **Measured on the live rig:** mapper 5.00 → **30.40 fps**, MESH 1.03 → **6.11/s**, HTTP p90
> 766 → **4.8 ms**, stalls >300 ms 22 → **0** in 20 s, per-client scaling gone.
>
> **The obvious fix was the wrong one.** `MeshPrep`'s vertex budget is dead code on the web path
> (its `note_upload_ms` feedback only exists in `panel.py`), so the live mesh streams full-res
> forever — 30.97 MB by frame 1500 of `roomSweepFull20260730.bin`. Forcing decimation on costs
> **14× what it saves**: `prepare_packet` 178 → 2440 ms p50, GIL starvation 11.9% → **94.3%**.
> Payload is bounded by **cadence** instead (`[slam] live_mesh_bytes_per_s`, default 12 MB/s).
> **Still open:** that governor bounds the wire *rate*, not the *peak* — the map is re-sent whole
> and grows without bound. Delta / dirty-region mesh transport is the real answer, and is the same
> incremental-extraction idea 6.I already wants. Full write-up in `BUGS.md` → BUG-060.
>
> **BUG-061 — the sequel, and it corrects the sentence above.** Removing the freeze did not remove
> the *queue*: the owner still saw ephemeral SLAM lag **up to 15 s**, in playback and worse live.
> `ss -tnp` on the browser's connection read **32.8 MB unread client-side + 4.1 MB server send-Q =
> 37 MB in flight**, while the MCP connection on the same server sat at 0/0. The reason the cadence
> governor could not save it: **`/ws` has no backpressure at all.** uvicorn's
> `WebSocketsSansIOProtocol` never blocks `send_bytes` (the `writable` event is never cleared), so
> the per-client transport buffer is unbounded and the 12 MB/s budget is metered against an
> *assumed* drain rate with no relationship to the real link. So the governor is **open-loop** —
> anywhere BUG-060's write-up implies backpressure bounds the queue, it is wrong. Compounding it,
> the 30 Hz `slam` pose JSON was enqueued *after* the mesh bytes on the same ordered stream, so
> orientation was head-of-line blocked behind the whole backlog — which is why the *camera* lagged
> as badly as the geometry and pointed nowhere near the cause. Fixed by moving MESH off `/ws` onto
> a credit-gated **`/ws-mesh`** (one in flight per client, latest-wins, released by `mesh_ack`,
> newness by bytes identity because `mesh_seq` resets on `_reset_slam`), sending pose first, and
> publishing pose in `SlamWorker.run_once` before the throttled extraction. Backlog 37 MB → **0**;
> `slam` pose age on a client that keeps up p50 **1.1 ms** / p95 **4.8 ms** (n=575).
> **Honest limit:** on the 2 fps llvmpipe headless client pose age is p95 **2.82 s** — now bounded
> by that client's own render rate rather than by transport (the ack is tied to `rAF` by design, so
> a slow consumer starves itself), which means the ≤0.15 s contract is demonstrated only on a
> client that can keep up; the owner's real browser was never instrumented, only its socket queues.
> **The payload item above is unchanged** — `/ws-mesh` bounds the *backlog*, not the *peak*, and
> delta/dirty-region transport is still the real answer. Full write-up in `BUGS.md` → BUG-061.
>
> **BUG-062 — the live path was ignoring most of `[slam]`, which gates the ICP study.** Checking a
> claim in the owner's 2026-08-02 review notes (that `icp_mode`/`max_iter`/`max_dist`/the quality
> gates are not forwarded to the live worker) found it true and **worse than stated**:
> `SlamRunner._construct` hand-picked five mapper kwargs, so **thirteen** `[slam]` keys —
> `icp_mode`, `voxel_size`, `max_dist`, `max_iter`, `min_fitness`, `max_rmse`, `min_confidence`,
> `weight_threshold` and all five `stationary_*` — changed the CLI and Detailed reconstructions but
> never reached Live SLAM, silently. `SlamConfig.mapper_kwargs()` is now the single source; the web
> path overrides only the measured FOV and the resolved device, *after* the splat. Behaviour-neutral
> at stock config and pinned by a test asserting every default matches `Mapper.__init__`'s.
> **This is a prerequisite for the review's matched CUDA ICP study**, which compares `icp_mode`
> `translation` against `6dof` on the live path — a path that ignored `icp_mode` would have measured
> `translation` twice. `SlamConfig.device` remains deliberately unread by the live path (it defaults
> to `CPU:0`; honouring it would move every stock install onto the CPU) — its own decision to make,
> not a side effect. Full write-up in `BUGS.md` → BUG-062.
>
> **The rest of that review is an active plan:**
> `docs/superpowers/plans/2026-08-02-slam-compute-and-transport-followups.md`. Items 1 (BUG-061) and
> 3 (BUG-062) are landed; still open are the **input-slot overwrite counter** (an overwritten frame
> is not a tracking-lost frame and must not be counted as one), the **matched CUDA ICP/raycast
> study** (now unblocked — `translation` is only partly GPU-accelerated, and the raycast makes two
> avoidable host round-trips), remote-service output scheduling, and the low-priority saturation
> polling cleanup. It is registered as **Active** in the plans/specs register above.
>
> **Items 4 and 5 are now done** (2026-08-02) — `docs/superpowers/plans/2026-08-02-cuda-icp-study.md`.
> The study **rejected** the GPU-resident translation solve (correct to float round-off and
> gate-accepted, but +2.37 ms/frame and it holds the GIL almost solidly — `tick_share` 0.058, with
> repeatable multi-second whole-process freezes) and **rejected `6dof` on accuracy** (8.0 ± 3.6 m
> loop closure against the baseline's 0.67, 3/10 ensemble runs dead). Both are recorded as **closed
> questions**. The win ran the other way and shipped as item 5: **`Mapper.icp_device` (default
> `"CPU:0"`) runs ICP's nearest-neighbour index on the HOST** while the TSDF integrate/raycast stay
> on CUDA, plumbed as a `[slam]` key through the CLI, `SlamRunner` and `DetailedSlamPreset`;
> `Mapper.step`'s second `positions.cpu().numpy()` (a whole device→host copy to read one integer) is
> replaced by `TsdfMap.raycast(..., with_count=True)`. Output is **bit-identical** — 0.0 m over 11
> paired whole-capture replays on two captures, identical block counts, 0 lost, 0 escalations —
> which is why it is worth having: it is free.
>
> **The speed prediction did NOT reproduce in full, and the honest number is smaller.** Re-measured
> with the interleaved paired A/B the study says is the only instrument that survived scrutiny
> (new `slam_icp_bench --what ab`): **−0.231 ± 0.130 ms/frame (−1.9%)** on
> `captures/coffeeRoomCircuitNoMnt.bin`, but **+0.087 ± 0.121 ms (+0.7%) — no win at all** on
> `captures/roomSweepFull20260730.bin`. `register` is reliably faster on both (−0.53 / −0.24 ms);
> raycast + integrate take ~0.22 ms back, and on the larger map that is all of it. Two cautions
> ride with those numbers: part of the stage-level give-back is the **CUDA sync point moving** out
> of `register` rather than new work (only the whole-step delta is trustworthy), and every
> measurement was taken under a **steady 12-core external load** — step p50 11.5–12.3 ms against the
> study's quiet-box 5.4 ms. A quiet box was never available, so the study's −10% figure is neither
> confirmed nor refuted. Guards re-run and green: long-scan VRAM tail growth **0.0123 MiB/frame**
> over 1500 frames with 301 extractions, and every benchmark stayed at ≤52,161 blocks — far below
> BUG-053's 250,000 refusal, which nothing here moves. **Still open:** BUG-061's live pose-age /
> mesh-backlog contract has not been re-verified after a compute change — the owner's live server
> could not be disturbed and no new browser session could be opened, so it needs an
> owner-supervised window.
>
> **BUG-064/065/066 (2026-08-02) — the next "SLAM rendered nothing" report was not a SLAM bug.**
> The owner reported a live scan, then an offline replay, rendering nothing at all. Every stage
> measured healthy: mapper 468 frames integrated on `CUDA:0`, `/ws` shipping 30 Hz pose, `/ws-mesh`
> delivering a 3.41 MB MESH that re-parses to **zero slack**, and the client logging `first mesh:
> 24533 non-wall verts`. The map was on screen the whole time — `#browser-card` + `#preview-card`
> sit over the centre of the viewport and covered **97%** of its projected footprint (BUG-064; now
> 2%, both collapse on entering a map display in View, recoverable from the squircle rail). Two
> latent defects fell out of the same inspection: `slam.js`'s padded buffers gave a **fractional
> `BufferAttribute.count`** and therefore **NaN** bounds on every SLAM mesh (BUG-065 — harmless only
> while `frustumCulled = false` holds, and a NaN bounding sphere culls *always*, i.e. BUG-033's
> blank viewport), and `load_capture` broadcast `mode: "realtime"` beside `display: "slam"`
> (BUG-066). New instrument `host/tools/ws_probe.py` / MCP `rig_ws_probe` splits the symptom into
> server-computing / transport-delivering / payload-well-formed in one call, and acks meshes because
> a silent `/ws-mesh` client sees one mesh and then a 1-per-5-s trickle that reads as a dead server.
> **The lesson is where to stop bisecting:** when every upstream stage is healthy, ask what is drawn
> *in front of* the geometry — project its bounding box to screen coordinates and intersect it with
> the DOM.

**Open, non-blocking:** the narrow-viewport overlap probes (1280×800 / 1100×560 / 820×700) were not
run — `ui_screenshot`'s width/height did not resize the viewport, so only 1600×1000 is measured
(0 overlaps with browser + preview + Playback open). `MOUNT_ROTATION` and the merged mag-cal view
both want an owner-in-hand confirmation. On-demand **Detailed** builds did not complete during
verification (7+ min on a 759-frame capture) — pre-existing, worth its own look.
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

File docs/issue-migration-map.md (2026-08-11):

# Legacy tracker ID -> GitHub issue map

Generated by `host/tools/migrate_issues.py render-map`. Do not hand-edit;
re-run the generator if `docs/issue-migration-map.json` changes.

| Legacy ID | Issue | State |
|---|---|---|
| BUG-001 | [#12](https://github.com/hellosamblack/lidar-roomscanner/issues/12) | closed |
| BUG-002 | [#13](https://github.com/hellosamblack/lidar-roomscanner/issues/13) | closed |
| BUG-003 | [#14](https://github.com/hellosamblack/lidar-roomscanner/issues/14) | closed |
| BUG-004 | [#15](https://github.com/hellosamblack/lidar-roomscanner/issues/15) | closed |
| BUG-005 | [#16](https://github.com/hellosamblack/lidar-roomscanner/issues/16) | open |
| BUG-006 | [#17](https://github.com/hellosamblack/lidar-roomscanner/issues/17) | closed |
| BUG-007 | [#18](https://github.com/hellosamblack/lidar-roomscanner/issues/18) | closed |
| BUG-008 | [#19](https://github.com/hellosamblack/lidar-roomscanner/issues/19) | closed |
| BUG-009 | [#20](https://github.com/hellosamblack/lidar-roomscanner/issues/20) | closed |
| BUG-010 | [#21](https://github.com/hellosamblack/lidar-roomscanner/issues/21) | closed |
| BUG-011 | [#22](https://github.com/hellosamblack/lidar-roomscanner/issues/22) | closed |
| BUG-012 | [#23](https://github.com/hellosamblack/lidar-roomscanner/issues/23) | closed |
| BUG-013 | [#24](https://github.com/hellosamblack/lidar-roomscanner/issues/24) | closed |
| BUG-014 | [#25](https://github.com/hellosamblack/lidar-roomscanner/issues/25) | closed |
| BUG-015 | [#26](https://github.com/hellosamblack/lidar-roomscanner/issues/26) | closed |
| BUG-016 | [#27](https://github.com/hellosamblack/lidar-roomscanner/issues/27) | closed |
| BUG-017 | [#28](https://github.com/hellosamblack/lidar-roomscanner/issues/28) | closed |
| BUG-018 | [#29](https://github.com/hellosamblack/lidar-roomscanner/issues/29) | closed |
| BUG-019 | [#30](https://github.com/hellosamblack/lidar-roomscanner/issues/30) | closed |
| BUG-020 | [#31](https://github.com/hellosamblack/lidar-roomscanner/issues/31) | closed |
| BUG-021 | [#32](https://github.com/hellosamblack/lidar-roomscanner/issues/32) | closed |
| BUG-022 | [#33](https://github.com/hellosamblack/lidar-roomscanner/issues/33) | closed |
| BUG-023 | [#34](https://github.com/hellosamblack/lidar-roomscanner/issues/34) | closed |
| BUG-024 | [#35](https://github.com/hellosamblack/lidar-roomscanner/issues/35) | closed |
| BUG-025 | [#36](https://github.com/hellosamblack/lidar-roomscanner/issues/36) | closed |
| BUG-026 | [#37](https://github.com/hellosamblack/lidar-roomscanner/issues/37) | closed |
| BUG-027 | [#38](https://github.com/hellosamblack/lidar-roomscanner/issues/38) | closed |
| BUG-028 | [#39](https://github.com/hellosamblack/lidar-roomscanner/issues/39) | closed |
| BUG-029 | [#40](https://github.com/hellosamblack/lidar-roomscanner/issues/40) | closed |
| BUG-030 | [#41](https://github.com/hellosamblack/lidar-roomscanner/issues/41) | closed |
| BUG-031 | [#42](https://github.com/hellosamblack/lidar-roomscanner/issues/42) | closed |
| BUG-032 | [#43](https://github.com/hellosamblack/lidar-roomscanner/issues/43) | closed |
| BUG-033 | [#44](https://github.com/hellosamblack/lidar-roomscanner/issues/44) | closed |
| BUG-034 | [#45](https://github.com/hellosamblack/lidar-roomscanner/issues/45) | closed |
| BUG-035 | [#46](https://github.com/hellosamblack/lidar-roomscanner/issues/46) | closed |
| BUG-036 | [#47](https://github.com/hellosamblack/lidar-roomscanner/issues/47) | closed |
| BUG-037 | [#48](https://github.com/hellosamblack/lidar-roomscanner/issues/48) | closed |
| BUG-038 | [#49](https://github.com/hellosamblack/lidar-roomscanner/issues/49) | closed |
| BUG-039 | [#50](https://github.com/hellosamblack/lidar-roomscanner/issues/50) | closed |
| BUG-040 | [#51](https://github.com/hellosamblack/lidar-roomscanner/issues/51) | closed |
| BUG-041 | [#52](https://github.com/hellosamblack/lidar-roomscanner/issues/52) | closed |
| BUG-042 | [#53](https://github.com/hellosamblack/lidar-roomscanner/issues/53) | closed |
| BUG-043 | [#54](https://github.com/hellosamblack/lidar-roomscanner/issues/54) | closed |
| BUG-044 | [#55](https://github.com/hellosamblack/lidar-roomscanner/issues/55) | closed |
| BUG-045 | [#56](https://github.com/hellosamblack/lidar-roomscanner/issues/56) | closed |
| BUG-046 | [#57](https://github.com/hellosamblack/lidar-roomscanner/issues/57) | open |
| BUG-047 | [#58](https://github.com/hellosamblack/lidar-roomscanner/issues/58) | closed |
| BUG-048 | [#59](https://github.com/hellosamblack/lidar-roomscanner/issues/59) | closed |
| BUG-049 | [#60](https://github.com/hellosamblack/lidar-roomscanner/issues/60) | open |
| BUG-050 | [#61](https://github.com/hellosamblack/lidar-roomscanner/issues/61) | closed |
| BUG-051 | [#62](https://github.com/hellosamblack/lidar-roomscanner/issues/62) | closed |
| BUG-052 | [#63](https://github.com/hellosamblack/lidar-roomscanner/issues/63) | closed |
| BUG-053 | [#64](https://github.com/hellosamblack/lidar-roomscanner/issues/64) | closed |
| BUG-054 | [#65](https://github.com/hellosamblack/lidar-roomscanner/issues/65) | closed |
| BUG-055 | [#66](https://github.com/hellosamblack/lidar-roomscanner/issues/66) | closed |
| BUG-056 | [#67](https://github.com/hellosamblack/lidar-roomscanner/issues/67) | closed |
| BUG-057 | [#68](https://github.com/hellosamblack/lidar-roomscanner/issues/68) | closed |
| BUG-058 | [#69](https://github.com/hellosamblack/lidar-roomscanner/issues/69) | closed |
| BUG-059 | [#70](https://github.com/hellosamblack/lidar-roomscanner/issues/70) | closed |
| BUG-060 | [#71](https://github.com/hellosamblack/lidar-roomscanner/issues/71) | closed |
| BUG-061 | [#72](https://github.com/hellosamblack/lidar-roomscanner/issues/72) | closed |
| BUG-062 | [#73](https://github.com/hellosamblack/lidar-roomscanner/issues/73) | closed |
| BUG-063 | [#74](https://github.com/hellosamblack/lidar-roomscanner/issues/74) | open |
| BUG-064 | [#75](https://github.com/hellosamblack/lidar-roomscanner/issues/75) | closed |
| BUG-065 | [#76](https://github.com/hellosamblack/lidar-roomscanner/issues/76) | closed |
| BUG-066 | [#77](https://github.com/hellosamblack/lidar-roomscanner/issues/77) | closed |
| BUG-067 | [#78](https://github.com/hellosamblack/lidar-roomscanner/issues/78) | closed |
| BUG-068 | [#79](https://github.com/hellosamblack/lidar-roomscanner/issues/79) | closed |
| BUG-069 | [#80](https://github.com/hellosamblack/lidar-roomscanner/issues/80) | closed |
| BUG-070 | [#81](https://github.com/hellosamblack/lidar-roomscanner/issues/81) | open |
| BUG-071 | [#82](https://github.com/hellosamblack/lidar-roomscanner/issues/82) | open |
| BUG-072 | [#83](https://github.com/hellosamblack/lidar-roomscanner/issues/83) | closed |
| BUG-073 | [#84](https://github.com/hellosamblack/lidar-roomscanner/issues/84) | open |
| BUG-074 | [#85](https://github.com/hellosamblack/lidar-roomscanner/issues/85) | closed |
| BUG-075 | [#86](https://github.com/hellosamblack/lidar-roomscanner/issues/86) | open |
| BUG-076 | [#87](https://github.com/hellosamblack/lidar-roomscanner/issues/87) | closed |
| BUG-077 | [#88](https://github.com/hellosamblack/lidar-roomscanner/issues/88) | closed |
| BUG-078 | [#89](https://github.com/hellosamblack/lidar-roomscanner/issues/89) | open |
| BUG-079 | [#90](https://github.com/hellosamblack/lidar-roomscanner/issues/90) | closed |
| BUG-080 | [#91](https://github.com/hellosamblack/lidar-roomscanner/issues/91) | closed |
| BUG-081 | [#92](https://github.com/hellosamblack/lidar-roomscanner/issues/92) | closed |
| BUG-082 | [#93](https://github.com/hellosamblack/lidar-roomscanner/issues/93) | closed |
| BUG-083 | [#94](https://github.com/hellosamblack/lidar-roomscanner/issues/94) | closed |
| BUG-084 | [#95](https://github.com/hellosamblack/lidar-roomscanner/issues/95) | open |
| BUG-085 | [#96](https://github.com/hellosamblack/lidar-roomscanner/issues/96) | closed |
| BUG-086 | [#97](https://github.com/hellosamblack/lidar-roomscanner/issues/97) | closed |
| BUG-087 | [#98](https://github.com/hellosamblack/lidar-roomscanner/issues/98) | open |
| BUG-088 | [#99](https://github.com/hellosamblack/lidar-roomscanner/issues/99) | open |
| BUG-089 | [#100](https://github.com/hellosamblack/lidar-roomscanner/issues/100) | open |
| BUG-090 | [#101](https://github.com/hellosamblack/lidar-roomscanner/issues/101) | open |
| BUG-091 | [#102](https://github.com/hellosamblack/lidar-roomscanner/issues/102) | open |
| BUG-092 | [#103](https://github.com/hellosamblack/lidar-roomscanner/issues/103) | open |
| BUG-093 | [#104](https://github.com/hellosamblack/lidar-roomscanner/issues/104) | open |
| BUG-094 | [#105](https://github.com/hellosamblack/lidar-roomscanner/issues/105) | closed |
| BUG-095 | [#106](https://github.com/hellosamblack/lidar-roomscanner/issues/106) | open |
| BUG-096 | [#107](https://github.com/hellosamblack/lidar-roomscanner/issues/107) | open |
| BUG-097 | [#108](https://github.com/hellosamblack/lidar-roomscanner/issues/108) | open |
| BUG-098 | [#109](https://github.com/hellosamblack/lidar-roomscanner/issues/109) | open |
| DC-A | [#137](https://github.com/hellosamblack/lidar-roomscanner/issues/137) | closed |
| DC-B | [#138](https://github.com/hellosamblack/lidar-roomscanner/issues/138) | open |
| DC-C | [#139](https://github.com/hellosamblack/lidar-roomscanner/issues/139) | closed |
| DC-D | [#140](https://github.com/hellosamblack/lidar-roomscanner/issues/140) | closed |
| DC-D2 | [#141](https://github.com/hellosamblack/lidar-roomscanner/issues/141) | open |
| DC-E | [#142](https://github.com/hellosamblack/lidar-roomscanner/issues/142) | open |
| DC-F | [#143](https://github.com/hellosamblack/lidar-roomscanner/issues/143) | open |
| DC-G | [#144](https://github.com/hellosamblack/lidar-roomscanner/issues/144) | open |
| DC-H | [#145](https://github.com/hellosamblack/lidar-roomscanner/issues/145) | open |
| DC-I | [#146](https://github.com/hellosamblack/lidar-roomscanner/issues/146) | open |
| DC-J | [#147](https://github.com/hellosamblack/lidar-roomscanner/issues/147) | closed |
| DC-K | [#161](https://github.com/hellosamblack/lidar-roomscanner/issues/161) | open |
| FW-1 | [#131](https://github.com/hellosamblack/lidar-roomscanner/issues/131) | open |
| OFFLINE-1 | [#132](https://github.com/hellosamblack/lidar-roomscanner/issues/132) | open |
| OFFLINE-2 | [#133](https://github.com/hellosamblack/lidar-roomscanner/issues/133) | open |
| OFFLINE-3 | [#134](https://github.com/hellosamblack/lidar-roomscanner/issues/134) | open |
| OFFLINE-4 | [#135](https://github.com/hellosamblack/lidar-roomscanner/issues/135) | open |
| OFFLINE-5 | [#158](https://github.com/hellosamblack/lidar-roomscanner/issues/158) | open |
| OFFLINE-6 | [#159](https://github.com/hellosamblack/lidar-roomscanner/issues/159) | open |
| OFFLINE-7 | [#160](https://github.com/hellosamblack/lidar-roomscanner/issues/160) | open |
| SENS-1 | [#126](https://github.com/hellosamblack/lidar-roomscanner/issues/126) | open |
| SENS-2 | [#127](https://github.com/hellosamblack/lidar-roomscanner/issues/127) | open |
| SENS-3 | [#128](https://github.com/hellosamblack/lidar-roomscanner/issues/128) | open |
| SENS-4 | [#129](https://github.com/hellosamblack/lidar-roomscanner/issues/129) | open |
| SENS-5 | [#155](https://github.com/hellosamblack/lidar-roomscanner/issues/155) | open |
| SLAM-1 | [#110](https://github.com/hellosamblack/lidar-roomscanner/issues/110) | open |
| SLAM-10 | [#150](https://github.com/hellosamblack/lidar-roomscanner/issues/150) | open |
| SLAM-11 | [#151](https://github.com/hellosamblack/lidar-roomscanner/issues/151) | open |
| SLAM-12 | [#152](https://github.com/hellosamblack/lidar-roomscanner/issues/152) | open |
| SLAM-13 | [#153](https://github.com/hellosamblack/lidar-roomscanner/issues/153) | open |
| SLAM-14 | [#154](https://github.com/hellosamblack/lidar-roomscanner/issues/154) | open |
| SLAM-2 | [#111](https://github.com/hellosamblack/lidar-roomscanner/issues/111) | open |
| SLAM-3 | [#112](https://github.com/hellosamblack/lidar-roomscanner/issues/112) | open |
| SLAM-4 | [#113](https://github.com/hellosamblack/lidar-roomscanner/issues/113) | open |
| SLAM-5 | [#114](https://github.com/hellosamblack/lidar-roomscanner/issues/114) | open |
| SLAM-6 | [#115](https://github.com/hellosamblack/lidar-roomscanner/issues/115) | open |
| SLAM-7 | [#116](https://github.com/hellosamblack/lidar-roomscanner/issues/116) | open |
| SLAM-8 | [#117](https://github.com/hellosamblack/lidar-roomscanner/issues/117) | open |
| SLAM-9 | [#149](https://github.com/hellosamblack/lidar-roomscanner/issues/149) | open |
| TOOL-1 | [#136](https://github.com/hellosamblack/lidar-roomscanner/issues/136) | open |
| WEB-1 | [#118](https://github.com/hellosamblack/lidar-roomscanner/issues/118) | open |
| WEB-10 | [#157](https://github.com/hellosamblack/lidar-roomscanner/issues/157) | open |
| WEB-2 | [#119](https://github.com/hellosamblack/lidar-roomscanner/issues/119) | open |
| WEB-3 | [#120](https://github.com/hellosamblack/lidar-roomscanner/issues/120) | open |
| WEB-4 | [#121](https://github.com/hellosamblack/lidar-roomscanner/issues/121) | open |
| WEB-5 | [#122](https://github.com/hellosamblack/lidar-roomscanner/issues/122) | open |
| WEB-6 | [#123](https://github.com/hellosamblack/lidar-roomscanner/issues/123) | open |
| WEB-7 | [#124](https://github.com/hellosamblack/lidar-roomscanner/issues/124) | open |
| WEB-8 | [#125](https://github.com/hellosamblack/lidar-roomscanner/issues/125) | open |
| WEB-9 | [#156](https://github.com/hellosamblack/lidar-roomscanner/issues/156) | open |
| XPORT-1 | [#130](https://github.com/hellosamblack/lidar-roomscanner/issues/130) | open |
| XPORT-2 | alias of BUG-049 -> #60 | open |

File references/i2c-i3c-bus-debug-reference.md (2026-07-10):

# I²C / I3C bus debugging reference — roomscanner sensor stack

**Purpose.** A decision-support reference for debugging the I²C / I3C buses across
the stacked NUCLEO boards. It maps every bus segment to the **jumpers, solder
bridges, switches, test points, resistors, and STM32 IOs** that control or expose
it, so an agent (or human) can reason about *where a bus is broken and what to
change or probe*. Every claim cites its source file + page.

Companion docs in `references/kicad/roomscanner-stack/`:
`stack-pinmap.md` (pin map), `jumper-config.md` (default jumper positions),
`roomscanner-stack.kicad_sch` (consolidated schematic + netlist).

Source schematics (authoritative):
- H563 base — `references/datasheets/NUCLEO-H563ZI/schematic/schematic.pdf` (MB1404, 12 sheets)
- IKS4A1 — `references/datasheets/NUCLEO-IKS4A1/schematic/schematic.pdf` (5 pages)
- 53L9A1 (ToF) — `references/datasheets/NUCLEO-VL53L9CX/schematic/x-nucleo-53l9a1-schematic.pdf` (6 pages)

Firmware pin/bus config (authoritative for *this* project):
- `firmware/scanner-stream/Inc/main.h`, `firmware/scanner-stream/53L9A1_PostprocessSingle.ioc`

---

## 1. Bus at a glance

```
                 STM32H563  I3C1  (controller)
                 PB8 = SCL   PB9 = SDA          <- one physical 2-wire bus
                        │
        ST Zio / Arduino header  CN5.10 (SCL) / CN5.9 (SDA)   [shared by the stack]
                        │
        ┌───────────────┴────────────────────────────┐
        │                                             │
   X-NUCLEO-53L9A1 (top)                        X-NUCLEO-IKS4A1 (middle)
   U5 PI4ULS3V204 (SCL/SDA shifter)             U3 NXS0108 (SCL/SDA shifter)
   3V3 <-> sensor IOVDD (1V8/1V2)               3V3 <-> sensor Vio (1V8)
        │                                             │
   VL53L9CX (0x52 / I3C dyn 0x52)          internal I²C: STM_I2C ─ SENS_I2C ─ HUB2_I2C
   R13/R14 2.2k pull-ups (sensor side)     ─ DIL_I2C, routed by SB matrix + J4/J5
                                           LSM6DSV16X(HUB1) LSM6DSO16IS(HUB2)
                                           LIS2MDL LPS22DF LIS2DUXS12 STTS22H SHT40
```

**One bus, two personalities.** PB8/PB9 is a single 2-wire bus that the firmware
drives as **I3C1 in controller mode** (`53L9A1_PostprocessSingle.ioc`:
`PB8.Signal=I3C1_SCL`, `PB9.Signal=I3C1_SDA`, `PB8.Mode=Controller`,
`I3C1.BusUsage=MixedUsage`). Devices are reached either as:
- **I3C dynamic** — assigned by ENTDAA (PartID → dynamic address). Per project state:
  ToF PartID `0x0102` → `0x52`, LSM6DSV16X PartID `0x0070` → `0x50`.
- **Legacy-I²C static** — the sensors' hard addresses (below), used in MixedUsage.

> Debugging implication: an address that works in one mode may not in the other,
> and ENTDAA enumeration order/participation matters (see §7 playbook).

---

## 2. Master-side IO reference (STM32H563, from firmware)

| Signal | STM32 | Zio pin | Peripheral | Source |
|---|---|---|---|---|
| SCL | **PB8** | CN5.10 | I3C1_SCL (controller) | `main.h`, `.ioc` |
| SDA | **PB9** | CN5.9 | I3C1_SDA (controller) | `.ioc` |
| ToF CLK_IN | PB5 | CN5.4 | TIM3_CH2 (PWM) — *idle by default, see §5 SW1* | `.ioc` `PB5.Signal=S_TIM3_CH2` |
| ToF SYNC_IN | PB1 | CN8.4 | GPIO | `main.h` `SYNC_IN_Pin=PB1` |
| ToF XSHUT | PB6 | CN9.2 | GPIO | `main.h` `XSHUT_Pin=PB6` |
| ToF INTR | PB7 | CN9.1 | GPIO / EXTI7 | `main.h` `INTR_Pin=PB7`, `INTR_EXTI_IRQn=EXTI7` |

On the H563 the Zio Arduino-I²C pins are labelled `I2C_A_SCL/I2C_A_SDA` on
`PB8/PB9` (schematic.pdf p6, *Connectors* sheet). The SDA/SCL path from the MCU
to the header is **direct** — no solder bridge in series (the `SB41` near that
region is on `PF2/PB6/PB7`, not the I²C lines).

---

## 3. Address map (verify against §8 SB positions before trusting)

| Device | Board | 7-bit | ADDw (8-bit) | Addr control | Source (page) |
|---|---|---|---|---|---|
| VL53L9CX (ToF) | 53L9A1 | 0x29 | **0x52** | fixed; I3C dyn 0x52 | 53L9A1 p5 |
| LSM6DSV16X (HUB1 IMU) | IKS4A1 | 0x6A / 0x6B | 0xD4 / 0xD6 | SA0 via **SB17 / SB15**; I3C dyn 0x50 | IKS4A1 p3 |
| LSM6DSO16IS (HUB2 IMU/ISPU) | IKS4A1 | 0x6A / 0x6B | 0xD4 / 0xD6 | SA0 via **SB35 / SB34** | IKS4A1 p3 |
| LPS22DF (baro) | IKS4A1 | 0x5C / **0x5D** | 0xB8 / 0xBA | SA0 via **SB31 / SB29** | IKS4A1 p3 |
| LIS2MDL (mag) | IKS4A1 | 0x1E | 0x3C | fixed | IKS4A1 p3 |
| STTS22H (temp) | IKS4A1 | 0x38 | **0x70** | ADDR pin | IKS4A1 p3 |
| LIS2DUXS12 (accel) | IKS4A1 | 0x18 / 0x19 | 0x30 / 0x32 | SA0 (verify on board) | IKS4A1 p3 |
| SHT40 (RH/T) | IKS4A1 | 0x44 | 0x88 | fixed | IKS4A1 p3 |
| STHS34PF80 (IR presence, on J7) | IKS4A1 | 0x5A | 0xB4 | fixed | IKS4A1 p3 |

> The roomscanner-confirmed live set (firmware): ToF `0x52` (I3C dyn), LSM6DSV16X
> `0x50` (I3C dyn), baro `0x5D`. See the `lsm6dsv16x-panel-integration` /
> `iks4a1-i3c-bus-conflict` memories.

---

## 4. Pull-up resistors (critical for bus health)

The bus SDA/SCL are open-drain; pull-ups from **all stacked boards sum in
parallel**. Too-low combined resistance (over-strong) or too-high (weak edges)
both break I²C/I3C.

| Board | R | Value | Domain / where | Source |
|---|---|---|---|---|
| 53L9A1 | R5, R8 | 10k | host side of shifter, to `Nucleo_IOVDD` (=3V3, see J1) | 53L9A1 p4 |
| 53L9A1 | R13, R14 | 2.2k | **sensor-side I3C** SDA/SCL, to sensor rail | 53L9A1 p5 |
| IKS4A1 | R1, R2 | 4.7k | sensor-side bus, to `Vio` (1V8) | IKS4A1 p2 |
| IKS4A1 | R11–R15, R23, R34, R35 | 4.7k | per-sub-bus pull-ups (SENS/STM/HUB), to VDD | IKS4A1 p3 |
| IKS4A1 | R26, R27 | 2.2k | HUB2 / DIL24 bus, to 1V8_IO | IKS4A1 p4 |
| H563 | (SB-gated) | — | Nucleo Arduino-I²C pull-up SBs — usually **not fitted**; verify | H563 p6 |

> Debugging note: the **host-side** shared bus (PB8/PB9, 3V3) sees 53L9A1 R5/R8
> (10k each) plus whatever the IKS4A1 A-side presents; measure the actual bus
> resistance to ground with power off. The **sensor-side** rails are separate
> per board (behind the level shifters) and each have their own strong pull-ups.

---

## 5. Board-by-board control points

### 5.1 H563 base
- **I²C path:** `PB8/PB9` → Zio `CN5.10 / CN5.9`, direct, no series SB.
- **No jumpers on the bus.** JP2/JP4/JP5/JP6 are power/debug/USB (see
  `jumper-config.md`), not on the Zio pins.
- **Probe:** at the Zio header pins CN5.10 (SCL) / CN5.9 (SDA), or MCU pins PB8/PB9.
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

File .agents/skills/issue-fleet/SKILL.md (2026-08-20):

---
name: issue-fleet
description: Run several subagent workers in parallel across open GitHub Issues, each in its own
  worktree, under a declared usage ceiling. Use when the ask is to burn down the backlog rather than
  fix one thing — "work the backlog", "run a fleet", "parallel agents on issues", "knock out several
  issues", "spend the next few hours on open issues". Picks the highest-impact issues, prefers ones
  that already have prior work, keeps workers off each other's files, and delegates to the cheapest
  model that will not cost quality.
---

# Issue fleet — you orchestrate, workers implement
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

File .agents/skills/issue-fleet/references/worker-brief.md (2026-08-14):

# Fleet worker contract

The canonical worker rules. `.claude/agents/fleet-worker.md` and
`.claude/agents/fleet-worker-mech.md` carry this as their system prompt; the orchestrator restates
the load-bearing lines in each spawn prompt, because a rule stated once has already failed here
(2026-07-10: an agent that had been told not to commit at the main checkout did exactly that).
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

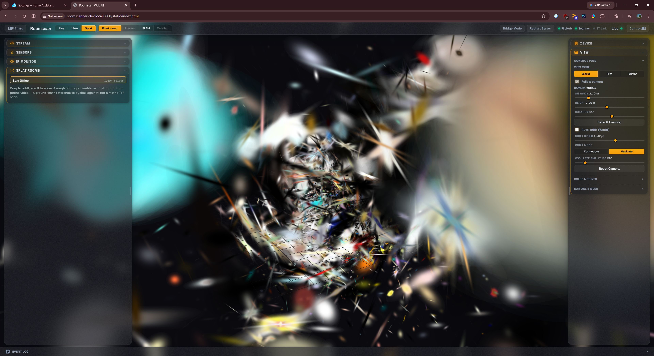
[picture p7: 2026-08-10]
docs/assets/bugs/bug-094.png

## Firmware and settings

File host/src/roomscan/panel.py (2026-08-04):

"""Open3D `visualization.gui` control panel for the roomscan viewer (Phase 3.5).

.. deprecated:: Web Phase 5 (2026-07-16)
    The browser instrument (`roomscan-web`) is now the primary, supported UI --
    it covers real-time, sensors, record/playback, SLAM, and save, and unlike
    this panel it runs on the GPU-less headless host. This Open3D desktop panel
    is kept as unsupported legacy only (it needs a local display + Open3D GUI
    stack). Prefer `roomscan-web`. The shared, GUI-free reader plumbing this
    module and the web server both use now lives in `reader.py`.

A real control panel to replace the classic keyboard-only Open3D window: a
`SceneWidget` renders the live point cloud on the left; a settings panel on the
right carries Status / Device / View / IR-Monitor / Capture / Events groups.

ALL data plumbing is reused unchanged from the classic viewer -- `TransformStage`,
`CommandClient`/`CommandDispatcher`, `Deprojector`, `sources`/`pump`, `config`,
`Stats`/`StreamDecoder`. This module is presentation only. The classic
`roomscan-view` window stays available (this is opt-in via `--panel` /
`roomscan-panel`).

Threading model (hard rules, mirrors the classic viewer's hard-won contract):
  * A single reader thread owns the source+decoder+transform, routes device
    EVENT/ACK to the log bus / CommandClient, and drops each rendered frame into
    a latest-wins slot (`queue.Queue(maxsize=1)`).
  * ALL scene/UI mutation happens on the GUI main thread, driven by
    `Window.set_on_tick_event` -- the tick polls the slot and renders the cloud
    AND the IR pane every frame it changes; labels / sensors / metrics / event
    log refresh at <=4 Hz.
  * Serial writes (commands) run on `CommandDispatcher`'s short-lived worker
    threads, never on the reader or UI thread; their results come back as log-bus
    messages, drained on the UI thread. This keeps `SerialSource.write`'s "never
    on the reader thread" invariant intact.
"""
from __future__ import annotations

import logging
import os
import queue
import sys
import threading
import time
from pathlib import Path

import numpy as np

from .config import ViewerConfig, apply_config_defaults
from .control import CommandClient, CommandDispatcher
from .decoder import StreamDecoder
from .deproject import Deprojector
from .ir_image import ir_range, reflectance_to_rgb
from .logbus import LogBus
from .metrics import MetricsRegistry, ResourceSampler
from .metrics_hud import render_hud
from .native import Transform
from . import portguard
from .flatfield import FlatField
from .pipeline import TransformStage
from .protocol import CommandCode
from .reader import (  # neutral reader loop + follow-camera math (Web Phase 5 hoist)
    _FOLLOW_BACK_OFF_M,
    _FOLLOW_LOOK_AHEAD_M,
    _Pacer,
    _WORLD_UP,
    _run_reader,
    follow_camera_target,
)
from .magcal import MagCalibration
from .sensors import (
    AXIS_CONVENTION,
    SensorState,
    YawFusion,
    absolute_heading,
    gizmo_pose,
)
from .sensors_widgets import render_compass, render_sparkline, render_sensors_overlay
from .shading import MODES as _NEAR_MODES
from .shading import cloud_colors
from .sources import FileSource, Recorder, SerialSource, UdpSource, get_best_source
from .surface import grid_triangles, grid_triangles_3d
from . import theme
from .viewer import Stats, _build_arg_parser

# Usecase id -> label (only binning-2 profiles are usable at full res; see ROADMAP
# Phase 3 table -- AF_RANGE/AF are binning-4 and get REJECTED_BINNING by firmware).
_USECASES = [(0, "AR_RANGE (~32 fps)"), (1, "AR_PRECISION (~28 fps)")]
_COLOR_MODES = ("depth", "reflectance", "confidence")
_IR_COLORMAPS = ("gray", "turbo")
_SURFACE_MODES = ("grid", "spatial")
_IR_UPSCALE = 6                 # 54x42 zones -> 324x252 px, nearest-neighbor
_GEOM = "cloud"
_MESH_GEOM = "surface"
_MESH_WALLS_GEOM = "__slam_walls__"   # see-through-walls split, SLAM/Showcase only
_WALL_MODES = ("solid", "translucent", "wireframe")
_SLAM_TRAJ_GEOM = "__slam_trajectory__"
_TRAJ_HEAD_GEOM = "__slam_traj_head__"  # glowing marker at the sensor's current pose
_FLOOR_GRID_GEOM = "__floor_grid__"    # grounded stage grid, SLAM/Showcase only
_FOV_GEOM = "__fov_indicator__"        # faint camera FoV frustum, RECORDING/SLAM only
_FOV_RANGE_M = 0.5                     # how far out the frustum rays/edges are drawn
_CAPTURE_SQUARE_GEOM = "__capture_square__"  # bright planar capture-area quad, RECORDING/SLAM
_CAPTURE_SQUARE_DEPTH_M = 0.75          # fixed depth (m) the capture square is drawn at
_GIZMO_GEOM = "__imu_gizmo__"
_IR_OVERLAY_GEOM = "__ir_overlay__"    # first-person IR billboard (spec §5.2)
_RESULTS_DIR = "results"               # Showcase FINAL save target (mesh + trajectory)
_GIZMO_ANCHOR = np.array([0.0, 0.0, 0.0], dtype=np.float64)  # fixed scene anchor; calibrate later
_UI_PERIOD = 0.25               # <=4 Hz label / sensors / metrics / log refresh
                                # (the IR pane is NOT throttled here -- it renders
                                #  per frame, in lockstep with the point cloud)
_EXPOSURE_DEBOUNCE = 0.4        # s to settle before sending a dragged exposure value

# Constrained turntable camera: azimuth-only orbit (no elevation/tilt term exists)
# + pan + zoom, world-up fixed in look_at so the view can never roll or pitch --
# it always faces the scene the same way the flat IR monitor does. Sensitivities
# are in radians (orbit) / fraction (pan, zoom) per pixel or wheel-notch.
#
# Up is -Y, not +Y: the sensor's own frame is a standard CV/camera convention
# (x-right, y-DOWN, z-forward -- ZAPC-validated, docs/deprojector-validation.md
# "y axis increases monotonically with row", row 0 = top = negative y), so +Y
# in point-cloud space is physically down. az=0 also looks along +Z (the
# sensor's own forward/depth axis), not -Z, so the default view is from the
# sensor's own side, not from behind it. Both were verified empirically against
# an Open3D view matrix: with fwd=-Z/up=+Y (the old values) a corner at
# (row0,col0) -- top-left in the IR monitor -- rendered bottom-left (a vertical
# flip); fwd=+Z/up=-Y renders it top-left, matching the IR monitor exactly on
# all four corners.
# _WORLD_UP is defined in reader.py (shared with the web server) and imported
# above; the comment block just above documents why fwd=+Z/up=-Y is the choice.
_ORBIT_K = 0.008          # rad per pixel drag (~0.46 deg/px)
_PAN_K = 0.0015           # pan fraction of radius per pixel
_ZOOM_STEP = 0.9          # radius *= 0.9**wheel_dy

# Showcase mode (Task 12): FINAL-phase auto-orbit rate and camera ease-in
# duration. See "Fade" note on _advance_showcase_orbit -- Filament has no
# practical per-geometry alpha fade, so the PROCESSING->FINAL transition is a
# clean geometry swap plus this eased camera move, not a literal cross-fade.
_SHOWCASE_ORBIT_STEP = 0.003    # rad per rendered frame -- a gentle few-deg/sec orbit
_SHOWCASE_EASE_S = 1.5          # seconds to ease the camera into the final framing

# Camera-follow ("first-person") mode (owner request): default OFF, toggled
# per-view. `_FOLLOW_BACK_OFF_M` pulls the eye a hair behind the sensor along
# -forward for a touch of context (0 would put the eye exactly at the sensor);
# `_FOLLOW_LOOK_AHEAD_M` is how far ahead of the sensor the look-at center
# sits. `_FOLLOW_SMOOTH` is the per-tick lerp fraction toward the target
# eye/center so per-frame pose noise (SLAM jitter) doesn't jitter the view.
# Lowered 0.25 -> 0.12 (owner report: view was visibly shaky even with the
# sensor stationary on a tripod). An EMA at alpha attenuates the steady-state
# noise std by sqrt(alpha/(2-alpha)): 0.25 -> 0.38x, 0.12 -> 0.25x. It cannot
# fully remove the jitter (the root is per-frame ICP translation noise on the
# 54x42 depth), but 0.12 takes it from "shaky" to "gently floating".
# The flat 0.12 EMA also lagged REAL motion ~0.3 s ("feels like the system
# didn't notice you moved" -- owner). `_follow_alpha` makes the weight
# velocity-adaptive instead: sub-`_FOLLOW_SNAP_M` frame motion (ICP noise while
# ~stationary) still smooths at `_FOLLOW_SMOOTH`, but genuine motion ramps the
# weight to 1.0 so the camera position tracks 1:1 with no perceived lag.
# _FOLLOW_BACK_OFF_M / _FOLLOW_LOOK_AHEAD_M are defined in reader.py (shared with
# the web follow-camera math) and imported above.
_FOLLOW_SMOOTH = 0.12
_FOLLOW_SNAP_M = 0.03      # per-frame eye motion (m) at/above which the follow camera tracks 1:1

# --- Two-mode / two-camera redesign (spec 2026-07-13) --------------------------
VIEW_REAL_TIME = "real_time"
VIEW_SLAM = "slam"
CAM_FIRST_PERSON = "first_person"
CAM_ORBIT = "orbit"


def follow_active(mode: str, camera: str) -> bool:
    """The SLAM pose-follow path (rides step.pose via _apply_follow_camera) is
    on only in SLAM mode + first-person. Real-Time first-person is a separate
    fixed sensor-origin camera (real_time_first_person), not this path."""
    return mode == VIEW_SLAM and camera == CAM_FIRST_PERSON


def gizmo_should_update(camera: str, imu_gizmo: bool) -> bool:
    """Spec §5.3 flicker fix: only add/refresh the IMU gizmo in ORBIT. In
    first-person the gizmo is never added, so nothing removes+re-adds it every
    tick -> no flicker."""
    return camera == CAM_ORBIT and imu_gizmo


def real_time_first_person(mode: str, camera: str) -> bool:
    return mode == VIEW_REAL_TIME and camera == CAM_FIRST_PERSON


def load_kind(path: str) -> str:
    """Dispatch a Load target by suffix: .bin -> capture (process pipeline),
    .ply -> mesh (display only), else unknown."""
    low = str(path).lower()
    if low.endswith(".bin"):
        return "capture"
    if low.endswith(".ply"):
        return "mesh"
    return "unknown"


_HELP_LINES = [
    "",
    "Mouse:  left-drag orbit (yaw only)  |  ctrl / middle-drag pan  |  wheel zoom",
    "        (camera is tilt-locked: it spins level and pans but never tips)",
    "Key:    H  this help    M  toggle metrics overlay    G  camera model    C  clear scan",
    "",
    "Metrics overlay (top-left of the 3D view): capacity bars for our app.",
    "  Sensor rows show host/hub rate — the bar is the fraction of what the",
    "  sensor produced that reached the host (full = keeping up). Plus FPS,",
    "  USB link use, and this process's CPU (cores), RAM, and GPU.",
    "",
    "Status   fps, frame/seq-gap/drop/crc/raw counters, current usecase + color.",
    "Device   Ping / Request CALIB / Reinit; usecase; exposure (ms, sent on release).",
    "         (device controls are inactive in replay.)",
    "View     color mode (depth / reflectance IR / confidence);",
    "         point size (raise it to close the gaps between zones);",
    "         Near contrast (see below); dark background;",
    "         Rotate 90 (turns the cloud AND the IR pane, e.g. sideways mount);",
    "         Reset view; Clear scan.",
    "",
    "Near contrast -- spend more of the colormap on close targets (e.g. a face",
    "in front of a wall) so facial relief stands out:",
    "  window   : color only points within the cutoff distance and grey the rest",
    "             (slider = cutoff metres). Best for isolating a person.",
    "  emphasis : nonlinear boost of near depths (slider = strength); wall stays",
    "             colored but compressed.",
    "  equalize : auto histogram-equalize -- dense surfaces stretch, flat compress.",
    "  off      : plain linear depth coloring.",
    "",
    "IR Monitor  live 2D reflectance image; gray/turbo; Freeze holds the range.",
    "SLAM        live pose + map view (Phase 6): mesh + trajectory replace the",
    "            raw cloud, off the GUI/reader threads; Clear resets the map too.",
    "            A bright square shows exactly what the sensor is capturing now;",
    "            Follow camera (first-person) rides the sensor's pose instead",
    "            of free-orbit -- off by default, toggle back off to resume orbit.",
    "Capture     Record to captures/*.bin; replay adds Pause + fps.",
    "Events      device EVENTs, command results, connect/disconnect.",
    "",
    "Run with --save-config to persist the current view/IR/near settings.",
]


def _orbit_eye(target, az, radius):
    """Camera eye position for a level turntable orbit: azimuth `az` (radians)
    at `radius` from `target`, always at the target's height -- there is no
    elevation term, so no drag input can ever tilt the camera. az=0 puts the
    eye on the -Z side looking along +Z, the sensor's own forward/depth axis,
    so the default view faces the scene the same way the sensor (and the IR
    monitor) does. With a fixed world-up in look_at, this also can never
    introduce roll. Pure — unit-tested."""
    d = np.array([-np.sin(az), 0.0, -np.cos(az)])
    return np.asarray(target, dtype=np.float64) + radius * d


def _rot_xy(pts, k):
    """Rotate (N,3) points by k*90 deg CCW about the viewing (z) axis, leaving z
    (depth) untouched so coloring/near-contrast are unaffected. Used to upright a
    sideways-mounted sensor; kept in lockstep with the IR pane's np.rot90."""
    k %= 4
    if k == 0 or len(pts) == 0:
        return pts
    x, y, z = pts[:, 0].copy(), pts[:, 1].copy(), pts[:, 2]
    for _ in range(k):
        x, y = -y, x
    return np.stack([x, y, z], axis=1)


def _ir_freeze_range(freeze, frozen, auto):
    """Resolve the IR pane's display range for one frame (pure, unit-tested).

    `auto` is this frame's percentile auto-range; `frozen` is the currently
    captured frozen range or None. Returns `(vmin, vmax, frozen_out)`.

    When `freeze` is set, reuse `frozen` if present, else lazily capture this
    frame's `auto` as the frozen range and return it -- this is what makes freeze
    engage when it was set from config (the checkbox `.checked=True` never fires
    the toggle handler) or toggled before any reflectance frame arrived (nothing
    to freeze yet). When not frozen, pass `frozen` through untouched so a later
    re-freeze via the toggle handler still has the last value to fall back on.
    """
    if freeze:
        frozen = auto if frozen is None else frozen
        return frozen[0], frozen[1], frozen
    return auto[0], auto[1], frozen


def _wall_submesh(verts, colors, tris):
    """Build a new legacy `TriangleMesh` from a subset of `tris` (rows into
    the parent mesh's triangle array), remapping vertex indices to a dense
    0..N-1 range and carrying over `verts`/`colors` for the referenced
    vertices only. Module-level (not a method) both because it's pure --
    doesn't touch `self` -- and so it's directly callable from the
    `_upload_slam_mesh` unit tests (test_panel_walls.py), which run that
    method unbound on a lightweight stand-in object (see
    test_panel_showcase.py's established pattern) rather than a real
    `ControlPanel`.

    `TriangleMesh.select_by_index` selects *vertices*, not triangles
    (verified empirically -- it drops any triangle that isn't fully inside
    the selected vertex set), so it can't be used to pull out an arbitrary
    triangle subset; this does it by hand instead."""
    import open3d as o3d
    uniq, remap = np.unique(tris.reshape(-1), return_inverse=True)
    new_tris = remap.reshape(tris.shape).astype(np.int32)
    m = o3d.geometry.TriangleMesh()
    m.vertices = o3d.utility.Vector3dVector(verts[uniq])
    m.triangles = o3d.utility.Vector3iVector(new_tris)
    m.vertex_colors = o3d.utility.Vector3dVector(colors[uniq])
    return m


def _fov_frustum_lines(pose, fov_h_deg: float, fov_v_deg: float,
                       range_m: float = _FOV_RANGE_M):
    """(points (5,3), lines (8,2)) outlining a small pyramid frustum for the
    camera FoV at `pose` (4x4 world<-camera, Open3D CV convention: x-right,
    y-down, z-forward -- the same convention `slam/frames.py`'s poses use):
    the camera origin plus its four FoV corners at `range_m` along the view
    direction, and the 8 edges (4 rays from the origin + the far rectangle)
    that outline it. Pure -- unit-tested; feeds the faint FoV `LineSet`
    (`_FOV_GEOM`) drawn during RECORDING/SLAM (owner request)."""
    pose = np.asarray(pose, dtype=np.float64)
    origin = pose[:3, 3]
    r = pose[:3, :3]
    half_h = np.tan(np.deg2rad(fov_h_deg) / 2.0)
    half_v = np.tan(np.deg2rad(fov_v_deg) / 2.0)
    corners_cam = np.array([
        [-half_h, -half_v, 1.0],   # "upper" (y-down -> negative y is up)
        [half_h, -half_v, 1.0],
        [half_h, half_v, 1.0],
        [-half_h, half_v, 1.0],
    ])
    corners_cam /= np.linalg.norm(corners_cam, axis=1, keepdims=True)
    corners_world = origin + range_m * (corners_cam @ r.T)
    points = np.vstack([origin[None, :], corners_world])
    lines = np.array([
        [0, 1], [0, 2], [0, 3], [0, 4],   # 4 rays from the camera origin
        [1, 2], [2, 3], [3, 4], [4, 1],   # far rectangle
    ], dtype=np.int64)
    return points, lines


def capture_square_corners(pose, fov_h_deg: float, fov_v_deg: float,
                           depth: float = _CAPTURE_SQUARE_DEPTH_M):
    """(4,3) ndarray: the camera FoV footprint at `pose`, as a genuinely
    PLANAR rectangle at `depth` metres in front of the sensor -- what the
    sensor is capturing RIGHT NOW (owner request: "show a square indicating
    the capture area"). Corner order top-left/top-right/bottom-right/
    bottom-left (matching `_fov_frustum_lines`'s corner ordering), each:

        corner = apex + depth*forward +/- (depth*tan(fov_h/2))*right
                                       +/- (depth*tan(fov_v/2))*up

    computed directly in camera space (all 4 corners share z_cam == depth)
    and then rotated+translated by the rigid `pose` -- a rotation+translation
    of a planar set of points is still planar, so this is coplanar by
    construction. Unlike `_fov_frustum_lines` (whose far corners are
    normalized onto a sphere of radius `range_m` -- a cosmetic
    simplification that's fine for a faint hint-only indicator), this is the
    shape we actually claim is "the capture area", so it must be exact.

    `pose` is a 4x4 world<-camera matrix in the Open3D CV convention
    (x-right, y-down, z-forward -- same as `slam/frames.py`'s poses and
    `_fov_frustum_lines`). Pure -- unit-tested."""
    pose = np.asarray(pose, dtype=np.float64)
    apex = pose[:3, 3]
    r = pose[:3, :3]
    half_h = depth * np.tan(np.deg2rad(fov_h_deg) / 2.0)
    half_v = depth * np.tan(np.deg2rad(fov_v_deg) / 2.0)
    corners_cam = np.array([
        [-half_h, -half_v, depth],   # top-left (y-down -> negative y is up)
        [half_h, -half_v, depth],    # top-right
        [half_h, half_v, depth],     # bottom-right
        [-half_h, half_v, depth],    # bottom-left
    ])
    return apex + corners_cam @ r.T


def _follow_alpha(motion_m: float) -> float:
    """Velocity-adaptive EMA weight for the follow camera (`_apply_follow_camera`).
    Per-frame eye motion below `_FOLLOW_SNAP_M` (ICP translation noise while the
    sensor is ~stationary) smooths at `_FOLLOW_SMOOTH` to stay steady; genuine
    motion ramps the weight linearly to 1.0 so the view tracks the sensor 1:1
    with no perceived lag (owner: "camera position should never be decimated").
    Pure -- unit-tested."""
    return float(np.clip(motion_m / _FOLLOW_SNAP_M, _FOLLOW_SMOOTH, 1.0))


def _eta_seconds(elapsed_s: float, fraction: float) -> float | None:
    """Estimated remaining seconds from elapsed wall time and completion
    `fraction` in [0, 1]: eta = elapsed * (1 - frac) / frac. None when
    `fraction` is too small to safely extrapolate from (would blow up) or
    already done -- callers should show no ETA in that case. Pure --
    unit-tested."""
    if fraction is None or fraction <= 1e-3 or fraction >= 1.0:
        return None
    return elapsed_s * (1.0 - fraction) / fraction


def _format_eta(seconds: float | None) -> str:
    """'~M:SS left' from a remaining-seconds estimate, or '' when `seconds`
    is None (too early to estimate) or negative. Pure -- unit-tested; ASCII
    only (no unicode tilde/ellipsis substitutes -- see Issue #4)."""
    if seconds is None or seconds < 0:
        return ""
    total = int(round(seconds))
    m, s = divmod(total, 60)
    return f"~{m}:{s:02d} left"


def _showcase_result_paths(ts: str, results_dir: str = _RESULTS_DIR) -> tuple[str, str]:
    """(mesh_path, trajectory_path) for a Showcase FINAL save at timestamp
    `ts` (e.g. ``time.strftime("%Y%m%d_%H%M%S")``) -- pure, unit-tested.
    Mirrors `_on_record`'s ``captures/panel_<ts>.bin`` naming, but in a
    separate ``results/`` dir since these are processed OUTPUTS, not raw
    device captures."""
    base = f"{results_dir}/showcase_{ts}"
    return f"{base}.ply", f"{base}.tum"
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

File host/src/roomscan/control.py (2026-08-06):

"""Host->device command channel: CommandClient + the roomscan-ctl CLI.

CommandClient does NOT own a serial port or a read loop. It is fed decoded
frames by whatever loop already owns the StreamDecoder (call `offer()` from
that loop) and it writes command frames through a caller-supplied callable
(call `send()` from any OTHER thread). This split is deliberate: Phase 3
Task 2 proved on hardware that a blocking write of any size, issued from the
thread draining reads, starves that read loop and causes the device to abort
an in-flight send (>100 ms of read starvation trips its bounded best-effort
policy). Keeping "write" and "observe decoded frames" as separate entry
points makes that bug structurally impossible to reintroduce, whether
CommandClient is driven by the roomscan-ctl CLI (own throwaway reader thread)
or later wired into the viewer's existing reader thread (Task 7).
"""
from __future__ import annotations

import argparse
import itertools
import random
import sys
import threading
from typing import Callable

from . import profiles
from . import protocol
from .protocol import (
    CommandCode,
    Frame,
    FrameType,
    LegacyAck,
    ProtocolError,
    RangingConfigAck,
    ResultCode,
    describe_event,
    pack_command,
    pack_manual_command,
    parse_typed_ack,
)


class CommandClient:
    """Send COMMAND frames and await their ACK.

    Thread-contract: `offer()` is called by the single loop that owns the
    decoder (matches decoded frames against pending sends); `send()` may be
    called concurrently from any other thread(s) and blocks until its ACK
    arrives or `timeout` elapses.
    """

    def __init__(self, write: Callable[[bytes], None]):
        self._write = write
        self._tokens = itertools.count(random.getrandbits(32))
        self._lock = threading.Lock()
        # token -> (event, slot, cmd). `cmd` is what makes offer() able to pick
        # the right ACK shape (parse_typed_ack dispatches on it) -- v2 has two
        # incompatible ACK payload lengths (12-byte legacy vs 16-byte ranging-
        # config) selected by which command they answer, not by their own length.
        self._pending: dict[int, tuple[threading.Event, list, int]] = {}

    def offer(self, frame: Frame) -> bool:
        """Feed one decoded frame in. Returns True iff it was consumed as the
        awaited ACK for a pending send (matched by token == header.seq).
        Everything else — DATA, EVENT, an ACK with no matching pending token,
        or an ACK whose payload fails to parse — returns False untouched so
        the caller's own DATA/EVENT handling keeps working undisturbed.
        """
        if frame.header.frame_type != FrameType.ACK:
            return False
        token = frame.header.seq
        with self._lock:
            entry = self._pending.pop(token, None)
        if entry is None:
            return False
        event, slot, cmd = entry
        try:
            slot.append(parse_typed_ack(cmd, frame.payload))
        except ProtocolError:
            slot.append(None)
        event.set()
        return True

    def _next_token(self) -> int:
        return next(self._tokens) & 0xFFFFFFFF

    def _send_and_await(self, cmd: int, frame_bytes: bytes, token: int,
                        timeout: float) -> "LegacyAck | RangingConfigAck":
        """Register `token` as pending for `cmd`'s ACK shape, write the already-
        packed `frame_bytes` (which must encode `token` as its header seq), and
        block for the matching typed ACK. This is the one thread-contract
        chokepoint every public send*/get* method funnels through: `_pending`
        is populated BEFORE the write so an ACK racing in on the reader thread
        can never arrive before anyone is waiting for it, and the write itself
        happens on the CALLER's thread, never the reader thread that drives
        `offer()` (see module docstring)."""
        event = threading.Event()
        slot: list = []
        with self._lock:
            self._pending[token] = (event, slot, cmd)
        try:
            self._write(frame_bytes)
            if not event.wait(timeout):
                raise TimeoutError(
                    f"no ACK for cmd={cmd} token={token} within {timeout}s "
                    f"({len(self._pending)} command(s) still pending)"
                )
        finally:
            with self._lock:
                self._pending.pop(token, None)
        result = slot[0] if slot else None
        if result is None:
            raise TimeoutError(f"ACK for cmd={cmd} token={token} arrived but its payload was unparsable")
        return result

    def send(self, cmd: int, param: int = 0, timeout: float = 2.0) -> tuple[ResultCode, int]:
        """Write a legacy 8-byte cmd+param COMMAND frame and block for its
        12-byte ACK. Covers commands 1-8, 11, 12 (every command that keeps the
        v1 payload shape -- see docs/protocol.md). Raises TimeoutError on
        silence within `timeout` seconds, or ProtocolError if `cmd` turns out
        to use the extended ranging-config ACK shape (9/10 -- use
        `send_manual_params`/`get_ranging_config` for those)."""
        token = self._next_token()
        ack = self._send_and_await(cmd, pack_command(cmd, param, token), token, timeout)
        if not isinstance(ack, LegacyAck):
            raise ProtocolError(
                f"cmd={cmd} returned a {type(ack).__name__} ACK; send() only handles the "
                "legacy shape -- use send_manual_params()/get_ranging_config() for cmd 9/10")
        return ResultCode(ack.result), ack.applied

    def send_profile(self, profile_id: int, timeout: float = 2.0) -> tuple[ResultCode, int]:
        """SET_RANGING_PROFILE (cmd 8): legacy shape, param/applied = the
        `ProfileId` enum value. Presets 0-2 apply immediately; MANUAL (3)
        reapplies the last accepted `send_manual_params()` candidate and is
        rejected (BAD_PARAM) until one exists."""
        return self.send(CommandCode.SET_RANGING_PROFILE, int(profile_id), timeout=timeout)
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

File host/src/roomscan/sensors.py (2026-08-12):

"""LSM6DSV16X sensor state + orientation/heading math (streams 9/10). Thread-safe:
the reader thread calls feed(); the UI thread reads latest_*/history()."""
from __future__ import annotations

import math
import threading
from collections import deque
from dataclasses import dataclass
from typing import TYPE_CHECKING

import numpy as np

if TYPE_CHECKING:   # import-only: imufusion imports the quaternion helpers from here
    from .imufusion import ImuFusion

from .magcal import MagCalibration
from .protocol import (
    IMU_RAW_TICK_US,
    Frame,
    FrameType,
    ImuRawBatch,
    StreamId,
    decode_env,
    decode_imu_cal,
    decode_imu_quat,
    decode_imu_raw,
    is_valid_env,
    is_valid_mag,
)


@dataclass(frozen=True)
class EnvSample:
    pressure_pa: float
    mag_ut: tuple[float, float, float]
    temp_c: float
    t_us: int


class SensorState:
    def __init__(self, history: int = 256, fusion: "YawFusion | None" = None,
                 env_spark_interval_s: float = 2.0, env_spark_depth: int = 300,
                 imu_raw_history: int = 64, imu_fusion: "ImuFusion | None" = None):
        self._lock = threading.Lock()
        # stream 11: latest raw-FIFO batch + a short rolling window of them. Consumed by
        # the optional `imu_fusion` stage (roomscan.imufusion) — which is OFF unless a
        # filter is passed in, so the default fused_quat() path is byte-for-byte the
        # stream-9/YawFusion behaviour SLAM already depends on.
        self._imu_raw: ImuRawBatch | None = None
        self._imu_raw_hist: deque[tuple[int, ImuRawBatch]] = deque(maxlen=imu_raw_history)
        self._imu_fusion = imu_fusion
        # stream 12: the LSM's own oscillator trim, which sets what a stream-11 timestamp
        # tick is actually worth. Starts nominal — recordings made before stream 12 existed
        # never carry one, and nominal is exactly the behaviour they were decoded with.
        self._imu_tick_us: float = IMU_RAW_TICK_US
        self._quat: tuple[float, float, float, float] | None = None
        self._env: EnvSample | None = None
        self._pressure = deque(maxlen=history)
        self._temp = deque(maxlen=history)
        self._fusion = fusion
        self._raw_mag: tuple[float, float, float] | None = None
        self._spark_interval_us = int(env_spark_interval_s * 1e6)
        self._pressure_spark = deque(maxlen=env_spark_depth)
        self._temp_spark = deque(maxlen=env_spark_depth)
        self._last_spark_t: int | None = None

    def feed(self, frame: Frame) -> None:
        if frame.header.frame_type != FrameType.DATA:
            return
        sid = frame.header.stream_id
        if sid == StreamId.IMU_QUAT:
            q = decode_imu_quat(frame.payload)
            with self._lock:
                self._quat = q
                if self._fusion is not None and self._raw_mag is not None:
                    self._fusion.update(q, self._raw_mag, frame.header.t_us)
        elif sid == StreamId.ENV:
            pressure, mag, temp = decode_env(frame.payload)
            if is_valid_env(pressure, mag, temp):
                sample = EnvSample(pressure, mag, temp, frame.header.t_us)
                with self._lock:
                    self._env = sample
                    self._raw_mag = mag
                    self._pressure.append(pressure)
                    self._temp.append(temp)
                    if (self._last_spark_t is None
                            or (frame.header.t_us - self._last_spark_t) >= self._spark_interval_us):
                        self._pressure_spark.append(pressure)
                        self._temp_spark.append(temp)
                        self._last_spark_t = frame.header.t_us
        elif sid == StreamId.IMU_RAW:
            with self._lock:
                tick_us = self._imu_tick_us
            batch = decode_imu_raw(frame.payload, tick_us)
            with self._lock:
                self._imu_raw = batch
                self._imu_raw_hist.append((frame.header.t_us, batch))
                if self._imu_fusion is not None:
                    # yaw anchor = whatever the pre-existing path would have returned
                    # (YawFusion output if attached and settled, else the SFLP quat).
                    self._imu_fusion.update(batch, yaw_ref=self._legacy_quat_locked())
        elif sid == StreamId.IMU_CAL:
            cal = decode_imu_cal(frame.payload)
            with self._lock:
                self._imu_tick_us = cal.tick_us

    @property
    def imu_tick_us(self) -> float:
        """LSM timestamp-counter LSB in µs — the trimmed value once a stream-12 frame has
        arrived, the nominal 21.7 µs before that (and forever, on an older recording)."""
        with self._lock:
            return self._imu_tick_us
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

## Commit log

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2026-07-08 fix(host): open recording inside pump try-block; pin early-close flush behavior
    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
    [sources.py]
2026-07-08 fix(host): print viewer stats heartbeat even when no frames arrive
    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
    [viewer.py]
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2026-07-08 feat(protocol): stream registry, EVENT payload, semantics clarifications (v1 additive)
    Additive refinement informed by hardware findings (docs/transform-streams.md,
    Task 8 boot-capture): documents the full stream_id registry (1-6 reserved for
    Phase 2 streams), defines the EVENT frame payload and event-code registry,
    tightens DROPPED/oversize-payload decoder semantics, and records the ZF32
    no-return sentinel (12000.0 mm). No header layout change, no version bump.
    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
    [protocol.py]
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2026-07-08 chore: final-review cleanups — dead UART sender, stale comments, EVENT surfacing in viewer
    Pre-merge fixes from the phase1-visualizer whole-branch review: drop the
    dead rs_send_depth_uart (superseded by CDC, preserved in history at
    778ce2f), correct a stale COM1-UART doc comment, dedupe a forward
    declaration, silence the now-unreachable MX_USB_PCD_Init unused-function
    warning without deleting the generated init, and make the host viewer
    surface EVENT frames (the firmware's planned error-reporting channel)
    instead of silently dropping them.
    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
    [viewer.py]
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2026-07-08 feat(host): live PC-transform pipeline stage; viewer handles RAW/CALIB streams
    Add TransformStage: feeds decoded Frames, builds/replaces a native Transform
    from CALIB frames, converts RAW_3DMD frames to depth via the PC transform, and
    passes DEPTH_ZF32 frames through unchanged (Phase 1 firmware stays supported).
    Wire it into the viewer's _reader/main loop so roomscan-view works against
    either raw-only or dual-stream firmware, with a `raw N` HUD counter.
    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
    [pipeline.py, viewer.py]
2026-07-08 fix(host): pace replay per sensor frame, not per pipeline result
    Dual-stream recordings yield two stage results per sensor frame (RAW-transformed
    + DEPTH-passthrough, same seq); pacing each result halved the effective replay
    rate (11 fps -> ~5.5 sensor fps). Pace only on seq change. Also ungate the
    raw-before-calib test (its path never touches the DLL) and mark the unused
    header unpack in the render loop.
    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
    [viewer.py]
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2026-07-08 chore: final-review cleanups — replay-identity caveat, CALIB_SIZE import, registry comment
    - ROADMAP.md: append replay-identity caveat for mid-session recordings with TNR transient
    - native.py: replace hardcoded 2332 with CALIB_SIZE import; note binning-2 assumption
    - rs_protocol.h: update stream-registry comment to reflect 1-6 reserved, 7-8 live
    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
    [native.py]
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2026-07-08 docs+feat(host): datasheet-derived FoV for Deprojector (was placeholder)
    VL53L9CX DS14879 rev 6 Table 3 (p.5) + Figure 26 (p.38) give 55 deg
    horizontal x 42 deg vertical FoV at full 54x42 resolution, confirmed by
    two independent citations plus the datasheet's own feature-page bullet.
    Replace the 60.0/45.0 placeholder defaults in Deprojector and the
    viewer --fov-h/--fov-v args; full derivation, per-zone pitch, distortion
    model caveats, and thermal-accuracy findings are in
    docs/vl53l9cx-fov-notes.md. Marked datasheet-derived pending Task 3's
    ZAPC validation since the datasheet doesn't state edge-vs-zone-center
    convention explicitly.
    Claud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
    [deproject.py, viewer.py]
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2026-07-08 fix(host): warn once when --color falls back to depth (aux plane absent)
    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
    [viewer.py]
2026-07-08 feat(host): ZAPC-validated deprojection model
    Validate the Deprojector's linear-FoV model against ZAPC (factory-calibrated
    on-device point cloud, ground truth) using the golden fixture plus the full
    731-frame capture for confidence. Findings: ZAPC's x/column, y/row, z is
    perpendicular (bit-identical to ZF32 depth) in mm; the edge-vs-zone-center
    FoV convention question collapses to a scalar rescaling with identical fit
    residuals, so it isn't a separate hypothesis. Best-fit FoV (54.66x42.50 deg)
    agrees with the datasheet's 55x42 within ~0.5 deg -- confirms the existing
    defaults, so they're unchanged. But worst-case displacement (127mm/6.36% of
    z at 2m, always at the extreme corners) doesn't bu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
    [deproject.py]
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2026-07-08 fix(protocol): strict 12-byte ACK, payload roundtrip assertions, SEND_CALIB rationale
    Review fixes for Phase 3 Task 1:
    - parse_ack now requires exactly 12 bytes (trailing bytes are a wire-format
    violation, unlike EVENT's variable message tail); docs state the rule;
    new test rejects a 13-byte payload.
    - decoder passthrough test asserts payload contents survive decode
    (unpack COMMAND cmd/param; parse_ack on the ACK payload).
    - golden test asserts width/height zero at the wire level (bytes 20:24).
    - SEND_CALIB registry row documents the late-attach rationale
    (closes ROADMAP's CALIB-on-DTR-connect item when wired in firmware).
    Full suite: 56 passed.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
    [protocol.py]
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2026-07-08 fix(host): measure_scene reuses Deprojector; CLI port-error handling; test-count corrections
    - measure_scene.py takes its zone-angle tables from the real Deprojector
    (uniform 1000 mm probe -> points == tan tables) instead of hand-rolling
    the zone-center FoV math; rerun on the crow-scene capture is numerically
    identical (270.6/204.0 and 218.2/187.5 mm clusters unchanged).
    - roomscan-ctl catches SerialSource construction failures: prints error to
    stderr + exit 1, consistent with the ACK-timeout path.
    - New tests: FileSource.write raises NotImplementedError; a duplicate ACK
    for an already-completed token is not consumed and does not crash.
    Suite 73 (corrected baseline accounting: 56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
    [control.py]
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2026-07-09 fix(host): panel review fixes — IR freeze engages from config; robustness
    Final whole-branch review findings:
    - Important: IR 'freeze range' never engaged when set from config or toggled
    before the first frame (checkbox .checked=True doesn't fire the handler;
    pre-frame toggle captured a None range). Extracted _ir_freeze_range() (pure,
    4 new tests) that lazily captures the auto-range on the first frame after
    freeze is requested. Verified live: config-set freeze now holds 19.3-88.9
    while auto keeps drifting.
    - Minor: normalize an out-of-set ir_colormap at construction so a hand-edited
    config can't feed an unknown colormap into reflectance_to_rgb every tick.
    - Minor: honor --save-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
    [panel.py]
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2026-07-09 feat(host): near-target color contrast, point size, help modal (panel)
    Requested for the person-in-front-of-wall test setup: facial relief washed
    out because color normalized across the whole depth range (person + wall).
    - roomscan/shading.py: cloud_colors() with a 'Near contrast' mode (8 tests):
    window (default) colors only points within a cutoff distance and greys the
    wall so the subject pops; emphasis (gamma) expands near depths; equalize
    (histogram/CDF) auto-stretches dense surfaces; off = linear. Panel View group
    gets a mode combobox + adaptive slider (cutoff m / strength). Used by
    _render_frame (replaces inline coloring) and the snapshotter.
    - Point size: slider range 1->20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
    [config.py, panel.py, shading.py]
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2026-07-09 fix(host): panel reports a busy/missing scanner port cleanly
    Opening the panel while a classic viewer (or another panel) holds the CDC
    port raised an uncaught SerialException traceback. Wrap source construction
    in run(): print 'error: could not open the scanner: ...' (+ a 'close the other
    viewer/panel window' hint on Access-is-denied) and return 1 so view-panel.bat's
    hint block shows without the stack dump. Regression test with a stubbed
    busy-port SerialSource.
    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
    [panel.py]
2026-07-09 feat(host): panel distinguishes busy vs missing port, offers to close holders
    roomscan/portguard.py:
    - classify_open_error(): 'busy' (Access denied / winerror 5) vs 'missing'
    (no such port / no scanner / winerror 2) vs 'unknown'.
    - roomscan_processes(): Windows, lists python processes running a roomscan
    viewer/panel (the likely port holders) via CIM; empty elsewhere.
    - offer_to_close_holders(): lists them and, on an interactive 'y', taskkills
    them so the caller can retry (injectable list/kill/input for tests).
    panel _open_source(): missing -> 'scanner not found, check cable/RESET';
    busy -> print the holders and, when stdin is a TTY, offer to close+retry once
    (non-interactive falls bac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
    [panel.py, portguard.py]
2026-07-09 feat(host): sidebar cleanup, Rotate 90 button, roll-locked camera
    Panel UX pass from live feedback:
    - Sidebar: rebuilt _build_panel on a 2-column VGrid (label|control) so text no
    longer overlaps its widget (the reported crowding); dropped redundant labels
    (Device usecase/exposure echoes, Status usecase|color, per-slider value labels
    — sliders show their own value); reordered View + IR Monitor above Device;
    Events collapsed by default; tighter margins/spacing.
    - Rotate 90 button (View): rolls the point cloud (_rot_xy, z/depth untouched so
    coloring + near-contrast are unaffected) AND the IR pane (np.rot90) together,
    for a sideways-mounted sensor. Re-applies immediately (covers pa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
    [panel.py]
2026-07-09 fix(host): actually lock camera roll via per-tick auto-level
    The previous custom set_on_mouse controller didn't take effect — Open3D's
    SceneWidget runs its built-in arcball regardless of the callback return, so
    both ran and the view still twisted ('pivots'). Replaced it: let the native
    arcball drive orbit/pan/zoom, and remove roll every tick by reading the camera
    model matrix and re-issuing look_at with an up-vector re-leveled to world-up
    (_level_up, pure + unit-tested; idempotent, skips at the poles). Verified
    against the real camera: a forced 45-deg roll snaps back to world-up in one
    call. Removed the dead custom-controller code (_orbit_eye, _on_mouse, _pan,
    _apply_camera, cam state, sen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
    [panel.py]
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2026-07-09 feat(host): sidebar cleanup, Rotate 90 button, roll-locked camera
    Replace the built-in arcball with a hand-owned turntable orbit (azimuth-only,
    fixed world-up in look_at) so the camera can never tilt or roll, matching the
    sensor's own flat-monitor viewing convention.
    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
    [panel.py]
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2026-07-09 fix(host): Deprojector.grid() sanitizes NaN/Inf depth before the boresight multiply
    At invalid cells (NaN/Inf or out-of-range depth), grid() now replaces depth with 0.0
    before computing x/y coordinates and before returning the z-channel. This prevents
    NaN from leaking into the output at zero-tan cells (the sensor boresight, e.g.
    center row/col of a symmetric FOV), which would violate the method's docstring
    promise of finite garbage values.
    The IEEE-754 rule NaN * 0.0 == NaN would otherwise cause the invalid value to
    propagate through the degenerate multiply at the boresight, poisoning Open3D's
    mesh operations that consume the full vertex buffer including invalid cells.
    Verified: __call__'s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
    [deproject.py]
2026-07-10 feat(host): persist surface-interpolation settings in roomscan.toml
    Add three new dataclass fields to ViewerConfig:
    - surface_enabled: bool = False
    - surface_mode: str = "grid" ("grid" | "spatial")
    - surface_threshold_pct: float = 4.0
    Wire these fields into _PANEL_FIELDS so they are automatically loaded/saved
    from roomscan.toml via the existing config machinery, following the exact
    pattern of point_size, ir_colormap, near_mode, etc.
    Extend test_config.py and test_panel.py to verify the new fields round-trip
    through save/load and fill from defaults when missing.
    Claude-Session: https://claude.ai/code/session_014zyQs45rsEL9CrMWpy3VmJ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
    [config.py, panel.py]
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2026-07-10 fix: guard host state.feed + refresh stream-registry banner (final-review Minors)
    - panel.py: wrap SensorState.feed in try/except so a malformed IMU/ENV payload
    can never kill the reader thread -- upholds the "IMU never blocks ToF" invariant
    on the host side too.
    - rs_protocol.h: stream-registry banner now notes 9-10 live.
    [panel.py]
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2026-07-10 fix(host): percentile-clip normalization for IR + point-cloud coloring
    Raw min/max auto-ranging let specular reflectance returns / stray far points
    crush mid-range contrast (faces, picture frames washed out). Add
    colors.percentile_range()/normalize() (2/98 pct, outlier-robust, zero-div safe)
    as the single source of truth, and use it in ir_image and shading. +tests.
    [colors.py, ir_image.py, shading.py]
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2026-07-10 feat(host): MagCalibration model + JSON persistence
    Task 1 of the mag yaw-drift correction plan. Hard/soft-iron calibration
    data model (offset + 3x3 matrix + field_ut), apply(), and tolerant JSON
    load/save. 4/4 tests.
    [magcal.py]
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2026-07-10 fix(host): reliably reject rank-deficient mag calibration clouds
    Task 2 review follow-up: the downstream Q/d/eigval guards missed planar
    (rank-deficient) input because lstsq leaves Q only near-singular. Detect
    rank<9 in the design matrix directly and raise ValueError. Adds a planar
    degenerate-fit test. 7/7 magcal tests.
    [magcal.py]
2026-07-10 feat(host): YawFusion complementary filter with anomaly/motion/gimbal gates
    Task 4. Yaw-only complementary filter: snaps to mag heading on first valid
    sample, then low-passes (gain=dt/(tau+dt)); holds delta when gated by
    magnetic anomaly, high quat angular-rate (accel-free motion proxy), or
    gimbal-lock pitch. AXIS_CONVENTION constant (default identity) for on-target
    mag-mounting resolution. 7/7 tests.
    [sensors.py]
2026-07-10 feat(host): wire YawFusion into SensorState (fused_quat/fusion_status)
    Task 5. SensorState takes an optional YawFusion; caches the latest raw mag
    from ENV and calls fusion.update() per IMU_QUAT frame under the lock.
    fused_quat() returns the corrected quat (or raw fallback); fusion_status()
    exposes the gate state. 21/21 sensors+yaw tests.
    [sensors.py]
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2026-07-10 feat(host): panel gizmo + compass consume fused (yaw-corrected) orientation
    Task 7. Panel builds a YawFusion from config (loads mag_cal.json), passes it
    to SensorState; gizmo + compass now use fused_quat() and calibrated mag;
    publishes yaw-fusion status transitions to the log. Yaw-fusion config fields
    threaded through _PANEL_FIELDS. Seam test asserts the corrected orientation.
    [panel.py]
2026-07-10 test(host): close YawFusion review gaps (low-pass gain + gate-hold coverage)
    Task 4 review follow-up:
    - add test_lowpass_tracks_moving_target: steps the target heading so the
    low-pass increment (gain=dt/(tau+dt)) is exercised with a nonzero residual
    (~1/e after one tau) — catches gain sign/formula bugs the static test missed.
    - motion/gimbal gate tests now establish a delta then assert it is HELD, not
    just that status flips.
    - add combined pitch+roll tilt-preservation test.
    - harden: re-wrap accumulated delta to [-180,180); make AXIS_CONVENTION
    read-only. 23/23 yaw+sensors tests.
    [sensors.py]
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2026-07-10 fix(host): de-tilt mag with yaw-stripped quat so fusion is actually drift-free
    Final-review Critical: YawFusion (and the panel compass) de-tilted the mag with
    the FULL SFLP quaternion, re-injecting its drifting yaw -> fused_yaw collapsed to
    alpha + (Y_sflp - Y_true), so a static device with a drifting SFLP yaw dragged
    the "corrected" gizmo the full drift. Add absolute_heading() (de-tilt with yaw
    stripped -> drift-free reference); use it in YawFusion and the compass.
    Regression tests that pin the property: test_rejects_sflp_yaw_drift (static
    device, ramped SFLP yaw -> fused yaw stays put) and
    test_absolute_heading_independent_of_yaw. Also seed panel _last_fusion_status
    to "off" so the disabl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
    [panel.py, sensors.py]
2026-07-10 feat(host): metrics HUD as capacity bars, per-process only
    Owner feedback on the first cut: raw numbers were hard to read, the readout
    should reflect OUR app's utilization (not the whole system), and the sensor
    rows showed "?" glyphs.
    - Bars instead of numbers. The overlay is now a rendered image
    (metrics_hud.render_hud, Pillow) in one ImageWidget, not gui.Labels. This
    fixes the "?" — Open3D's gui font renders arrows/block glyphs as "?" — and
    gives real color-coded capacity bars. Sensor rows are host/hub with the bar =
    host_hz/device_hz (delivery ratio; full = keeping up), so no arbitrary
    per-sensor max-rate constant.
    - Per-process, not system. ResourceSnapshot now measures TH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
    [metrics.py, metrics_hud.py, panel.py]
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2026-07-10 feat: add BUGS.md tracker; default view color to reflectance
    BUGS.md seeds the tracker with the open issues scattered across ROADMAP
    and docs (yaw-fusion bench items, connect-time CRC transient, boot-hang
    anomaly, vendor confidence plane) plus two new viewer reports: spatial
    surface mode's Open3D invalid-tetra warning spam (BUG-001) and its
    multi-core CPU pinning with an idle GPU (BUG-002, with analysis — no
    GPU alpha-shape exists in Open3D; recommended fix is a vectorized
    grid-adjacency replacement).
    BUG-003 fixed here: ViewerConfig.color default flips depth →
    reflectance; both viewers already fall back to depth with a one-time
    warning when the plane is absent.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
    [config.py, viewer.py]
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2026-07-10 fix(host): replace CPU-heavy alpha shape mesh reconstruction with O(N) vectorized grid-adjacency 3D Euclidean distance triangulation
    [panel.py, surface.py]
2026-07-10 fix: update documentation and improve handling of sensor calibration and visualization
    - Added Python environment setup instructions and test execution guidelines to AGENTS.md.
    - Documented ST-Link power and clock dependencies in engineering practices.
    - Fixed math bug in fit_ellipsoid to handle large hard-iron offsets.
    - Resolved yaw fusion calibration issues and updated AXIS_CONVENTION in sensors.py.
    - Enhanced ControlPanel to prevent camera configuration when minimized.
    - Added tests for large offset handling in fit_ellipsoid and yaw mapping in gizmo_pose.
    - Introduced live status updates during magnetometer calibration in mag_calibrate.py.
    - Added new calibration data file mag_cal.json.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
    [magcal.py, panel.py, sensors.py]
2026-07-10 Replace coordinate gizmo with 3D camera model entity, render/accumulate in fixed world, and add clear scan controls
    [panel.py]
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2026-07-11 fix(slam): make Showcase/SLAM mesh visible (shaded vertex colors) + fix camera-ease, loader-race, 1-pt LineSet segfault
    Four related fixes to the Phase 6 SLAM Showcase panel:
    - #1 (user-facing blocker): the TSDF mesh's vertex colors are always
    [0,0,0] (TsdfMap.integrate() is depth-only) and the mesh material is
    defaultUnlit with no scene lighting, so the reconstructed room rendered
    solid black -- invisible against the dark background, leaving only the
    green trajectory line visible. New host/src/roomscan/slam/shading.py
    (shade_colors: a two-sided fixed-light Lambert bake) is wired into both
    mesh-upload sites (_render_slam_frame, _show_showcase_mesh).
    - #2: BUG-009 -- the classic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
    [panel.py, shading.py]
2026-07-11 feat(panel): see-through walls for the SLAM/Showcase mesh (Phase 6)
    Owner request: near vertical walls shouldn't occlude a reconstructed room's
    interior. Adds an orientation-based wall classifier and three configurable
    render modes to the SLAM/TSDF mesh upload path only.
    - slam/shading.py: wall_triangle_mask(tri_normals, up=None, thresh=0.5) --
    pure-numpy, True where a triangle's face normal is roughly perpendicular
    to world-up (a wall), False for floor/ceiling. Orientation-based (not
    camera-facing), so any near wall is see-through from any orbit angle.
    TDD: 6 new tests (RED on missing import, GREEN on implementation).
    - panel.py: both mesh-upload sites (_render_slam_frame, _show_sh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
    [panel.py, shading.py]
2026-07-11 feat(slam): reflectance mesh color + confidence-gating + weight-threshold noise reduction
    Mapper.step gains optional reflectance/confidence; TsdfMap integrates reflectance
    into the VBG color attr (float32 depth+color overload) so extract_triangle_mesh
    returns reflectance-colored vertices (verified non-black, varied). Noise knobs:
    min_confidence=20.0 gates low-confidence depth pixels, weight_threshold=3.0 drops
    rarely-seen voxels on extraction. _load_frames now yields reflectance+confidence
    for the offline/showcase path; workers forward them. Existing behavior preserved
    (new args optional). 380 tests.
    Claude-Session: https: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
    [config.py]
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2026-07-11 feat(panel): live-scan UX batch — reflectance colour, FoV arc, progress+ETA, ASCII banners, clean-enter, save-on-final
    Seven owner-reported panel fixes, all additive and gated behind SLAM-view /
    Showcase code paths so non-SLAM/non-Showcase behaviour is byte-unchanged. No
    wire-protocol change; no serial writes added off the reader/render threads.
    1. Reflectance colour in the LIVE panel. _render_slam_frame /
    _render_showcase_recording now forward the already-decoded reflectance +
    confidence planes (self._latest_outputs) to SlamWorker.submit — no extra
    transform call; .get() degrades to None for depth-only sources. New pure
    shading helpers shade_brightness() + mesh_colors_are_m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
    [panel.py, shading.py]
2026-07-11 feat(panel): camera-follow (first-person) mode + capture-area square (Phase 6)
    Owner request: SLAM/Showcase view can now ride the sensor's estimated pose
    (eye/center from the sensor forward axis, world-up fixed, light smoothing)
    instead of free-orbit, toggled by a new "Follow camera (first-person)"
    checkbox (default OFF). A bright planar quad (_CAPTURE_SQUARE_GEOM) now
    shows exactly what the sensor is capturing right now, fixing the cosmetic
    sphere-normalized-corner issue in spirit via a new, correctly-planar
    capture_square_corners helper (left _fov_frustum_lines itself untouched for
    regression safety). Toggling follow off cleanly restores free-orbit; leaving
    SLAM/Showcase force-releases it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
    [panel.py]
2026-07-11 feat(panel): first-person polish — hide gizmo+trail, stronger anti-jitter smoothing
    Owner feedback from live first-person (camera-follow) SLAM testing:
    - Hide the stray IMU gizmo ("camera icon", frozen in the scene since entering
    SLAM) and the green trajectory "trail" while follow is active — both occlude
    the first-person view. New `_hide_first_person_clutter()` removes the gizmo
    (and clears `_gizmo_added` so the classic view re-adds it on exit); the trail
    is gated off at its add sites in `_render_slam_frame`/`_render_showcase_recording`
    and reappears the next frame once follow is turned off.
    - Reduce first-person shakiness with the sensor stationary: lower `_FOLLOW_SMOOTH`
    0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
    [panel.py]
2026-07-11 feat(slam): auto-select CUDA device for the live panel when available
    The SLAM tensor pipeline was already device-parameterized (be62641) but the
    panel never passed a device, so even a CUDA Open3D build would run on CPU.
    - New `slam.config.preferred_device()`: returns "CUDA:0" when
    `o3d.core.cuda.is_available()`, else "CPU:0"; any probe failure degrades
    safely to CPU. Lazy open3d import keeps config importable without it.
    - Panel wires it into all three worker construction sites (live SLAM view,
    Showcase RECORDING preview, Showcase PROCESSING PostProcessWorker), so the
    pipeline auto-accelerates the moment a CUDA build is installed, with zero
    config change and no behavior change on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
    [config.py, panel.py]
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
